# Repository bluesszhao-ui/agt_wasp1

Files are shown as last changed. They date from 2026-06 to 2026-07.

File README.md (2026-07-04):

# wasp1

wasp1 is a minimal single-core RV32I + Zicsr SoC project.

The hardware is implemented in synthesizable SystemVerilog and follows
Rocket Chip-like high-level module boundaries while using AHB-Lite as the SoC
interconnect.

## Baseline

```text
ISA: RV32I + Zicsr
Privilege: Machine mode only
MMU/TLB/PTW: none
RTL: SystemVerilog, .sv suffix
SoC bus: AHB-Lite
Core/cache internal interface: lightweight valid/ready request-response
Core plan: simple 3-stage pipeline
I-cache: direct-mapped, 16-byte line
D-cache: direct-mapped, 16-byte line, write-through
Debug target: RISC-V External Debug Spec 0.13.x / OpenOCD / GDB
Final debug probe: FT2232H-based external hardware debugger
Program storage: executable OTP
Compiler work: LLVM-based bare-metal wasp1 toolchain and BSP
```

## Top-Level Modules

```text
common
wasp1
tile
core
frontend
icache
dcache
bus
otp
sram
dma
debug
timer
intc
wdg
uart
i2c
gpio
llvm_s1
ftdi_debugger
```

Each hardware module owns its own `rtl/`, `tb/`, `filelists/`, `docs/`,
`build/`, `logs/`, `wave/`, and `Makefile` directories.
`ftdi_debugger` is not chip RTL; it owns the external FTDI debugger hardware,
OpenOCD, and board bring-up collateral.

## Current Status

Implemented and verified:

```text
common
bus
sram
otp
timer
gpio
uart
dma
intc
core
frontend
icache
dcache
tile
debug leaf blocks
wdg
i2c
wasp1 top integration smoke
```

Current residual scope:

```text
debug integration:
  true DPC/DCSR capture, single-step, breakpoints, abstract memory access

external debugger:
  FT2232H hardware debugger schematic/PCB, OpenOCD config, FPGA/board bring-up

software/toolchain:
  llvm_s1 BSP, linker script, startup code, runtime, examples, tests

full-system validation:
  interrupt-driven firmware, longer generated-image boot/DMA/programming
  regressions
```

See [ROADMAP.md](ROADMAP.md) for the live progress list and next steps.

## Quick Commands

Run all currently wired lint targets:

```sh
make lint
```

Run all currently wired module simulations:

```sh
make sim
```

Run common lint only:

```sh
make -C common lint
```

Generated build, log, and waveform outputs are ignored by git.

## Documentation

Start here:

```text
docs/index.md
```

Important project documents:

```text
ROADMAP.md
docs/wasp1_architecture.md
docs/wasp1_module_hierarchy.md
docs/wasp1_memory_map.md
docs/wasp1_design_plan.md
docs/wasp1_verification_plan.md
docs/wasp1_debug_strategy.md
docs/wasp1_otp_boot_strategy.md
docs/wasp1_llvm_s1_plan.md
docs/wasp1_implementation_targets.md
docs/wasp1_documentation_policy.md
docs/wasp1_omnigraffle_diagram_policy.md
```

## Contributor and Agent Rules

Human contributor guidance:

```text
CONTRIBUTING.md
```

Agent workflow rules:

```text
AGENTS.md
```

## License

wasp1 is licensed under the Apache License, Version 2.0. See [LICENSE](LICENSE).

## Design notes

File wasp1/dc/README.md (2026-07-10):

# wasp1 Synthesis Collateral

## 1. Scope

This directory contains first-pass synthesis collateral for the integrated
`wasp1` top.

It is deliberately split by implementation target:

| Target | Script | Constraint file | Memory treatment |
| --- | --- | --- | --- |
| ASIC / IC | `wasp1_ic_dc.tcl` | `wasp1_ic_constraints.sdc` | SRAM/OTP blackbox stubs |
| Xilinx Virtex-7 | `wasp1_v7_vivado.tcl` | `wasp1_v7_constraints.xdc` | Behavioral macro wrappers infer FPGA RAM |

## 2. ASIC Flow

The ASIC flow reads:

```text
wasp1/filelists/wasp1_synth_ic.f
```

That filelist replaces:

```text
sram/rtl/wasp1_sram_macro.sv -> sram/dc/wasp1_sram_macro_blackbox.sv
otp/rtl/wasp1_otp_macro.sv   -> otp/dc/wasp1_otp_macro_blackbox.sv
```

Required environment before running Design Compiler:

```sh
export WASP1_TARGET_LIBRARY="/path/to/stdcell_tt.db"
export WASP1_LINK_LIBRARY="/path/to/macro_timing.db"
dc_shell -f wasp1/dc/wasp1_ic_dc.tcl
```

The first ASIC output reports are written under:

```text
wasp1/logs/dc_ic/
```

Mapped netlist/checkpoints are written under:

```text
wasp1/build/dc_ic/
```

## 3. Virtex-7 Flow

The FPGA flow reads the normal SoC filelist:

```text
wasp1/filelists/wasp1.f
```

The default part is:

```text
xc7vx485tffg1761-2
```

Override it when a concrete board is selected:

```sh
export WASP1_VIVADO_PART=xc7vx690tffg1761-2
vivado -mode batch -source wasp1/dc/wasp1_v7_vivado.tcl
```

The XDC intentionally has no pin locations yet. Add board-specific PACKAGE_PIN
and IOSTANDARD constraints before implementation/bitstream work.

## 4. Static Check

Run:

```sh
make -C wasp1 synth-collateral-check
```

This check verifies the target split, memory macro blackbox usage, and clock
constraint presence without requiring commercial EDA tools.

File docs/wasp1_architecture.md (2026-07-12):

# wasp1 Architecture

## 1. Project Goal

wasp1 is a minimal single-core RV32I SoC inspired by the Rocket Chip module
partitioning style, implemented in synthesizable SystemVerilog.

The design keeps Rocket Chip-like high-level boundaries such as tile, core,
frontend, cache, bus, debug, interrupt, and periphery, while replacing the
Rocket Chip TileLink fabric with an AHB-Lite based SoC interconnect.

## 2. Confirmed Baseline

| Item | Decision |
| --- | --- |
| ISA | RV32I + Zicsr |
| Privilege mode | Machine mode only |
| MMU/TLB/PTW | Not implemented |
| RTL language | SystemVerilog |
| RTL suffix | `.sv` |
| SoC bus | AHB-Lite |
| Internal core/cache interface | Lightweight valid/ready request-response |
| Core microarchitecture | Simple 3-stage pipeline |
| I-cache | Direct-mapped, 16-byte line |
| D-cache | Direct-mapped, 16-byte line, write-through |
| DMA coherence | No hardware cache coherence |
| Debug | RISC-V External Debug Spec 0.13.x compatible target |
| Program storage | Executable OTP |
| OTP programming | CPU-controlled through OTP registers |
| UART programming | Software protocol through boot/program code |
| OTP programming safety | OTP programming routines execute from I-SRAM |
| Implementation targets | IC and Xilinx Virtex-7 FPGA |

## 3. Top-Level Structure

```text
                         +----------------+
                         |     debug      |
                         | JTAG/DTM/DM    |
                         +--------+-------+
                                  |
                                  v
+----------------------------------------------------------------+
|                            wasp1                               |
|                                                                |
|  +--------------------+                                        |
|  |        tile        |                                        |
|  |                    |                                        |
|  | frontend -> icache |----+                                   |
|  | core LSU -> dcache |----+--> core AHB master                |
|  +--------------------+                                        |
|                                                                |
|  +--------------------+                                        |
|  |        dma         |--------> dma AHB master                |
|  +--------------------+                                        |
|                                                                |
|       core master  dma master                                  |
|            |          |                                        |
|            v          v                                        |
|       +----------------------+                                 |
|       |   bus / AHB fabric   |                                 |
|       +----------+-----------+                                 |
|                  |                                             |
|  +---------------+------------------------------------------+  |
|  | OTP I-SRAM D-SRAM DMA WDG timer intc UART I2C GPIO       |  |
|  +----------------------------------------------------------+  |
+----------------------------------------------------------------+
```

## 4. Reset and Execution Model

After reset, the core starts at `OTP_BASE`. OTP is the primary non-volatile
program storage and is executable.

The default software layout is:

| Section | Load location | Run location |
| --- | --- | --- |
| `.text` | OTP | OTP |
| `.rodata` | OTP | OTP |
| `.fasttext` | OTP | I-SRAM |
| `.data` | OTP | D-SRAM |
| `.bss` | None | D-SRAM |
| heap | None | D-SRAM |
| stack | None | D-SRAM |

Startup code may copy `.fasttext` into I-SRAM and `.data` into D-SRAM before
calling `main`.

OTP programming code must run from I-SRAM to avoid modifying the same OTP array
that is currently feeding instruction fetch.

## 5. Cache and DMA Policy

wasp1 does not implement hardware cache coherence.

The first D-cache implementation is write-through. DMA buffers should be placed
in an uncached region or explicitly managed by software. OTP and peripheral
regions are always uncached.

## 6. Debug Model

wasp1 targets OpenOCD/GDB compatibility through a RISC-V External Debug
Spec 0.13.x style debug subsystem.

The debug implementation is staged:

| Stage | Scope |
| --- | --- |
| 1 | JTAG DTM, DMI, dmcontrol, dmstatus, halt/resume, basic GPR access |
| 2 | abstract command, DPC readback, DCSR.step single-step |
| 3 | halted-core Access Memory, native GDB `stepi`, two execute-address hardware breakpoints, and load/store watchpoints |
| 4 | four-word Program Buffer, Access Register `postexec`, and halted-core instruction execution |
| 5 | FT2232H external debugger collateral and later FPGA/board bring-up; optional System Bus Access |

## 7. Design Flow

The project starts with architecture and module documentation. RTL is added
module by module only after the module list and design order are confirmed.

Recommended first implementation target:

```text
common + bus
```

The AHB-Lite fabric is a foundation for all memory-mapped blocks.

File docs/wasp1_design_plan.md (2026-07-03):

# wasp1 Design Plan

## 1. Design Method

Design proceeds one module at a time. Each module receives:

1. Design spec
2. Interface definition
3. RTL implementation
4. Testbench
5. Filelist
6. Makefile target
7. Verification case table
8. Simulation logs and waveform output

No top-level SoC RTL is created until the lower-level modules needed for
integration are implemented and verified.

## 2. Recommended Order

| Step | Module | Reason |
| ---: | --- | --- |
| 1 | common | Shared packages, interfaces, synchronizers, FIFOs |
| 2 | bus | Foundation for all memory-mapped blocks |
| 3 | sram | Provides real AHB read/write targets |
| 4 | otp | Defines reset/program storage model |
| 5 | timer | Simple register block and interrupt source |
| 6 | gpio | Simple peripheral with input/output/interrupt |
| 7 | uart | Required for software-visible bring-up and OTP programming flow |
| 8 | dma | Adds the second AHB master and arbitration pressure |
| 9 | intc | Aggregates external interrupts |
| 10 | core | Minimal RV32I + Zicsr execution path |
| 11 | frontend | PC and fetch control |
| 12 | icache | Instruction cache and refill path |
| 13 | dcache | Data cache and write-through path |
| 14 | tile | Core/frontend/cache integration |
| 15 | debug | RISC-V debug flow for OpenOCD/GDB |
| 16 | wasp1 | Full SoC integration |
| 17 | llvm_s1 | BSP, linker, startup, boot/program software |
| 18 | ftdi_debugger | External FT2232H hardware debugger for OpenOCD/GDB |
| 19 | full system | End-to-end SoC simulation and board-level bring-up |

## 3. First RTL Milestone

The first RTL milestone is:

```text
common + bus
```

This includes AHB-Lite interfaces, address decode, 2-master arbitration, slave
muxing, and default error response.

## 4. Documentation Rule

Each module gets a design spec under `module/docs/`. Block diagrams must not use
Mermaid. Preferred diagram formats are:

```text
ASCII block diagram
editable OmniGraffle .graffle source for detailed engineering figures
optional PNG/PDF preview export for Markdown viewing
```

New or substantially reworked OmniGraffle diagrams must follow
`docs/wasp1_omnigraffle_diagram_policy.md`.

Each verification plan must include a time-sequenced case table describing the
actions and expected results during each test interval.

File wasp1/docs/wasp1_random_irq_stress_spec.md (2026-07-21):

# wasp1 Deterministic-Random IRQ Stress Specification

## 1. Purpose

This regression stresses interrupt entry/return and concurrent SoC activity
with a repeatable pseudo-random schedule. It complements the directed timer,
DMA, GPIO, UART, and mixed-interrupt firmware tests; it does not replace them.

## 2. Stimulus Contract

The testbench shall hold a nonzero 32-bit seed on GPIO while reset is active.
The OTP firmware shall sample the synchronized GPIO value, publish a seed
capture mailbox, start xorshift32 with that value, and execute 12 rounds. GPIO
shall not be repurposed as interrupt stimulus until seed capture is observed.
The low two bits of each updated state select one operation:

| Selector | Operation | Expected interrupt events |
| ---: | --- | ---: |
| 0 | Arm the machine timer | 1 timer interrupt |
| 1 | Copy four D-SRAM words with DMA IRQ enabled | 1 DMA external interrupt |
| 2 | Request a testbench-driven GPIO[0] level-high pulse | 1 GPIO external interrupt |
| 3 | Arm timer and DMA together | 1 timer plus 1 DMA interrupt, in either order |

Each round shall complete before the next PRNG update. UART shall accept one
progress byte per round plus an initial marker so the run also exercises
uncached MMIO while interrupt traffic is active.

## 3. Firmware Result Contract

Firmware shall publish a D-SRAM mailbox at offset `0x3b00` containing:

```text
completion magic and done word
captured input seed
final PRNG state and packed selector trace
completed round and interrupt-event counts
timer, DMA, and GPIO interrupt counts
order-independent event checksum
DMA destination-data checksum
GPIO request and acknowledgement epochs
last mcause and last external claim ID
failure code and UART progress-byte count
```

The firmware shall stop with a nonzero failure code when an interrupt times
out, an unexpected trap/claim occurs, DMA reports an error, or copied data does
not match.

## 4. Independent Testbench Checks

The top-level testbench shall first verify the captured seed, then independently
run the same xorshift32 recurrence
to derive the final state, selector trace, source counts, total event count,
event checksum, DMA checksum, and expected number of GPIO handshakes. It shall
drive GPIO[0] high only while the request epoch exceeds the acknowledgement
epoch and shall return the pin low after acknowledgement.

The case passes only when all mailbox values match, every final interrupt line
is deasserted, DMA done/error state is clear, timer IRQ is low, GPIO pending is
clear, and the observed UART FIFO pushes cover all 13 progress bytes.

## 5. Timing and Reproducibility

The verification clock is 100 MHz with `1ns/1ps` simulation resolution. The
baseline seed is `0x1a2b3c4d`. The multi-seed campaign runs the same OTP image
with seeds `0x1a2b3c4d`, `0x12345678`, `0xdeadbeef`, and `0x0f1e2d3c`, for 48
total rounds. Seed zero is rejected because it is the xorshift32 lock state.

The nightly campaign shall derive 32 simulation seeds from generator root
`0xc001d00d`. Consecutive simulation seeds shall be separated by 13 xorshift32
states so their 12 firmware-round windows do not overlap. The campaign shall
therefore cover 384 distinct scheduled PRNG states across 32 independent SoC
reset/boot runs. It passes only when every per-seed scoreboard passes and each
of selectors 0, 1, 2, and 3 appears at least once in the aggregate schedule.
The runner shall emit deterministic JSON and Markdown summaries plus one raw
simulation log per seed.

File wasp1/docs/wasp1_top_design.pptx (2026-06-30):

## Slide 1

wasp1 / RV32I+Zicsr / AHB-Lite 2M x 10S

wasp1 SoC
Top Design PPT

单核 SoC 集成顶层：tile、cache、core AHB bridge、2-master fabric、OTP/SRAM/peripherals、IRQ pack、debug boundary 和 smoke verification。

SEQ
tile
RV32I+Zicsr
I/D cache

SEQ
AHB fabric
core + DMA masters

IF
UART/I2C/GPIO
debug/trap/reset pins

SEQ
OTP/SRAM/peripherals
10 slave windows

editable native PowerPoint shapes

1

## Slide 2

wasp1 / SoC Integration Top

顶层设计目标与边界

顶层负责结构集成和边界暴露，不重新实现子模块内部功能

- boot_pc 固定为 OTP_BASE，使 OTP 成为 reset 后可执行程序存储
- 把 tile I-cache/D-cache downstream 合并为 core-side AHB master
- 集成 DMA 第二 master 和 10 个 decoded external slave windows
- 打包 WDG/UART/I2C/GPIO/DMA 到 INTC，timer 直连 MTIP
- 临时暴露 core debug discrete ports；完整 JTAG DTM/DM 是后续集成项

SEQ
tile owns CPU/cache state

COMB
top owns wiring
IRQ pack
bridge select

SEQ
bridge owns
transaction state

IF
external pins
IO/debug/observe

2

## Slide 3

wasp1 / SoC Integration Top

2M x 10S AHB-Lite 拓扑

M0 来自 core-side bridge，M1 来自 DMA；fabric 负责仲裁、decode、mux 和 default response

IF
M0 core bridge
I/D cache traffic

SEQ
10 slave windows
OTP ISRAM DSRAM DMA
WDG TIMER INTC
UART I2C GPIO

SEQ
ahb_fabric_2m
arbiter + default
registered response

grant observation: bus_grant_idx_o

COMB
decoder/mux
slave select
response mux

SEQ
M1 DMA master
copy engine traffic

3

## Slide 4

wasp1 / SoC Integration Top

外部 slave windows

wasp1 顶层使用 common package 的 base address 和 slave index，保持全 SoC 一致

Group

Windows

Role

SEQ
boot path
boot_pc=OTP_BASE
tile fetch -> bridge
-> fabric -> OTP

Program/storage

OTP, I-SRAM, D-SRAM

boot code and scratch memories

DMA

DMA control window

software controls second AHB master

System

WDG, TIMER, INTC

reset request, MTIP, MEIP aggregation

COMB
data path
loads/stores/DMA
decode to SRAM or peripherals

Serial/IO

UART, I2C, GPIO

external communication and pins

4

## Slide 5

wasp1 / SoC Integration Top

Core I/D to AHB bridge

bridge 把 tile 的 imem_if/dmem_if 合并为一个 core-side AHB master，D-cache idle 仲裁优先

- BR_IDLE 中 dmem valid 优先于 imem valid
- BR_ADDR 驱动 AHB address phase，等待 hready
- BR_RESP 采样 hrdata/hresp，进入 response hold
- BR_RSP_HOLD 保持 cache response 直到 selected port ready
- 当前设计只允许 one outstanding single-beat transfer

BR_IDLE

BR_ADDR

BR_RSP_HOLD

BR_RESP

D-cache wins when both request

5

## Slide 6

wasp1 / SoC Integration Top

Reset 与 boot fetch flow

reset 后 tile boot PC 指向 OTP_BASE；第一条取指路径验证 SoC memory path 是否贯通

IF
hclk_i/hresetn_i
SoC reset domain

SEQ
tile/frontend
boot_pc=OTP_BASE

SEQ
core AHB bridge
imem request

SEQ
AHB fabric
M0 grant/decode

SEQ
executable OTP
AHB_SLAVE_OTP

当前顶层 smoke test 观察 core-side bridge/fabric path 是否出现 valid transfer；完整软件 boot、OTP 编程和 LLVM 输出执行仍是后续系统验证。

6

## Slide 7

wasp1 / SoC Integration Top

Interrupt integration

timer 直接作为 MTIP；外设 IRQ 通过 INTC 聚合为 MEIP，source 0 保留

INTC source

Signal

Origin

COMB
irq_src pack
{dma,gpio,i2c,uart,wdg,0}

SEQ
ahb_intc
mask/pending/claim
meip_o

1

wdg_irq

Watchdog timeout

2

uart_irq

UART RX/TX/events

3

i2c_irq

I2C transaction done

4

gpio_irq

GPIO edge/level

SEQ
timer_irq
direct MTIP

SEQ
tile/core CSR
external_irq_i
timer_irq_i

5

dma_irq

DMA done/error

7

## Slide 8

wasp1 / SoC Integration Top

IO 与 debug boundary

顶层暴露真实 IO pins，同时保留临时 discrete core debug channel 便于后续 DM/JTAG 接入

- UART RX/TX、I2C open-drain SCL/SDA value/OE、GPIO in/out/OE
- wdg_reset_req_o 暴露给后续 SoC reset tree
- trap_valid/cause 和 bus_grant_idx 用于 bring-up observation
- 内部实例化 debug_if，映射到 discrete top ports
- 完整 DMI/DTM/OpenOCD/GDB 兼容路径仍是 debug/wasp1 后续集成项

IF
external pins
UART/I2C/GPIO
WDG reset/trap/bus

IF
temporary debug ports
halt/resume/step
GPR req/rsp

SEQ
core_debug interface
inside tile/core

8

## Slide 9

wasp1 / SoC Integration Top

Target support 与模块责任边界

顶层不引入 target-specific 行为；target 宏由 child memory/wrapper/attribute 层消化

- WASP1_TARGET_SIM_GENERIC：通用仿真路径
- WASP1_TARGET_IC：IC synthesis macro path
- WASP1_TARGET_FPGA_XILINX_VIRTEX7：Xilinx Virtex-7 macro path
- 顶层保持 programmer-visible behavior、AHB、IRQ、debug boundary 一致
- memory wrappers 和目标属性由子模块负责

SIM_GENERIC lint PASS

IC lint PASS

Virtex-7 lint PASS

COMB
same software-visible
SoC contract

9

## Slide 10

wasp1 / SoC Integration Top

顶层验证方法：为什么这样测

顶层 smoke test 不重复 leaf coverage，而是证明集成 elaboration、reset 和第一条 fetch path

风险

验证方法

根本逻辑

IF
tb_wasp1
reset/observe
no firmware yet

full hierarchy integration

generic/IC/Virtex-7 lint

证明 54 integrated modules 可展开且 target 宏一致

reset IO safety

4 cycles reset + output checks

顶层 IO 不能在 reset 后产生危险驱动

first fetch path

wait core AHB valid transfer

OTP boot path 必须穿过 tile/bridge/fabric

debug status wiring

wait running or halted

debug_if discrete ports 已被驱动而非悬空

COMB
integration smoke
pass counter
status snapshot

idle peripheral stability

extra cycles check WDG/I2C benign

未编程外设不能产生 reset 或 open-drain drive

10

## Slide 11

wasp1 / SoC Integration Top

验证结果快照

当前报告是 integration smoke test；完整系统软件验证仍在后续

Check

Result

Evidence

trap_valid=0

Generic lint

PASS

make -C wasp1 lint

trap_cause=0x02

IC-target lint

PASS

make -C wasp1 lint-ic

Virtex-7 lint

PASS

make -C wasp1 lint-fpga-v7

bus_grant_idx=0

tb_wasp1 simulation

PASS

pass_count=5

WDG/I2C idle benign

Observed debug

driven

dbg_running=1 dbg_halted=0

Simulation window: reset to 276ns. The test confirms benign reset defaults, first core-side AHB activity, and driven debug status; it does not claim full boot/software coverage.

11

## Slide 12

wasp1 / SoC Integration Top

后续集成关注点

顶层结构已经可 elaboration/smoke，但完整 wasp1 产品化还需要系统软件和 debug/JTAG 闭环

SEQ
current top
structural SoC
OTP fetch smoke
IO/debug boundary

COMB
integration work
Debug Module/JTAG
OTP programming flow
DMA real memory copy

IF
system validation
OpenOCD/GDB
firmware boot
interrupt-driven tests

- 把 debug leaf/DM/JTAG DTM 接入 wasp1 顶层，实现 OpenOCD/GDB end-to-end
- 建立 OTP 用户程序装载、LLVM/BSP 输出、真实 boot regression
- 补 DMA through-memory copy、interrupt-driven firmware、timer/INTC 外设联动
- 后续增加结构 coverage、长时间 SoC random/soak 和 FPGA bring-up checklist

12

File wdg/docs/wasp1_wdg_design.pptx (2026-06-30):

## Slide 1

wasp1 / peripheral leaf / safety timer

Watchdog
Design PPT

AHB-Lite watchdog timer：timeout counter、kick key、clear priority、IRQ/reset request 输出，以及自检查验证。

IF
AHB-Lite slave
register access

SEQ
control/status
timeout/count

COMB
count+1 compare
timeout hit

IF
IRQ/reset request
SoC integration

editable native PowerPoint shapes

1

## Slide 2

wasp1 / AHB-Lite Watchdog Timer

设计目标与行为边界

软件定期写 KICK key；超时后 sticky status 驱动 IRQ 和 reset request

- AHB-Lite always-ready word register slave
- TIMEOUT=N 表示清零后 N 个 enabled ticks 到期
- TIMEOUT=0 作为 immediate expiry
- 正确 KICK 清 count/expired/reset_req；错误 key 只置 keyerr
- 模块自身不决定 SoC reset tree，只输出 wdg_reset_req_o

SEQ
CTRL regs
enable irq_en reset_en

SEQ
COUNT/TIMEOUT
up counter

SEQ
sticky status
expired reset_req keyerr

IF
wdg_irq_o
wdg_reset_req_o

2

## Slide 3

wasp1 / AHB-Lite Watchdog Timer

模块总体结构

AHB 请求锁存、寄存器状态、timeout compare 和输出 decode 明确分层

IF
AHB bus
hsel/haddr/htrans
hwrite/hsize/hwdata

COMB
address decode
range/alignment
word size

SEQ
request regs
clk=hclk_i
rst=hresetn_i

SEQ
control/status regs
timeout/count
expired/keyerr

COMB
read/status/output
HRDATA/HRESP
IRQ/reset_req

COMB
count_plus_one
timeout_hit
TIMEOUT=0

3

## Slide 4

wasp1 / AHB-Lite Watchdog Timer

软件寄存器模型

5 个 word registers 覆盖 enable、状态、timeout、count 和 feed 动作

Offset

Name

Access

Meaning

0x00

CTRL

RW

enable, irq_en, reset_en, clear

IF
software flow
program TIMEOUT
set CTRL enable
periodic KICK
poll STATUS

0x04

STATUS

RO

expired, reset_req, keyerr, running

0x08

TIMEOUT

RW

32-bit terminal count

0x0C

COUNT

RO

current watchdog count

COMB
KICK policy
correct key feeds
bad key latches keyerr

0x10

KICK

WO

write WDG_KICK_VALUE to feed

4

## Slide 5

wasp1 / AHB-Lite Watchdog Timer

更新优先级

clear/kick 必须能压过同周期 tick 或 expiry，这是 watchdog 语义最关键的地方

- reset 初始化全部寄存器和 AHB response
- 默认 watchdog tick 先计算 count_plus_one / timeout_hit
- 软件 CTRL.clear 或 valid KICK 在同一 always_ff 后部覆盖 tick
- bad KICK 不 feed，只 latch keyerr
- 未知寄存器和非法地址通过 HRESP ERROR 暴露

SEQ
reset
state init

COMB
tick/compare
count+1>=timeout

SEQ
software write
clear/kick/control

SEQ
final state
count/status/output

5

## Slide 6

wasp1 / AHB-Lite Watchdog Timer

Timeout / Kick 工作原理

count_plus_one 与 timeout_q 比较，避免 TIMEOUT=N 的 off-by-one 歧义

RUNNING
count<N

TIMEOUT_HIT

EXPIRED
sticky

KICK/CLEAR
count=0

TIMEOUT=0 直接命中；TIMEOUT=N 时从 count=0 开始，第 N 个 enabled tick 进入 expired。expired 后计数停止，直到 clear 或正确 KICK。

6

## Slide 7

wasp1 / AHB-Lite Watchdog Timer

STATUS、IRQ 与 reset request

expired 是 sticky completion；reset_req 只在 reset_en 到期时 sticky latch

Signal/bit

Definition

Why

STATUS.running

enable && !expired

软件可快速判断 watchdog 是否仍在计数

COMB
output decode
status image
IRQ/reset request

STATUS.expired

timeout hit latched

polling 和 IRQ 共享同一 completion source

STATUS.reset_req

reset_en sampled at expiry

reset 请求保持到 kick/clear

wdg_irq_o

expired && irq_en

IRQ mask 不改变 expired 状态

IF
SoC integration
interrupt input
reset controller

wdg_reset_req_o

reset_req_q

交给 SoC reset tree 处理

7

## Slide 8

wasp1 / AHB-Lite Watchdog Timer

AHB 响应与错误处理

always-ready 简化外设接入；非法访问仍在一拍后返回 HRESP ERROR

- hready_o 固定 1，不产生 wait state
- addr phase 捕获 req_valid/write/err/offset
- 只支持 aligned word access
- misaligned、non-word、out-of-range 返回 ERROR
- unknown register offset 在 data phase 返回 ERROR

IF
address phase
current bus

COMB
decode errors
range align size

SEQ
request regs
one-cycle delay

COMB
read/response
HRDATA/HRESP

8

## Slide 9

wasp1 / AHB-Lite Watchdog Timer

验证方法：为什么这样测

watchdog 的核心风险是计数边界、feed 优先级、sticky 输出和 AHB 错误契约

风险

验证方法

根本逻辑

IF
self-checking TB
AHB driver

reset/register contract

reset reads + register readback

软件只通过寄存器面配置和诊断

timeout boundary

timeout=4, reset-only, random timeout

证明 TIMEOUT=N 和 TIMEOUT=0 语义

feed priority

correct KICK before expiry

防止同周期 tick 错误抢先到期

bad key handling

wrong KICK value then STATUS read

错误 feed 不应隐藏软件 bug

COMB
scoreboard
register/status
cycle timing

AHB error path

misaligned/halfword/unknown/range

非法访问必须是总线错误而不是静默忽略

9

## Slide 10

wasp1 / AHB-Lite Watchdog Timer

验证结果快照

当前报告是 functional self-check coverage；generic/IC/Virtex-7 lint 与仿真均通过

Metric

Value

Meaning

Generic lint PASS

pass_count

50

self-check milestones

reg_count

35

register access checks

IC lint PASS

timeout_count

2

directed timeout classes

Virtex-7 lint PASS

kick_count

2

valid kick and pre-expiry feed

tb_ahb_wdg PASS

error_count

random_count

5

4

AHB / register error paths

deterministic random timeouts

Timebase: 1ns/1ps, 10ns verification clock. Cases cover reset, timeout IRQ/reset, valid/bad kick, clear behavior, IRQ masking, AHB error paths, and random timeout values.

10

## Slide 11

wasp1 / AHB-Lite Watchdog Timer

后续集成关注点

模块级 watchdog 已验证；reset request 如何进入 SoC reset tree 是顶层验证项

SEQ
current module
verified register file
timeout/kick logic
IRQ/reset outputs

COMB
integration work
reset tree policy
interrupt wiring
firmware driver

IF
system validation
end-to-end timeout
recovery behavior
boot interaction

- SoC 顶层要决定 wdg_reset_req_o 是局部复位还是全芯片复位
- 需要 firmware-driven kick/timeout 回归验证 reset/boot 交互
- 后续可补结构覆盖和长时间 soak/random timeout tests

11

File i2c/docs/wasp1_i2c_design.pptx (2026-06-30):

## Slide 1

wasp1 / peripheral leaf / AHB-Lite slave

I2C Master
Design PPT

最小 single-master I2C 控制器：AHB 寄存器、byte FSM、prescale divider、open-drain SCL/SDA drive enables，以及自检查验证。

IF
AHB-Lite slave
register access

SEQ
software regs
DATA/STATUS/CTRL

SEQ
I2C byte FSM
START/BIT/ACK/STOP

COMB
open-drain decode
SCL/SDA OE only

editable native PowerPoint shapes

1

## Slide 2

wasp1 / AHB-Lite I2C Master

设计目标与非目标

把 I2C 做成可验证、可综合、对软件清晰的最小主控外设

- single-master，一次 CMD 写启动一个 8-bit byte transaction
- AHB-Lite always-ready slave，地址相位后一拍返回 data/response
- 软件配置 START/READ/STOP/ACK_VALUE，DATA 承载 TX/RX byte
- SCL/SDA 只提供低电平 drive enable，高电平由外部 pull-up
- 不实现 multi-master arbitration、clock stretching 和 pad 签核

IF
software-visible
AHB registers

SEQ
byte FSM
one byte per CMD

COMB
open-drain policy
OE means drive low

IF
external pull-ups
board/pad domain

2

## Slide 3

wasp1 / AHB-Lite I2C Master

模块总体结构

AHB 寄存器面和 I2C bit/ACK/STOP 时序面分离，组合 open-drain decode 输出到 pad

software register plane

SEQ
software regs
enable irq prescale
tx/rx/status/cmd

IF
AHB bus
hsel/haddr/htrans
hwrite/hsize/hwdata

COMB
address decode
range/alignment
known offset

SEQ
request phase regs
clk=hclk_i
rst=hresetn_i

COMB
read/status/output
HRDATA/HRESP
IRQ
SCL/SDA OE

SEQ
I2C byte FSM
START BIT ACK STOP
divider tick

serial timing plane

3

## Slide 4

wasp1 / AHB-Lite I2C Master

软件寄存器与命令模型

寄存器面足够小：DATA/STATUS/CTRL/PRESCALE/CMD 覆盖一个 byte transaction

Offset

Name

Access

Meaning

COMB
CMD bits
START bit0
READ bit1
STOP bit2
ACK_VALUE bit3

0x00

DATA

RW/RO

write TX byte; read last RX byte

0x04

STATUS

RO

busy, done, ackerr, rx_valid, irq

0x08

CTRL

RW

enable, irq_en, write-one clear

0x0C

PRESCALE

RW

16-bit phase divider reload

IF
software flow
program DATA/PRESCALE
write CTRL enable
write CMD
poll STATUS/read DATA

0x10

CMD

WO

START, READ, STOP, ACK_VALUE

4

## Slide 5

wasp1 / AHB-Lite I2C Master

AHB-Lite 响应原理

always-ready 简化互连；地址相位 metadata 锁存到下一拍 response/data phase

- hready_o 固定为 1，模块不向 AHB 插入等待周期
- addr phase 检查 hsel、htrans[1]、range、alignment、word size
- req_valid_q/req_write_q/req_err_q/req_offset_q 保存一拍
- read_data_next 由已锁存 offset 和当前寄存器状态组合产生
- 未知 offset、非法 size、busy/disabled CMD 返回 HRESP ERROR

IF
AHB address phase
current bus pins

COMB
decode
range/align/size

SEQ
request regs
one-cycle delay

COMB
response mux
HRDATA/HRESP

5

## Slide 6

wasp1 / AHB-Lite I2C Master

I2C byte FSM

一个 CMD 只执行一个 byte；START/STOP 是否出现由 CMD 位控制

IDLE

START_A

BIT_LOW

ACK_LOW

STOP_LOW

START_B

BIT_HIGH

ACK_HIGH

STOP_HIGH

DONE

BIT_LOW/BIT_HIGH 循环 8 次，由 bit_idx_q 从 7 数到 0。TX 在 ACK_HIGH 采样 slave ACK；RX 在 BIT_HIGH 采样数据，并在 ACK_HIGH commit RX byte。

6

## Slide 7

wasp1 / AHB-Lite I2C Master

PRESCALE divider 与 tick

I2C 时序推进由 phase tick 驱动；PRESCALE=0 合法，便于快速仿真

- prescale_q 是 16-bit reload value
- FSM active 时 div_q 递减；div_q==0 产生 tick
- tick 后 div_q 重新装载 prescale_q
- FSM idle 时 div_q 跟随 prescale_q
- PRESCALE=0 表示每个 hclk_i cycle 推进一个 FSM phase

SEQ
prescale_q
software reload

SEQ
div_q counter
clk=hclk_i

COMB
tick = div_q==0
phase enable

SEQ
byte FSM
advance on tick

7

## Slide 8

wasp1 / AHB-Lite I2C Master

Open-drain SCL/SDA 策略

模块永远不驱动逻辑 1；输出值固定为 0，OE 决定是否把线拉低

- i2c_scl_o = 0，i2c_sda_o = 0
- *_oe_o = 1 表示 drive low；*_oe_o = 0 表示 release
- TX bit 为 0 时 SDA OE=1；TX bit 为 1 时 release
- RX data phase 释放 SDA，由外部 slave 驱动
- RX ACK: ACK_VALUE=0 拉低 ACK，ACK_VALUE=1 释放为 NACK

SEQ
FSM state
cmd direction
bit_idx/tx bit

COMB
line decode
SCL_OE/SDA_OE

drive low only

IF
external line
pull-up + pad
SCL/SDA observed

8

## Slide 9

wasp1 / AHB-Lite I2C Master

状态、IRQ 与错误处理

错误响应保护软件模型；done/ackerr/rx_valid 构成一次 transaction 的 completion contract

Item

Set condition

Clear condition

COMB
error detect
misaligned
non-word
unknown offset
CMD disabled/busy

done

FSM reaches DONE

CTRL.clear or new CMD

ackerr

TX ACK_HIGH samples SDA high

CTRL.clear or new CMD

rx_valid

RX ACK_HIGH commits byte

CTRL.clear or new CMD

irq

done && irq_en

done cleared or irq_en=0

IF
AHB response
HRESP ERROR
no restart/corrupt

9

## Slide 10

wasp1 / AHB-Lite I2C Master

验证方法：为什么这样测

I2C 外设的风险集中在寄存器契约、串行线行为、busy 保护和错误响应

风险

验证方法

根本逻辑

IF
self-checking TB
AHB driver
I2C slave model

register contract

reset + legal read/write sweep

软件只能通过寄存器面观察和控制 byte engine

AHB error response

misaligned/byte/unknown/out-of-range

总线错误必须在一拍响应中准确暴露

TX bit drive

0xA5, 0x3C, random TX + line checks

最终 done 不足以证明 open-drain bit-level 正确

RX sampling/ACK

feed 0x5A/0xC3; ACK and NACK cases

读方向同时验证 sample timing 和 master ACK policy

COMB
scoreboard
register image
line-level checks

busy protection

issue CMD while FSM active

第二条命令不能重启或破坏当前 transaction

10

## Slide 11

wasp1 / AHB-Lite I2C Master

验证结果快照

当前报告是 functional self-check coverage；目标宏 lint 和仿真均通过

Metric

Value

Meaning

Generic lint PASS

pass_count

reg_count

110

36

self-check milestones

register access checks

IC lint PASS

write_tx_count

6

TX byte transactions

read_rx_count

2

RX byte transactions

Virtex-7 lint PASS

error_count

5

AHB / command error cases

tb_ahb_i2c PASS

random_count

4

deterministic random TX bytes

line_check_count

Timebase: 1ns/1ps, 10ns verification clock. Directed cases cover reset, legal/illegal AHB access, TX ACK/NACK, RX ACK/NACK, busy reject, and four deterministic-random TX bytes.

50

open-drain bit-level checks

11

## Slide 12

wasp1 / AHB-Lite I2C Master

后续集成关注点

当前模块满足 wasp1 最小 I2C master contract，系统级仍要验证 pad 与外部设备时序

SEQ
current module
verified AHB slave
byte FSM
open-drain OE

COMB
integration work
pad wrapper
pull-up choice
board timing

IF
system validation
real I2C target
firmware driver
IRQ path

- multi-master arbitration 和 clock stretching 仍是明确非目标
- FPGA/IC pad open-drain 实现需要在顶层 wrapper 中确认
- 系统集成后增加 firmware-driven I2C peripheral 回归
- 后续可补结构覆盖和外设 timing margin signoff

12

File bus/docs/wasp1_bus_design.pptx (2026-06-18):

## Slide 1

wasp1 bus

模块讲解 PPT

2-master AHB-Lite fabric 与地址解码/返回 mux

core master
IF

dma master
IF

ahb_arbiter_2m
SEQ grant

ahb_decoder
COMB decode

slave ports
IF 0..N

ahb_default_slave
SEQ error

bus 把 core/dma 两个 master 接入统一的 AHB-Lite slave 空间，并提供默认错误响应。

两主：core 与 dma

地址解码覆盖 OTP/SRAM/外设/default

downstream HREADY low 时保持 grant

未映射地址进入 default error slave

ahb_slave_mux
COMB rsp mux

wasp1 / bus design explanation

01

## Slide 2

GOALS AND SCOPE

设计目标与边界：先把职责收紧，再谈扩展

SEQ clk/rst

COMB

IF

模块定位

bus 把 core/dma 两个 master 接入统一的 AHB-Lite slave 空间，并提供默认错误响应。

两主：core 与 dma

地址解码覆盖 OTP/SRAM/外设/default

downstream HREADY low 时保持 grant

外部可见契约

实现侧选择

明确 SEQ/COMB/IF 边界

接口、寄存器语义、错误响应、中断/握手行为必须稳定。
实现可替换，但软件和总线观察到的行为不应改变。

状态归属到叶子或寄存器

IC 与 Virtex-7 FPGA 行为一致

验证覆盖正常/边界/错误/停顿

wasp1 / bus design explanation

02

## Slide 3

EXTERNAL CONTRACT

接口契约：软件/总线/相邻模块能观察到什么

C1

两主：core 与 dma

C2

地址解码覆盖 OTP/SRAM/外设/default

C3

downstream HREADY low 时保持 grant

未映射地址进入 default error slave

C4

C5

master 请求进入 arbiter

C6

grant 后地址控制进入 decoder

契约优先级
spec > design spec > RTL

wasp1 / bus design explanation

03

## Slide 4

ARCHITECTURE MAP

总体架构图：SEQ、COMB、IF 明确分开

SEQ clk/rst

COMB

IF

core master
IF

dma master
IF

ahb_arbiter_2m
SEQ grant

图示原则

绿色：时序状态或寄存器/存储

橙色：组合判断、mux、编码

蓝色：模块边界或外部接口

每个 SEQ 块在设计文档中必须标明 clock/reset

ahb_decoder
COMB decode

slave ports
IF 0..N

ahb_default_slave
SEQ error

ahb_slave_mux
COMB rsp mux

wasp1 / bus design explanation

04

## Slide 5

FUNCTIONAL FLOW

功能原理：从输入事件到可观察结果

master 请求进入 arbiter

grant 后地址控制进入 decoder

slave response 通过 mux 返回获授权 master

非授权 master 根据状态返回 ready/hold

根本逻辑

master 请求进入 arbiter

grant 后地址控制进入 decoder

slave response 通过 mux 返回获授权 master

非授权 master 根据状态返回 ready/hold

wasp1 / bus design explanation

05

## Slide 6

STATE AND TIMING

状态/时序图：所有状态都必须可定位、可验证

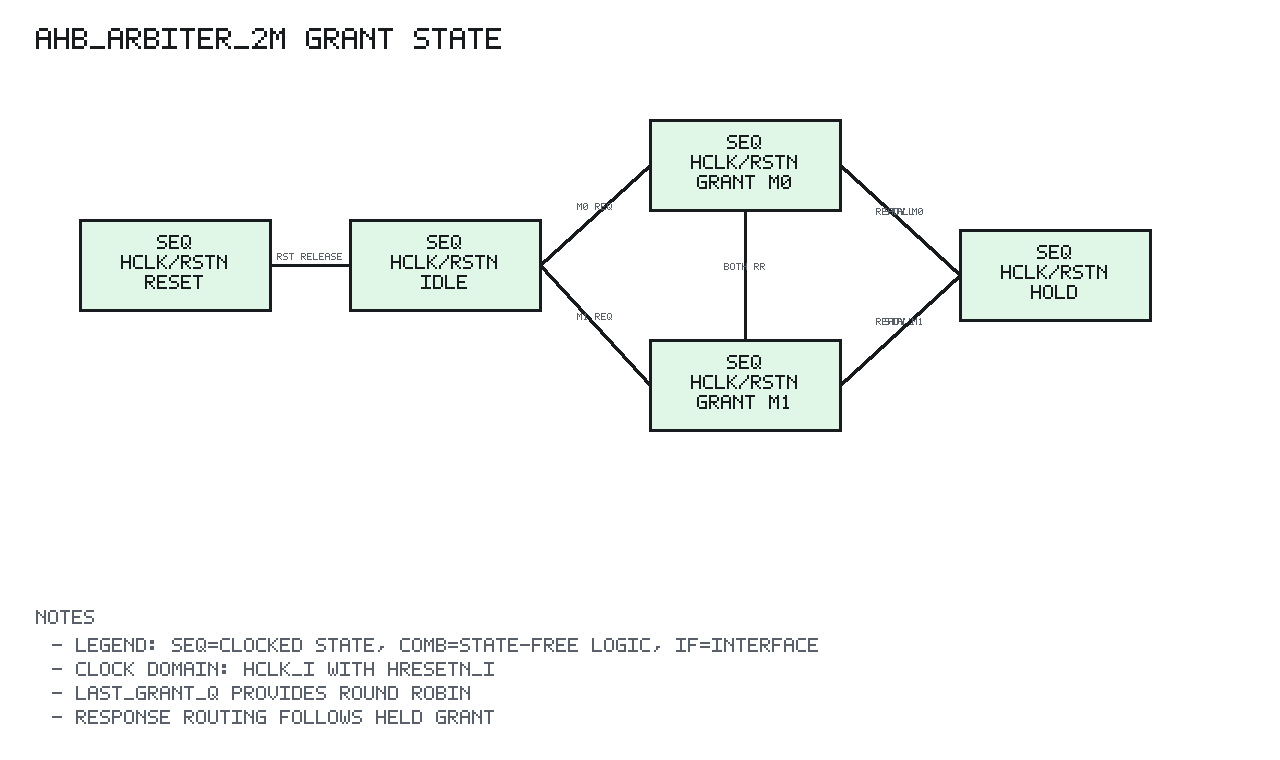
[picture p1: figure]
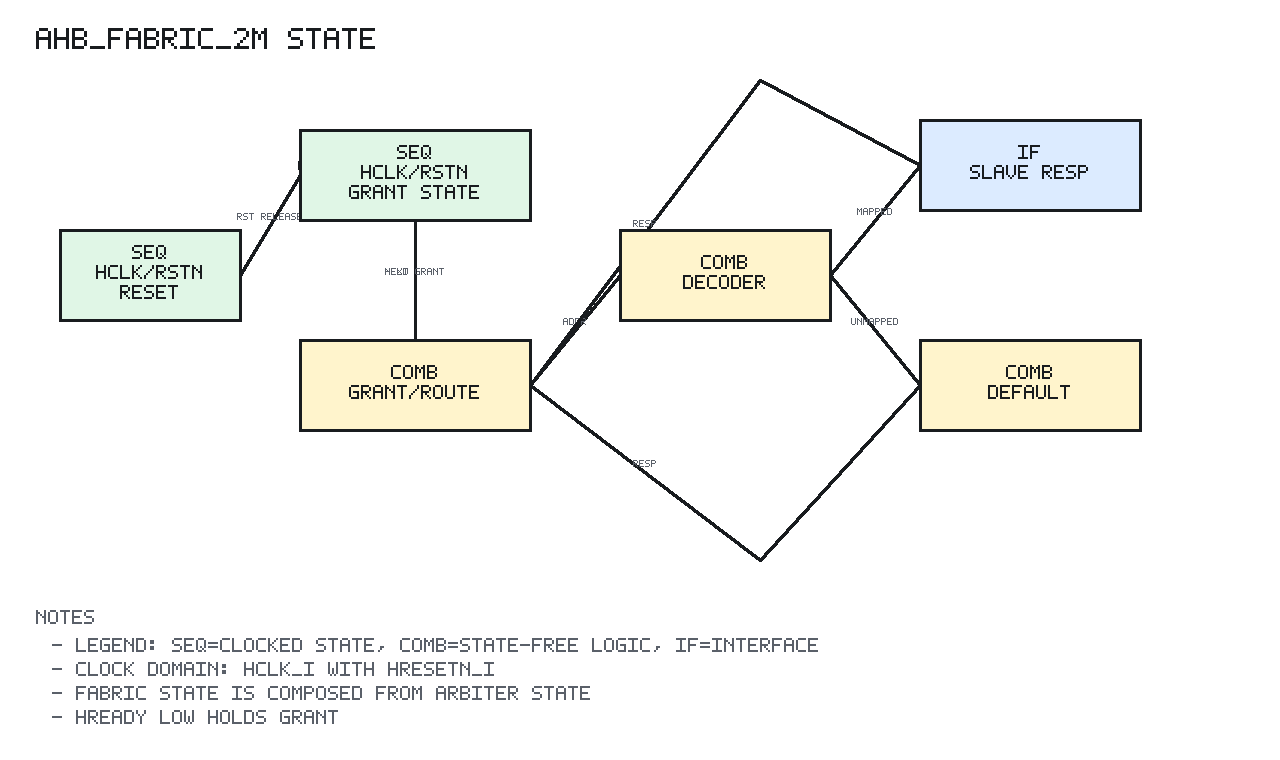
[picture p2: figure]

状态图来自模块 docs/images，并与 design spec 中状态描述对应。

复杂控制器默认按 L3：条件、动作、错误路径、优先级都要明确。

无显式 FSM 的模块用寄存器/计数器/流水线状态图表达。

wasp1 / bus design explanation

06

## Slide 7

VERIFICATION METHOD

验证方法：不是冒烟测试，而是证明交互正确

normal path

单 master 直通

boundary

双 master 同时请求轮转

error path

slave wait-state 保持

stall/idle

未映射地址 ERROR

self-checking TB + scoreboard/reference model + coverage summary

wasp1 / bus design explanation

07

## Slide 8

CASE TIMELINE

验证 case 时间表：动作、期望、观测结果必须逐段列出

时间段

0ns-20ns

动作

Apply reset

期望

Arbiter grant and decoder state reset

结果

报告未记录/待补

20ns-60ns

Decode OTP/I-SRAM/D-SRAM base/mid/end addresses

Matching memory select asserted

PASS for `ahb_decoder`

60ns-100ns

Decode peripheral base/mid/end addresses

Matching peripheral select asserted

PASS for `ahb_decoder`

100ns-140ns

DMA reads D-SRAM address

DMA receives grant and slave response

报告未记录/待补

140ns-200ns

Core and DMA request simultaneously

Round-robin alternates accepted grants

报告未记录/待补

说明：此页抽取/概括自现有 verification report。后续若 testbench 扩展，应同步更新报告和 PPT。

wasp1 / bus design explanation

08

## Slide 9

COVERAGE AND RISKS

覆盖与风险：覆盖面决定这个模块能不能被信任

单 master 直通

92%

已覆盖维度

单 master 直通

双 master 同时请求轮转

slave wait-state 保持

未映射地址 ERROR

双 master 同时请求轮转

88%

slave wait-state 保持

未映射地址 ERROR

86%

84%

两主

90%

地址解码覆盖 OTP/SRAM/外设/default

82%

风险原则：新增 RTL 行为必须先补 spec 和验证，再进集成。

wasp1 / bus design explanation

09

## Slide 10

CLOSE

结论：这个模块已经形成可讲解、可追踪、可继续扩展的设计资产

设计结论

两主：core 与 dma

地址解码覆盖 OTP/SRAM/外设/default

downstream HREADY low 时保持 grant

未映射地址进入 default error slave

验证结论

单 master 直通

双 master 同时请求轮转

slave wait-state 保持

未映射地址 ERROR

后续关注

与上层集成后的端到端 case

目标宏/FPGA 综合路径

新增功能保持 contract 稳定

文档、RTL、TB 同步更新

交付物：bus/docs/wasp1_bus_design.pptx

wasp1 / bus design explanation

10

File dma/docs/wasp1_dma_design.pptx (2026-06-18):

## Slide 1

wasp1 dma

模块讲解 PPT

AHB DMA register block 与 memory copy initiator

AHB slave regs
SEQ config

descriptor regs
SEQ state

DMA FSM
SEQ read/write

AHB master port
IF initiator

done/error irq
SEQ status

dma 通过寄存器配置源/目的/长度，作为第二 AHB master 执行搬运事务。

软件通过寄存器启动搬运

busy 时保护关键配置

读源地址再写目的地址

完成/错误状态可查询并中断

wasp1 / dma design explanation

01

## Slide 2

GOALS AND SCOPE

设计目标与边界：先把职责收紧，再谈扩展

SEQ clk/rst

COMB

IF

模块定位

dma 通过寄存器配置源/目的/长度，作为第二 AHB master 执行搬运事务。

软件通过寄存器启动搬运

busy 时保护关键配置

读源地址再写目的地址

外部可见契约

实现侧选择

明确 SEQ/COMB/IF 边界

接口、寄存器语义、错误响应、中断/握手行为必须稳定。
实现可替换，但软件和总线观察到的行为不应改变。

状态归属到叶子或寄存器

IC 与 Virtex-7 FPGA 行为一致

验证覆盖正常/边界/错误/停顿

wasp1 / dma design explanation

02

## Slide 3

EXTERNAL CONTRACT

接口契约：软件/总线/相邻模块能观察到什么

C1

软件通过寄存器启动搬运

C2

busy 时保护关键配置

C3

读源地址再写目的地址

完成/错误状态可查询并中断

C4

C5

program src/dst/len

C6

start 进入 read phase

契约优先级
spec > design spec > RTL

wasp1 / dma design explanation

03

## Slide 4

ARCHITECTURE MAP

总体架构图：SEQ、COMB、IF 明确分开

SEQ clk/rst

COMB

IF

AHB slave regs
SEQ config

AHB master port
IF initiator

descriptor regs
SEQ state

done/error irq
SEQ status

DMA FSM
SEQ read/write

图示原则

绿色：时序状态或寄存器/存储

橙色：组合判断、mux、编码

蓝色：模块边界或外部接口

每个 SEQ 块在设计文档中必须标明 clock/reset

wasp1 / dma design explanation

04

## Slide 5

FUNCTIONAL FLOW

功能原理：从输入事件到可观察结果

program src/dst/len

start 进入 read phase

读数据暂存后进入 write phase

长度耗尽进入 done 或 error

根本逻辑

program src/dst/len

start 进入 read phase

读数据暂存后进入 write phase

长度耗尽进入 done 或 error

wasp1 / dma design explanation

05

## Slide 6

STATE AND TIMING

状态/时序图：所有状态都必须可定位、可验证

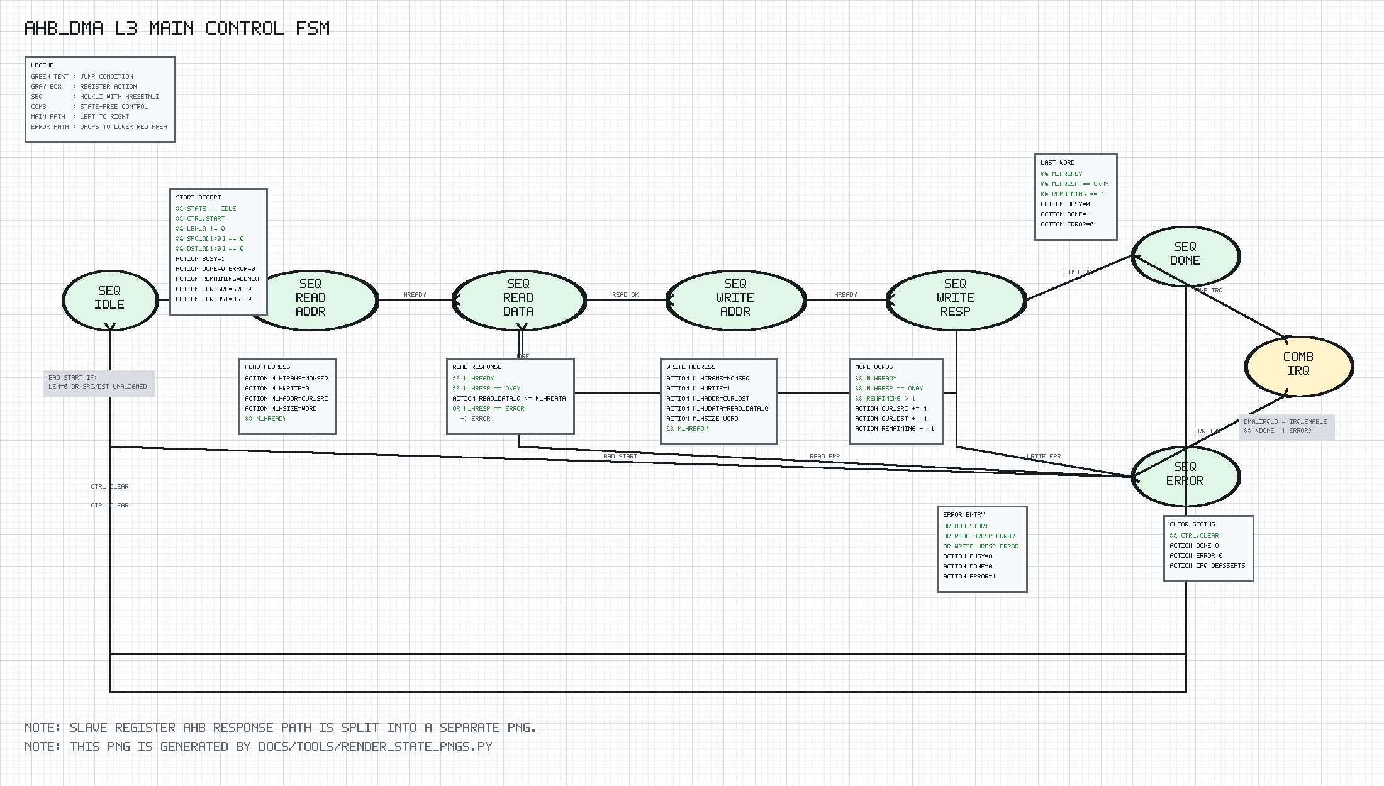
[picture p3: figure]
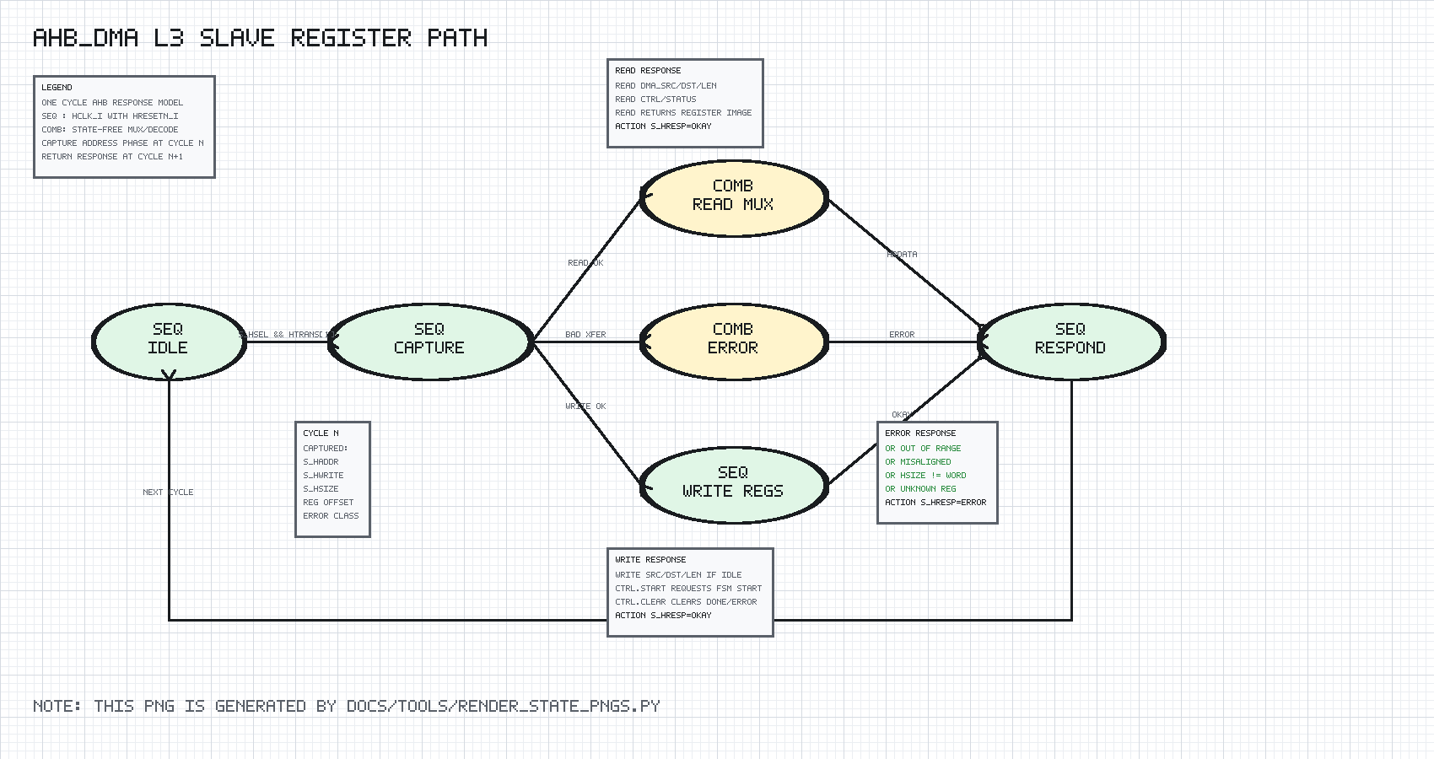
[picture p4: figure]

状态图来自模块 docs/images，并与 design spec 中状态描述对应。

复杂控制器默认按 L3：条件、动作、错误路径、优先级都要明确。

无显式 FSM 的模块用寄存器/计数器/流水线状态图表达。

wasp1 / dma design explanation

06

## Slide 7

VERIFICATION METHOD

验证方法：不是冒烟测试，而是证明交互正确

normal path

寄存器配置

boundary

单字/多字搬运

error path

wait-state backpressure

stall/idle

错误响应与 busy 保护

self-checking TB + scoreboard/reference model + coverage summary

wasp1 / dma design explanation

07

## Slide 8

CASE TIMELINE

验证 case 时间表：动作、期望、观测结果必须逐段列出

时间段

0ns-40ns

动作

reset/init

期望

所有寄存器进入默认状态

结果

PASS

40ns-120ns

normal access

基本请求响应符合 spec

PASS

120ns-220ns

boundary/error

边界和错误路径被检查

PASS

220ns-320ns

stall/backpressure

ready/valid 或 wait-state 行为稳定

PASS

说明：此页抽取/概括自现有 verification report。后续若 testbench 扩展，应同步更新报告和 PPT。

wasp1 / dma design explanation

08

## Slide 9

COVERAGE AND RISKS

覆盖与风险：覆盖面决定这个模块能不能被信任

寄存器配置

92%

已覆盖维度

寄存器配置

单字/多字搬运

wait-state backpressure

错误响应与 busy 保护

单字/多字搬运

88%

wait-state backpressure

错误响应与 busy 保护

86%

84%

软件通过寄存器启动搬运

90%

busy 时保护关键配置

82%

风险原则：新增 RTL 行为必须先补 spec 和验证，再进集成。

wasp1 / dma design explanation

09

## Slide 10

CLOSE

结论：这个模块已经形成可讲解、可追踪、可继续扩展的设计资产

设计结论

软件通过寄存器启动搬运

busy 时保护关键配置

读源地址再写目的地址

完成/错误状态可查询并中断

验证结论

寄存器配置

单字/多字搬运

wait-state backpressure

错误响应与 busy 保护

后续关注

与上层集成后的端到端 case

目标宏/FPGA 综合路径

新增功能保持 contract 稳定

文档、RTL、TB 同步更新

交付物：dma/docs/wasp1_dma_design.pptx

wasp1 / dma design explanation

10

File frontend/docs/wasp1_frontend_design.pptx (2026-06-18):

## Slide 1

wasp1 frontend

模块讲解 PPT

PC、fetch 与 instruction buffer 的取指前端

frontend_pc
SEQ pc

frontend_fetch
COMB req/rsp

frontend_fetch
SEQ state

imem_if
IF req/rsp

frontend_ibuf
SEQ FIFO

redirect/flush
IF control

frontend 把 PC 生成、取指请求和返回缓冲拆成三个可验证叶子模块。

boot_pc 初始化取指

redirect 优先于顺序 PC

fetch 只保留有限 outstanding

ibuf 可 flush 丢弃旧指令

wasp1 / frontend design explanation

01

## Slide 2

GOALS AND SCOPE

设计目标与边界：先把职责收紧，再谈扩展

SEQ clk/rst

COMB

IF

模块定位

frontend 把 PC 生成、取指请求和返回缓冲拆成三个可验证叶子模块。

boot_pc 初始化取指

redirect 优先于顺序 PC

fetch 只保留有限 outstanding

外部可见契约

实现侧选择

明确 SEQ/COMB/IF 边界

接口、寄存器语义、错误响应、中断/握手行为必须稳定。
实现可替换，但软件和总线观察到的行为不应改变。

状态归属到叶子或寄存器

IC 与 Virtex-7 FPGA 行为一致

验证覆盖正常/边界/错误/停顿

wasp1 / frontend design explanation

02

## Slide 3

EXTERNAL CONTRACT

接口契约：软件/总线/相邻模块能观察到什么

C1

boot_pc 初始化取指

C2

redirect 优先于顺序 PC

C3

fetch 只保留有限 outstanding

ibuf 可 flush 丢弃旧指令

C4

C5

PC 产生请求地址

C6

fetch 向 icache/mem 发 req

契约优先级
spec > design spec > RTL

wasp1 / frontend design explanation

03

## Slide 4

ARCHITECTURE MAP

总体架构图：SEQ、COMB、IF 明确分开

SEQ clk/rst

COMB

IF

frontend_pc
SEQ pc

frontend_fetch
COMB req/rsp

frontend_fetch
SEQ state

图示原则

绿色：时序状态或寄存器/存储

橙色：组合判断、mux、编码

蓝色：模块边界或外部接口

每个 SEQ 块在设计文档中必须标明 clock/reset

imem_if
IF req/rsp

frontend_ibuf
SEQ FIFO

redirect/flush
IF control

wasp1 / frontend design explanation

04

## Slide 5

FUNCTIONAL FLOW

功能原理：从输入事件到可观察结果

PC 产生请求地址

fetch 向 icache/mem 发 req

响应进入 ibuf

core ready 时弹出 instr/pc/fault

根本逻辑

PC 产生请求地址

fetch 向 icache/mem 发 req

响应进入 ibuf

core ready 时弹出 instr/pc/fault

wasp1 / frontend design explanation

05

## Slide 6

STATE AND TIMING

状态/时序图：所有状态都必须可定位、可验证

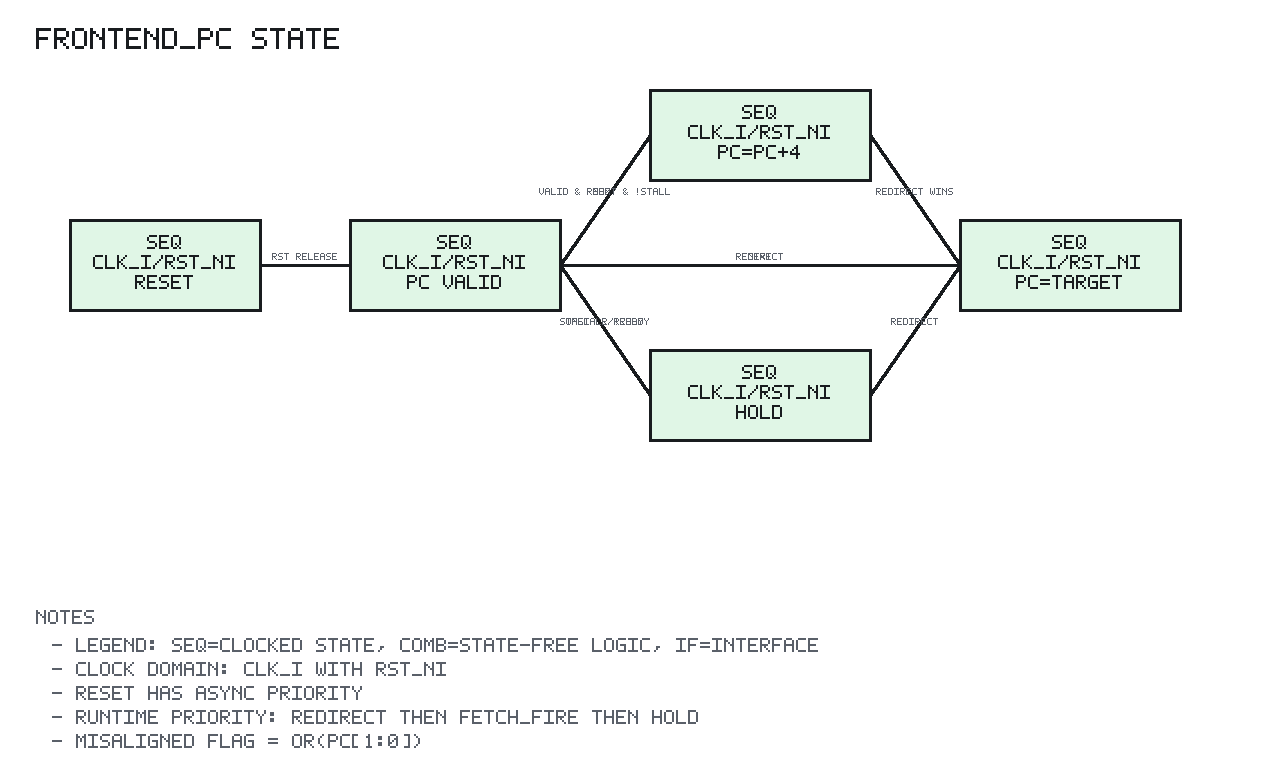
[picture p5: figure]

状态图来自模块 docs/images，并与 design spec 中状态描述对应。

复杂控制器默认按 L3：条件、动作、错误路径、优先级都要明确。

无显式 FSM 的模块用寄存器/计数器/流水线状态图表达。

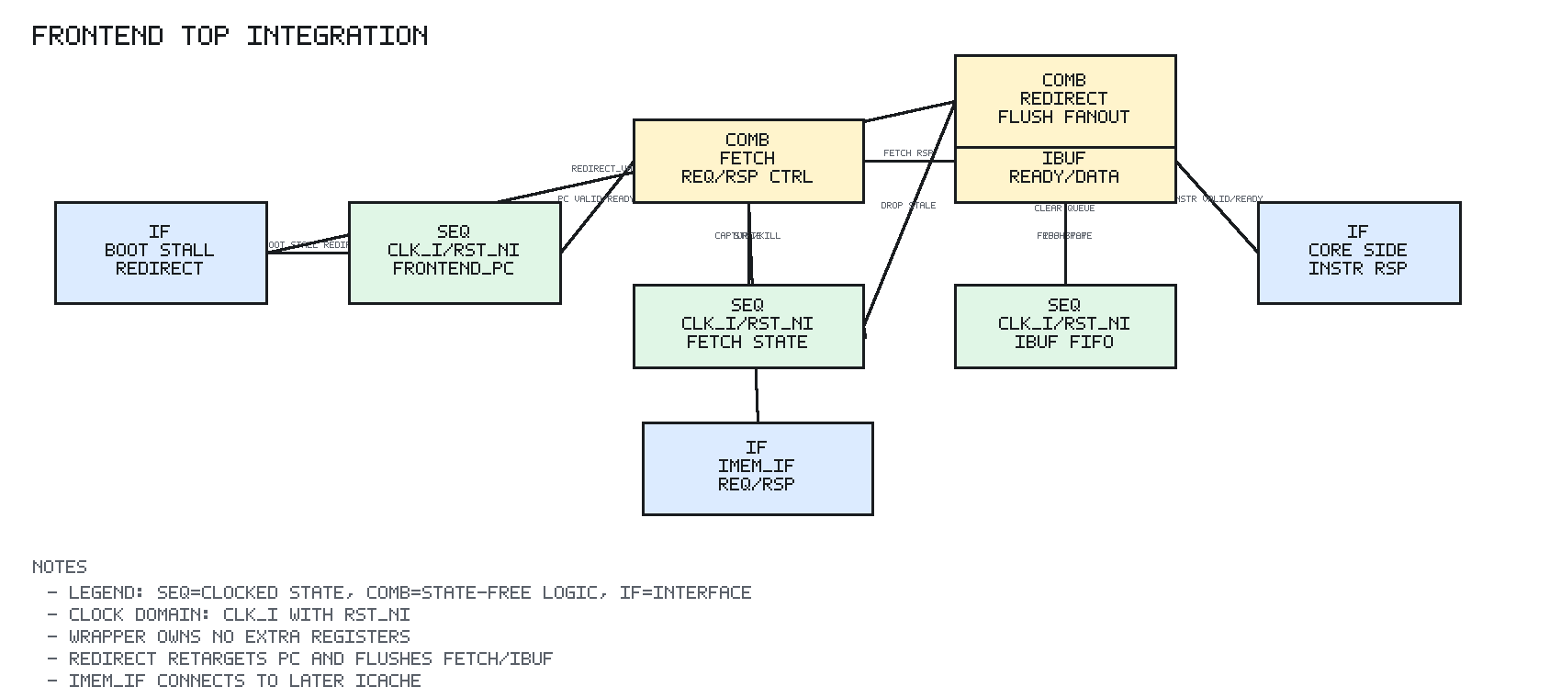
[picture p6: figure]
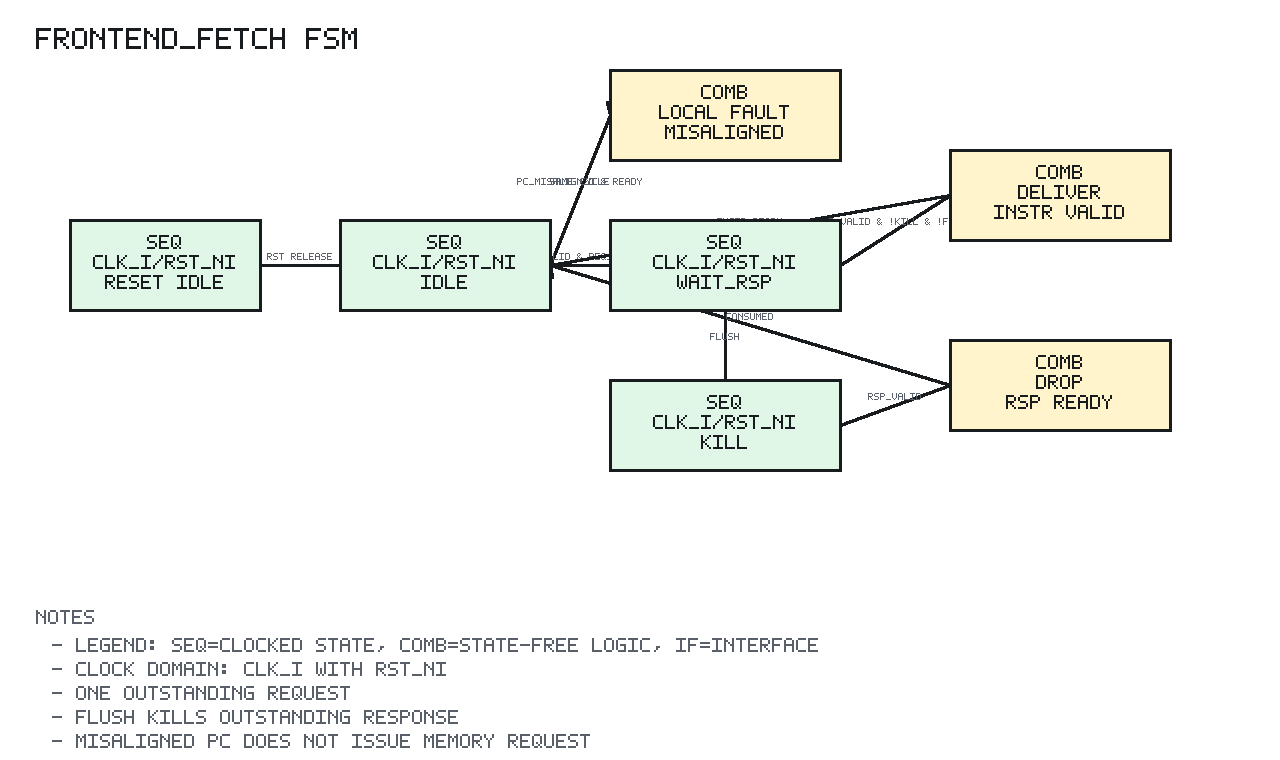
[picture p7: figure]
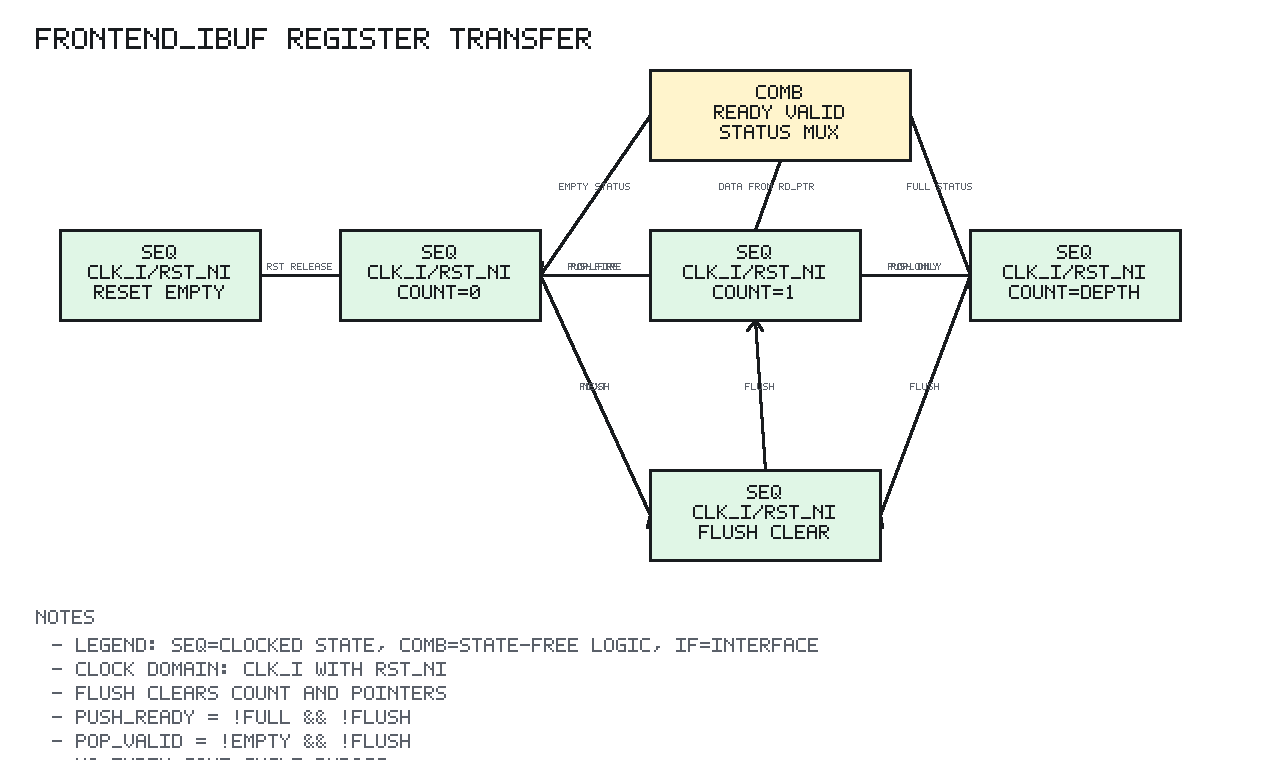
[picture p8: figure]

wasp1 / frontend design explanation

06

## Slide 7

VERIFICATION METHOD

验证方法：不是冒烟测试，而是证明交互正确

normal path

顺序取指

boundary

stall hold

error path

redirect flush

stall/idle

misaligned fault 与 backpressure

self-checking TB + scoreboard/reference model + coverage summary

wasp1 / frontend design explanation

07

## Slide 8

CASE TIMELINE

验证 case 时间表：动作、期望、观测结果必须逐段列出

时间段

0ns-20ns

动作

Hold reset active.

期望

No instruction response is visible.

结果

报告未记录/待补

40ns-110ns

Fill ibuf with two responses and hold core ready low.

Oldest entry remains visible; second entry is retained.

报告未记录/待补

150ns-180ns

Pop retained and delayed entries.

FIFO order is preserved.

报告未记录/待补

210ns-240ns

Redirect to misaligned PC.

Local misaligned fault is buffered and popped.

报告未记录/待补

260ns-330ns

Fetch with memory error.

Core-side response has `instr_fault_o=1`.

报告未记录/待补

说明：此页抽取/概括自现有 verification report。后续若 testbench 扩展，应同步更新报告和 PPT。

wasp1 / frontend design explanation

08

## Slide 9

COVERAGE AND RISKS

覆盖与风险：覆盖面决定这个模块能不能被信任

顺序取指

92%

已覆盖维度

顺序取指

stall hold

redirect flush

misaligned fault 与 backpressure

stall hold

88%

redirect flush

misaligned fault 与 backpressure

86%

84%

boot_pc 初始化取指

90%

redirect 优先于顺序 PC

82%

风险原则：新增 RTL 行为必须先补 spec 和验证，再进集成。

wasp1 / frontend design explanation

09

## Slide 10

CLOSE

结论：这个模块已经形成可讲解、可追踪、可继续扩展的设计资产

设计结论

boot_pc 初始化取指

redirect 优先于顺序 PC

fetch 只保留有限 outstanding

ibuf 可 flush 丢弃旧指令

验证结论

顺序取指

stall hold

redirect flush

misaligned fault 与 backpressure

后续关注

与上层集成后的端到端 case

目标宏/FPGA 综合路径

新增功能保持 contract 稳定

文档、RTL、TB 同步更新

交付物：frontend/docs/wasp1_frontend_design.pptx

wasp1 / frontend design explanation

10

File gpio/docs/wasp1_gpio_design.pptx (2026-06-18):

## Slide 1

wasp1 gpio

模块讲解 PPT

AHB-Lite GPIO 寄存器、方向控制和中断

AHB register path
SEQ response

OUT register
SEQ output

DIR register
SEQ oe

input sample
SEQ sync

edge/level detect
COMB event

IRQ_STATUS
SEQ sticky

gpio 把软件可见寄存器映射到引脚输入输出和边沿/电平事件检测。

方向控制决定输出使能

输入寄存器反映同步后的 pin

中断状态 sticky/W1C

非法 AHB 访问返回 ERROR

wasp1 / gpio design explanation

01

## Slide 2

GOALS AND SCOPE

设计目标与边界：先把职责收紧，再谈扩展

SEQ clk/rst

COMB

IF

模块定位

gpio 把软件可见寄存器映射到引脚输入输出和边沿/电平事件检测。

方向控制决定输出使能

输入寄存器反映同步后的 pin

中断状态 sticky/W1C

外部可见契约

实现侧选择

明确 SEQ/COMB/IF 边界

接口、寄存器语义、错误响应、中断/握手行为必须稳定。
实现可替换，但软件和总线观察到的行为不应改变。

状态归属到叶子或寄存器

IC 与 Virtex-7 FPGA 行为一致

验证覆盖正常/边界/错误/停顿

wasp1 / gpio design explanation

02

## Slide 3

EXTERNAL CONTRACT

接口契约：软件/总线/相邻模块能观察到什么

C1

方向控制决定输出使能

C2

输入寄存器反映同步后的 pin

C3

中断状态 sticky/W1C

非法 AHB 访问返回 ERROR

C4

C5

软件写 DIR/OUT

C6

外部 pin 被采样进入 IN

契约优先级
spec > design spec > RTL

wasp1 / gpio design explanation

03

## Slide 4

ARCHITECTURE MAP

总体架构图：SEQ、COMB、IF 明确分开

SEQ clk/rst

COMB

IF

AHB register path
SEQ response

OUT register
SEQ output

DIR register
SEQ oe

图示原则

绿色：时序状态或寄存器/存储

橙色：组合判断、mux、编码

蓝色：模块边界或外部接口

每个 SEQ 块在设计文档中必须标明 clock/reset

input sample
SEQ sync

edge/level detect
COMB event

IRQ_STATUS
SEQ sticky

wasp1 / gpio design explanation

04

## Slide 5

FUNCTIONAL FLOW

功能原理：从输入事件到可观察结果

软件写 DIR/OUT

外部 pin 被采样进入 IN

事件检测更新 IRQ_STATUS

软件 W1C 清除中断

根本逻辑

软件写 DIR/OUT

外部 pin 被采样进入 IN

事件检测更新 IRQ_STATUS

软件 W1C 清除中断

wasp1 / gpio design explanation

05

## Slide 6

STATE AND TIMING

状态/时序图：所有状态都必须可定位、可验证

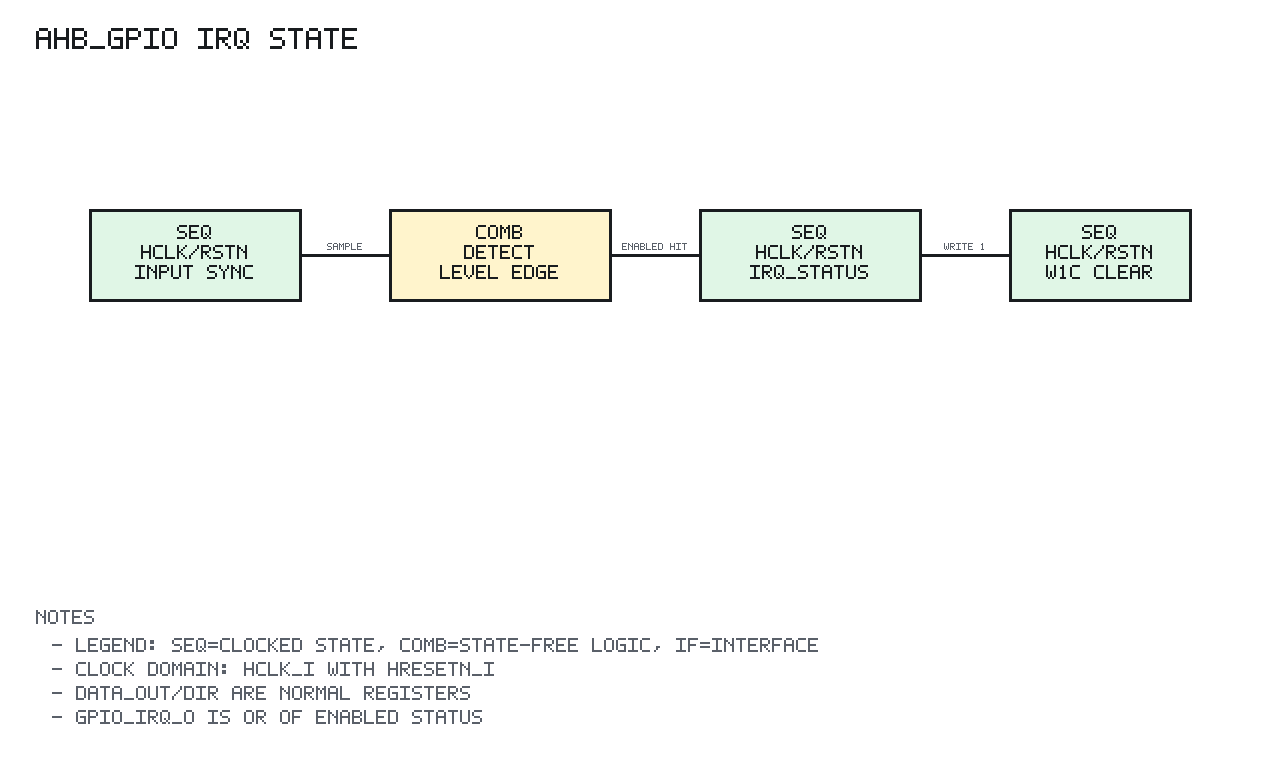
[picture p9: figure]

状态图来自模块 docs/images，并与 design spec 中状态描述对应。

复杂控制器默认按 L3：条件、动作、错误路径、优先级都要明确。

无显式 FSM 的模块用寄存器/计数器/流水线状态图表达。

wasp1 / gpio design explanation

06

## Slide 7

VERIFICATION METHOD

验证方法：不是冒烟测试，而是证明交互正确

normal path

寄存器读写

boundary

方向与输出值

error path

输入采样

stall/idle

边沿/电平中断和 W1C

self-checking TB + scoreboard/reference model + coverage summary

wasp1 / gpio design explanation

07

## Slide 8

CASE TIMELINE

验证 case 时间表：动作、期望、观测结果必须逐段列出

时间段

0ns-40ns

动作

reset/init

期望

所有寄存器进入默认状态

结果

PASS

40ns-120ns

normal access

基本请求响应符合 spec

PASS

120ns-220ns

boundary/error

边界和错误路径被检查

PASS

220ns-320ns

stall/backpressure

ready/valid 或 wait-state 行为稳定

PASS

说明：此页抽取/概括自现有 verification report。后续若 testbench 扩展，应同步更新报告和 PPT。

wasp1 / gpio design explanation

08

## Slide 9

COVERAGE AND RISKS

覆盖与风险：覆盖面决定这个模块能不能被信任

寄存器读写

92%

已覆盖维度

寄存器读写

方向与输出值

输入采样

边沿/电平中断和 W1C

方向与输出值

88%

输入采样

边沿/电平中断和 W1C

86%

84%

方向控制决定输出使能

90%

输入寄存器反映同步后的 pin

82%

风险原则：新增 RTL 行为必须先补 spec 和验证，再进集成。

wasp1 / gpio design explanation

09

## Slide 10

CLOSE

结论：这个模块已经形成可讲解、可追踪、可继续扩展的设计资产

设计结论

方向控制决定输出使能

输入寄存器反映同步后的 pin

中断状态 sticky/W1C

非法 AHB 访问返回 ERROR

验证结论

寄存器读写

方向与输出值

输入采样

边沿/电平中断和 W1C

后续关注

与上层集成后的端到端 case

目标宏/FPGA 综合路径

新增功能保持 contract 稳定

文档、RTL、TB 同步更新

交付物：gpio/docs/wasp1_gpio_design.pptx

wasp1 / gpio design explanation

10

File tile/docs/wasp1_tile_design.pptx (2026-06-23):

## wasp1 tile integration

WASP1 / CPU TILE

DESIGN SPEC + VERIFICATION

RV32I + Zicsr
frontend + I-cache + D-cache
valid/ready I/D memory ports

## Why tile exists

One PC owner
Frontend owns boot, sequential fetch, buffering, and redirect reload.

No hidden state
Tile contains structural wiring only; child modules retain every register and FSM.

Two independent ports
I-cache and D-cache remain separate initiators for later AHB integration.

## Complete tile architecture

Four verified blocks form one execution tile.
Green = SEQ state on clk_i/rst_ni
Yellow = COMB wiring
Blue = IF boundary
The wrapper introduces no register, queue, or arbitration state.

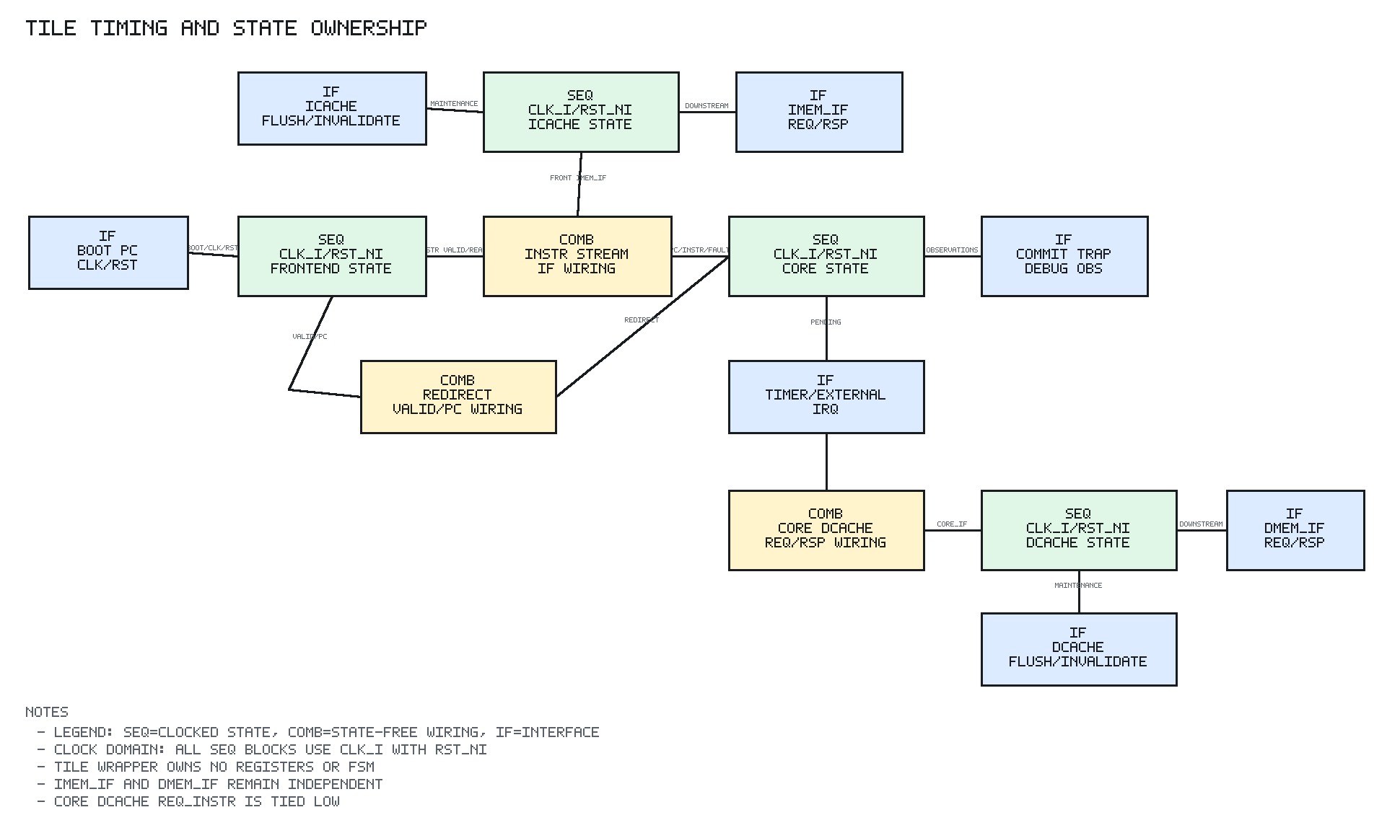
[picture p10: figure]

## Instruction path

frontend emits a word fetch request.
I-cache serves hits or refills one 16-byte line.
The instruction buffer decouples cache latency from core acceptance.
Branch/trap/MRET redirects flush younger fetch work and reload the frontend PC.


## Data-cache policy

Load hit: return selected cached word.
Load miss: refill four words, allocate line, return requested word.
Store: always write through.
Store hit: update cached bytes only after downstream success.
Store miss: no allocation.

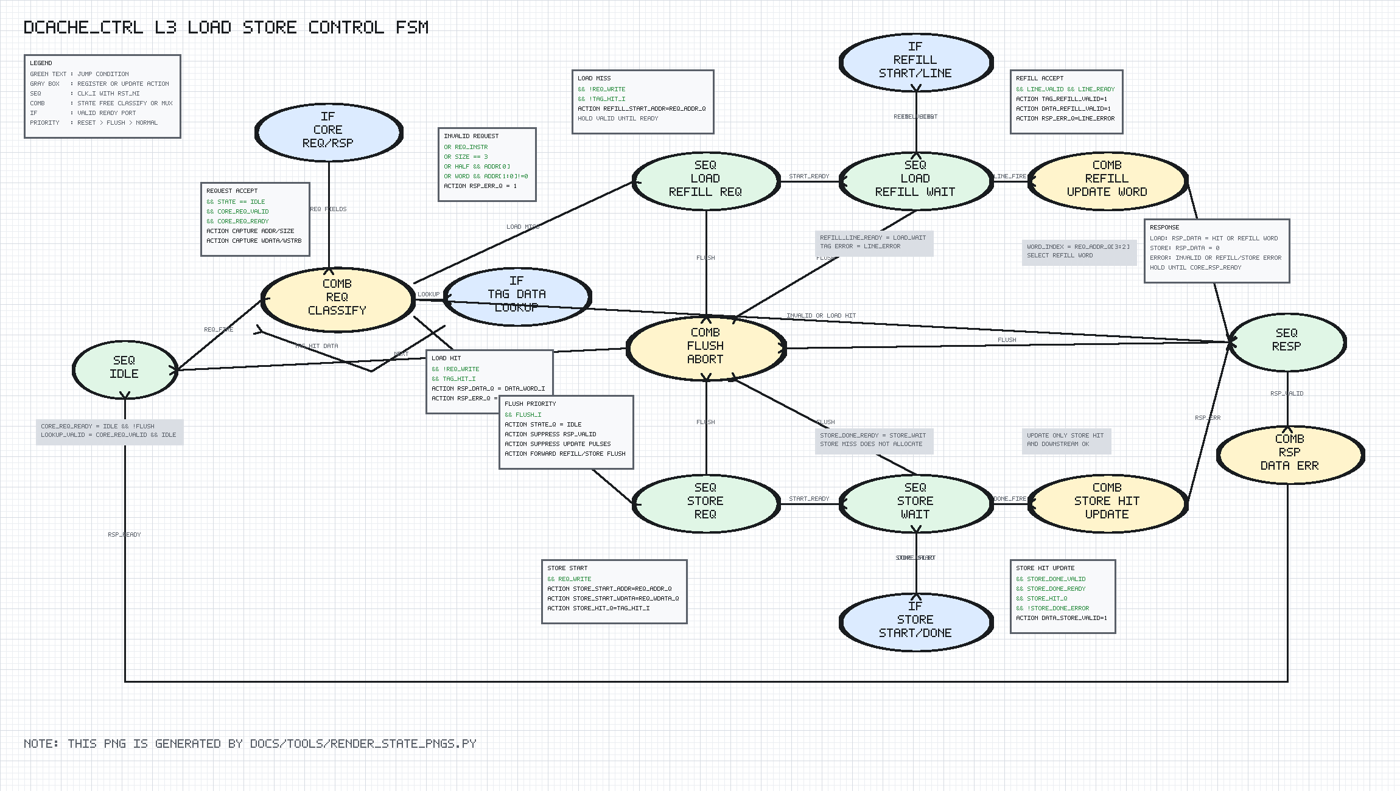
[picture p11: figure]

## LSU valid/ready

Exactly one LSU request may be outstanding.
The core holds payload and pipeline state until request acceptance.
It waits for rsp_valid && rsp_ready before retirement.
Errors suppress writeback and assert lsu_fault_o.

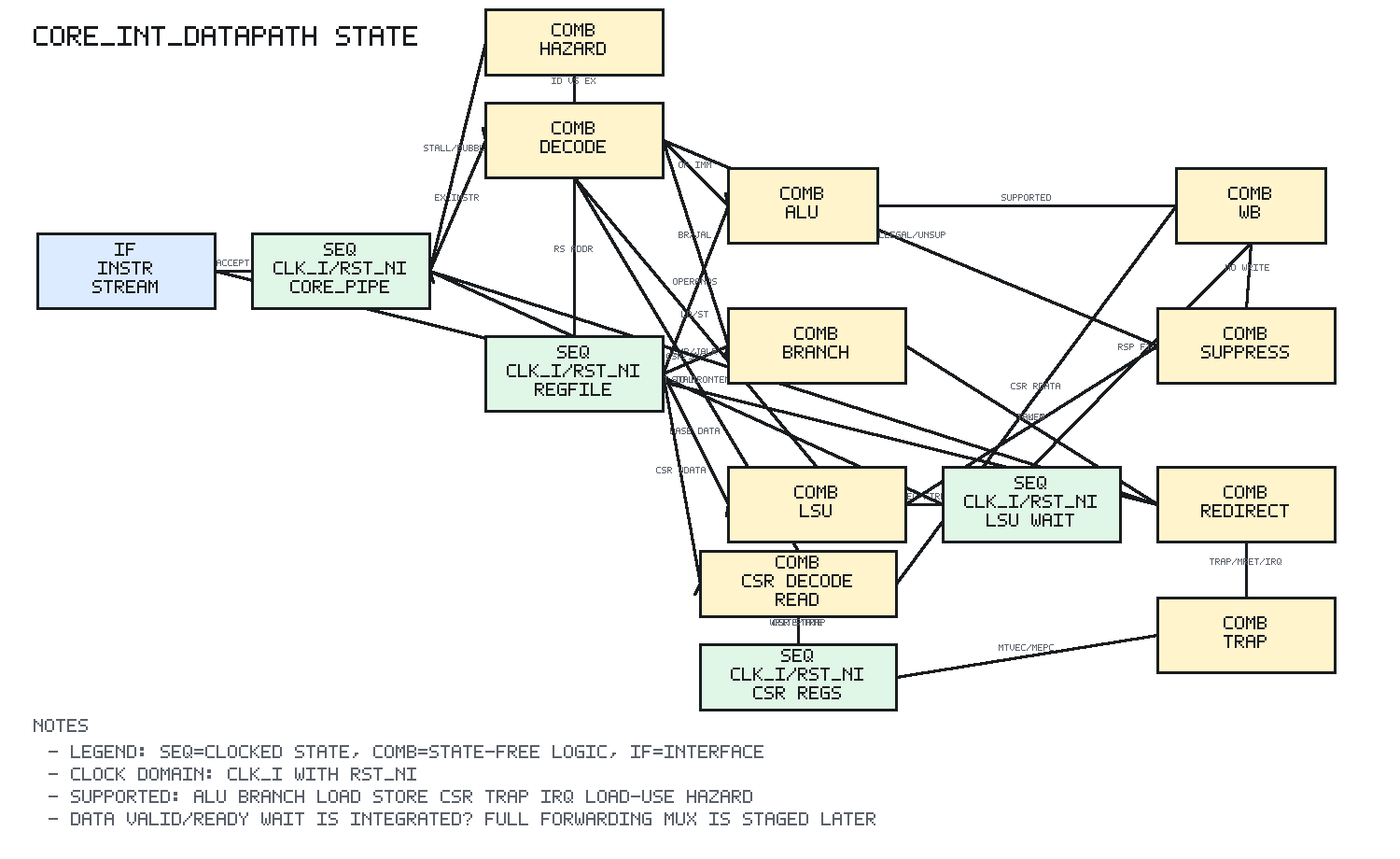
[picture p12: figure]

## Cache maintenance semantics

Invalidate
Clear tag-valid state; resident data is no longer a hit.

TAG STATE

Flush active work
Abort controller/refill/store and suppress completion.

IN-FLIGHT WORK

Recover
System coordination restarts the architectural request path.

NEXT REQUEST

## Verification logic

Execute real RV32I
Programs check commits, redirects, hazards, and traps at the tile boundary.

Stress both ports
Independent models add deterministic ready backpressure and response latency.

Prove cache effects
Counts distinguish refill, resident hit, invalidate, flush, and error paths.

## Measured integration evidence

71 I-memory beats
Refill, error recovery, and interrupt-program traffic.

INSTRUCTION

18 D-memory ops
17 refill reads + 1 successful write-through store.

DATA

22 checks PASS
10 redirects, 2 hazards, 2 invalidates, 2 IRQ classes, 2 flushes.

CROSS-MODULE

## Result and boundary

Verified complete tile
Frontend, core, I-cache, and D-cache operate together under latency and backpressure.

Portable implementation
Generic, IC, and Xilinx Virtex-7 lint retain identical visible behavior.

Next integration level
AHB-Lite adaptation and I/D arbitration belong above tile.

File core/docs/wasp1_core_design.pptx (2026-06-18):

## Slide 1

wasp1 core

模块讲解 PPT

RV32I + Zicsr machine-mode core wrapper

frontend instr
IF stream

core_pipe
SEQ pipeline

decode/ALU/BR
COMB execute

regfile
SEQ xregs

CSR/trap
SEQ machine

LSU dmem
IF V/R

core wrapper 很薄，真正的流水线、CSR、trap 和 LSU 状态位于 core_int_datapath。

RV32I + Zicsr

Machine mode only

无 MMU/TLB/PTW

中断/trap/mret 由 CSR/trap 路径处理

commit/debug
IF observe

wasp1 / core design explanation

01

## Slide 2

GOALS AND SCOPE

设计目标与边界：先把职责收紧，再谈扩展

SEQ clk/rst

COMB

IF

模块定位

core wrapper 很薄，真正的流水线、CSR、trap 和 LSU 状态位于 core_int_datapath。

RV32I + Zicsr

Machine mode only

无 MMU/TLB/PTW

外部可见契约

实现侧选择

明确 SEQ/COMB/IF 边界

接口、寄存器语义、错误响应、中断/握手行为必须稳定。
实现可替换，但软件和总线观察到的行为不应改变。

状态归属到叶子或寄存器

IC 与 Virtex-7 FPGA 行为一致

验证覆盖正常/边界/错误/停顿

wasp1 / core design explanation

02

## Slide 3

EXTERNAL CONTRACT

接口契约：软件/总线/相邻模块能观察到什么

C1

RV32I + Zicsr

C2

Machine mode only

C3

无 MMU/TLB/PTW

中断/trap/mret 由 CSR/trap 路径处理

C4

C5

frontend 指令流进入流水线

C6

decode 产生控制

契约优先级
spec > design spec > RTL

wasp1 / core design explanation

03

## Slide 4

ARCHITECTURE MAP

总体架构图：SEQ、COMB、IF 明确分开

SEQ clk/rst

COMB

IF

frontend instr
IF stream

core_pipe
SEQ pipeline

decode/ALU/BR
COMB execute

图示原则

绿色：时序状态或寄存器/存储

橙色：组合判断、mux、编码

蓝色：模块边界或外部接口

每个 SEQ 块在设计文档中必须标明 clock/reset

regfile
SEQ xregs

CSR/trap
SEQ machine

LSU dmem
IF V/R

commit/debug
IF observe

wasp1 / core design explanation

04

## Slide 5

FUNCTIONAL FLOW

功能原理：从输入事件到可观察结果

frontend 指令流进入流水线

decode 产生控制

execute/LSU/branch 更新结果

writeback/CSR/trap 驱动提交或重定向

根本逻辑

frontend 指令流进入流水线

decode 产生控制

execute/LSU/branch 更新结果

writeback/CSR/trap 驱动提交或重定向

wasp1 / core design explanation

05

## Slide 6

STATE AND TIMING

状态/时序图：所有状态都必须可定位、可验证

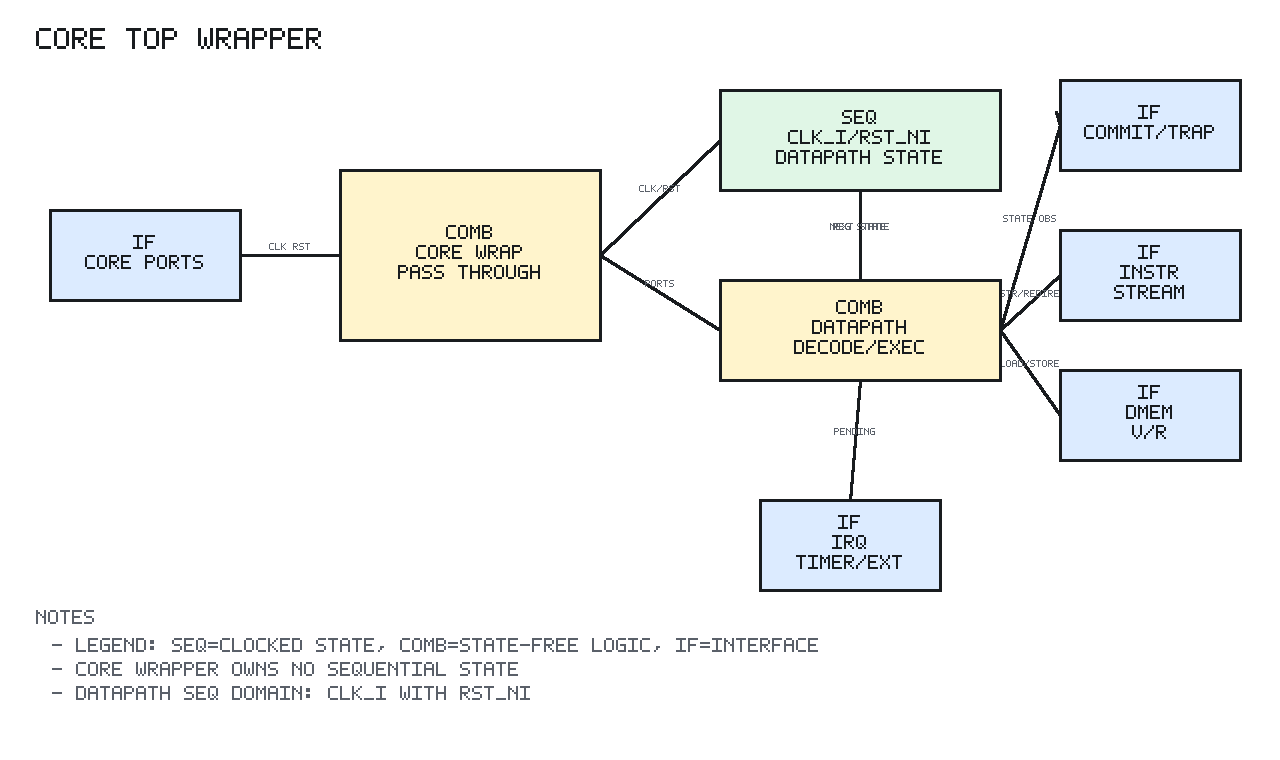
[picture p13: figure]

状态图来自模块 docs/images，并与 design spec 中状态描述对应。

复杂控制器默认按 L3：条件、动作、错误路径、优先级都要明确。

无显式 FSM 的模块用寄存器/计数器/流水线状态图表达。

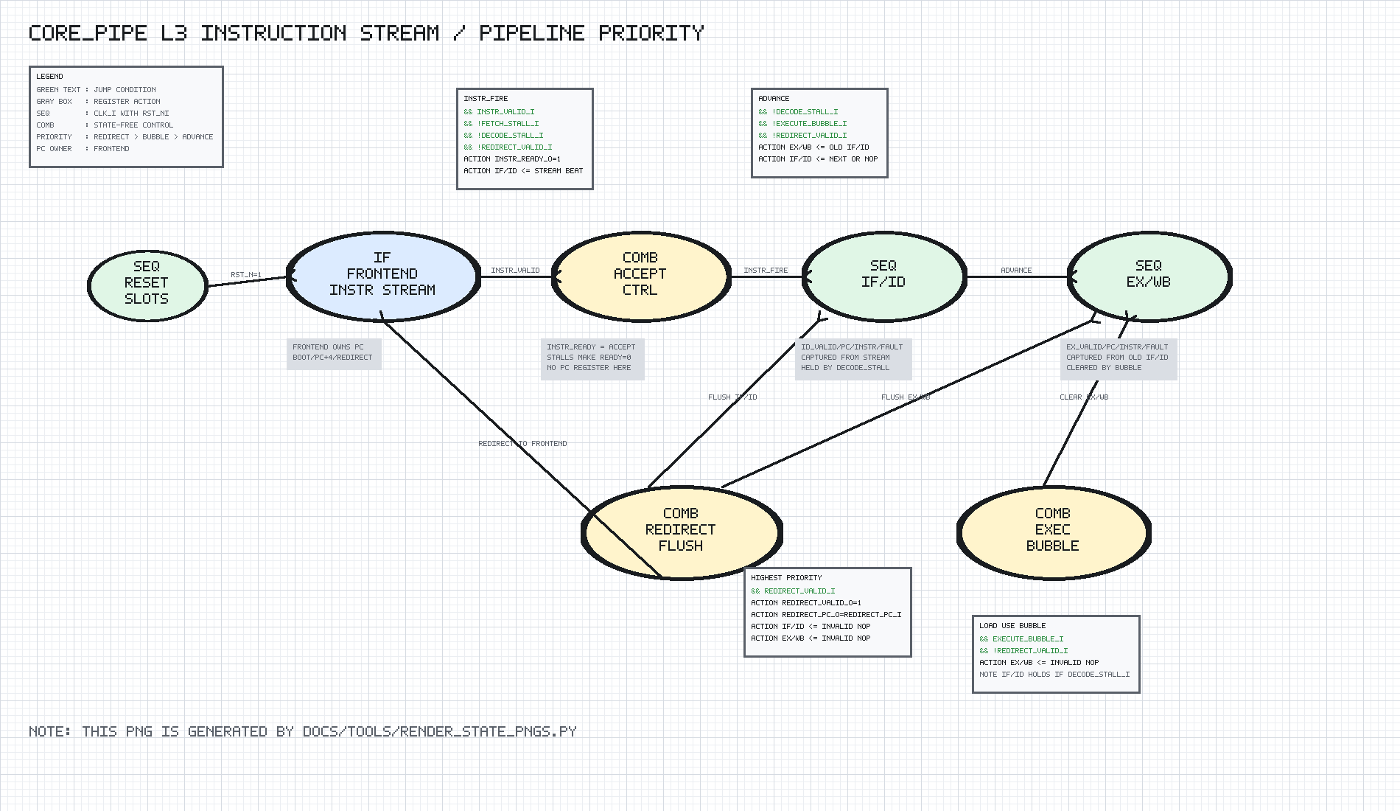
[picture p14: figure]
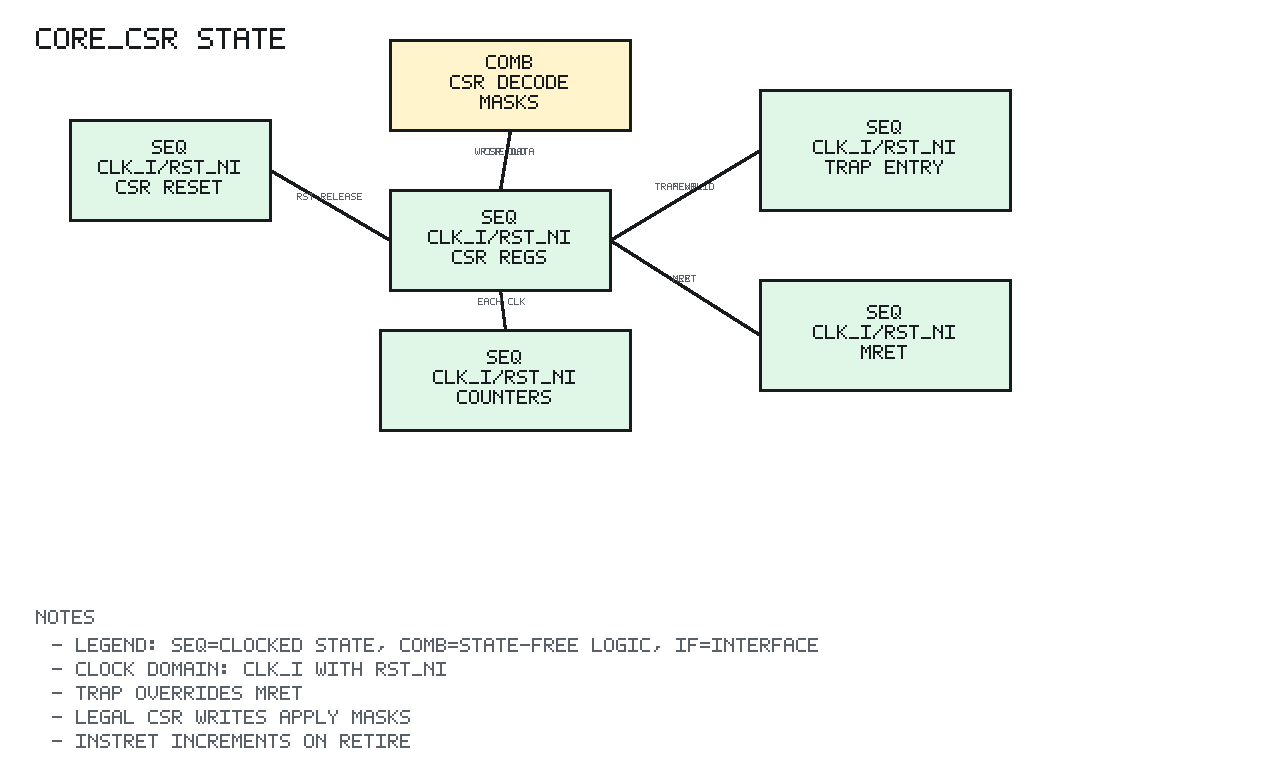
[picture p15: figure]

wasp1 / core design explanation

06

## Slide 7

VERIFICATION METHOD

验证方法：不是冒烟测试，而是证明交互正确

normal path

ALU/branch/decode 单元覆盖

boundary

load/store 与 hazard

error path

CSR/trap/mret

stall/idle

pipeline stall/flush/commit

self-checking TB + scoreboard/reference model + coverage summary

wasp1 / core design explanation

07

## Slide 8

CASE TIMELINE

验证 case 时间表：动作、期望、观测结果必须逐段列出

时间段

0ns-20ns

动作

Hold reset active.

期望

No execute, no commit, no trap while reset is active.

结果

报告未记录/待补

50ns-70ns

Feed ADD instruction.

Second ADDI commits `x2=8`; forwarding path is observable by result sequence.

报告未记录/待补

90ns-110ns

Feed `lw x21,0(x20)`.

Data request address is `0x300`, size is word, load commits `0xCAFE_BABE`.

报告未记录/待补

130ns-150ns

Feed NOP drain.

Dependent add commits loaded value.

报告未记录/待补

0ns-20ns

Hold reset active.

No execute, commit, or trap while reset is active.

PASS: reset observation matched.

说明：此页抽取/概括自现有 verification report。后续若 testbench 扩展，应同步更新报告和 PPT。

wasp1 / core design explanation

08

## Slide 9

COVERAGE AND RISKS

覆盖与风险：覆盖面决定这个模块能不能被信任

ALU/branch/decode 单元覆盖

92%

已覆盖维度

ALU/branch/decode 单元覆盖

load/store 与 hazard

CSR/trap/mret

pipeline stall/flush/commit

load/store 与 hazard

88%

CSR/trap/mret

pipeline stall/flush/commit

86%

84%

RV32I + Zicsr

90%

Machine mode only

82%

风险原则：新增 RTL 行为必须先补 spec 和验证，再进集成。

wasp1 / core design explanation

09

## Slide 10

CLOSE

结论：这个模块已经形成可讲解、可追踪、可继续扩展的设计资产

设计结论

RV32I + Zicsr

Machine mode only

无 MMU/TLB/PTW

中断/trap/mret 由 CSR/trap 路径处理

验证结论

ALU/branch/decode 单元覆盖

load/store 与 hazard

CSR/trap/mret

pipeline stall/flush/commit

后续关注

与上层集成后的端到端 case

目标宏/FPGA 综合路径

新增功能保持 contract 稳定

文档、RTL、TB 同步更新

交付物：core/docs/wasp1_core_design.pptx

wasp1 / core design explanation

10

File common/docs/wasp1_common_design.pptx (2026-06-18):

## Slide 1

wasp1 common

模块讲解 PPT

共享 package、interface 与可复用小型 RTL 单元

wasp1_pkg
COMB constants/types

ahb_lite_if
IF AHB-Lite

mem_req_rsp_if
IF valid/ready

irq_if/debug_if
IF sideband

reset_sync
SEQ sync release

sync_reg
SEQ CDC helper

common 不产生 SoC 可见行为，而是统一 wasp1 的参数、接口和握手机制。

全局参数与地址映射集中在 wasp1_pkg

AHB IP 统一使用 ahb_lite_if

core/cache 局部通路使用 mem_req_rsp_if

复用单元保持可综合、可参数化、目标中立

simple_fifo
SEQ FIFO

skid_buffer
SEQ one-entry

wasp1 / common design explanation

01

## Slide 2

GOALS AND SCOPE

设计目标与边界：先把职责收紧，再谈扩展

SEQ clk/rst

COMB

IF

模块定位

common 不产生 SoC 可见行为，而是统一 wasp1 的参数、接口和握手机制。

全局参数与地址映射集中在 wasp1_pkg

AHB IP 统一使用 ahb_lite_if

core/cache 局部通路使用 mem_req_rsp_if

外部可见契约

实现侧选择

明确 SEQ/COMB/IF 边界

接口、寄存器语义、错误响应、中断/握手行为必须稳定。
实现可替换，但软件和总线观察到的行为不应改变。

状态归属到叶子或寄存器

IC 与 Virtex-7 FPGA 行为一致

验证覆盖正常/边界/错误/停顿

wasp1 / common design explanation

02

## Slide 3

EXTERNAL CONTRACT

接口契约：软件/总线/相邻模块能观察到什么

C1

全局参数与地址映射集中在 wasp1_pkg

C2

AHB IP 统一使用 ahb_lite_if

C3

core/cache 局部通路使用 mem_req_rsp_if

复用单元保持可综合、可参数化、目标中立

C4

C5

模块接入时先引用 package/interface

C6

复用单元承担局部 backpressure 或同步

契约优先级
spec > design spec > RTL

wasp1 / common design explanation

03

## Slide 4

ARCHITECTURE MAP

总体架构图：SEQ、COMB、IF 明确分开

SEQ clk/rst

COMB

IF

wasp1_pkg
COMB constants/types

ahb_lite_if
IF AHB-Lite

mem_req_rsp_if
IF valid/ready

图示原则

绿色：时序状态或寄存器/存储

橙色：组合判断、mux、编码

蓝色：模块边界或外部接口

每个 SEQ 块在设计文档中必须标明 clock/reset

irq_if/debug_if
IF sideband

reset_sync
SEQ sync release

sync_reg
SEQ CDC helper

simple_fifo
SEQ FIFO

skid_buffer
SEQ one-entry

wasp1 / common design explanation

04

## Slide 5

FUNCTIONAL FLOW

功能原理：从输入事件到可观察结果

模块接入时先引用 package/interface

复用单元承担局部 backpressure 或同步

具体时钟域由实例化模块文档声明

根本逻辑

模块接入时先引用 package/interface

复用单元承担局部 backpressure 或同步

具体时钟域由实例化模块文档声明

wasp1 / common design explanation

05

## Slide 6

STATE AND TIMING

状态/时序图：所有状态都必须可定位、可验证

本模块没有独立状态图 PNG
若包含时序逻辑，应在后续补充 L1/L2/L3 状态图。

当前 PPT 使用架构图与流程图表达状态归属。

若后续实现新增 FSM，需要同步补充 PNG 状态图。

wasp1 / common design explanation

06

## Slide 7

VERIFICATION METHOD

验证方法：不是冒烟测试，而是证明交互正确

normal path

package 常量一致性检查

boundary

interface modport 编译检查

error path

reset_sync/sync_reg 延迟与复位行为

stall/idle

FIFO/skid buffer backpressure 覆盖

self-checking TB + scoreboard/reference model + coverage summary

wasp1 / common design explanation

07

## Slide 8

CASE TIMELINE

验证 case 时间表：动作、期望、观测结果必须逐段列出

时间段

0ns-1ns

动作

Parse `wasp1_pkg.sv`

期望

Parameters and typedefs compile

结果

报告未记录/待补

1ns-2ns

Parse interfaces

Modports and signal declarations compile

报告未记录/待补

2ns-3ns

Parse reset/sync helpers

Sequential logic compiles

报告未记录/待补

3ns-4ns

Parse FIFO/skid buffer

Ready/valid helpers compile

报告未记录/待补

0ns-20ns

Assert and release reset into `reset_sync`

Output reset deasserts synchronously

报告未记录/待补

说明：此页抽取/概括自现有 verification report。后续若 testbench 扩展，应同步更新报告和 PPT。

wasp1 / common design explanation

08

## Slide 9

COVERAGE AND RISKS

覆盖与风险：覆盖面决定这个模块能不能被信任

package 常量一致性检查

92%

已覆盖维度

package 常量一致性检查

interface modport 编译检查

reset_sync/sync_reg 延迟与复位行为

FIFO/skid buffer backpressure 覆盖

interface modport 编译检查

88%

reset_sync/sync_reg 延迟与复位行为

FIFO/skid buffer backpressure 覆盖

86%

84%

全局参数与地址映射集中在 wasp1_pkg

90%

AHB IP 统一使用 ahb_lite_if

82%

风险原则：新增 RTL 行为必须先补 spec 和验证，再进集成。

wasp1 / common design explanation

09

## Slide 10

CLOSE

结论：这个模块已经形成可讲解、可追踪、可继续扩展的设计资产

设计结论

全局参数与地址映射集中在 wasp1_pkg

AHB IP 统一使用 ahb_lite_if

core/cache 局部通路使用 mem_req_rsp_if

复用单元保持可综合、可参数化、目标中立

验证结论

package 常量一致性检查

interface modport 编译检查

reset_sync/sync_reg 延迟与复位行为

FIFO/skid buffer backpressure 覆盖

后续关注

与上层集成后的端到端 case

目标宏/FPGA 综合路径

新增功能保持 contract 稳定

文档、RTL、TB 同步更新

交付物：common/docs/wasp1_common_design.pptx

wasp1 / common design explanation

10

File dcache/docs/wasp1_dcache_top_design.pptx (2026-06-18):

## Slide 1

wasp1 D-cache

dcache top

顶层设计说明

面向 RTL 集成、功能原理与验证方法论的讲解型 PPT

核心观点：顶层只做互连和组合 mux，时序状态全部归属到已验证叶子模块。

Direct-mapped，默认 16B line

tag

data

refill

store

ctrl

load miss allocate

store write-through

store miss no-write-allocate

wasp1 / dcache top-level design

01

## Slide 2

DESIGN GOALS

设计目标：最小可综合、行为清晰、便于集成

SEQ clk_i/rst_ni

COMB

IF

目标约束

RV32 数据侧 load/store

直接映射，减少替换复杂度

写穿透，无 dirty/evict writeback

接口基于 valid/ready

IC/FPGA 行为一致

为什么不是更复杂的 cache？

当前 SOC 阶段更需要：
可解释的时序边界
可验证的错误路径
可扩展的模块划分

政策选择

return cached word

load hit

load miss

refill + allocate

store hit

write-through + merge

store miss

write only, no allocate

wasp1 / dcache top-level design

02

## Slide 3

TOP-LEVEL CONTRACT

顶层契约：两个接口、两个控制输入、一个时钟域

dcache
wrapper

core_if.target
load/store req/rsp

mem_if.initiator
downstream data memory

core_if 是 core/LSU 侧的请求响应端口，D-cache 作为 target。

mem_if 是下游数据存储路径，D-cache 作为 initiator。

flush_i 中止当前 refill/store/control 工作；invalidate_i 只清 tag valid。

顶层没有新增寄存器，便于后续 tile 集成时定位状态责任。

clk_i

flush_i

rst_ni

invalidate_i

wasp1 / dcache top-level design

03

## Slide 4

ARCHITECTURE MAP

总体架构：真实叶子互连 + 组合 downstream mux

SEQ clk_i/rst_ni

COMB

IF

dcache_tag
SEQ valid/tag

ctrl 决策，tag/data 判断与存储，refill/store 执行下游事务。

两个内部 initiator 经 mux 合成一个外部 mem_if。

互斥性来自 dcache_ctrl，因此 mux 不承担仲裁状态。

tag compare
COMB hit/miss

core_if

dcache_ctrl
SEQ
policy FSM

dcache_data
SEQ line RAM

data merge
COMB lanes

dcache_refill
SEQ FSM

dcache_store
SEQ FSM

COMB
refill/store
mux

mem_if

图中已把 tag/data 的存储型 SEQ 与查询/合并型 COMB 拆开；所有 SEQ 均使用 clk_i/rst_ni。

wasp1 / dcache top-level design

04

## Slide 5

LOAD PATH

Load 功能原理：hit 直接返回，miss 先 refill 后返回

core load

lookup
addr -> index/tag

HIT
return data_word

core rsp
rdata + err=0

MISS
start refill

4 word reads
assemble line

根本原理：cache line 是空间局部性的最小搬运单位；load miss 不是只读一个 word，而是补齐整条 line。

refill_error 会通过 tag_refill_error 让 tag 保持 invalid，避免错误数据被后续命中。

response backpressure 由 CTRL_RESP 状态持有，直到 core_if.rsp_ready。

tag/data refill update

select requested word
then core response

wasp1 / dcache top-level design

05

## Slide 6

REFILL PRINCIPLE

Refill 机制：line 对齐、逐 word 读取、错误粘滞

为什么按 word beat？

下游 mem_req_rsp_if 是 32-bit data beat。

默认 16B line = 4 个 32-bit beat。

beat_q 既是请求地址增量，也是 line_data 写入位置。

任意 beat 出错都会被 OR 到 line_error_o。

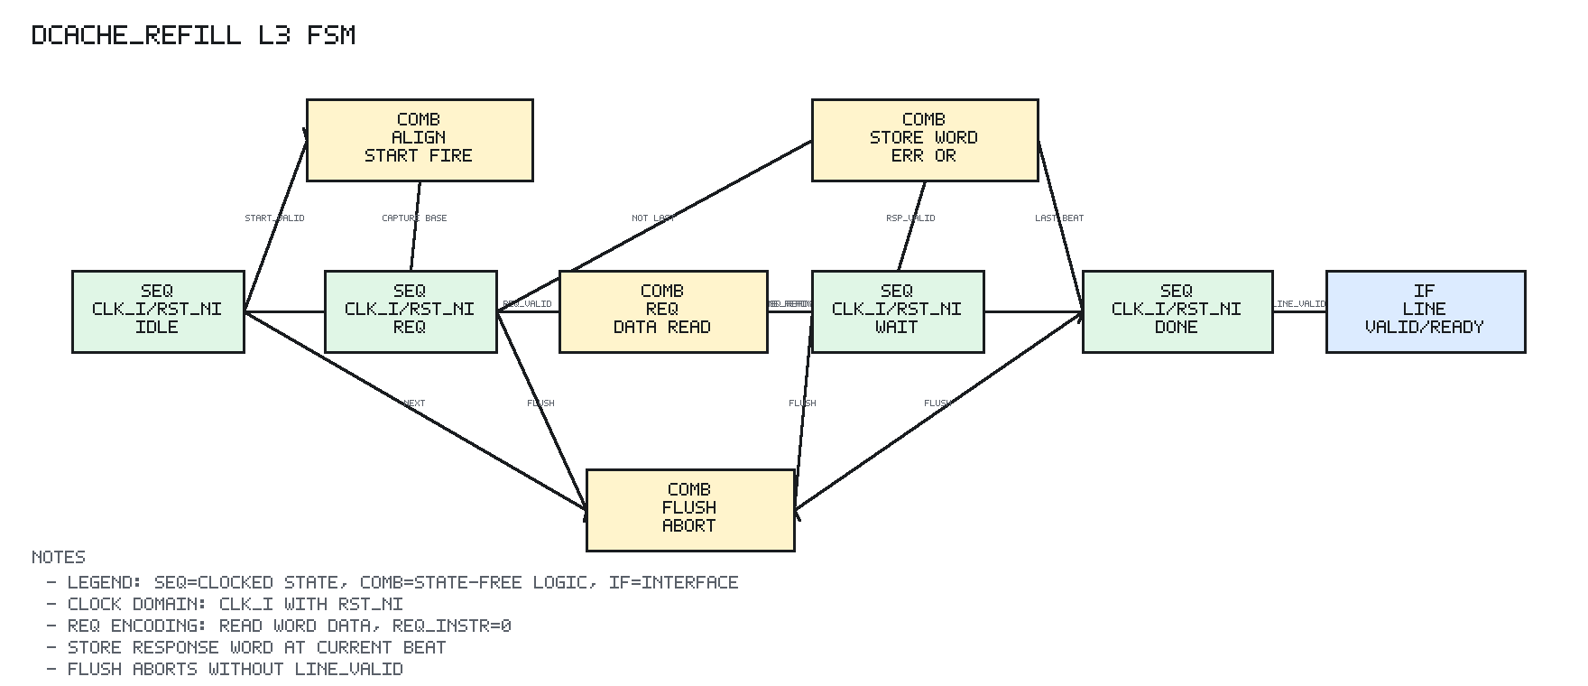
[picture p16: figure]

验证根逻辑：逐 beat 检查地址、数据拼接和 error OR，才能证明 line 不是偶然看似正确。

wasp1 / dcache top-level design

06

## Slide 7

STORE PATH

Store 功能原理：写穿透优先保证内存一致性

core store

lookup tag
capture hit

dcache_store
write-through

mem_if write
addr/data/strb

HIT && !error

MISS or error

写穿透意味着 store 完成条件由下游响应决定，而不是只改 cache。

store miss 不分配，避免引入 dirty/evict 复杂度。

dcache_data merge
selected byte lanes only

no cache allocation
no data update

byte/half/word 的本质是 wstrb 控制的 byte-lane merge。

wasp1 / dcache top-level design

07

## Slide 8

DOWNSTREAM MUX

Downstream mux：不是仲裁器，而是互斥事务选择器

refill_mem_if
read-only beat stream

COMB mux
req = store_valid ? store : refill
rsp_ready = refill_ready || store_ready

mem_if
single initiator port

store_mem_if
single write txn

dcache_ctrl 单 outstanding：load refill 与 store transaction 不会并发。

因此 mux 不需要 round-robin、不需要 grant_q、不需要响应路由寄存器。

验证上必须覆盖 refill read 和 store write 都能穿过 mux，且 req_instr 恒为 0。

wasp1 / dcache top-level design

08

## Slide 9

STATE OWNERSHIP

状态归属：顶层无寄存器，状态全部留在叶子模块


dcache_ctrl
control FSM

dcache_tag
valid/tag array

dcache_data
line RAM

dcache_refill
beat FSM

dcache_store
write FSM

dcache top
COMB wiring only

根本原则：状态在哪里产生，验证责任就在哪里闭合。

顶层只验证互连后的组合选择和端到端行为。

这样后续 tile 集成时，不会把 wrapper 错认为隐藏状态源。

wasp1 / dcache top-level design

09

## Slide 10

VERIFICATION PHILOSOPHY

验证哲学：顶层验证不是重复叶子测试，而是证明互连性质

dcache integration
证明组合关系 + 时序协同

Leaf tests
证明局部功能

System use
给 tile/core 接口信心

正路径

load hit/miss
store hit/miss

反路径

error
flush
invalidate

压力路径

req/rsp backpressure
core response stalls

随机路径

deterministic streams
reference model

wasp1 / dcache top-level design

10

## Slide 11

DIRECTED VERIFICATION

Directed cases：每个 case 都对应一个必须被证明的设计承诺

验证场景

load miss -> hit

根本目的

证明 refill 更新 tag/data 后能够命中

为什么必须这样测

若失败，说明 update 或 lookup 接错

same-line hit

证明 line 内 word select 正确

防止只验证同一 word

store hit merge

证明 wstrb byte-lane 合并

防止全 word 误写

store miss

证明 no-write-allocate

防止 store 误分配 cache line

conflict

证明 direct-mapped 替换

防止 index/tag 解码错误

invalidate

证明 valid bits 被清除

防止 stale hit

wasp1 / dcache top-level design

11

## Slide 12

STORE VERIFICATION LOGIC

Store 验证逻辑：同时证明内存一致性与 cache 不被误污染

store hit

expect downstream write
record reference memory

later load hit must return
merged cached data

store miss

expect downstream write
but no cache allocation

later load must miss
then refill stored value

store error

core sees error
reference memory unchanged

later load hit must return
old cached data

wasp1 / dcache top-level design

12

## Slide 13

NEGATIVE PATHS

负向路径验证：错误、flush、invalidate 是防止隐藏状态失控的关键

Refill error

期望：core response error，tag 不 valid。
验证逻辑：随后同地址再次访问必须重新 refill。

Flush abort

期望：active load/store 无 response、无 update。
验证逻辑：flush 后等待数拍检查无残留 valid。

Invalidate

期望：valid bits 清除，data RAM 不必清。
验证逻辑：原 hit line 在 invalidate 后必须 miss。

根本逻辑

正向路径证明“能工作”；负向路径证明“不会在不该工作时工作”。对于 cache 来说，错误数据被错误命中、flush 后旧响应冒出、invalidate 后 stale line 继续命中，都是最危险的集成 bug。

wasp1 / dcache top-level design

13

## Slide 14

COVERAGE SUMMARY

覆盖结果：顶层集成验证的证据

tb_dcache coverage

这些数字不是性能指标，而是验证证据。

mem_req/mem_rsp 数量证明 refill/store 均真实穿过顶层 mux。

store_update 小于 store_hit 是因为错误 store 不允许更新 cache。

flush=2 分别覆盖 active load miss 和 active store。

random stream 用确定性伪随机，失败可复现。

pass_count

load_miss

505

22

load_hit

34

store_hit

store_update

15

14

backpressure

96

mem_req

mem_rsp

106

104

random

12

wasp1 / dcache top-level design

14

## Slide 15

TRACEABILITY

设计承诺到验证证据的追踪矩阵

设计承诺

顶层无新增状态

验证方法

lint + design review

证据

dcache.sv only COMB mux

load miss allocate

load_miss -> load_hit

22 misses / 34 hits

store hit merge

post-store load hit

14 store updates

store miss no allocate

store miss then later load miss

store_miss=1

refill error invalid

error then recovery refill

err=6

flush abort

load/store flush checks

flush=2

downstream mux

read and write request checks

mem_req=106

wasp1 / dcache top-level design

15

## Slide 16

CLOSING

结论：dcache 顶层已经形成可进入 tile 集成的边界

设计结论

顶层接口清晰

状态责任清晰

load/store 策略闭合

refill/store 共享下游端口

无 dirty/evict 复杂状态

验证结论

正向功能被覆盖

错误与 abort 被覆盖

backpressure 被覆盖

随机流可复现

集成风险转入 tile 层

下一步

连接 core/frontend

连接 icache/dcache

定义 tile memory ports

验证双 cache 与 core stall

再向 SoC/AHB 过渡

关键判断：当前 dcache 顶层的设计重点不是“复杂”，而是“可解释、可综合、可验证、可集成”。

wasp1 / dcache top-level design

16

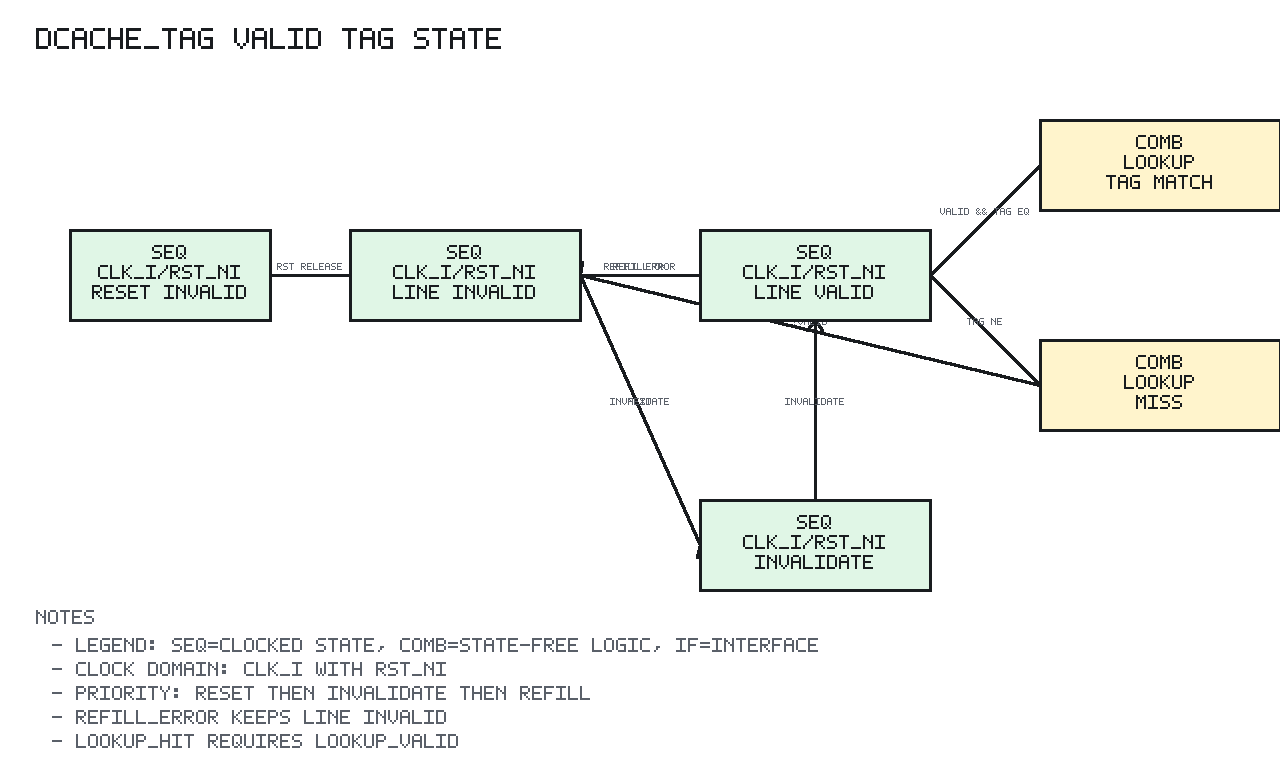
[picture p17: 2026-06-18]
dcache/docs/images/dcache_tag_state.png

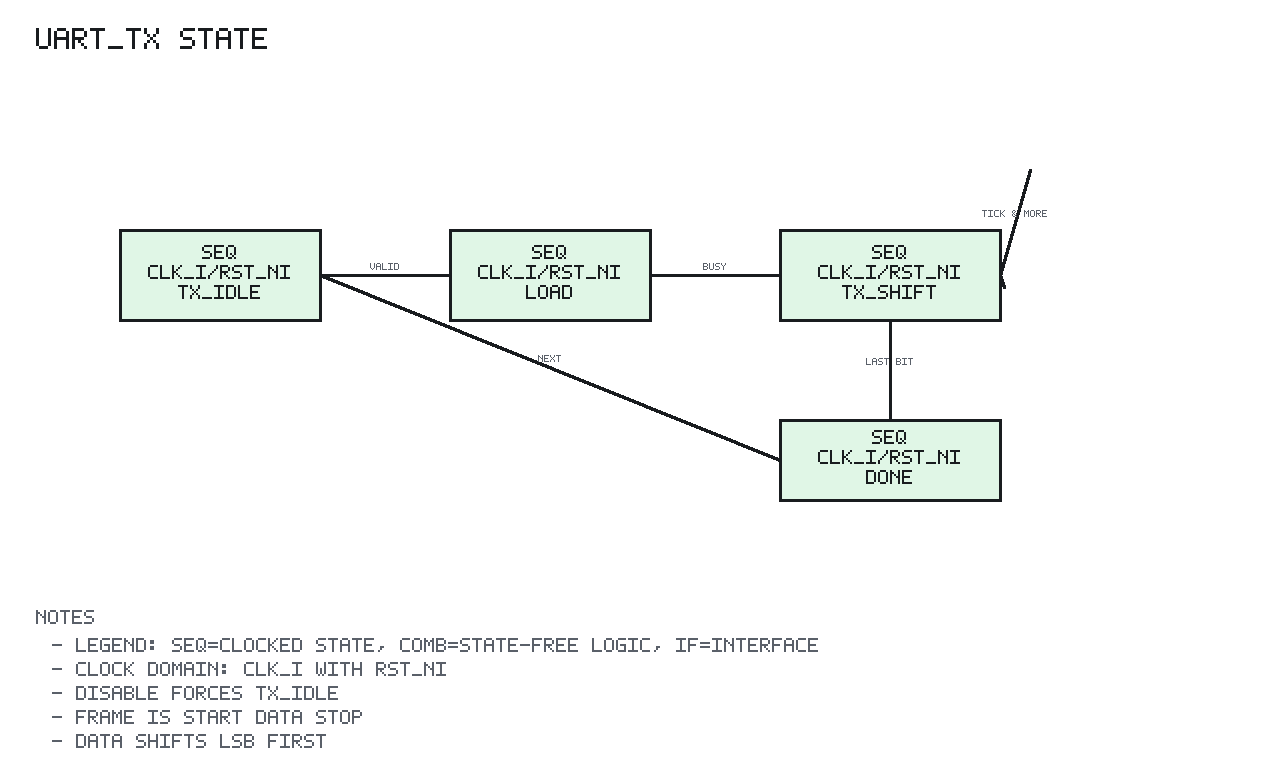
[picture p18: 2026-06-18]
uart/docs/images/uart_tx_state.png

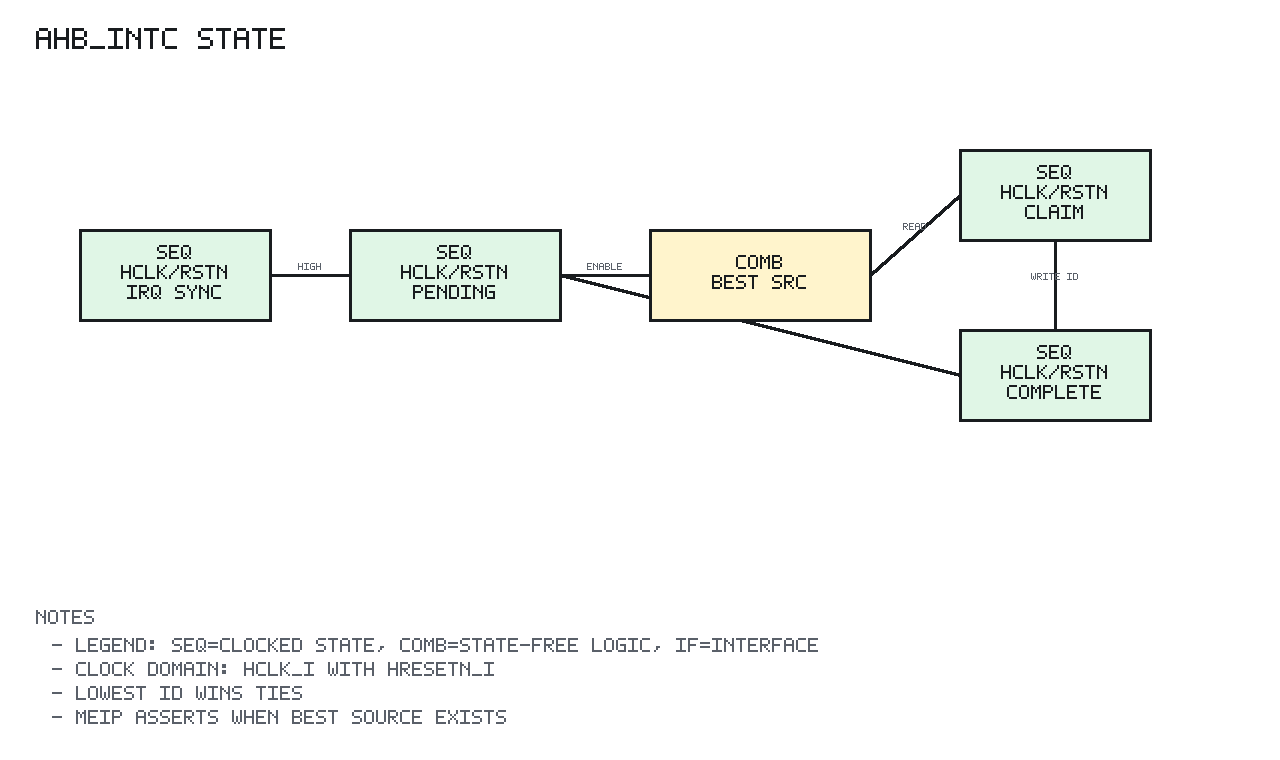
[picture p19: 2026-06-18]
intc/docs/images/ahb_intc_state.png

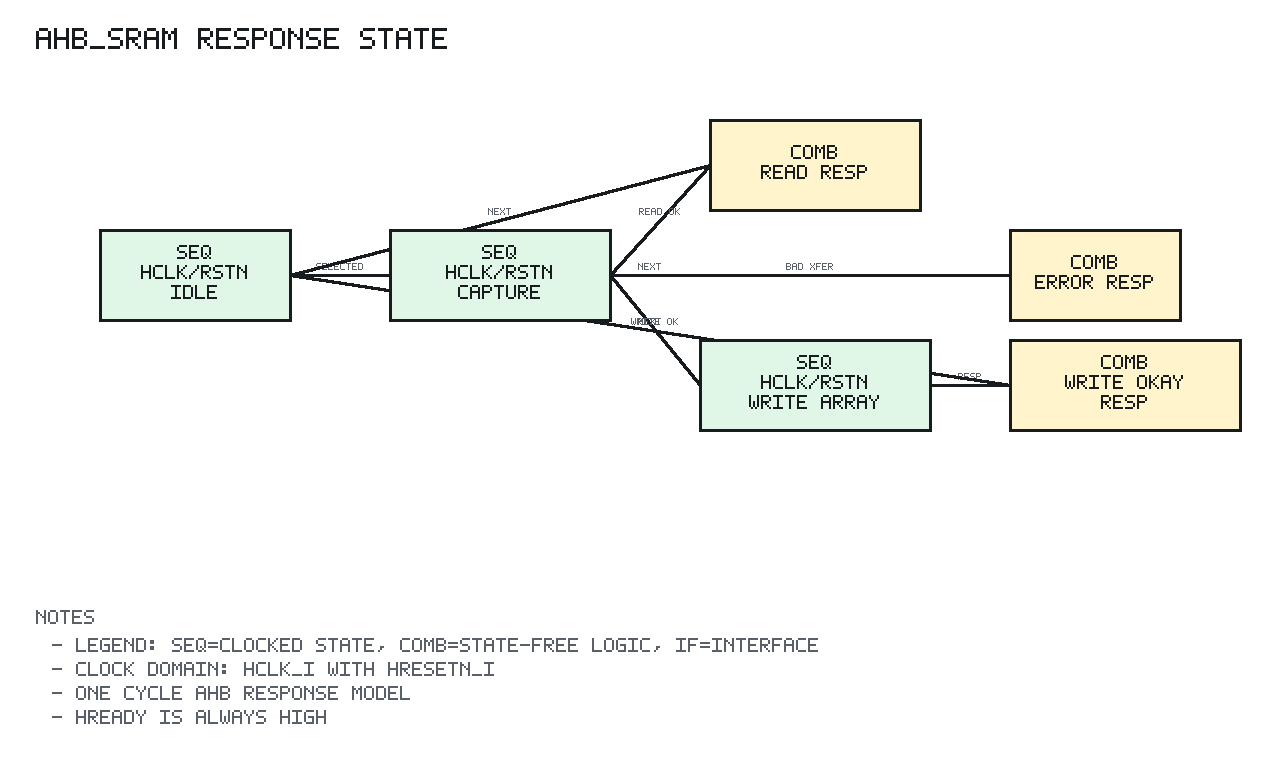
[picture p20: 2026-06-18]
sram/docs/images/ahb_sram_state.png

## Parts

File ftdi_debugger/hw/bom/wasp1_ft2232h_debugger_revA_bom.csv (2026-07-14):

refdes | quantity | population | function | manufacturer | manufacturer_part_number | approved_alternate | footprint | lifecycle_status | lifecycle_checked | source_url | notes
J1 | 1 | POP | USB 2.0 Type-C receptacle | GCT | USB4105-GF-A-120 | NONE | USB_C_Receptacle_GCT_USB4105-xx-A_16P_TopMnt_Horizontal | Active | 2026-07-14 | https://gct.co/connector/usb4105 | Top-mount 16-contact receptacle with 1.20 mm shell stakes; independently verify ordered suffix against drawing
F1 | 1 | POP | USB VBUS resettable fuse | Bourns | MF-MSMF050-2 | NONE | Fuse_1812_4532Metric | Selected - procurement recheck | 2026-07-14 | https://www.bourns.com/docs/product-datasheets/mf-msmf.pdf | 500 mA hold current
ESD1 | 1 | POP | USB D+/D- low-capacitance ESD array | STMicroelectronics | USBLC6-2SC6 | NONE | SOT-23-6 | Active volume production | 2026-07-14 | https://www.st.com/en/protections-and-emi-filters/usblc6-2.html | Place connector side toward J1
ESD2 | 1 | POP | JTAG reset and UART ESD array | Texas Instruments | TPD8E003DQDR | NONE | WSON-8-1EP_2x2mm_P0.5mm_EP0.9x1.6mm | Active | 2026-07-14 | https://www.ti.com/product/TPD8E003/part-details/TPD8E003DQDR | Eight protected target channels
U1 | 1 | POP | dual-channel USB bridge | FTDI | FT2232HL-REEL | FT2232HL-TRAY | LQFP-64_10x10mm_P0.5mm | Active | 2026-07-14 | https://ftdichip.com/products/ft2232hl/ | Channel A MPSSE JTAG and channel B UART
Y1 | 1 | POP | 12 MHz reference oscillator | ECS Inc. | ECS-3225MVQ-120-CN-TR | NONE | Oscillator_SMD_EuroQuartz_XO32-4Pin_3.2x2.5mm | Current product page | 2026-07-14 | https://ecsxtal.com/products/oscillators/surface-mount-oscillators/ecs-3225mvq-120-cn-tr/ | 3.3 V HCMOS plus or minus 25 ppm
U2 | 1 | DNP | optional FTDI configuration EEPROM | Microchip Technology | 93LC56BT-I/SN | NONE | SOIC-8_3.9x4.9mm_P1.27mm | In production | 2026-07-14 | https://www.microchip.com/en-us/product/93LC56B | Populate only for custom descriptors or serial-number policy
U3 | 1 | POP | VREF-valid open-drain comparator | Texas Instruments | TLV7041DBVR | NONE | SOT-23-5 | Active production | 2026-07-14 | https://www.ti.com/product/TLV7041/part-details/TLV7041DBVR | Nominal 1.57 V valid threshold
U4 | 1 | POP | debugger-to-target level translator | Texas Instruments | SN74AXC8T245PWR | NONE | TSSOP-24_4.4x7.8mm_P0.65mm | Active production | 2026-07-14 | https://www.ti.com/product/SN74AXC8T245 | OE gated by SHIFT_OE_N
U5 | 1 | POP | target-to-debugger level translator | Texas Instruments | SN74AXC2T245RSWR | NONE | Texas_RSW0010A_UQFN-10_1.4x1.8mm_P0.4mm | Active production | 2026-07-14 | https://www.ti.com/product/SN74AXC2T245/part-details/SN74AXC2T245RSWR | OE gated by SHIFT_OE_N
U6 | 1 | POP | USB-to-3.3 V regulator | Diodes Incorporated | AP2112K-3.3TRG1 | NONE | SOT-23-5 | Current product | 2026-07-14 | https://www.diodes.com/part/view/AP2112 | 600 mA SOT-25 LDO
U7 | 1 | POP | fail-safe enable NAND gate | Texas Instruments | SN74LVC1G00DBVR | NONE | SOT-23-5 | Active production | 2026-07-14 | https://www.ti.com/product/SN74LVC1G00/part-details/SN74LVC1G00DBVR | Generates SHIFT_OE_N from VREF_VALID and FT_TARGET_EN
J2 | 1 | POP | keyed 2x7 target IDC header | Samtec | TST-107-01-L-D | TST-107-01-G-D | IDC-Header_2x07_P2.54mm_Vertical | Active - primary had zero distributor stock at check | 2026-07-14 | https://www.samtec.com/products/tst-107-01-l-d | 2.54 mm vertical through-hole polarized header; alternate plating requires procurement approval
D1 | 1 | POP | USB power indicator green LED | Wurth Elektronik | 150060VS75000 | NONE | LED_0603_1608Metric | Active production | 2026-07-14 | https://www.we-online.com/en/components/products/WL-SMCW | 0603 bright green
D2 | 1 | POP | VREF-valid indicator amber LED | Wurth Elektronik | 150060AS75000 | NONE | LED_0603_1608Metric | Active production | 2026-07-14 | https://www.we-online.com/en/components/products/WL-SMCW | 0603 amber
Q1 | 1 | POP | VREF LED isolation NMOS | Diodes Incorporated | 2N7002-7-F | NONE | SOT-23 | Current product | 2026-07-14 | https://www.diodes.com/_files/datasheets/2N7002.pdf | Prevents LED loading of VREF_VALID
RLED1/RLED2 | 2 | POP | LED current limiting | Yageo | RC0402FR-072K2L | NONE | R_0402_1005Metric | Selected - procurement recheck | 2026-07-14 | https://www.yageo.com/en/ProductSearch/PartNumberSearch | 2.2 kOhm 1 percent 0402
RCC1/RCC2 | 2 | POP | USB-C device-role pulldown | Yageo | RC0402FR-075K1L | NONE | R_0402_1005Metric | Selected - procurement recheck | 2026-07-14 | https://www.yageo.com/en/ProductSearch/PartNumberSearch | 5.1 kOhm 1 percent 0402
RTCK/RTMS/RTDI/RTRST/RSRST/RURX | 6 | POP | target-output series damping | Yageo | RC0402FR-0733RL | NONE | R_0402_1005Metric | Selected - procurement recheck | 2026-07-14 | https://www.yageo.com/en/ProductSearch/PartNumberSearch | 33 Ohm 1 percent 0402
RTARGET_EN/ROE/RREF_BOT | 3 | POP | fail-safe bias and VREF divider | Yageo | RC0402FR-07100KL | NONE | R_0402_1005Metric | Selected - procurement recheck | 2026-07-14 | https://www.yageo.com/en/ProductSearch/PartNumberSearch | 100 kOhm 1 percent 0402
RREF_TOP | 1 | POP | VREF threshold divider high side | Yageo | RC0402FR-07110KL | NONE | R_0402_1005Metric | Selected - procurement recheck | 2026-07-14 | https://www.yageo.com/en/ProductSearch/PartNumberSearch | 110 kOhm 1 percent 0402
RVALID/RRESET/REECS/RU4_A7/RU4_A8 | 5 | POP | pullups and unused-input bias | Yageo | RC0402FR-0710KL | NONE | R_0402_1005Metric | Selected - procurement recheck | 2026-07-14 | https://www.yageo.com/en/ProductSearch/PartNumberSearch | 10 kOhm 1 percent 0402
RREF | 1 | POP | FTDI reference resistor | Yageo | RC0402FR-0712KL | NONE | R_0402_1005Metric | Selected - procurement recheck | 2026-07-14 | https://www.yageo.com/en/ProductSearch/PartNumberSearch | 12 kOhm 1 percent 0402
CCORE | 1 | POP | VCORE regulator filter | Murata | GRM188R61A335KE15D | NONE | C_0603_1608Metric | Current series - procurement recheck | 2026-07-14 | https://www.murata.com/en-us/products/productdetail?partno=GRM188R61A335KE15%23 | 3.3 uF 10 V X5R 0603; meets FTDI minimum filter capacitance
CDEC1-CDEC10 | 10 | POP | local rail decoupling | Murata | GRM155R71C104KA88D | NONE | C_0402_1005Metric | Current series - procurement recheck | 2026-07-14 | https://www.murata.com/en-global/api/pdfdownloadapi?cate=luCeramicCapacitorsSMD&partno=GRM155R71C104KA88%23 | 100 nF 16 V X7R 0402
CBULK1/CBULK2 | 2 | POP | USB and 3.3 V bulk decoupling | TDK | C2012X7R1A475K125AC | NONE | C_0805_2012Metric | Production | 2026-07-14 | https://product.tdk.com/en/search/capacitor/ceramic/mlcc/info?part_no=C2012X7R1A475K125AC | 4.7 uF 10 V X7R 0805
TP1-TP8 | 8 | PCB_ONLY | exposed copper test pads | PCB fabrication | N/A | N/A | TestPoint_Pad_D1.0mm | PCB_ONLY | 2026-07-14 | N/A | No physical component; excluded from procurement BOM and position output

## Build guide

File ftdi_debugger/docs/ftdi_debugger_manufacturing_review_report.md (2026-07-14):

# FT2232H Debugger Rev A Manufacturing Review Report

## Result

The Rev A engineering manufacturing package passes local automated and visual
review. Fabrication release remains **HOLD - DO NOT ORDER** pending fabricator
impedance sign-off, independent human CAM review, and procurement availability
confirmation.

This distinction matters: DRC proves consistency with the present design
rules, but it cannot choose a board shop's dielectric materials, inspect a CAM
view with independent human judgment, or guarantee current component stock.

## Review Sequence

| Sequence | Action | Expected | Observed |
| --- | --- | --- | --- |
| 1 | Run final KiCad DRC and schematic parity | No routing, clearance, or parity failures | PASS: 0 errors, 0 unconnected pads, 0 parity errors; 2 reviewed local-footprint warnings |
| 2 | Read the committed PCB with KiCad `pcbnew` | Frozen outline, stack, J1/J2 geometry, test-pad attributes, and USB routing | PASS: 110 mm x 65 mm, 1.6 mm, J1/J2 exact geometry, TP1-TP8 PCB-only |
| 3 | Parse Gerber X2 independently of the board source | Nine correctly identified layers in one coordinate system | PASS: expected functions/polarities and all coordinates within the profile |
| 4 | Reconstruct the Edge.Cuts graph | One closed manufacturable outline | PASS: four vertices, four edges, 350 mm perimeter |
| 5 | Parse Excellon tools, hits, and routed slots | Drill inventory agrees with board statistics and connector geometry | PASS: 86 round PTH, 4 plated slots, 2 NPTH |
| 6 | Audit pick-and-place records | Only physical fitted parts are emitted | PASS: corrected from 56 to 48 rows by excluding PCB-only TP1-TP8 |
| 7 | Cross-check production BOM against all board footprints | Exact MPN, package, population, source, and lifecycle-review date per reference | PASS: 48 POP, 1 DNP, 8 PCB_ONLY |
| 8 | Rasterize top and bottom assembly PDFs | No clipping, overlap, or unintended bottom-side population | PASS |

## Findings Resolved

### PCB-only test pads in placement output

TP1-TP8 use `TestPoint_Pad_D1.0mm`, which is an exposed copper pad rather than
a purchased component. The board generator had overridden the footprint
library's BOM/position exclusions, causing eight false placement rows. The
override was removed, the committed PCB and schematic were corrected, and the
manufacturing audit now requires exactly 48 fitted rows.

### Board-thickness reporting

The source-board finished thickness and copper-plus-dielectric stack both equal
1.6 mm. KiCad statistics report 1.6200 mm because the modeled 0.01 mm solder
mask on each side is included. Fabrication notes now state the distinction so
1.62 mm is not ordered as the substrate thickness.

### VCORE capacitor specification

The earlier descriptive BOM called CCORE 3.3 uF X7R in 0603. The production
selection is now Murata `GRM188R61A335KE15D`, 3.3 uF, 10 V, X5R, 0603. This
matches the board footprint and FTDI's minimum 3.3 uF VCORE filter requirement.

### Connector order codes

J1 is fixed to GCT `USB4105-GF-A-120`. J2 is fixed to Samtec
`TST-107-01-L-D`, with `TST-107-01-G-D` listed only as a procurement-controlled
candidate. Automated geometry checks freeze J1's USB pad order, shell slots,
and locating holes and J2's 2.54 mm pin grid and drill size.

## Remaining Holds

1. The board shop must calculate and sign the 90 ohm USB differential geometry
   for its actual four-layer materials and copper process.
2. A second person must inspect the Gerber/drill package in a CAM viewer.
3. Procurement must recheck exact suffixes, MOQ, stock, lifecycle, and approved
   alternates immediately before order placement.
4. First-article assembly and physical OpenOCD/GDB/UART bring-up remain
   hardware-only evidence.

The controlled gate and signature table are in
`hw/fabrication/wasp1_ft2232h_debugger_revA_release_checklist.md`.

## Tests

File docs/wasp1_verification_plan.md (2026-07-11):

# wasp1 Verification Plan

## 1. Verification Goals

Verification is module-first and integration-second. Each first-level module is
verified in isolation before it is integrated into the SoC.

The goal is high functional coverage through directed tests, protocol checks,
randomized stimulus where useful, and end-to-end software tests.

## 2. Per-Module Deliverables

Each hardware module should provide:

| Deliverable | Location |
| --- | --- |
| Design spec | `module/docs/` |
| Verification plan | `module/docs/` |
| Testbench | `module/tb/` |
| Verification helpers | `module/dv/` |
| Source filelist | `module/filelists/` |
| Build output | `module/build/` |
| Logs | `module/logs/` |
| Waveforms | `module/wave/` |

## 3. Required Verification Case Table Format

Each verification document must include a table like this:

| Time | Action | Expected result | Observed result |
| --- | --- | --- | --- |
| 0ns-20ns | Apply reset | All state reaches reset value | TBD |
| 20ns-60ns | Drive first transaction | DUT accepts request | TBD |
| 60ns-100ns | Check response | Response matches expected value | TBD |

Default simulation timebase:

```text
`timescale 1ns/1ps
clock period = 10ns
clock frequency = 100MHz
```

Pure combinational modules may be checked without a DUT clock, but the
verification document should state that explicitly. When practical, combinational
testbenches should still group checks into 10ns verification steps so reports
remain consistent with clocked modules.

## 4. Protocol Checks

AHB-Lite modules require checks for:

```text
valid address phase behavior
stable control while stalled
correct HREADY handling
correct HRESP generation
aligned transfer behavior
byte lane write behavior
default slave error behavior
```

Internal request-response interfaces require checks for:

```text
valid/ready stability
no response without request
no dropped request under backpressure
correct response ordering
```

## 5. System Tests

Full SoC simulations should include:

```text
reset from OTP
UART hello program
timer interrupt
GPIO interrupt
DMA memory copy
OTP programming routine running from I-SRAM
I-cache refill from OTP
D-cache load/store to D-SRAM
OpenOCD/GDB debug attach, breakpoint, and load/store watchpoint tests
```

## 6. Coverage Intent

Initial coverage is functional coverage documented in the verification plan.
When the simulator supports it, SystemVerilog covergroups and assertions should
be added for protocol and state machine coverage.

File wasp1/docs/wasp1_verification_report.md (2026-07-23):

# wasp1 Verification Report

## 1. Commands

```text
make -C wasp1 lint
make -C wasp1 lint-ic
make -C wasp1 lint-fpga-v7
make -C wasp1 sim
make -C wasp1 sim-sw
make -C wasp1 sim-long-boot
make -C wasp1 sim-mixed-irq-dma
make -C wasp1 sim-system-stress
make -C wasp1 sim-random-irq-stress
make -C wasp1 sim-random-irq-multiseed
make -C wasp1 random-irq-runner-test
make -C wasp1 sim-random-irq-nightly
make -C wasp1 sim-otp-program
make -C wasp1 sim-dma-copy
make -C wasp1 sim-uart-irq
make -C wasp1 sim-uart-rx-irq
make -C wasp1 sim-dma-irq
make -C wasp1 sim-gpio-irq
make -C wasp1 sim-timer-irq
make -C wasp1 sim-rbb-smoke
make -C wasp1 sim-openocd-gdb-smoke
make -C wasp1 sim-openocd-gdb-stress
make -C wasp1 sim-openocd-gdb-long-stress
make -C wasp1 sim-openocd-gdb-watchpoint
make -C wasp1 sim-cache-metrics
```

## 2. Results

| Check | Result |
| --- | --- |
| Generic lint | PASS |
| IC-target lint | PASS |
| Virtex-7-target lint | PASS |
| `tb_wasp1` simulation | PASS |
| `tb_wasp1` OTP firmware simulation | PASS |
| `tb_wasp1` long boot firmware simulation | PASS |
| `tb_wasp1` mixed IRQ/DMA firmware simulation | PASS |
| `tb_wasp1` system stress firmware simulation | PASS |
| `tb_wasp1` deterministic-random IRQ stress | PASS |
| Four-seed randomized IRQ campaign | PASS |
| Random IRQ campaign runner unit tests | PASS (5/5) |
| 32-seed nightly randomized IRQ campaign | PASS |
| Hosted GitHub Actions nightly campaign | PASS (run 4, 1m 10s) |
| `tb_wasp1` OTP programming firmware simulation | PASS |
| `tb_wasp1` DMA copy firmware simulation | PASS |
| `tb_wasp1` UART IRQ firmware simulation | PASS |
| `tb_wasp1` UART RX IRQ firmware simulation | PASS |
| `tb_wasp1` DMA IRQ firmware simulation | PASS |
| `tb_wasp1` GPIO IRQ firmware simulation | PASS |
| `tb_wasp1` timer IRQ firmware simulation | PASS |
| Remote-bitbang socket smoke | PASS |
| Automated OpenOCD/GDB process smoke | PASS |
| Automated OpenOCD/GDB stress | PASS |
| Automated OpenOCD/GDB long stress | PASS |
| Automated OpenOCD/GDB load/store watchpoints | PASS |
| Cache/runtime metrics sweep | PASS |

Simulation output:

```text
tb_wasp1 PASS pass_count=9 trap_valid=1 trap_cause=0x02 bus_grant_idx=0 dbg_running=1 dbg_halted=0 dbg_dmactive=1
tb_wasp1 loaded OTP image: ../llvm_s1/build/smoke/hello_uart_otp.hex
tb_wasp1 PASS pass_count=10 trap_valid=0 trap_cause=0x02 bus_grant_idx=0 dbg_running=1 dbg_halted=0 dbg_dmactive=1
tb_wasp1 loaded OTP image: ../llvm_s1/build/smoke/long_boot_otp.hex
tb_wasp1 PASS pass_count=10 trap_valid=0 trap_cause=0x02 bus_grant_idx=0 dbg_running=1 dbg_halted=0 dbg_dmactive=1
tb_wasp1 loaded OTP image: ../llvm_s1/build/smoke/mixed_irq_dma_otp.hex
tb_wasp1 PASS pass_count=10 trap_valid=0 trap_cause=0x02 bus_grant_idx=0 dbg_running=1 dbg_halted=0 dbg_dmactive=1
tb_wasp1 loaded OTP image: ../llvm_s1/build/smoke/system_stress_otp.hex
tb_wasp1 PASS pass_count=10 trap_valid=0 trap_cause=0x02 bus_grant_idx=0 dbg_running=1 dbg_halted=0 dbg_dmactive=1
tb_wasp1 loaded OTP image: ../llvm_s1/build/smoke/random_irq_stress_otp.hex
Random IRQ stress: seed=0x1a2b3c4d state=0xdc745d7e trace=0x00871448 events=13 timer=6 dma=5 gpio=2 event_sum=0x0000184a data_sum=0xa87c2adf PASS
tb_wasp1 PASS pass_count=10 trap_valid=0 trap_cause=0x02 bus_grant_idx=0 dbg_running=1 dbg_halted=0 dbg_dmactive=1
WASP1_RANDOM_IRQ_SEED seed=0x1a2b3c4d state=0xdc745d7e trace=0x00871448 events=13 timer=6 dma=5 gpio=2 PASS
WASP1_RANDOM_IRQ_SEED seed=0x12345678 state=0x4e0f25f8 trace=0x0007540d events=14 timer=7 dma=7 gpio=0 PASS
WASP1_RANDOM_IRQ_SEED seed=0xdeadbeef state=0xf9327ce4 trace=0x0026cccb events=16 timer=8 dma=5 gpio=3 PASS
WASP1_RANDOM_IRQ_SEED seed=0x0f1e2d3c state=0x037695f6 trace=0x00af40a8 events=14 timer=6 dma=3 gpio=5 PASS
WASP1_RANDOM_IRQ_CAMPAIGN seeds=4 rounds=48 events=57 timer=27 dma=20 gpio=10 selectors=18/11/10/9 PASS
WASP1_RANDOM_IRQ_MULTI_SEED seeds=4 PASS
WASP1_RANDOM_IRQ_CAMPAIGN seeds=32 rounds=384 events=478 timer=183 dma=197 gpio=98 selectors=89/103/98/94 PASS
WASP1_RANDOM_IRQ_MULTI_SEED seeds=32 PASS
GITHUB_ACTIONS_RUN 29994889463 result=PASS artifact_sha256=725f891a02566a05c3d0c5bd4a81761942c46bc4082fd368297b1127fb4e923f
tb_wasp1 loaded OTP image: ../llvm_s1/build/smoke/otp_program_otp.hex
tb_wasp1 PASS pass_count=10 trap_valid=0 trap_cause=0x02 bus_grant_idx=0 dbg_running=1 dbg_halted=0 dbg_dmactive=1
tb_wasp1 loaded OTP image: ../llvm_s1/build/smoke/dma_copy_otp.hex
tb_wasp1 PASS pass_count=10 trap_valid=0 trap_cause=0x02 bus_grant_idx=0 dbg_running=1 dbg_halted=0 dbg_dmactive=1
tb_wasp1 loaded OTP image: ../llvm_s1/build/smoke/uart_irq_otp.hex
tb_wasp1 PASS pass_count=10 trap_valid=0 trap_cause=0x02 bus_grant_idx=0 dbg_running=1 dbg_halted=0 dbg_dmactive=1
tb_wasp1 loaded OTP image: ../llvm_s1/build/smoke/uart_rx_irq_otp.hex
tb_wasp1 PASS pass_count=10 trap_valid=0 trap_cause=0x02 bus_grant_idx=0 dbg_running=1 dbg_halted=0 dbg_dmactive=1
tb_wasp1 loaded OTP image: ../llvm_s1/build/smoke/dma_irq_otp.hex
tb_wasp1 PASS pass_count=10 trap_valid=0 trap_cause=0x02 bus_grant_idx=0 dbg_running=1 dbg_halted=0 dbg_dmactive=1
tb_wasp1 loaded OTP image: ../llvm_s1/build/smoke/gpio_irq_otp.hex
tb_wasp1 PASS pass_count=10 trap_valid=0 trap_cause=0x02 bus_grant_idx=0 dbg_running=1 dbg_halted=0 dbg_dmactive=1
tb_wasp1 loaded OTP image: ../llvm_s1/build/smoke/timer_irq_otp.hex
tb_wasp1 PASS pass_count=10 trap_valid=0 trap_cause=0x02 bus_grant_idx=0 dbg_running=1 dbg_halted=0 dbg_dmactive=1
wasp1_rbb_smoke PASS
OpenOCD: hart 0: XLEN=32, misa=0x40000100
OpenOCD: datacount=2 progbufsize=4
OpenOCD: [wasp1.cpu] Found 2 triggers
GDB: registers read, PC visible, stepi PASS, hbreak PASS, detach PASS
wasp1_openocd_gdb_smoke PASS
GDB stress: register write/read PASS, stepi PASS, hbreak 0x0 PASS, hbreak 0x4 PASS
wasp1_openocd_gdb_stress PASS
GDB long stress: multi-register PASS, stepi PASS, dual-resident hbreak PASS, post-reset GPR PASS
wasp1_openocd_gdb_long_stress PASS
GDB watchpoints: rwatch observed memory=0, watch observed old=0/new=0x55, detach PASS
wasp1_openocd_gdb_watchpoint PASS
WASP1_CACHE_METRICS_ROW label=system_stress cycles=73727 retired=9027 ipc=0.122 cpi=8.167 ic_hit_pct=87.2 dc_hit_pct=92.7
WASP1_CACHE_METRICS_ROW label=random_irq_stress cycles=111920 retired=9999 ipc=0.089 cpi=11.193 ic_hit_pct=77.9 dc_hit_pct=91.4
```

## 3. Time-Sequenced Case Table

| Time | Action | Expected result | Observed result |
| --- | --- | --- | --- |
| 0ns-40ns | Hold reset active for four 10ns cycles | Integrated state resets; IO defaults are benign | PASS |
| 41ns | Check reset outputs | UART TX idle high, I2C drive enables low, GPIO output/enables zero, WDG reset low | PASS |
| 45ns-55ns | Release reset and allow one clock | SoC exits reset without unknown top-level control behavior | PASS |
| 55ns-95ns | Wait for core AHB master transfer | Core-side bridge/fabric path observes valid transfer | PASS |
| 95ns-105ns | Wait for debug status | Core debug status reports running or halted | PASS |
| 105ns-3us | Bit-bang JTAG IDCODE, DTMCS, `dmcontrol.dmactive`, and `dmstatus` | JTAG pins reach integrated Debug Module; `dbg_dmactive_o=1` | PASS |
| Remote-bitbang run | Launch `Vwasp1` socket harness and connect Python remote-bitbang client | TCP JTAG path returns IDCODE/DTMCS and DMI `dmstatus` success | PASS |
| OpenOCD/GDB process run | Launch `Vwasp1 +rbb-keepalive +WASP1_OTP_HEX`, start OpenOCD remote_bitbang, and run `riscv64-elf-gdb` script | TAP IDCODE, DTM, hart XLEN/misa discovery, `datacount=2`, `progbufsize=4`, two triggers discovered, GDB reset-halt, register reads, PC read, native `stepi`, hardware breakpoint at `0x4`, and detach all complete without OpenOCD/GDB errors | PASS |
| OpenOCD/GDB stress run | Reuse the remote-bitbang process harness with `wasp1_debug_stress.gdb` | GDB writes/reads `t0=0x12345678`, single-steps from `0x4` to `0x0`, deletes/reinstalls breakpoints, and hits hardware breakpoints at `0x0` and `0x4` | PASS |
| OpenOCD/GDB long-stress run | Reuse the remote-bitbang process harness with `wasp1_debug_long_stress.gdb` | GDB writes/reads `t0/t1/t2`, single-steps from `0x4` to `0x0`, installs breakpoints at `0x0` and `0x4` simultaneously, continues through six alternating hits, reset-halts, writes/reads `s0`, and detaches | PASS |
| OpenOCD/GDB watchpoint phase 1 | Load the register-gated watchpoint OTP image, halt at PC `0x0`, clear D-SRAM base through Access Memory, write `t0=0x20000000`, install `rwatch`, and continue | GDB reports the read watchpoint while the target word is still zero; raw trigger or GDB step-normalized DCSR cause is accepted | PASS |
| OpenOCD/GDB watchpoint phase 2 | Remove `rwatch`, reach the store, install `watch`, and continue | GDB reports `Old value=0`, `New value=85`; D-SRAM reads back `0x00000055`, the watchpoint is deleted, and GDB detaches cleanly | PASS |
| Cache metrics sweep | Build `tb_wasp1` once and run each generated C OTP image with `+WASP1_METRICS` | `logs/cache_metrics.csv` and `logs/cache_metrics.md` contain one metrics row per firmware image with cycles, retired count, IPC/CPI, and I/D cache hit rates | PASS |
| 3us-3.2us | Continue idle peripheral window | WDG reset remains low; I2C drive enables remain low | PASS |
| 105ns-16.705us | Software-loaded run waits for UART TX FIFO push | OTP firmware fetches from OTP, initializes UART, and writes first byte while JTAG smoke is also checked | PASS |
| 16.705us-17us | Software smoke completion window | UART activity observed and no top-level fatal trap is reported | PASS |
| 105ns-260us | Long boot firmware run | CPU executes one generated OTP image that performs UART output, GPIO output/toggle, D-SRAM pattern stores/reads, polled DMA copy of eight words, polled timer compare, and executable OTP readback; testbench checks completion mailboxes and hardware side effects | PASS |
| 105ns-166us | Mixed IRQ/DMA firmware run | CPU enables DMA IRQ ID 5 and GPIO IRQ ID 4 together, starts DMA, testbench drives GPIO[0] high after firmware ready, INTC claims DMA before GPIO by priority, handler clears both sources, and testbench checks copied D-SRAM data plus final IRQ deassertion | PASS |
| 105ns-737us | System stress firmware run | CPU runs six polling rounds of D-SRAM seed/readback, DMA copy of eight words, timer compare polling, GPIO writes/toggles, UART TX pushes, and executable OTP readback; testbench checks checksum, final DMA buffers, GPIO value, status accumulators, and final deasserted IRQ state | PASS |
| 105ns-1ms | Deterministic-random IRQ stress | Fixed seed `0x1a2b3c4d` selects 12 timer, DMA, GPIO, or concurrent timer+DMA rounds; testbench performs two GPIO request/ack handshakes and independently checks selector trace `0x00871448`, 13 events (timer 6, DMA 5, GPIO 2), event checksum `0x0000184a`, DMA checksum `0xa87c2adf`, UART progress, and final IRQ deassertion | PASS |
| Four independent runs, about 0-1.2ms each | Multi-seed randomized IRQ campaign | Testbench holds each nonzero seed on GPIO through reset, waits for firmware seed capture, then runs four independent 12-round scoreboards; combined coverage is 48 rounds and 57 interrupt events, including a zero-GPIO schedule and timer+DMA concurrent rounds for every seed | PASS |
| 32 independent runs, about 0-1.2ms each | Nightly randomized IRQ campaign | Runner derives non-overlapping 12-round windows from root `0xc001d00d`; each run cold-boots the same OTP image, captures its GPIO seed, and executes the full independent scoreboard. Aggregate result is 384 distinct rounds, 478 events (timer 183, DMA 197, GPIO 98), and selector counts 89/103/98/94 | PASS |
| 105ns-33us | OTP programming firmware run | Startup copies `.fasttext` to I-SRAM; CPU executes the programming routine from I-SRAM and programs OTP word `0x00003fa0` to `0x13572468` with `done=1` and `error=0` | PASS |
| 105ns-21us | DMA copy firmware run | CPU seeds D-SRAM source words at `0x20003000`, starts DMA to copy four words to `0x20003040`, and the testbench observes matching destination words with `done=1`, `error=0`, and `irq=1` | PASS |
| 105ns-75us | UART IRQ firmware run | CPU enables UART TX-empty IRQ ID 2 in INTC, services one machine external interrupt, claims/completes IRQ 2, clears UART sticky TX-empty status, disables UART TX IRQ enable, and returns to idle | PASS |
| 105ns-148us | UART RX IRQ firmware run | CPU arms UART RX-available IRQ ID 2, testbench drives one external UART RX byte, C trap handler reads UART DATA and clears RX-available; firmware then arms overrun-only IRQ, testbench drives multiple serial frames, and handler clears sticky RX-overrun with UART/INTC IRQs deasserted | PASS |
| 105ns-83us | DMA IRQ firmware run | CPU enables DMA IRQ ID 5 in INTC, starts DMA, services one machine external interrupt, claims/completes IRQ 5, clears the DMA IRQ source, and returns to idle with copied D-SRAM destination words | PASS |
| 105ns-87us | GPIO IRQ firmware run | CPU configures GPIO bit 0 as level-high source, enables GPIO IRQ ID 4 in INTC, testbench drives `gpio_in[0]` high, C trap handler claims/completes IRQ 4, clears GPIO sticky status, and returns to idle | PASS |
| 105ns-50us | Timer IRQ firmware run | CPU programs `mtime/mtimecmp`, enables MTIE/MIE, services one machine timer interrupt, writes trap mailbox values in D-SRAM, disables timer IRQ, and returns to idle | PASS |

## 4. Residual Risk

This is an integration smoke test, not a full system software test. The
OpenOCD/GDB process path is now automated and verified for connect, halt,
register read, PC read, PC disassembly through Access Memory, native GDB
`stepi` with PC-change assertion, an execute-address hardware breakpoint
through `hbreak`, and detach over remote-bitbang JTAG. GDB stress targets now
also cover GPR write/read, hardware breakpoint delete/reinstall, two hardware
breakpoint hits at separate OTP addresses, simultaneous two-breakpoint
residency, repeated alternating hits, and post-reset GPR access.
The dedicated watchpoint regression now covers OpenOCD/GDB `rwatch` and
`watch` commands against D-SRAM, including a clean pre-access gate, load/store
trigger installation, read-before-write ordering, and the observed zero-to-85
memory transition. GDB may hide the raw timing-before stop by single-stepping;
the core datapath report separately proves that the raw matched access issues
no request or architectural side effect before Debug Mode entry.
The CPU-controlled OTP programming
register flow is now covered by a directed firmware smoke test. End-to-end DMA
memory-copy through real D-SRAM contents is also covered by generated firmware.
The long boot firmware image now combines UART, GPIO, D-SRAM, DMA, timer, and
OTP readback activity in one generated-image run.
The system stress firmware image repeats D-SRAM, DMA, timer, GPIO, UART, and
OTP-read activity over six polling rounds and checks accumulated status and
checksum mailboxes at the top level.
The deterministic-random IRQ image now captures a GPIO seed and covers 12
timer, DMA, GPIO, and concurrent timer+DMA choices per run. Its independent
testbench scoreboard checks the complete PRNG trace, per-source counts,
order-independent event and DMA-data checksums, GPIO request/ack handshakes,
and final IRQ state. The standard four-seed campaign reuses one OTP image for
48 rounds and 57 interrupt events while retaining one failure log per seed.
The scheduled 32-seed campaign spaces seed starts so all 384 firmware-round
PRNG states are distinct. Its first recorded run completed 478 interrupt events
with every operation selector covered, and emitted deterministic JSON,
Markdown, and per-seed logs for CI review.
The cache metrics sweep now records current I-cache/D-cache hit rates and
cycles/retired/IPC/CPI for all generated C firmware images.
The mixed IRQ/DMA firmware image now combines DMA master activity with two INTC
external sources and verifies DMA-before-GPIO priority order in software.
The UART TX-empty, UART RX-available/RX-overrun, DMA, and GPIO external
interrupt paths are covered through INTC claim/complete and MEIP. Program
Buffer postexec is covered from DMI storage and abstract-command dispatch
through real halted-core instruction execution, including backpressure and
executor error mapping. The machine
timer interrupt path is covered by a generated firmware image that returns
through the C trap handler. Remaining top-level work includes optional SBA
flows, still-longer multi-hour soak campaigns, and physical FPGA/FTDI testing.

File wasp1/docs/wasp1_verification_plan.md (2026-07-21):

# wasp1 Verification Plan

## 1. Scope

The top-level verification target is `wasp1`. Module-level functional coverage
remains owned by each lower-level module; this plan focuses on integration
elaboration, reset connectivity, and first fetch-path activity.

## 2. Test Items

| Item | Goal | Method |
| --- | --- | --- |
| Generic lint | Check full SoC elaboration | Run Verilator lint on 63 integrated modules. |
| IC target lint | Check IC macro path | Run lint with `WASP1_TARGET_IC`. |
| Virtex-7 lint | Check FPGA macro path | Run lint with `WASP1_TARGET_FPGA_XILINX_VIRTEX7`. |
| Reset defaults | Check benign IO after reset | Hold reset for four 10ns cycles and inspect UART/I2C/GPIO/WDG outputs. |
| Fetch-path activity | Check tile -> bridge -> fabric path | Wait for the core AHB master to issue a valid transfer after reset. |
| OTP firmware smoke | Check generated `llvm_s1` image can execute from OTP | Load `hello_uart_otp.hex`, wait for firmware to push the first UART TX byte. |
| Long boot firmware smoke | Check longer generated-image mixed peripheral path | Load `long_boot_otp.hex`, run UART output, GPIO writes/toggle, D-SRAM stores/loads, polled DMA copy, polled timer compare, and OTP readback, then check D-SRAM mailboxes and hardware side effects. |
| Mixed IRQ/DMA firmware smoke | Check multi-source INTC handling with DMA active | Load `mixed_irq_dma_otp.hex`, start a DMA copy with IRQ enabled while GPIO level IRQ is armed, drive `gpio_in[0]`, require DMA priority/claim before GPIO, and check copied D-SRAM data plus final IRQ deassertion. |
| System stress firmware smoke | Check repeated software-driven peripheral and memory activity | Load `system_stress_otp.hex`, run six polling rounds of D-SRAM seed/readback, DMA copy, timer compare, GPIO output updates, UART TX pushes, and OTP readback, then check D-SRAM mailboxes and final hardware state. |
| Deterministic-random IRQ stress | Check repeatable interrupt-heavy event interleaving | Load `random_irq_stress_otp.hex`, capture a nonzero GPIO seed, use xorshift32 to select 12 timer, DMA, GPIO, or concurrent timer+DMA rounds, respond to firmware GPIO epochs from the testbench, and independently check event counts, checksums, DMA data, selector trace, and final IRQ deassertion. |
| Multi-seed IRQ campaign | Broaden randomized schedule coverage without rebuilding firmware | Drive four nonzero seeds through GPIO during reset, require the seed-capture mailbox before GPIO IRQ stimulus, run 48 total rounds from one OTP image, preserve one log per seed, and require every independent scoreboard to pass. |
| Nightly random IRQ campaign | Exercise longer interrupt schedules with reproducible non-overlapping windows | Derive 32 seeds from root `0xc001d00d`, separate seed starts by 13 xorshift32 states, run 384 distinct rounds across independent cold boots, require all four selectors in aggregate, and archive JSON, Markdown, and per-seed logs in CI. |
| OTP programming firmware smoke | Check CPU-controlled OTP programming flow | Load `otp_program_otp.hex`, copy `.fasttext` to I-SRAM, execute the OTP programming routine from I-SRAM, and check the programmed OTP word plus status bits. |
| DMA copy firmware smoke | Check DMA moves real D-SRAM contents | Load `dma_copy_otp.hex`, let CPU seed D-SRAM source/destination windows, start DMA, and check the destination words plus DMA done/error/IRQ status. |
| UART IRQ firmware smoke | Check UART external interrupt through INTC | Load `uart_irq_otp.hex`, enable UART TX-empty IRQ ID 2 in INTC, claim/complete MEIP in the C trap handler, clear the sticky UART IRQ source, and check D-SRAM mailboxes plus IRQ deassertion. |
| UART RX IRQ firmware smoke | Check UART RX-available and RX-overrun through INTC | Load `uart_rx_irq_otp.hex`, wait for firmware ready mailboxes, drive external UART RX frames from the testbench, handle RX-available and RX-overrun IRQ ID 2 in the C trap handler, and check mailboxes plus IRQ deassertion. |
| DMA IRQ firmware smoke | Check INTC machine external interrupt path | Load `dma_irq_otp.hex`, enable DMA IRQ ID 5 in INTC, start DMA, claim/complete MEIP in the C trap handler, and check D-SRAM mailboxes plus IRQ deassertion. |
| GPIO IRQ firmware smoke | Check external GPIO interrupt through INTC | Load `gpio_irq_otp.hex`, arm GPIO bit 0 as a level-high interrupt, drive `gpio_in[0]`, claim/complete GPIO IRQ ID 4 in the C trap handler, and check D-SRAM mailboxes plus IRQ deassertion. |
| Timer IRQ firmware smoke | Check machine timer interrupt entry/return | Load `timer_irq_otp.hex`, program `mtime/mtimecmp`, enable MTIE/MIE, wait for D-SRAM trap mailboxes, and check timer IRQ deassertion. |
| Debug status | Check core debug status is driven | Wait for either running or halted status to become asserted. |
| JTAG debug smoke | Check SoC-level Debug Module access | Bit-bang JTAG to read IDCODE/DTMCS, write `dmcontrol.dmactive`, and read `dmstatus`. |
| Remote-bitbang smoke | Check OpenOCD-facing socket bridge | Build `Vwasp1` remote-bitbang harness and use a Python client to exercise IDCODE/DTMCS/DMI over TCP. |
| OpenOCD smoke | Check external debugger server compatibility | Run OpenOCD remote_bitbang against `Vwasp1` and require TAP, DTM, hart, XLEN, and `misa` discovery. |
| GDB smoke | Check external GDB debug access | Connect `riscv64-elf-gdb` through OpenOCD, reset-halt, read GPRs/PC, execute native `stepi`, hit an execute-address hardware breakpoint, detach, and exit. |
| GDB stress | Check repeated external debugger operations | Reuse the OpenOCD/GDB harness to write/read a GPR, single-step the OTP loop, delete/reinstall hardware triggers, and hit two hardware breakpoints at `0x0` and `0x4`. |
| GDB long stress | Check longer debugger stability with both triggers resident | Reuse the OpenOCD/GDB harness to write/read multiple GPRs, single-step the OTP loop, keep two hardware breakpoints installed simultaneously, continue through six breakpoint hits, reset-halt, and recheck GPR access. |
| GDB data watchpoints | Check external load/store trigger workflows | Run a register-gated OTP load/store loop, arm GDB `rwatch` and `watch` at D-SRAM base, require both stops, verify read-watchpoint memory remains zero before the store, and verify the write changes the word from zero to `0x55`. |
| Cache/runtime metrics | Measure cache hit rate and execution efficiency | Run all generated OTP C firmware images with `+WASP1_METRICS` and summarize cycles, retired instructions, IPC/CPI, and I/D cache hit rates. |
| Idle peripheral stability | Check inactive peripherals stay benign | Run additional cycles and ensure WDG reset and I2C OE remain deasserted. |

## 3. Coverage Intent

The smoke test intentionally does not duplicate module-level register and data
coverage. It verifies that the full SoC hierarchy elaborates, that reset-time
CPU traffic can traverse the integrated memory path, and that a generated
stage-1 OTP image reaches the UART MMIO path, that a CPU-controlled OTP
programming routine can run from I-SRAM and update the OTP model through its
register interface, that a longer generated OTP image can combine UART, GPIO,
D-SRAM, DMA, timer, and OTP reads in one boot, that a generated system stress
image can repeat D-SRAM, DMA, timer, GPIO, UART, and OTP-read activity for
multiple rounds, that a mixed generated OTP image can handle DMA and GPIO
external interrupt sources in one run while preserving priority order, that a
seeded randomized image can repeatedly interleave machine-timer and INTC
DMA/GPIO interrupts, including concurrent timer+DMA rounds, while the
testbench independently reconstructs the complete event schedule, that the
same OTP image can repeat this check across four captured GPIO seeds, that a
scheduled nightly run can extend this to 32 independent boots and 384 distinct
PRNG schedule states with aggregate selector/source coverage, that a
DMA firmware image can move real D-SRAM contents through the second AHB master
path, that DMA completion can reach the core as a
machine external interrupt through INTC, that a UART TX-empty source can reach
the same machine external interrupt path through INTC, that external UART RX
serial input can trigger RX-available and RX-overrun interrupt handling through
INTC, that GPIO input level interrupts can reach the same path through INTC,
that a timer interrupt firmware image can enter and return from the C trap
handler, that the
SoC JTAG pins reach the integrated Debug Module, and that an automated external
OpenOCD/GDB process can complete the debug smoke, including halt, register
read, PC memory disassembly through Access Memory, native GDB `stepi`, and an
execute-address hardware breakpoint. It also verifies GDB stress paths with GPR
write/read, trigger delete/reinstall, two hardware breakpoints at separate OTP
addresses, simultaneous two-trigger residency, repeated breakpoint hits, and
post-reset GPR access.
The data-watchpoint run additionally proves OpenOCD/GDB can configure and hit
load-only and store-only trigger modes against a deterministic D-SRAM address.
It checks the user-visible GDB stop semantics and memory transition; the raw
pre-request halt/DPC/cause contract remains directly checked by the core
datapath testbench because GDB may internally step over timing-before triggers.
The metrics run records cache hit rates and runtime efficiency for each current
generated C firmware image so regressions can be compared against a stable
baseline.

## 4. Pass Criteria

All lint targets plus `tb_wasp1` bare/software-loaded simulations, the OTP
programming firmware simulation, the long boot firmware simulation,
the mixed IRQ/DMA firmware simulation, the system stress firmware simulation,
the deterministic-random IRQ stress firmware simulation,
the four-seed IRQ campaign,
the 32-seed nightly IRQ campaign and its campaign-runner unit tests,
the DMA copy firmware simulation,
the UART IRQ firmware simulation, the UART RX IRQ firmware simulation,
the DMA IRQ firmware simulation,
the GPIO IRQ firmware simulation, the timer IRQ firmware simulation,
remote-bitbang smoke, OpenOCD smoke, GDB smoke, GDB stress, GDB long stress,
and GDB data-watchpoint regression must pass
without `$error`, `$fatal`, or debugger command failure. The cache/runtime
metrics target must complete every selected firmware image and emit one metrics
row per image.
The verification report must record the observed time-sequenced test actions
and pass counter.

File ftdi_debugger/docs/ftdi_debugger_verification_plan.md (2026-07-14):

# ftdi_debugger Verification Plan

## 1. Goals

Verify that the FTDI debugger can replace the remote-bitbang simulation adapter
for real FPGA/board-level debug while preserving the same OpenOCD/GDB target
behavior.

## 2. Bring-Up Checks

| Check | Method | Pass Criteria |
| --- | --- | --- |
| USB enumeration | Connect to host and inspect FTDI device | FT2232H appears with expected VID/PID and serial |
| Channel mode | Run OpenOCD ftdi driver | Channel A enters MPSSE/JTAG without errors |
| VREF and ownership gating | Sweep VREF and toggle OpenOCD TARGET_EN | Level shifters enable only when VREF is valid and TARGET_EN is high |
| JTAG idle levels | Scope TCK/TMS/TDI/TDO/TRST/SRST | Idle levels match schematic and OpenOCD reset config |
| TAP scan | Run OpenOCD target probe | IDCODE `0x100001cf` is detected |
| DTM/DM discovery | Run OpenOCD RISC-V examine | hart 0, XLEN=32, and `misa=0x40000100` are detected |
| GDB attach | Run wasp1 GDB smoke/stress | GDB reads GPRs/PC, executes `stepi`, hits `hbreak *0x4`, and the stress flow hits simultaneous `hbreak *0x0` / `hbreak *0x4`, then detaches |
| UART channel | Open host serial port | wasp1 UART TX/RX path works for console/OTP tooling |
| Host OTP protocol | Run `make -C ftdi_debugger host-test` | Framing, CRC, chunking, range/alignment, irreversible-bit, verify, lock, and sequence checks pass |
| Hardware package check | Run `make -C ftdi_debugger lint` | Pinout, OpenOCD config, Rev A design spec, schematic input, netlist, BOM, and docs remain mutually consistent |
| PCB placement DRC | Run `make -C ftdi_debugger kicad-pcb-placement-drc` | No electrical/geometry/silk/parity category remains; unconnected items are explicit until routing |
| Final PCB DRC | Run `make -C ftdi_debugger kicad-pcb-final-drc` | Zero unconnected items, shorts, clearance errors, silk violations, parity errors, and unreviewed warnings |
| Routed-board audit | Read the committed PCB through KiCad `pcbnew` | Four copper layers, 1.6 mm board, closed outline, filled In1.Cu GND plane, reviewed J1/J2 geometry, PCB-only test-pad attributes, and both USB pair skews at most 0.50 mm |
| Production BOM | Run `make -C ftdi_debugger production-bom-check` | Every board reference has exact population and footprint coverage; critical MPNs, source URLs, and lifecycle-review dates are present |
| Manufacturing output | Run `make -C ftdi_debugger kicad-pcb-manufacturing` | Final DRC passes first; nine Gerbers, common coordinate system, closed profile, separate PTH/NPTH drills, 48 fitted positions, IPC-D-356, statistics, and assembly PDFs pass audit |
| Release archive | Run `make -C ftdi_debugger kicad-manufacturing-release` | Deterministic ZIP contains CAM data, BOM, notes, checklist, reports, schematic, and internal/external SHA-256 manifests |
| Assembly drawing QA | Render both generated PDFs to images | Board geometry is unclipped, footprint properties do not obscure the drawing, U2 is marked DNP, and the empty bottom assembly state is explicit |

## 3. Time-Sequenced Case Table Template

| Time | Action | Expected result | Observed result |
| --- | --- | --- | --- |
| 0s-5s | Plug debugger into host with target disconnected | USB enumerates; TARGET_EN pulldown and absent VREF keep target drivers high-Z | TBD |
| 5s-15s | Power target, connect VREF, then start OpenOCD | VREF alone leaves drivers disabled; TARGET_EN then enables them and reset pins idle high | TBD |
| 15s-30s | Start OpenOCD | TAP/DTM/hart detected | TBD |
| 30s-60s | Run GDB smoke/stress | register packet, PC read, `stepi`, one `hbreak`, and dual-resident `hbreak` stress pass | TBD |
| 60s-90s | Open UART channel | console or OTP programming transaction passes | TBD |
| offline | Run collateral checker | config, documentation, Rev A netlist, and BOM checks pass | PASS before hardware |
| offline | Run placement-stage PCB DRC and 3D preview | functional placement is electrically consistent and visually reviewable; unrouted nets remain explicit | PASS before routing |
| offline | Run final DRC and routed-board audit | no DRC error, unconnected pad, or parity error; both USB skew checks pass | PASS: 2 reviewed footprint warnings only |
| offline | Generate and visually review manufacturing outputs | Gerber/drill geometry and 48 fitted positions pass; top/bottom assembly plots are legible | PASS locally; external release gates remain HOLD |
| offline | Run host protocol unit tests against OTP model | all destructive-operation safeguards and protocol invariants pass | PASS before target loader |

## 4. Required Evidence

The final hardware milestone should archive:

```text
schematic PDF
PCB layout/gerbers
placement and final-routing DRC reports
BOM
Rev A schematic-input lint log
OpenOCD log
GDB smoke log
UART smoke log
scope captures for JTAG reset/shift timing
collateral checker log
```

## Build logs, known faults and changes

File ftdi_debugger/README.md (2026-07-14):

# wasp1 FTDI Debugger

This directory tracks the external FTDI-based hardware debugger planned for
the final wasp1 bring-up flow.

The debugger is outside the wasp1 SoC RTL. It is a board-level tool that
connects a host PC running OpenOCD/GDB to the wasp1 JTAG pins.

```text
GDB -> OpenOCD -> FTDI debugger -> wasp1 JTAG pins -> debug_jtag -> debug -> core
```

Planned baseline:

```text
USB bridge: FT2232H
Channel A: MPSSE JTAG
Channel B: UART for console / OTP programming flow
Target interface: VREF-sensed level-shifted JTAG, optional SRST/TRST
Primary software: OpenOCD ftdi driver plus wasp1 target config
```

Current status: the requirements, pinout, OpenOCD config, Rev A BOM/netlist,
editable block diagram, native four-sheet KiCad schematic, routed four-layer
PCB, Windows/Linux host setup, tested UART OTP client, and a simulated RV32I
I-SRAM target loader are present. ERC has
zero violations; final PCB DRC has zero errors, zero unconnected pads, and zero
schematic parity errors. The ADBUS6 `FT_TARGET_EN` gate keeps the target
isolated until OpenOCD explicitly enables it after MPSSE setup. Independent
local manufacturing review now passes, including Gerber/drill geometry, 48
fitted placement rows, and full production-BOM coverage. Fabrication is still
HOLD pending board-shop USB impedance sign-off, second-person CAM review,
procurement confirmation, and physical board bring-up.

Run the documentation/config consistency check with:

```text
make -C ftdi_debugger lint
make -C ftdi_debugger host-test
make -C ftdi_debugger kicad-pcb-placement-drc
make -C ftdi_debugger kicad-pcb-final-drc
make -C ftdi_debugger kicad-pcb-manufacturing
make -C ftdi_debugger kicad-manufacturing-release
```

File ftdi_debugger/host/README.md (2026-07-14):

# wasp1 Host Tools

This directory contains user-space host support for the FT2232H debugger. It
does not contain a custom USB kernel driver.

```text
Channel A: OpenOCD ftdi adapter -> libusb -> FT2232H MPSSE JTAG
Channel B: wasp1-otp -> operating-system serial API -> FTDI VCP UART
```

## OTP Tool

Install the optional serial dependency:

```text
python3 -m pip install -r ftdi_debugger/host/requirements.txt
```

Probe a loader, inspect status, and read bytes:

```text
python3 ftdi_debugger/host/wasp1_otp_tool.py --port /dev/ttyUSB1 probe
python3 ftdi_debugger/host/wasp1_otp_tool.py --port /dev/ttyUSB1 status
python3 ftdi_debugger/host/wasp1_otp_tool.py --port /dev/ttyUSB1 read \
  --offset 0x0 --length 256 --output otp.bin
```

Programming and permanent locking require explicit confirmation flags:

```text
python3 ftdi_debugger/host/wasp1_otp_tool.py --port /dev/ttyUSB1 program \
  firmware.bin --offset 0x0 --yes-program
python3 ftdi_debugger/host/wasp1_otp_tool.py --port /dev/ttyUSB1 lock \
  --yes-lock
```

Programming performs a complete pre-read, rejects every attempted `0 -> 1`
transition locally, programs in bounded chunks, and verifies by default.

The target must already be running a loader that implements the protocol in
`../docs/ftdi_debugger_host_software_spec.md`. A blank device can reach this
state by loading the target-side programmer into I-SRAM through JTAG; a later
production image may contain a protected resident loader.

## Verification

```text
make -C ftdi_debugger host-test
make -C ftdi_debugger host-lint
```

Platform setup is documented under `linux/` and `windows/`.

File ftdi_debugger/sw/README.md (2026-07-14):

# ftdi_debugger Software

This directory contains EDA generation and consistency-checking scripts. The
end-user OpenOCD/UART software package is under `../host/`.

The primary OpenOCD configuration lives in:

```text
ftdi_debugger/openocd/wasp1_ft2232h_reference.cfg
```

The baseline plan does not require custom USB firmware.

Stage-1 software expectations:

```text
OpenOCD uses channel A through the standard ftdi adapter driver.
Host serial tooling uses channel B as a standard FTDI UART.
EEPROM programming is optional and limited to product strings, serial numbers,
  and stable channel descriptors.
No private USB protocol is required for debug attach, GDB stepi, hbreak, UART,
  or OTP programming flows.
```

The local consistency checker is:

```text
python3 check_ftdi_debugger_collateral.py
```

The deterministic PCB generator consumes a KiCad XML netlist and system
footprints. `make -C ftdi_debugger kicad-pcb-generate` recreates the four-layer
Rev A placement under `build/` without overwriting the formal routed board.
`kicad-pcb-placement-drc` checks its unrouted-stage DRC contract,
`kicad-pcb-final-drc` checks the committed routed board plus USB length
matching, `kicad-pcb-manufacturing` generates and audits the fabrication and
assembly package, and `kicad-pcb-render` creates a local 3D review image.

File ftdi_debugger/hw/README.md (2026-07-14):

# ftdi_debugger Hardware

This directory holds the FTDI debugger hardware collateral:

```text
schematic source
schematic PDF
PCB layout
gerbers
BOM
assembly notes
bring-up notes
```

The checked-in Rev A source package is:

```text
kicad/wasp1_ft2232h_debugger_revA/wasp1_ft2232h_debugger_revA.kicad_sch
schematic/wasp1_ft2232h_debugger_revA_schematic.md
schematic/wasp1_ft2232h_debugger_revA.pdf
schematic/svg/
netlist/wasp1_ft2232h_debugger_revA_nets.csv
bom/wasp1_ft2232h_debugger_revA_bom.csv
```

Its detailed electrical design and editable architecture diagram are:

```text
../docs/ftdi_debugger_revA_design_spec.md
../docs/diagrams/ftdi_debugger_revA_block.graffle
```

The native four-sheet KiCad hierarchy passes KiCad 10 ERC with zero errors and
zero warnings. The four-layer board is fully routed and its final DRC has zero
errors, zero unconnected pads, and zero schematic parity errors. Generated
manufacturing data remains under `build/manufacturing/`; fabrication and
assembly requirements are tracked in `fabrication/` and `assembly/`.

The PDF is a stable five-page A3 review preview assembled from individually
rendered sheets. The native KiCad hierarchy remains the electrical source of
truth; SVG exports provide vector page review.

The first schematic revision must follow:

```text
../docs/ftdi_debugger_pinout.md
../openocd/wasp1_ft2232h_reference.cfg
```

Before PCB work, keep the schematic pin mapping, target connector silk, and
OpenOCD layout masks synchronized. The repository-level static check is:

```text
make -C ftdi_debugger lint
```

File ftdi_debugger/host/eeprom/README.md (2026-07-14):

# FT2232H EEPROM Provisioning

Rev A can fit the optional 93LC56B EEPROM. Initial unpopulated-board bring-up
uses the FT2232H defaults. Production provisioning should define and archive:

```text
assigned VID/PID
manufacturer and product strings
unique per-board serial number
Channel A direct/libusb-oriented mode for OpenOCD
Channel B VCP mode for UART
maximum USB current matching the final board declaration
```

Use FT_PROG or an audited equivalent to read, program, and read back the EEPROM.
Never clone one serial number across manufactured boards. The exported FT_PROG
template and its checksum belong here after the project USB identity and final
power declaration are frozen.

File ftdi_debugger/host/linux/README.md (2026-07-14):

# Linux Host Setup

Linux uses standard components only:

```text
Channel A: OpenOCD ftdi driver through libusb-1.0
Channel B: kernel ftdi_sio VCP driver and /dev/ttyUSBx
```

Install OpenOCD, libusb, Python, and pyserial using the distribution package
manager. Install `99-wasp1-ftdi.rules` into `/etc/udev/rules.d/`, then reload
udev rules or reconnect the debugger. The rule uses `TAG+="uaccess"`; no global
world-writable device permission is granted.

Verify enumeration before connecting a target:

```text
lsusb -d 0403:6010
python3 ../wasp1_otp_tool.py probe
openocd -f ../../openocd/wasp1_ft2232h_reference.cfg
```

If both FT2232H interfaces bind to `ftdi_sio`, OpenOCD normally detaches only
the selected Channel A interface through libusb. A production EEPROM profile
may instead mark Channel A for the direct interface and retain VCP on Channel
B, reducing interface-selection ambiguity.

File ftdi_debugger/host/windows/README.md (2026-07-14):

# Windows Host Setup

The reference Windows arrangement uses two standard per-interface drivers:

```text
FT2232H Interface A: WinUSB for OpenOCD/libusb MPSSE JTAG
FT2232H Interface B: FTDI VCP for the COM-port UART
```

1. Install a current OpenOCD build and the official FTDI VCP package.
2. In Device Manager, confirm that Channel B appears as a COM port.
3. Bind only FT2232H Interface A to WinUSB. Zadig is suitable for development.
4. Do not replace the driver for the whole composite device or Interface B.
5. Run OpenOCD with `ftdi_debugger/openocd/wasp1_ft2232h_reference.cfg`.
6. Run `wasp1_otp_tool.py --port COM<number> probe` against Channel B.

For distribution, replace the manual Interface A binding with a signed INF
package that selects WinUSB for the project VID/PID and interface number. Such
an INF is installation metadata for the standard WinUSB driver, not a custom
wasp1 kernel driver.

The default FTDI `0403:6010` identity is acceptable for internal bring-up. A
released product must use a properly assigned/licensed USB identity and update
the OpenOCD config, udev rule, INF package, and EEPROM profile together.

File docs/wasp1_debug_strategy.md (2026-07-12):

# wasp1 Debug Strategy

## 1. Goal

wasp1 debug targets compatibility with OpenOCD and GDB through a RISC-V External
Debug Spec 0.13.x style implementation.

The final project scope also includes an FTDI-based external hardware debugger
so the same OpenOCD/GDB flow can be used on FPGA boards and final hardware.

## 2. Debug Subsystem

```text
debug
  jtag_tap
  riscv_dtm
  riscv_dm
  debug_halt_ctrl
  debug_reg_access
  debug_mem_access
  debug_abstract_cmd
  debug_trigger
  debug_progbuf
  debug_progbuf_exec
```

## 3. Implementation Stages

| Stage | Scope |
| ---: | --- |
| 1 | JTAG DTM, DMI, dmcontrol, dmstatus, halt/resume, basic GPR access |
| 2 | abstract command, DPC readback, DCSR.step single-step |
| 3 | physical Access Memory through halted core and native GDB `stepi` smoke |
| 4 | two execute-address hardware breakpoints through Debug Spec trigger CSRs |
| 5 | longer debugger stress with simultaneous two-trigger residency |
| 6 | FT2232H external debugger pinout/OpenOCD config, schematic/PCB, FPGA/board bring-up |
| 7 | load/store trigger configuration, precise core LSU action, end-to-end OpenOCD/GDB watchpoints, and Program Buffer postexec |
| 8 | optional System Bus Access plus FT2232H/FPGA hardware validation |

## 4. Core Interaction

The core must support:

```text
halt request
resume request
halted status
register access path
memory access path
precise execute/load/store trigger entry paths
debug exception or debug entry behavior
```

## 5. OpenOCD Bring-Up Target

The first debug bring-up target is for OpenOCD to:

```text
scan JTAG chain
identify DTM
read dmstatus
halt the hart
read and write GPRs
resume the hart
single-step one instruction through DCSR.step
read memory through halted-core Access Memory
hit two hardware breakpoints through hbreak
hit load/store watchpoints through rwatch/watch
```

Physical Access Memory, native `stepi`, and two execute-address hardware
breakpoints are now part of the automated remote-bitbang OpenOCD/GDB smoke and
stress flow. The stress target also covers GPR write/read and breakpoint
delete/reinstall at two OTP addresses. Load/store trigger CSR configuration,
filtered debug-to-core outputs, precise core-side LSU match/halt behavior, and
end-to-end OpenOCD/GDB `rwatch`/`watch` regression are implemented. Program
Buffer postexec is also integrated through the real halted-core instruction
channel. System Bus Access remains an optional later-stage target.

The four-word `debug_progbuf` storage leaf is DMI-routable through
`debug_dmi_regs`, including busy protection and dmactive clear. The
one-instruction-outstanding `debug_progbuf_exec` sequencing leaf is integrated
with Access Register `postexec` and the halted-core execution channel.
`abstractcs.progbufsize=4`; `abstractauto` is implemented as WARL zero.

## 6. External FTDI Debugger

The final hardware debugger is a companion board, not part of the wasp1 chip
RTL. The planned baseline is:

```text
FT2232H channel A -> MPSSE JTAG -> wasp1 JTAG pins
FT2232H channel B -> UART -> wasp1 UART / OTP programming flow
```

The chip-side debug contract must remain independent of whether OpenOCD reaches
wasp1 through:

```text
remote_bitbang Verilator simulation
FT2232H hardware debugger
other OpenOCD-compatible JTAG adapters
```

The FTDI-specific collateral is tracked under `ftdi_debugger/`.

The current FTDI collateral includes the stage-1 FT2232H pinout, a reference
OpenOCD FTDI configuration, and a static checker:

```text
make -C ftdi_debugger lint
```

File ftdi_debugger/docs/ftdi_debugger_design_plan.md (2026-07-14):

# ftdi_debugger Design Plan

## 1. Partition

```text
USB-C / USB-B connector
  -> ESD and power protection
  -> FT2232H
     -> Channel A MPSSE JTAG
     -> Channel B UART
  -> target-voltage sensing and level shifters
  -> wasp1 target connector
```

## 2. Design Steps

| Step | Work Item | Output |
| ---: | --- | --- |
| 1 | Freeze connector pinout and voltage range | pinout table and schematic constraints |
| 2 | Choose FT2232H power/clock/EEPROM circuit | schematic page |
| 3 | Define JTAG/UART level shifting | schematic page and timing/voltage notes |
| 4 | Write OpenOCD FTDI config for the final pin mapping | checked-in `.cfg` |
| 5 | Build PCB | schematic, layout, BOM, assembly notes |
| 6 | Electrical bring-up | USB enumeration and voltage checks |
| 7 | JTAG bring-up | OpenOCD IDCODE/DTM/hart detection on FPGA |
| 8 | GDB bring-up | register read, halt/resume, step/breakpoint milestones |
| 9 | Host package | Windows/Linux setup, udev policy, EEPROM plan, and UART OTP client |
| 10 | OTP transport bring-up | Target I-SRAM loader, protocol simulation, and Channel B hardware smoke |

Step 1 has a stage-1 reference output:

```text
ftdi_debugger/docs/ftdi_debugger_pinout.md
```

Steps 2 and 3 now have a native Rev A KiCad schematic and its review package:

```text
ftdi_debugger/hw/kicad/wasp1_ft2232h_debugger_revA/
ftdi_debugger/hw/schematic/wasp1_ft2232h_debugger_revA_schematic.md
ftdi_debugger/hw/netlist/wasp1_ft2232h_debugger_revA_nets.csv
ftdi_debugger/hw/bom/wasp1_ft2232h_debugger_revA_bom.csv
```

Step 5 has reached the verified routed-PCB milestone:

```text
native four-layer .kicad_pcb with 57 footprints and 49 real nets
110 mm x 65 mm board outline and 1.6 mm ENIG stackup
Default, USB_DIFF, POWER, VBUS, and JTAG net classes
695 routed segments, 72 vias, and a continuous filled In1.Cu GND plane
final DRC with zero errors, zero unconnected pads, and zero parity errors
USB pair skew below 0.50 mm on both sides of ESD1
```

The step-5 manufacturing target now reproducibly generates and audits Gerbers,
drill files, pick-and-place data, IPC-D-356, board statistics, and assembly
drawings. These outputs still require an independent manufacturing review and
fabricator-specific impedance confirmation before electrical bring-up begins.

The reference OpenOCD output for step 4 is:

```text
ftdi_debugger/openocd/wasp1_ft2232h_reference.cfg
```

Step 9 now has a tested host-side baseline:

```text
ftdi_debugger/host/wasp1_otp_tool.py
ftdi_debugger/docs/ftdi_debugger_host_software_spec.md
ftdi_debugger/host/linux/99-wasp1-ftdi.rules
ftdi_debugger/host/windows/README.md
```

It deliberately uses standard WinUSB/libusb/VCP facilities and does not add a
wasp1 kernel driver. Step 10 now has a freestanding RV32I I-SRAM loader and a
complete-SoC bit-serial UART/OTP regression. Physical FT2232H Channel B
operation remains open.

## 3. Design Notes

Use FT2232H rather than FT232H as the default because the second channel can be
used as a UART. That keeps the final wasp1 development setup simple:

```text
one USB cable -> JTAG debug + UART console / OTP programming
```

Target VREF must define the IO level seen by the target. The debugger must not
drive JTAG or UART pins when VREF is absent or before OpenOCD asserts the
ADBUS6 TARGET_EN safety gate.

The first schematic implements target-facing high-Z behavior by NAND-gating
the active-low level-shifter output enables with `VREF_VALID` and TARGET_EN.
JTAG reset signals are active-low and idle high through both OpenOCD layout
data and target-side pull-ups.

## 4. Relationship To Current Simulation

The current Verilator remote-bitbang flow proves the chip-side JTAG/DTM/DM
contract before hardware exists:

```text
current: OpenOCD -> remote_bitbang TCP -> Vwasp1 JTAG pins
final:   OpenOCD -> FT2232H MPSSE -> real wasp1 JTAG pins
```

The OpenOCD target section should remain shared between both flows where
practical.

The current chip-side smoke now includes:

```text
register read
native GDB stepi
one OpenOCD/GDB hardware breakpoint at 0x4
```

The FTDI debugger bring-up should reuse that exact GDB script before adding
board-specific stress tests.

## 5. Current Hardware Package Status

The Rev A hardware package freezes the FT2232H channel split, target header,
VREF-valid level-shifter enable policy, BOM classes, and signal ownership. The
native four-sheet KiCad schematic passes ERC with zero errors and zero warnings.
The four-layer PCB is fully routed and passes final DRC with no errors,
unconnected pads, or schematic parity errors. The two remaining warnings are
reviewed board-local footprint overrides for J1 and J2. Manufacturing outputs
are reproducibly generated and pass structural audit. Independent Gerber,
stackup, BOM, and assembly review plus physical bring-up remain later steps.

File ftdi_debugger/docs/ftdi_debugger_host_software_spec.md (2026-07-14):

# ftdi_debugger Host Software Spec

## 1. Purpose

The host package makes the Rev A FT2232H debugger usable on Windows and Linux
without a wasp1-specific kernel driver. Channel A remains a standard OpenOCD
FTDI/libusb path. Channel B remains an FTDI virtual serial port and carries a
versioned wasp1 OTP protocol.

```text
GDB -> OpenOCD -> libusb -> FT2232H Channel A -> JTAG
wasp1-otp -> serial/VCP -> FT2232H Channel B -> wasp1 UART loader
```

## 2. Driver Contract

| Host | Channel A | Channel B | wasp1 kernel driver |
| --- | --- | --- | --- |
| Windows | WinUSB on Interface A for OpenOCD/libusb | official FTDI VCP on Interface B | not required |
| Linux | libusb-1.0 plus udev access | kernel `ftdi_sio` VCP | not required |

Windows installation must bind WinUSB to Interface A only. Replacing the whole
composite device or Interface B would remove the UART COM port. Linux access
must use `TAG+="uaccess"` rather than a world-writable USB or tty node.

## 3. Loader Entry Modes

The UART protocol assumes that compatible target code is already executing
from I-SRAM. Two entry modes are permitted:

| Mode | Use | Loader entry |
| --- | --- | --- |
| Manufacturing/bootstrap | Blank or fully erasable development device | OpenOCD loads the programmer into I-SRAM and starts it through RISC-V debug |
| Resident service | Field-programmable device with a protected OTP prefix | Reset code copies its programmer routine to I-SRAM and enters it under an explicit boot strap/policy |

The manufacturing/bootstrap target loader is implemented under
`llvm_s1/bsp/bootloader/` and links completely into I-SRAM. The project does not
silently reserve an OTP resident-loader partition. That partition, entry strap,
and recovery/security policy must be frozen before a production image uses the
resident-service mode.

## 4. UART Link

```text
baud: 115200 by default
format: 8 data bits, no parity, 1 stop bit
flow control: none
request concurrency: one outstanding frame
integer encoding: little-endian
maximum payload: 256 bytes
```

## 5. Frame Format

CRC32 is the IEEE/zlib CRC over the complete header and payload. The CRC field
itself is excluded.

| Offset | Size | Field | Meaning |
| ---: | ---: | --- | --- |
| 0 | 2 | magic | ASCII `W1`, bytes `0x57 0x31` |
| 2 | 1 | version | protocol version, currently 1 |
| 3 | 1 | kind | 0 request, 1 response |
| 4 | 2 | sequence | wraps modulo 65536; response echoes request |
| 6 | 1 | command | command identifier |
| 7 | 1 | status | zero in requests; response result |
| 8 | 4 | address | byte offset in `OTP_DATA_SIZE` |
| 12 | 2 | payload length | 0 through 256 |
| 14 | 2 | flags | zero until assigned by a later protocol version |
| 16 | N | payload | command-specific data |
| 16+N | 4 | CRC32 | little-endian frame checksum |

The loader must discard bytes until magic is found, reject an unsupported
version or oversized frame, validate CRC before dispatch, and never start an
OTP program pulse for an invalid frame.

Target READ and PROGRAM precheck must use the uncached `OTP_ADDR/OTP_RDATA`
register path. A direct OTP data-window load can leave stale pre-program data in
D-cache and is not valid for post-program verification.

## 6. Commands

| Value | Command | Request | Successful response |
| ---: | --- | --- | --- |
| `0x01` | HELLO | empty | `<otp_data_size:u32, capabilities:u32, max_payload:u16, loader_version:u16>` |
| `0x10` | READ | address plus requested length `u16` | requested OTP bytes |
| `0x11` | PROGRAM | aligned address plus word-aligned bytes | empty after all words complete |
| `0x20` | STATUS | empty | raw OTP STATUS register `u32` |
| `0x21` | LOCK | empty | empty after permanent lock is observed |

Capability bits are READ bit 0, PROGRAM bit 1, and LOCK bit 2. PROGRAM accepts
only a 4-byte-aligned offset and payload length. The loader must validate the
entire request range and all `0 -> 1` violations before issuing the first word
program operation in that frame.

## 7. Status Codes

| Value | Name | Meaning |
| ---: | --- | --- |
| `0x00` | OK | command completed |
| `0x01` | BAD_COMMAND | command is not implemented |
| `0x02` | BAD_VERSION | frame version is unsupported |
| `0x03` | BAD_LENGTH | payload or requested length is invalid |
| `0x04` | BAD_ADDRESS | range exceeds OTP data window |
| `0x05` | BAD_ALIGNMENT | PROGRAM address or length is not word aligned |
| `0x06` | CRC_ERROR | received CRC did not match |
| `0x07` | LOCKED | OTP programming is permanently locked |
| `0x08` | ILLEGAL_TRANSITION | operation attempted a `0 -> 1` transition |
| `0x09` | PROGRAM_ERROR | hardware STATUS reported a program error |
| `0x0a` | BUSY | an operation is already active |
| `0x0b` | INTERNAL_ERROR | loader invariant or unexpected hardware result failed |

## 8. Programming Safety

The host tool must:

```text
require --yes-program before PROGRAM
require --yes-lock before LOCK
probe and enforce OTP_DATA_SIZE
require word alignment for PROGRAM
read the destination before programming
reject every requested 0 -> 1 transition before sending PROGRAM
verify the complete image unless --no-verify is explicitly used
report the first byte offset and values on precheck or verify failure
```

Retries repeat exactly the same sequence and data. Reprogramming a successfully
written word with identical data is idempotent under the OTP AND rule. A target
loader may cache the latest sequence/response to avoid repeating hardware work.

## 9. EEPROM And USB Identity

Default FTDI VID/PID `0403:6010` is an internal bring-up identity. Before
external distribution, the project must obtain a permitted USB identity and
update these as one controlled release:

```text
FT2232H EEPROM image
OpenOCD configuration
Linux udev rule
Windows signed INF package
host auto-detection tests and documentation
```

Every production debugger must have a unique serial number.

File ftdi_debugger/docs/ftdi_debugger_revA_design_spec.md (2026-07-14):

# FT2232H Debugger Rev A Design Spec

## 1. Design Objective

Rev A is a USB-powered companion debugger for wasp1. FT2232H Channel A carries
OpenOCD-compatible MPSSE JTAG, while Channel B remains a standard UART for the
console and OTP programming transport. Target-facing IO supports 1.8 V through
3.3 V without back-powering an unpowered target.

The authoritative formal EDA source belongs under:

```text
ftdi_debugger/hw/kicad/wasp1_ft2232h_debugger_revA/
```

Editable board block diagram:

```text
ftdi_debugger/docs/diagrams/ftdi_debugger_revA_block.graffle
```

The diagram uses native explicit line segments, V-shaped arrowheads, a visible
5 pt grid, and separate POWER, CLOCK, IF, and COMB blocks. No block combines
sequential and combinational timing labels.

## 2. Circuit Partition

```text
USB-C J1
  -> USBLC6-2SC6 ESD1 -> FT2232HL U1 USB PHY
  -> MF-MSMF050 F1 -> AP2112K-3.3 U6 -> VCC_3V3

FT2232HL U1
  -> Channel A ADBUS0..5 -> SN74AXC8T245 U4 -> JTAG/reset outputs
  -> Channel A ADBUS2 <- SN74AXC2T245 U5 <- target TDO
  -> Channel A ADBUS6 -> TARGET_EN safety gate
  -> Channel B BDBUS0 -> U4 -> target UART_RXD
  -> Channel B BDBUS1 <- U5 <- target UART_TXD

Target VREF
  -> TLV7041 U3 -> VREF_VALID
VREF_VALID + TARGET_EN
  -> SN74LVC1G00 U7 -> SHIFT_OE_N -> U4/U5
VREF_VALID -> 2N7002 Q1 -> isolated amber status LED D2
```

## 3. Frozen Major Components

| Refdes | Selected part | Reason |
| --- | --- | --- |
| U1 | FT2232HL, LQFP-64 | Dual channel, Channel A MPSSE plus Channel B UART; hand-assembly-friendly package |
| U2 | 93LC56BT-I/SN | Production Microwire EEPROM; optional/DNI when default FTDI descriptors are sufficient |
| U3 | TLV7041DBVR | Open-drain, rail-to-rail-input comparator powered from 3.3 V |
| U4 | SN74AXC8T245PWR | Six same-direction target outputs, 0.65 V to 3.6 V rails, Ioff and VCC isolation |
| U5 | SN74AXC2T245RSWR | Two target inputs, independent direction pins, Ioff and VCC isolation |
| U6 | AP2112K-3.3TRG1 | 600 mA USB-to-3.3 V LDO in SOT-25 |
| U7 | SN74LVC1G00DBVR | Fail-safe active-low OE generation from two active-high qualifiers |
| Q1 | 2N7002, SOT-23 | Isolates the VREF-valid logic net from D2 indicator current |
| Y1 | ECS-3225MVQ-120-CN-TR | 12 MHz, 3.3 V, +/-25 ppm oscillator meeting the FTDI OSCI tolerance |
| ESD1 | USBLC6-2SC6 | Low-capacitance USB2 D+/D- protection |
| ESD2 | TPD8E003DQDR | Eight target-header GPIO/JTAG/UART ESD channels |
| J1 | GCT USB4105-GF-A family | USB2-only Type-C receptacle with independent CC1/CC2 pins |
| J2 | Keyed 2x7, 2.54 mm IDC header | Fixed wasp1 target pinout and cable keying |

## 4. USB And Power

J1 is a USB device receptacle. CC1 and CC2 each use an independent 5.1 kOhm
1% pulldown. VBUS passes through a 500 mA hold resettable fuse before U6.
USB D+ and D- pass through ESD1 and are routed as a 90 Ohm differential pair
without stubs. U6 supplies VCC_3V3 to FT2232H VCCIO/VPHY/VPLL/VREGIN and the
local side of both translators.

FT2232H VREGOUT supplies VCORE and receives the datasheet-required minimum
3.3 uF local capacitor. Every VCCIO/VPHY/VPLL/VREGIN pin receives a 100 nF
local capacitor, with 4.7 uF bulk capacitance on VCC_3V3. REF uses 12 kOhm 1%
to ground. TEST is grounded. RESET_N is pulled high with 10 kOhm.

Y1 drives OSCI at 12 MHz; OSCO is left unconnected. U2 connects EECS and
EECLK directly and ties its DI/DO data pins to the bidirectional EEDATA net.

## 5. Target Isolation

U3 compares VREF against a nominal 1.57 V divider reference. Its open-drain
output is pulled up to VCC_3V3 and is high only for a valid target rail. The
threshold leaves margin below the minimum supported 1.8 V VREF.

FT_TARGET_EN is ADBUS6 with a 100 kOhm pulldown. At FT2232H power-up Channel A
is not yet MPSSE, so the pulldown keeps the target isolated. OpenOCD drives
ADBUS6 high only after applying:

```text
ftdi layout_init 0x0078 0x007b
```

U7 implements:

```text
SHIFT_OE_N = !(VREF_VALID && FT_TARGET_EN)
```

U4 and U5 are therefore disabled unless both the target voltage and host-side
JTAG ownership are valid. Their VCC isolation and Ioff behavior provide a
second barrier when VREF is absent.

Q1 uses `VREF_VALID` only as a MOSFET gate input. D2 current flows from
`VCC_3V3` through RLED2 and D2 into Q1, so the indicator cannot pull down the
U7 input. A 10 kOhm RVALID pullup defines the comparator logic-high level.

## 6. Signal Direction

U4 VCCA is VCC_3V3 and VCCB is VREF. Both direction banks are fixed A-to-B.
Its active channels are TCK, TDI, TMS, nTRST, nSRST, and UART_RXD. U5 uses the
same rails with each direction fixed B-to-A for TDO and UART_TXD. All U4 target
outputs include 33 Ohm series-damping footprints near U4.

Unused U4 A7 and A8 are separately biased low through 10 kOhm RU4_A7 and
RU4_A8. This avoids floating CMOS inputs while preserving the bidirectional
translator pins as ordinary protected inputs rather than hard ground shorts.

ESD2 protects the eight J2 signal pins. It is placed at J2, ahead of long board
routes. VREF is sense-only and is never connected to VCC_3V3.

## 7. PCB Constraints

```text
board: four layers preferred (signal / ground / power / signal)
USB D+/D-: 90 Ohm differential, matched within 0.5 mm, continuous ground plane
TCK: shortest target path, 33 Ohm source resistor, no stubs
ESD1/ESD2: connector-side placement before protected circuitry
U1 decoupling: each capacitor within 3 mm of its supply pin
VREF: no copper-plane use beyond U3/U4/U5 and local decoupling
target signals: keep at least 0.25 mm from USB pair
test points: VCC_3V3, VCORE, VREF, VREF_VALID, TARGET_EN, SHIFT_OE_N, TCK, TDO
```

The native Rev A implementation uses a 110 mm x 65 mm, 1.6 mm four-layer board:

```text
F.Cu: component-side signal and local power routing
In1.Cu: continuous filled GND reference plane
In2.Cu: reviewed power trunks, including the protected USB VBUS tree
B.Cu: secondary signal routing
finish: ENIG
```

J1 is on the left edge, J2 is on the right edge, and functional placement runs
from USB/power through U1, VREF/level shifting, ESD2, and the target connector.
The placement generator preserves the schematic's 57 footprints and 49 real
nets; synthetic no-connect nets remain netless. It writes a placement artifact
under `build/` and cannot overwrite the formal routed PCB. U2 retains its
schematic DNP status.

The routed board contains 695 trace segments and 72 through vias. Signal routes
use 0.20 mm copper, local low-voltage power and JTAG routes use 0.25 mm, and USB
VBUS uses 0.50 mm copper with 0.80/0.40 mm power vias. The connector-to-ESD USB
pair measures 7.762475 mm for D+ and 7.299259 mm for D-, giving 0.463216 mm
skew. The ESD-to-U1 pair measures 18.270343 mm for D+ and 18.684556 mm for D-,
giving 0.414214 mm skew. Both satisfy the 0.50 mm matching requirement.

Final DRC reports zero errors, zero unconnected pads, and zero schematic parity
errors. The only warnings are local-library mismatch notices for J1 and J2,
whose repeated pad numbers and J1 rotation require native board-local pad
metadata. They are reviewed and tracked rather than globally excluded.

## 8. Source References

```text
FTDI DS_FT2232H Version 2.9
TI SN74AXC8T245 datasheet SCES875C
TI SN74AXC2T245 datasheet SCES879A
TI TLV703x/TLV704x datasheet
TI TPD8E003 datasheet SLLSE38B
ST USBLC6-2SC6 datasheet
Microchip 93LC56B product data
GCT USB4105 product specification
```

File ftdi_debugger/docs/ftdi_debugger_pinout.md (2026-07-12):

# ftdi_debugger Pinout and Schematic Constraints

## 1. Purpose

This document freezes the stage-1 FT2232H debugger pin mapping used by the
checked-in OpenOCD configuration. It is the schematic-input contract for the
first hardware revision.

The debugger is outside the wasp1 chip RTL. It connects a host USB port to the
wasp1 JTAG pins and reserves a second FTDI channel for UART console or OTP
programming.

## 2. FT2232H Channel Assignment

| FT2232H channel | Mode | Function |
| --- | --- | --- |
| Channel A | MPSSE | JTAG to wasp1 Debug Module |
| Channel B | UART | wasp1 UART console / OTP programming transport |

Channel A is selected in OpenOCD with:

```text
ftdi channel 0
```

## 3. Channel A JTAG Mapping

| FT2232H signal | OpenOCD bit | Direction from debugger | wasp1 target signal | Reset/idle intent |
| --- | ---: | --- | --- | --- |
| ADBUS0 | `0x0001` | Output | `jtag_tck_i` | Low when idle |
| ADBUS1 | `0x0002` | Output | `jtag_tdi_i` | Low when idle |
| ADBUS2 | `0x0004` | Input | `jtag_tdo_o` | Input, no drive |
| ADBUS3 | `0x0008` | Output | `jtag_tms_i` | High when idle |
| ADBUS4 | `0x0010` | Output | `jtag_trst_ni` | High inactive |
| ADBUS5 | `0x0020` | Output | target `srst_ni` if present | High inactive |
| ADBUS6 | `0x0040` | Output | board `TARGET_EN` | High only after OpenOCD configures Channel A |

The matching OpenOCD low-byte configuration is:

```text
ftdi layout_init 0x0078 0x007b
ftdi layout_signal nTRST -data 0x0010 -oe 0x0010
ftdi layout_signal nSRST -data 0x0020 -oe 0x0020
```

`0x0078` drives TMS, nTRST, nSRST, and TARGET_EN high at initialization.
`0x007b` makes TCK, TDI, TMS, nTRST, nSRST, and TARGET_EN outputs while
leaving TDO as an input. A 100 kOhm board pulldown holds TARGET_EN low before
OpenOCD takes ownership.

## 4. Channel B UART Mapping

| FT2232H signal | Direction from debugger | wasp1 target signal | Requirement |
| --- | --- | --- | --- |
| BDBUS0 | Output | `uart_rx_i` | Host TX drives target RX through level shifting |
| BDBUS1 | Input | `uart_tx_o` | Target TX drives host RX through level shifting |
| BDBUS2..BDBUS7 | Unused in stage 1 | NC/test pads optional | Do not drive target pins without a documented use |

The UART channel should enumerate as a standard FTDI serial port. No custom USB
firmware is required.

## 5. Target Header

The first hardware revision should expose one keyed target header:

| Pin | Signal | Direction | Requirement |
| ---: | --- | --- | --- |
| 1 | `VREF` | Target to debugger | Target IO reference voltage sense |
| 2 | `GND` | Ground | Adjacent ground for signal return |
| 3 | `TCK` | Debugger to target | JTAG clock |
| 4 | `GND` | Ground | Adjacent ground for signal return |
| 5 | `TMS` | Debugger to target | JTAG mode select |
| 6 | `GND` | Ground | Adjacent ground for signal return |
| 7 | `TDI` | Debugger to target | JTAG data into target |
| 8 | `TDO` | Target to debugger | JTAG data out of target |
| 9 | `nTRST` | Debugger to target | Optional TAP reset, pull up on target side |
| 10 | `nSRST` | Debugger to target | Optional system reset, pull up on target side |
| 11 | `UART_TXD` | Target to debugger | Target UART TX |
| 12 | `UART_RXD` | Debugger to target | Target UART RX |
| 13 | `GND` | Ground | Cable return |
| 14 | `NC/KEY` | No connect | Key or reserved pin |

Schematic work may change the mechanical connector, but any changed pinout must
update this document, the PCB silk, and `openocd/wasp1_ft2232h_reference.cfg`
in the same commit.

## 6. Electrical Constraints

The debugger must not drive target-facing JTAG, reset, or UART outputs unless a
valid `VREF` is present and OpenOCD has asserted `TARGET_EN`.

Target-facing IO must be level shifted to `VREF`. The stage-1 allowed target
range is:

```text
1.8 V <= VREF <= 3.3 V
```

Recommended schematic constraints:

```text
USB connector: ESD protection and controlled shield/ground strategy
FT2232H: 12 MHz reference crystal or oscillator per datasheet circuit
EEPROM: optional but footprint recommended for product string/serial config
VREF sense: comparator plus TARGET_EN safety gating
JTAG/UART level shifters: high-Z target side when VREF invalid or TARGET_EN low
TCK/TMS/TDI/nTRST/nSRST: series damping footprints near driver
TDO/UART_TXD: no debugger-side pull that fights target output
Reset pins: target-side pull-ups define inactive high
Indicators: USB power and VREF-present LEDs
```

## 7. Bring-Up Expectations

The first board must pass the same chip-side debug flow as remote-bitbang:

```text
OpenOCD TAP IDCODE 0x100001cf
hart 0 XLEN=32
misa=0x40000100
two triggers discovered
GDB register read
GDB native stepi
GDB hbreak at 0x4
UART loopback or target-console smoke
```

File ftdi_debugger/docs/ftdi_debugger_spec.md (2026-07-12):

# ftdi_debugger Spec

## 1. Purpose

`ftdi_debugger` is the final external hardware debugger for wasp1. It converts
host USB traffic into standard JTAG signals for the wasp1 RISC-V Debug Module
and optionally exposes a UART channel for console and OTP programming flows.

This block is not part of the wasp1 chip RTL. It is a companion hardware tool.

## 2. Required Host Flow

```text
GDB
  -> OpenOCD ftdi adapter driver
  -> FTDI USB device
  -> wasp1 JTAG header or FPGA pins
  -> debug_jtag_dtm
  -> debug
  -> core debug interface
```

The debugger must support the existing OpenOCD/GDB smoke flow already verified
with the Verilator remote-bitbang harness, including register reads, native
`stepi`, and two execute-address hardware breakpoints through `hbreak`.

## 3. Hardware Baseline

| Item | Requirement |
| --- | --- |
| USB bridge | FT2232H preferred |
| JTAG channel | FT2232H Channel A in MPSSE mode |
| UART channel | FT2232H Channel B reserved for UART console / OTP programming |
| JTAG pins | TCK, TMS, TDI, TDO |
| Reset pins | Optional nTRST and nSRST routed as controllable GPIO |
| Target voltage | Sense target VREF and level-shift JTAG/UART accordingly |
| Protection | ESD protection on external connector pins |
| Connector | One wasp1 target header carrying JTAG, reset, UART, VREF, and GND |
| Indicators | USB power, target VREF present, optional JTAG activity |

The stage-1 pinout and schematic-input constraints are frozen in:

```text
ftdi_debugger/docs/ftdi_debugger_pinout.md
```

## 4. FT2232H Reference Pin Use

The initial reference mapping is:

| FT2232H signal | Function |
| --- | --- |
| ADBUS0 | TCK |
| ADBUS1 | TDI |
| ADBUS2 | TDO |
| ADBUS3 | TMS |
| ADBUS4 | nTRST |
| ADBUS5 | nSRST |
| ADBUS6 | TARGET_EN safety gate |
| BDBUS0 | UART TX to target RX |
| BDBUS1 | UART RX from target TX |

This mapping may change during schematic work, but the final OpenOCD config and
PCB silk must match the chosen mapping exactly.

## 5. Software Contract

The debugger must be usable from OpenOCD without custom host software:

```text
adapter driver ftdi
transport select jtag
jtag newtap wasp1 cpu -irlen 5 -expected-id 0x100001cf
target create wasp1.cpu riscv -chain-position wasp1.cpu
```

FTDI EEPROM programming may set product strings and serial numbers, but the
debug flow must not require a private protocol.

The checked-in reference config is:

```text
ftdi_debugger/openocd/wasp1_ft2232h_reference.cfg
```

It uses FT2232H VID/PID `0x0403:0x6010`, Channel A, `layout_init 0x0078
0x007b`, nTRST bit `0x0010`, nSRST bit `0x0020`, and TARGET_EN bit
`0x0040`.

## 6. Non-Goals

The stage-1 debugger does not need:

```text
USB firmware development
SWD support
trace capture
high-speed streaming trace
boundary scan tooling beyond the wasp1 JTAG chain
custom OpenOCD target driver
```

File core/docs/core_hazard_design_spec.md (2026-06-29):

# core_hazard Design Spec

## 1. Scope

`core_hazard` is a combinational helper for the planned simple in-order core
pipeline.

## 2. Editable Block Diagram

```text
editable source: core/docs/diagrams/core_hazard_block.graffle
preview export:  none
detail level:    L1
clock domains:   none; pure combinational logic
```

The diagram separates decode source inputs, execute/writeback destination
inputs, register-match comparison, forwarding selection, load-use stall
generation, and hazard-control outputs. No pipeline state is stored in this
module.

## 3. Design

The module computes nonzero register matches between decode sources and
execute/writeback destinations.

EX forwarding is selected when:

```text
decode source matches execute rd
execute writes rd
execute is not a load
```

WB forwarding is selected when:

```text
decode source matches writeback rd
writeback writes rd
EX forwarding for that source is not selected
```

Load-use stall is selected when decode uses a source register that matches an
execute-stage load destination. The stall is exposed as fetch/decode hold plus
execute bubble controls.

## 4. Target Support

The module is target-neutral combinational logic. No IC or FPGA-specific
primitive is required.

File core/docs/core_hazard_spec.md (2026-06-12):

# core_hazard Spec

## 1. Purpose

`core_hazard` detects simple in-order pipeline data hazards and selects
operand forwarding for the wasp1 core.

## 2. Functional Requirements

The module must detect dependencies from the decode-stage source registers to
the execute-stage and writeback-stage destination registers.

`x0` must never be treated as a true dependency.

Execute-stage forwarding must be selected for ALU-like results that are
available before writeback.

Writeback-stage forwarding must be selected when no execute-stage forwarding
for the same source is selected.

## 3. Load-Use Requirements

If the execute-stage instruction is a load and the decode-stage instruction
uses the same nonzero destination register, the module must assert:

```text
load_use_stall_o
fetch_stall_o
decode_stall_o
execute_bubble_o
```

Loads must not forward from execute.

## 4. Interface Requirements

Inputs describe decode, execute, and writeback pipeline slots:

```text
id_*: decode source register use
ex_*: execute destination and load status
wb_*: writeback destination
```

Outputs describe source forwarding and stall/bubble controls.

## 5. Verification Requirements

Verification must cover EX forwarding, WB forwarding, EX-over-WB priority,
load-use stalls on rs1 and rs2, x0 suppression, invalid slot gating, and
deterministic random dependency checks.

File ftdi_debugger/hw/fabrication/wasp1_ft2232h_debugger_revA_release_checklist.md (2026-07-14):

# FT2232H Debugger Rev A Manufacturing Release Checklist

## Release Disposition

```text
engineering package: PASS
fabrication release: HOLD - DO NOT ORDER
review date: 2026-07-14
```

The engineering outputs are internally consistent and reproducible.  The HOLD
is intentional: three external confirmations cannot be replaced by local DRC
or scripts.

## Automated And Local Review

| Gate | Status | Evidence |
| --- | --- | --- |
| Schematic parity | PASS | Final PCB DRC reports zero parity issues |
| PCB connectivity | PASS | Zero unconnected pads; 695 routed segments and 72 vias |
| PCB geometry | PASS | Closed 110 mm x 65 mm outline; 1.6 mm source-board thickness |
| USB routing | PASS | Pre-ESD skew 0.463216 mm; post-ESD skew 0.414214 mm; both <= 0.50 mm |
| J1 geometry | PASS | 16 signal pads, 4 plated shell slots, 2 NPTH pegs, reviewed D+/D- pad order |
| J2 geometry | PASS | 14 pins on a 2.54 mm grid with 1.0 mm drills and keyed vertical footprint |
| Gerber set | PASS | Nine X2 layers, common absolute 4.6 metric coordinates, expected polarity |
| Board profile | PASS | Four-edge closed profile, 350 mm perimeter, no output coordinates outside it |
| Drill set | PASS | 65 x 0.30 mm vias, 7 x 0.40 mm vias, 14 x 1.00 mm PTH, 4 plated slots, 2 x 0.65 mm NPTH |
| Placement output | PASS | 48 unique top-side fitted references; U2 and TP1-TP8 excluded |
| Production BOM | PASS | All 57 board references covered: 48 POP, 1 DNP, 8 PCB_ONLY |
| Assembly drawing render | PASS | Top drawing legible and unclipped; sparse mirrored bottom drawing is intentional |
| Electrical-test data | PASS | IPC-D-356 identification and USB_VBUS net records present |

## External Release Gates

| Gate | Status | Required sign-off |
| --- | --- | --- |
| Fabricator impedance review | HOLD | Fabricator stackup calculation confirms 90 ohm nominal USB D+/D- and accepted width/gap |
| Independent visual CAM review | HOLD | Second person opens Gerbers and drills in a CAM viewer and signs layer order, polarity, slots, outline, and drill alignment |
| Procurement review | HOLD | Buyer rechecks stock, lifecycle, MOQ, lead time, and exact suffixes; J2 primary had zero distributor stock at the 2026-07-14 check |
| First-article assembly | HOLD | Polarity, pin 1, connector keying, solder joints, and pre-power resistance checks signed |
| Physical bring-up | HOLD | USB enumeration, rails, VREF isolation, OpenOCD/GDB JTAG, and UART OTP smoke pass on hardware |

## Ordered-Part Controls

```text
J1: GCT USB4105-GF-A-120
J2 primary: Samtec TST-107-01-L-D
J2 approved mechanical/plating candidate: TST-107-01-G-D
U1: FTDI FT2232HL-REEL
CCORE: Murata GRM188R61A335KE15D
```

The J2 alternate is not an automatic AVL substitution. Procurement must
confirm plating and mating-cable requirements before use. Every change to J1,
J2, U4, U5, U1, CCORE, the stackup, or USB geometry requires an engineering
change review and regeneration of all manufacturing outputs.

## Sign-Off

| Role | Name | Date | Result / notes |
| --- | --- | --- | --- |
| PCB design owner |  |  |  |
| Independent CAM reviewer |  |  |  |
| Fabricator CAM engineer |  |  |  |
| Procurement |  |  |  |
| Assembly first-article reviewer |  |  |  |
| Bring-up owner |  |  |  |

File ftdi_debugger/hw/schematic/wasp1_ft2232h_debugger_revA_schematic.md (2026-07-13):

# wasp1 FT2232H Debugger Rev A Schematic Input

## 1. Purpose

This document records the Rev A schematic contract for the external wasp1 FTDI
debugger. The corresponding native KiCad 10 hierarchy is implemented under
`hw/kicad/wasp1_ft2232h_debugger_revA/`. It is not yet a PCB release.

The design goal is:

```text
one USB cable -> FT2232H Channel A JTAG + FT2232H Channel B UART
```

Channel A must work with OpenOCD's standard `ftdi` adapter driver. Channel B is
reserved for the UART console and OTP programming flow.

## 2. Schematic Page Plan

| Page | Title | Main content |
| ---: | --- | --- |
| 1 | wasp1 FT2232H Debugger Rev A | Root hierarchy and four electrical child sheets |
| 2 | USB and local power | USB-C USB2 connector, ESD, CC resistors, polyfuse, 3.3 V rail |
| 3 | FT2232H core clock and EEPROM | FT2232H, 12 MHz clock, optional EEPROM, USB D+/D-, local decoupling |
| 4 | VREF detection and level shifting | Target VREF sense, fail-safe enable gate, translators, isolated VREF LED |
| 5 | Target connector ESD and test access | Keyed target header, damping, ESD, and eight test points |

## 3. Core Parts

| Refdes | Function | Preferred part class | Design note |
| --- | --- | --- | --- |
| J1 | Host USB connector | USB-C receptacle, USB2-only | Add 5.1 kOhm pulldowns on CC1/CC2 |
| U1 | USB/JTAG/UART bridge | FT2232HL, LQFP-64 | Channel A is MPSSE JTAG; Channel B is UART |
| Y1 | FTDI reference clock | ECS-3225MVQ-120-CN-TR, 12 MHz oscillator | 3.3 V, +/-25 ppm HCMOS drives OSCI; OSCO is no-connect |
| U2 | FTDI EEPROM | 93LC56BT-I/SN, SOIC-8, optional footprint | Allows product string and serial programming |
| U3 | VREF-valid detector | TLV7041DBVR open-drain comparator | Releases VREF_VALID high above the 1.57 V nominal threshold |
| U4 | Debugger-to-target level shifter | SN74AXC8T245PWR | Drives TCK/TMS/TDI/nTRST/nSRST/UART_RXD toward target |
| U5 | Target-to-debugger level shifter | SN74AXC2T245RSWR | Receives TDO/UART_TXD from target |
| U6 | Local 3.3 V regulator | AP2112K-3.3TRG1, SOT-25 | Generates VCC_3V3 from protected USB VBUS |
| U7 | Fail-safe enable gate | SN74LVC1G00DBVR NAND | SHIFT_OE_N is low only when VREF_VALID and TARGET_EN are high |
| Q1 | VREF LED isolation | 2N7002, SOT-23 | Drives D2 without loading the comparator output |
| J2 | Target connector | Keyed 2x7 header | Pinout follows `docs/ftdi_debugger_pinout.md` |

## 4. Voltage And Enable Policy

The debugger has two IO domains:

| Domain | Nominal rail | Owner | Notes |
| --- | --- | --- | --- |
| `VCC_3V3` | 3.3 V | debugger board | FT2232H local IO side and LEDs |
| `VREF` | 1.8 V to 3.3 V | target board | target-facing level-shifter side |

Target-facing outputs must be high-Z when `VREF_VALID=0` or `TARGET_EN=0`.
ADBUS6 is pulled down so the board remains isolated while FT2232H is in its
power-up UART mode. OpenOCD changes ADBUS6 to a high output through
`layout_init 0x0078 0x007b`. U7 generates active-low `SHIFT_OE_N`; a pull-up
keeps both translator OEs disabled if U7 is unpowered.

The debugger must not back-power the target through JTAG, reset, UART, ESD
parts, pull-ups, or indicator circuits.

The VREF-valid LED is not connected directly across `VREF_VALID`. Q1 senses the
comparator output at its gate and sinks D2 current from `VCC_3V3`, preserving
the logic-high margin at U7. Unused U4 A7/A8 inputs each have a 10 kOhm
pulldown; their bidirectional pins are not hard-shorted to ground.

## 5. FT2232H Channel A Mapping

| FT2232H signal | OpenOCD bit | Board net | Target signal | Direction |
| --- | ---: | --- | --- | --- |
| ADBUS0 | `0x0001` | `FT_A_TCK` | `TCK` | debugger to target |
| ADBUS1 | `0x0002` | `FT_A_TDI` | `TDI` | debugger to target |
| ADBUS2 | `0x0004` | `FT_A_TDO` | `TDO` | target to debugger |
| ADBUS3 | `0x0008` | `FT_A_TMS` | `TMS` | debugger to target |
| ADBUS4 | `0x0010` | `FT_A_NTRST` | `nTRST` | debugger to target |
| ADBUS5 | `0x0020` | `FT_A_NSRST` | `nSRST` | debugger to target |
| ADBUS6 | `0x0040` | `FT_TARGET_EN` | board enable gate | local safety control |

OpenOCD must continue to use:

```text
ftdi layout_init 0x0078 0x007b
ftdi layout_signal nTRST -data 0x0010 -oe 0x0010
ftdi layout_signal nSRST -data 0x0020 -oe 0x0020
```

## 6. FT2232H Channel B Mapping

| FT2232H signal | Board net | Target signal | Direction |
| --- | --- | --- | --- |
| BDBUS0 | `FT_B_TXD` | `UART_RXD` | debugger to target |
| BDBUS1 | `FT_B_RXD` | `UART_TXD` | target to debugger |

Channel B must enumerate as a standard FTDI serial port. No custom USB firmware
is allowed for Rev A.

## 7. Target Connector Pinout

| J2 pin | Net | Requirement |
| ---: | --- | --- |
| 1 | `VREF` | Target IO reference input |
| 2 | `GND` | Return |
| 3 | `TCK` | Series damping footprint near driver |
| 4 | `GND` | Return |
| 5 | `TMS` | Series damping footprint near driver |
| 6 | `GND` | Return |
| 7 | `TDI` | Series damping footprint near driver |
| 8 | `TDO` | No debugger-side pull that fights target output |
| 9 | `nTRST` | Active-low, target-side pull-up recommended |
| 10 | `nSRST` | Active-low, target-side pull-up recommended |
| 11 | `UART_TXD` | Target TX into debugger |
| 12 | `UART_RXD` | Debugger TX into target |
| 13 | `GND` | Return |
| 14 | `NC_KEY` | Key or no-connect |

## 8. PCB Constraints For The Later Layout Step

```text
USB D+/D-: route as controlled differential pair according to board stackup
TCK/TMS/TDI/nTRST/nSRST/UART_RXD: place series resistors near U4 outputs
TDO/UART_TXD: avoid pull devices that load target outputs
VREF: keep as sense/level-shifter rail, not a board power source
TARGET_EN: 100 kOhm pulldown at U1/enable-gate input
SHIFT_OE_N: 100 kOhm pullup to VCC_3V3; route to U4/U5 active-low OE pins
ESD: place close to USB and target connector entry points
Test points: expose VCC_3V3, VCORE, VREF, VREF_VALID, TARGET_EN,
SHIFT_OE_N, TCK, TDO, GND
```

## 9. Release Gate

The native schematic must pass KiCad ERC with no errors or warnings before a
PCB is routed, and it must be checked against:

```text
docs/ftdi_debugger_pinout.md
openocd/wasp1_ft2232h_reference.cfg
hw/netlist/wasp1_ft2232h_debugger_revA_nets.csv
hw/bom/wasp1_ft2232h_debugger_revA_bom.csv
```

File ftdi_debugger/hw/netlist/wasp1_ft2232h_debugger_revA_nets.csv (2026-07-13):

page | net | source | destination | requirement
USB | VCC_USB | J1 VBUS | F1 input | USB bus power enters through resettable protection
USB | USB_DP | J1 D+ | ESD1 and U1 USBDP | USB D+ protected before FT2232H
USB | USB_DM | J1 D- | ESD1 and U1 USBDM | USB D- protected before FT2232H
USB | CC1 | J1 CC1 | RCC1 to GND | USB-C device pulldown
USB | CC2 | J1 CC2 | RCC2 to GND | USB-C device pulldown
POWER | VCC_3V3 | U6 output | U1 VCCIOA/VCCIOB/VPHY/VPLL/VREGIN; U3/U4/U5/U7/Y1 | local debugger logic IO analog and clock rail
POWER | VCORE | U1 VREGOUT | U1 VCORE pins and CCORE | internal 1.8 V core rail with at least 3.3 uF local capacitance
POWER | GND | board ground | J1/J2/U1/U4/U5 common reference | common return
CLOCK | FT_CLK12 | Y1 output | U1 OSCI | 12 MHz 3.3 V oscillator within plus or minus 30 ppm
EEPROM | EECS | U1 EECS | U2 CS | optional FTDI EEPROM chip select
EEPROM | EESK | U1 EESK | U2 SK | optional FTDI EEPROM clock
EEPROM | EEDATA | U1 EEDATA | U2 DI/DO | optional FTDI EEPROM data
VREF | VREF | J2 pin 1 | U3 input/U4 B-side/U5 B-side | target IO reference only
VREF | VREF_VALID | U3 output | U7 input A and Q1 gate | 10 kOhm pullup; high only above the nominal 1.57 V threshold
CONTROL | FT_TARGET_EN | U1 ADBUS6 | U7 input B | OpenOCD bit 0x0040 with 100 kOhm pulldown
CONTROL | SHIFT_OE_N | U7 output | U4 OE_N/U5 OE_N | low only when VREF_VALID and FT_TARGET_EN are both high
JTAG | FT_A_TCK | U1 ADBUS0 | U4 A1 | OpenOCD bit 0x0001 TCK source
JTAG | TCK | U4 B1 | J2 pin 3 | target TCK with series damping footprint
JTAG | FT_A_TDI | U1 ADBUS1 | U4 A2 | OpenOCD bit 0x0002 TDI source
JTAG | TDI | U4 B2 | J2 pin 7 | target TDI with series damping footprint
JTAG | TDO | J2 pin 8 | U5 B1 | target TDO input path
JTAG | FT_A_TDO | U5 A1 | U1 ADBUS2 | OpenOCD bit 0x0004 TDO input
JTAG | FT_A_TMS | U1 ADBUS3 | U4 A3 | OpenOCD bit 0x0008 TMS source
JTAG | TMS | U4 B3 | J2 pin 5 | target TMS with series damping footprint
JTAG | FT_A_NTRST | U1 ADBUS4 | U4 A4 | OpenOCD bit 0x0010 nTRST source
JTAG | nTRST | U4 B4 | J2 pin 9 | target TAP reset active low
JTAG | FT_A_NSRST | U1 ADBUS5 | U4 A5 | OpenOCD bit 0x0020 nSRST source
JTAG | nSRST | U4 B5 | J2 pin 10 | target system reset active low
UART | FT_B_TXD | U1 BDBUS0 | U4 A6 | FT2232H Channel B UART TX
UART | UART_RXD | U4 B6 | J2 pin 12 | target UART RXD
UART | UART_TXD | J2 pin 11 | U5 B2 | target UART TXD
UART | FT_B_RXD | U5 A2 | U1 BDBUS1 | FT2232H Channel B UART RX
INDICATOR | LED_USB | VCC_3V3 | D1/RLED1 | USB/local power indicator
INDICATOR | LED_VREF | VCC_3V3 | RLED2/D2/Q1 to GND | Q1 gate senses VREF_VALID without loading the comparator output
UNUSED | U4_A7_UNUSED | U4 A7 | RU4_A7 to GND | defined low input on unused translator channel seven
UNUSED | U4_A8_UNUSED | U4 A8 | RU4_A8 to GND | defined low input on unused translator channel eight
TEST | TP_VCC_3V3 | VCC_3V3 | TP1 | local debugger rail measurement point
TEST | TP_VCORE | VCORE | TP2 | FT2232H core rail measurement point
TEST | TP_VREF | VREF | TP3 | target reference rail measurement point
TEST | TP_VREF_VALID | VREF_VALID | TP4 | comparator output measurement point
TEST | TP_TARGET_EN | FT_TARGET_EN | TP5 | host ownership gate measurement point
TEST | TP_SHIFT_OE_N | SHIFT_OE_N | TP6 | active-low translator enable measurement point
TEST | TP_TCK | TCK | TP7 | JTAG clock measurement point
TEST | TP_TDO | TDO | TP8 | JTAG data-out measurement point

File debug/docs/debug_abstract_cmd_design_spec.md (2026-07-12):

# debug_abstract_cmd Design Spec

## 1. Scope

The block decodes and executes the RV32 GPR subset of Access Register commands,
physical Access Memory commands, local CSR reads for debugger discovery, the
minimal `dcsr.step` write used for single-step, and two RV32 `mcontrol`
exact-address trigger configuration slots. Each slot exports independent
execute, load, and store qualifiers. It now sequences Access Register
`postexec` through `debug_progbuf_exec`. FPR access, virtual memory access, and
System Bus Access remain explicitly unsupported at this boundary.

## 2. Editable FSM/Block Diagram

editable source: `debug/docs/diagrams/debug_abstract_cmd_fsm.graffle`
preview export: none
detail level: L3
clock domains: `clk_i/rst_ni` for every `SEQ` block

The editable OmniGraffle diagram separates the command/data interface, decode
policy, FSM state, request registers, completion registers, Access Memory
request registers, trigger CSR registers, register/memory interfaces, and
DMI-register completion pulses into explicit `IF`, `COMB`, and `SEQ`
timing-class blocks. The historical PNG
`debug/docs/images/debug_abstract_cmd_fsm.png` remains as a reference export.

## 3. FSM

| State | Function |
| --- | --- |
| `IDLE` | Decode a one-cycle command pulse |
| `ISSUE` | Hold decoded GPR or memory request until accepted |
| `WAIT` | Wait for `debug_reg_access` or halted-memory response |
| `POSTEXEC_START` | Pulse the Program Buffer executor start input |
| `POSTEXEC_WAIT` | Hold abstract busy until executor completion |
| `COMPLETE` | Pulse cmderr, successful read data0 update, or postincrement data1 update |

```text
IDLE -> ISSUE:
  command_valid && dmactive && encoding_supported && hart_halted &&
  transfer && downstream_GPR_or_memory_transfer

IDLE -> COMPLETE:
  command_valid && dmactive &&
  (unsupported || !hart_halted || !transfer || supported_local_CSR_access)

ISSUE -> WAIT:
  (reg_cmd_valid && reg_cmd_ready) || (mem_cmd_valid && mem_cmd_ready)

WAIT -> POSTEXEC_START:
  reg_rsp_fire && !reg_rsp_error && captured_postexec

IDLE -> POSTEXEC_START:
  supported halted Access Register command with postexec and
  (transfer=0 || local CSR transfer)

POSTEXEC_START -> POSTEXEC_WAIT:
  unconditional one-cycle start pulse

POSTEXEC_WAIT -> COMPLETE:
  progbuf_done, capturing progbuf_error

WAIT -> COMPLETE:
  memory response, register error, or register success without postexec

ISSUE/WAIT/POSTEXEC_START/POSTEXEC_WAIT -> COMPLETE:
  !hart_halted, with CMDERR_HALT_RESUME and reg_flush/mem_flush

ISSUE/WAIT -> IDLE:
  !dmactive, with silent abort and reg_flush

COMPLETE -> IDLE:
  unconditional after one reporting cycle
```

## 4. Decoder

The raw `command_i` field extraction and support predicate are combinational.
Only an Access Register transfer command requires `aarsize=2` and either a GPR
register range, one of the supported local CSR reads, the supported `dcsr.step`
write, or a supported trigger CSR access. Access Memory commands use the
Debug Spec `cmdtype=2` encoding, physical addressing, byte/half/word sizes, and
optional postincrement. Hart halted policy is checked separately and therefore
still applies to transfer-disabled no-op commands.

`postexec_q` captures the Access Register postexec bit. Access Memory does not
use this path. The state machine never starts Program Buffer execution after a
failed GPR transfer.

## 5. Request Registers

On a command pulse, the block captures:

```text
reg_write_q = command.write
reg_addr_q  = command.regno[4:0]
reg_wdata_q = data0_i
mem_write_q = command.write
mem_addr_q  = data1_i
mem_size_q  = decoded byte/half/word size
mem_wdata_q/mem_wstrb_q = lane-aligned data0_i
```

These registers drive the entire downstream request and therefore hold stable
under request backpressure. Access Memory postincrement state is captured in
the same command-accept cycle and reported through `data1_we_o` only on a
successful completion.

## 6. Completion Registers

`completion_error_q` stores the mapped `cmderr`. A successful GPR read captures
`read_result_q` from `debug_reg_access` and sets `read_result_valid_q`. A
successful supported CSR read sets the same completion registers locally during
command capture. The `COMPLETE` state converts these registers into one-cycle
pulses for `debug_dmi_regs`.

Read results remain registered across `POSTEXEC_START/WAIT`. They are emitted
only when executor completion has `CMDERR_NONE`; otherwise `completion_error_q`
suppresses data0 and reports the Program Buffer failure.

Successful GPR writes, supported `dcsr.step` writes, trigger CSR writes,
transfer-disabled commands, and unsupported CSR writes report no data0 pulse
because no read value is produced. For the supported CSR probe set, `misa` is
fixed, `dcsr` combines the fixed RV32/M-mode discovery value with
`hart_dcsr_cause_i` and the latched step bit, and `dpc` is forwarded from
`hart_dpc_i`, which is driven by the core-side Debug PC capture logic.

`dcsr_step_q` is local sequential state. It resets to zero and clears when
`dmactive_i` is deasserted. A supported Access Register write to `dcsr` updates
only this bit from `data0_i[2]`; other DCSR fields remain fixed readback
metadata in this stage.

`trigger_select_q`, `trigger_tdata1_q[2]`, and `trigger_tdata2_q[2]` are local
sequential state. Reset and DM deactivation select trigger 0, return every
`tdata1` slot to a disabled RV32 `mcontrol` image, and clear every `tdata2`
slot. `tselect` writes select slot 0 or 1, while out-of-range writes clamp to
the last legal slot. The combinational WARL filter accepts only `type=2`,
equality match, M-mode execute/load/store qualifiers, and `action=debug mode`.
A shared per-slot common-enable term checks type, action, equality match, and
M-mode. Execute, load, and store outputs then AND that term with their
respective `tdata1` access bit. The compare addresses are the selected slots'
registered `tdata2` values; load and store share one data-address output.

## 7. Target Behavior

The block is target-neutral synthesizable logic and includes
`wasp1_target_defs.svh`. Target macros do not change command semantics.

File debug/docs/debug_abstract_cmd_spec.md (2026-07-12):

# debug_abstract_cmd Spec

## 1. Purpose

`debug_abstract_cmd` decodes RISC-V Debug Spec 0.13.x abstract commands,
controls the verified `debug_reg_access` transport, drives halted-core memory
accesses, and provides the CSR probes needed by OpenOCD/GDB. The implementation
supports RV32 integer GPR Access Register commands, physical Access Memory
byte/half/word transfers through the halted core, local reads of `misa`,
`mstatus`, `dcsr`, and the core-captured `dpc`, plus writes to the `dcsr.step`
bit used for single-step. It also implements two RV32 `mcontrol` exact-address
trigger slots with independently selectable execute, load, and store modes.

## 2. Supported Access Register Command

| Field | Requirement |
| --- | --- |
| `cmdtype[31:24]` | `0`: Access Register |
| reserved bit 23 | zero |
| `aarsize[22:20]` | `2`: 32-bit, when transfer is set |
| `aarpostincrement[19]` | zero |
| `postexec[18]` | optional Program Buffer execution after a successful/local transfer |
| `transfer[17]` | zero for no-op or one for GPR/CSR transfer |
| `write[16]` | zero reads; one writes GPR, `dcsr.step`, or supported trigger CSRs |
| `regno[15:0]` | `0x1000..0x101F` for x0-x31, read-only `0x0301` `misa`, read-only `0x0300` `mstatus`, read/write-step `0x07B0` `dcsr`, read-only `0x07B1` `dpc`, trigger CSRs `0x07A0..0x07A5`, or OpenOCD probe CSRs |

A command with `transfer=0`, supported command type, and no unsupported option
is a successful no-op when `postexec=0`; with `postexec=1` it starts Program
Buffer execution directly. Size, register number, and write direction are ignored.
The selected hart must still be halted for every accepted Access Register
command, including this transfer-disabled no-op.

CSR reads complete locally for the supported probe set. Unimplemented CSR
probes complete as zero so OpenOCD does not disable abstract CSR access after
probing optional status CSRs. CSR writes complete as no-ops except for
`dcsr.step`, `tselect`, `tdata1`, and `tdata2`.

```text
misa      -> 0x40000100, RV32 + I extension
mstatus   -> 0x00000000, machine mode baseline with no writable status bits yet
dcsr read -> 0x40000003 | hart_dcsr_cause_i<<6, with bit 2 reflecting step
dcsr write-> updates only bit 2, DCSR.step; other written bits are ignored
dpc       -> hart_dpc_i, the core-captured Debug PC/resume PC
```

The trigger CSR behavior is intentionally minimal and WARL-filtered:

```text
tselect  -> selects trigger slot 0 or 1; out-of-range writes clamp to slot 1
tinfo    -> 0x00000004, advertising RV32 mcontrol support
tdata1   -> selected slot's RV32 mcontrol type=2 image; legal fields are dmode, action, match, m, execute, load, store
tdata2   -> selected slot's exact-address compare value
tdata3   -> zero
tcontrol -> zero
```

The enabled trigger modes are `mcontrol` execute, load, and store address
equality in M-mode with `action=1` (enter Debug Mode). A slot may enable any
combination of those three access classes against its single `tdata2` address.
Unsupported `type` writes return a disabled `mcontrol` image for the selected
slot, and unsupported actions are cleared so no comparator output is enabled.

This module provides filtered per-slot execute/load/store enables and compare
addresses. The integrated core LSU consumes those outputs for precise trigger
action, but that downstream behavior remains outside this module-level
contract and is covered by the core datapath verification report.

## 3. Supported Access Memory Command

| Field | Requirement |
| --- | --- |
| `cmdtype[31:24]` | `2`: Access Memory |
| `aamvirtual[23]` | zero; physical memory only |
| `aamsize[22:20]` | `0`, `1`, or `2`: byte, halfword, or word |
| `aampostincrement[19]` | optional address increment after success |
| `write[16]` | zero reads into data0; one writes data0 to memory |
| `target-specific[15:14]` | ignored by this stage and expected zero from OpenOCD |

`data1` supplies the byte address. Byte and halfword writes lane-align `data0`
and generate byte strobes. Byte and halfword reads extract the selected lane
from the 32-bit halted-core response and zero-extend into `data0`.

## 4. Error Mapping

```text
unsupported command type/field/register/size -> CMDERR_NOTSUP
hart not halted before or during transfer    -> CMDERR_HALT_RESUME
downstream register-access error             -> CMDERR_EXCEPTION
downstream memory-access error               -> CMDERR_BUS
Program Buffer/core execution error           -> executor-supplied cmderr
```

DM deactivation aborts silently because `debug_dmi_regs` resets abstract state
when `dmactive` clears.

## 5. Data Register Behavior

For writes, `data0_i` is captured with the command and forwarded as GPR write
data. Successful writes do not change data0.

For GPR reads, successful downstream data generates one `data0_we_o` pulse.
For local CSR reads, the controller generates the same data0 write pulse
without issuing a downstream register command. A supported `dcsr.step` write
updates the local step bit and does not update data0. Failed, unsupported,
aborted, GPR write, and no-op commands must not update data0.

For Access Register `postexec=1`, a GPR transfer must complete successfully
before Program Buffer start. Local CSR transfer results are captured before
start. Any transfer error suppresses Program Buffer execution. Successful read
data is reported only after Program Buffer success; an executor error
suppresses the data0 update and becomes the command cmderr.

For Access Memory reads, successful memory data generates one `data0_we_o`
pulse with lane-extracted data. For Access Memory writes, `data0_i` is captured
with the command and forwarded to memory. When postincrement is set, a
successful memory command generates one `data1_we_o` pulse with the address
advanced by the access size.

## 6. Busy and Handshake Requirements

`busy_o` asserts from command capture through a one-cycle completion state.
Decoded register and memory commands use ready/valid request and response
channels. Request fields and completion data must remain registered and stable.

`command_valid_i` is accepted only in IDLE. A defensive pulse while busy is
ignored; normal integration prevents it because `debug_dmi_regs` rejects a
command write while `abstractcs.busy` is set.

`reg_flush_o` and `mem_flush_o` assert on DM deactivation or loss of halted
state while a downstream transaction is active.

`progbuf_start_o` pulses for one registered state. `busy_o` remains asserted
through `progbuf_done_i` and the final completion cycle. Loss of halted state
during postexec maps to `CMDERR_HALT_RESUME`; DM deactivation aborts silently.

## 7. Reset and Targets

All state uses `clk_i` with asynchronous active-low `rst_ni`. Behavior must be
identical for generic simulation, IC, and Xilinx Virtex-7 FPGA targets.

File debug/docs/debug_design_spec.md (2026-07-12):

# debug Design Spec

## 1. Scope

`debug` structurally integrates the verified stage-1 Debug Module leaves:

```text
debug_dmi_regs
debug_halt_ctrl
debug_abstract_cmd
debug_reg_access
debug_progbuf_exec
```

`debug_progbuf` storage is owned by `debug_dmi_regs`, which routes four DMI
words to `debug_progbuf_exec`. Access Register postexec keeps abstract busy,
sequences words to the core execution channel, consumes EBREAK locally, and
returns executor cmderr. The wrapper advertises `abstractcs.progbufsize=4`.

The wrapper adds no new architectural register state. Its local logic consists
of explicit channel wiring, top-level output assignment, and an internal
abstract-access `debug_if` instance used to satisfy leaf modport ownership.

Editable source: `debug/docs/diagrams/debug_block.graffle`
Generator: `debug/dv/generate_debug_block_diagram.py`
Detail level: L3; clock domain: `clk_i/rst_ni` on every SEQ block.

## 2. Block Diagram

```text
       IF DMI from JTAG DTM wrapper
              |
              v
   +------------------------+
   | SEQ clk_i rst_ni       |
   | debug_dmi_regs         |
   | DMI regs/response slot |
   +-----+-------------+----+
         | halt/resume    | command/data0/cmderr    | progbuf0..3
         v                v                         v
+----------------+  +-----------------------+  +-----------------------+
| SEQ clk_i      |  | SEQ clk_i rst_ni      |  | SEQ clk_i rst_ni     |
| debug_halt_ctrl|  | debug_abstract_cmd    |  | debug_progbuf_exec   |
| hart request   |  | transfer/postexec FSM |->| ordered instruction  |
| sticky status  |  +-----------+-----------+  | execution FSM        |
+-------+--------+              |              +-----------+-----------+
        |                       | decoded GPR              |
        v                       v                          v
 IF core_debug           +----------------------+   IF core_debug execute
 halt/resume/status      | SEQ clk_i rst_ni     |   request/response
                         | debug_reg_access     |
                         | GPR ready/valid FSM  |
                         +----------+-----------+
                                    |
                                    v
                            IF core_debug GPR
```

Timing-class labels:

```text
IF   external or structured interface connection
SEQ  sequential leaf or state, clk=clk_i, rst=rst_ni
```

## 3. Internal Connectivity

`debug_dmi_regs` owns the architectural DMI register contract. Its outputs
drive:

```text
dmactive/resumereq/haltreq/ackhavereset -> debug_halt_ctrl
command_valid/command/data0             -> debug_abstract_cmd
```

`debug_halt_ctrl` observes `core_debug.halted`, `core_debug.running`, and
`hart_reset_event_i`. It drives:

```text
core_debug.halt_req
core_debug.resume_req
hart_halted/hart_running/hart_resumeack/hart_havereset back to debug_dmi_regs
```

`debug_abstract_cmd` decodes the command register and drives one decoded GPR
transaction into `debug_reg_access`. It also consumes `core_debug.dpc` for
abstract CSR reads of `dpc`, consumes `core_debug.dcsr_cause` for `dcsr`
readback, owns the local `dcsr.step` bit and two trigger CSR images, and
returns successful read data or cmderr updates to `debug_dmi_regs`.

For Access Register `postexec`, `debug_abstract_cmd` pulses
`debug_progbuf_exec.start_i` only after any required transfer succeeds. The
executor reads the parallel Program Buffer image, issues one word at a time on
`core_debug.exec_req_*`, waits for `core_debug.exec_rsp_*`, and consumes an
explicit EBREAK locally. Completion error returns to the same abstract command
before `abstract_busy` clears.

Single-step is a small wrapper-level combinational path:

```text
core_debug.step_req = core_resume_req && dcsr_step
```

This means a normal resume request remains unchanged while `dcsr.step=0`.
When `dcsr.step=1`, the core-side `core_debug_ctrl` receives both resume and
step for one resume transaction and re-enters halted state after one
retirement.

The trigger output path is wrapper-level combinational after the trigger CSR
registers:

```text
core_debug.trigger_execute_valid[slot] = selected trigger slot enables legal mcontrol execute match
core_debug.trigger_execute_addr[slot]  = selected trigger slot tdata2 compare address
core_debug.trigger_load_valid[slot]    = selected trigger slot enables legal mcontrol load match
core_debug.trigger_store_valid[slot]   = selected trigger slot enables legal mcontrol store match
core_debug.trigger_data_addr[slot]     = selected trigger slot tdata2 compare address
```

The core performs ID-stage PC compares for execute triggers and EX-stage
effective-address compares for load/store triggers. A matched architectural
memory operation is blocked before request issue, retirement, alignment fault,
or response fault; the core enters Debug Mode with the matched PC in DPC and
reports the trigger DCSR cause through `core_debug.dcsr_cause`. The core
datapath verification report owns coverage of that downstream behavior.

`debug_reg_access` uses an internal `debug_if` instance with the `dm_gpr`
modport. The wrapper explicitly bridges only GPR request/response signals to
the full `core_debug` top port. This avoids giving the GPR sequencer ownership
of halt/resume/step controls.

## 4. Sequential State

The top wrapper has no named FSM. Sequential behavior is inherited from:

| Leaf | Sequential role |
| --- | --- |
| `debug_dmi_regs` | DMI response slot, dmcontrol, data0, command, cmderr |
| `debug_halt_ctrl` | Halt/resume transaction FSM, resumeack/havereset sticky bits |
| `debug_abstract_cmd` | Abstract command issue/wait/complete FSM |
| `debug_reg_access` | Core GPR request/wait/local-response/drop-response FSM |
| `debug_progbuf_exec` | Program Buffer check/issue/wait/complete FSM |

The wrapper-level state diagram is therefore the leaf FSM composition rather
than a new independent machine.

## 5. Reset and Priority

All instantiated leaves share `clk_i/rst_ni`. Asserting reset returns DMI
transport, hart control, abstract command, and GPR access state to each leaf's
documented reset value. `hart_reset_event_i` is synchronous and only affects the
halt-control sticky status and outstanding halt/resume transaction.

## 6. Target Behavior

Target macros are included through child RTL and do not alter the wrapper
connectivity or the DMI/core-debug behavioral contract.

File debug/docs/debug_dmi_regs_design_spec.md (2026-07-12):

# debug_dmi_regs Design Spec

## 1. Scope

`debug_dmi_regs` is the first independently verified Debug Module leaf. It does
not include the JTAG TAP, DTM scan registers, abstract command executor, or core
Debug Mode implementation.

## 2. Editable Register-Transfer Diagram

editable source: `debug/docs/diagrams/debug_dmi_regs_block.graffle`
Program Buffer extension generator: `debug/dv/generate_debug_dmi_regs_diagram.py`
preview export: none
detail level: L3
clock domains: `clk_i/rst_ni` for every `SEQ` block

The editable OmniGraffle diagram separates DTM request/response interfaces,
operation/address decode, the one-entry response slot, dmcontrol register bank,
abstract register bank, Program Buffer storage, hart request gating,
abstract-executor interface, and read-image mux into explicit `IF`, `COMB`, and
`SEQ` timing-class blocks. No block combines sequential and combinational logic.

The historical PNG `debug/docs/images/debug_dmi_regs_state.png` remains as a
reference export.

## 3. Response Slot

`rsp_valid_q`, `rsp_resp_q`, and `rsp_data_q` form a one-entry response buffer.

```text
req_ready = !rsp_valid_q || rsp_ready

Reset:
  rsp_valid_q = 0
  rsp_resp_q  = SUCCESS
  rsp_data_q  = 0

On request handshake:
  rsp_valid_q = 1
  rsp_resp_q  = SUCCESS or FAILED from current decode
  rsp_data_q  = read mux data for READ, otherwise zero

On response handshake without replacement request:
  rsp_valid_q = 0

While rsp_valid_q && !rsp_ready:
  response state holds and req_ready is zero
```

## 4. Control State

`dmactive_q`, `ndmreset_q`, `haltreq_q`, `resumereq_q`, and `hartsel_q` are
separate registers. Output gating is combinational:

```text
selected_hart_exists = (hartsel_q == 0)
haltreq_o   = dmactive_q && selected_hart_exists && haltreq_q
resumereq_o = dmactive_q && selected_hart_exists && resumereq_q
ndmreset_o  = dmactive_q && ndmreset_q
```

Runtime update priority is:

```text
1. asynchronous rst_ni clear
2. accepted dmcontrol write with dmactive=0 clears DM state
3. accepted active dmcontrol write updates level controls and hartsel
4. hart_resumeack_i clears resumereq when no same-edge write sets it
5. otherwise hold
```

Activation from inactive state changes only `dmactive_q`. This makes debugger
initialization deterministic. Within an active write, `haltreq=1` clears and
overrides `resumereq`; otherwise a written resume request is held until ack.

## 5. Abstract State

`command_q`, `data0_q`, `data1_q`, and `cmderr_q` implement the abstract
register state. `debug_progbuf` owns four additional 32-bit instruction words.
`abstract_busy_i` remains owned by the command executor.

```text
command write && !busy && dmactive:
  command_q       <- DMI write data
  command_valid_o <- 1 for one cycle

command write && busy:
  command ignored
  cmderr_q <- BUSY only when cmderr_q was NONE

data0/data1/progbuf read or write && busy:
  cmderr_q <- BUSY only when cmderr_q was NONE
  writes do not modify payload storage

progbuf write && !busy && dmactive:
  selected word <- DMI write data

reset or accepted dmactive clear:
  all progbuf words <- 0

executor completion:
  data0_we_i            -> data0_q <- data0_wdata_i
  command_error_valid_i -> set first nonzero cmderr

abstractcs write:
  cmderr_q <- cmderr_q & ~write_data[10:8]
```

## 6. Read Images

`dmcontrol`, `dmstatus`, and `abstractcs` are built in independent combinational
blocks. A final read mux selects one image from the current request address.
The DMI response slot samples that image on the request handshake edge.

The Program Buffer read index is `dmi.req_addr - DMI_ADDR_PROGBUF0`. The same
index drives the storage leaf read port and the accepted-write port. The full
parallel array is exported without another register stage.

`abstractcs.progbufsize` is the constant four and `datacount` is two.
`abstractauto` participates in known-address decode, reads as zero, and has no
write side effect; this is the explicit no-autoexec WARL implementation.

## 7. No Explicit FSM

There is no encoded FSM. The sequential behavior is represented by the
response-valid slot and independent control/abstract register banks. The L3
PNG therefore shows detailed register-transfer conditions, reset paths, output
gating, and update priority instead of inventing artificial states.

## 8. Target Selection

The module includes `wasp1_target_defs.svh` and uses target-neutral standard-cell
style logic. Target macros do not alter DMI addresses, register fields, status,
or handshake behavior.

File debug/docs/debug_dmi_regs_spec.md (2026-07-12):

# debug_dmi_regs Spec

## 1. Purpose

`debug_dmi_regs` implements the first-stage RISC-V Debug Module register set
required for hart discovery, halt/resume control, abstract GPR access, and
halted-core abstract memory access.
The target behavior is RISC-V External Debug Specification 0.13.x and eventual
OpenOCD/GDB interoperability.

## 2. Implemented DMI Registers

| Address | Register | Access | Required behavior |
| ---: | --- | --- | --- |
| `0x04` | `data0` | R/W | 32-bit abstract data register 0, used as transfer data |
| `0x05` | `data1` | R/W | 32-bit abstract data register 1, used as Access Memory address |
| `0x10` | `dmcontrol` | R/W | DM activation, hart select, halt/resume, reset control |
| `0x11` | `dmstatus` | R | Version/authentication and selected-hart state |
| `0x12` | `hartinfo` | R | Zero: no hart-local data window or scratch registers |
| `0x16` | `abstractcs` | R/W1C | Two data registers, executor busy, sticky `cmderr` |
| `0x17` | `command` | R/W | Accepted command value and one-cycle executor pulse |
| `0x18` | `abstractauto` | R/W WARL | Reads zero; writes succeed but autoexec remains disabled |
| `0x20` | `progbuf0` | R/W | Program Buffer instruction word 0 |
| `0x21` | `progbuf1` | R/W | Program Buffer instruction word 1 |
| `0x22` | `progbuf2` | R/W | Program Buffer instruction word 2 |
| `0x23` | `progbuf3` | R/W | Program Buffer instruction word 3 |

Writes to defined read-only registers must succeed without changing state.
Unsupported addresses and reserved DMI operations must return `FAILED`.

## 3. Single-Hart Contract

Hart 0 is the only implemented hart. `hartsel=0` selects it. Any nonzero
20-bit `hartsel` value reports `anynonexistent=allnonexistent=1` and suppresses
halt, resume, and reset-acknowledge outputs.

For hart 0, each `any*`/`all*` status pair has the same value. The hart supplies
`halted`, `running`, `resumeack`, and `havereset` status inputs.

## 4. Control Requirements

`dmactive` resets low. When inactive, a write that sets `dmactive` must ignore
all other fields in the same write. Clearing `dmactive` resets all Debug Module
control and abstract-command state, but the DMI transport remains responsive.

`haltreq` and `ndmreset` are level outputs. `resumereq` remains asserted until
the selected hart asserts `hart_resumeack_i`. `ackhavereset_o` is a one-cycle
pulse caused by a valid selected-hart acknowledge write. If halt and resume are
requested in the same write, halt takes priority and the resume request clears.

Unsupported `hartreset`, `hasel`, and reset-halt request controls read as zero
and have no side effect.

## 5. Abstract Command Requirements

`abstractcs.datacount` is 2 and `progbufsize` is 4. A command write while the
executor is idle records the command and pulses `command_valid_o` for one
cycle. A command write while busy is ignored and sets sticky `cmderr=BUSY` if
no earlier error exists. Any read or write access to `data0`, `data1`, or
`progbuf0..3` while busy also sets sticky `cmderr=BUSY`; writes are ignored.

Each accepted idle `progbuf0..3` write updates exactly one 32-bit word. Reads
return the selected current word. Reset and clearing `dmactive` clear all four
words. `progbuf_words_o` provides the full stable array to the integrated
Program Buffer executor.

`abstractauto` is implemented as a WARL-zero compatibility register. OpenOCD
may write zero after Program Buffer discovery; all reads return zero and no
data/progbuf autoexec trigger is implemented.

Executor errors set sticky `cmderr` only while it is zero. Software clears
selected `cmderr` bits by writing ones to `abstractcs.cmderr`. Executor result
writes update `data0` or `data1` independently of DMI response backpressure.

## 6. DMI Transport Requirements

The block supports one outstanding registered response. It must hold response
status and data stable under backpressure. A new request may be accepted in the
same cycle that the current response is consumed.

## 7. Reset and Implementation Targets

All state uses `clk_i` with asynchronous active-low `rst_ni`. The RTL must be
synthesizable and behaviorally identical for generic simulation, IC, and
Xilinx Virtex-7 FPGA target macros.

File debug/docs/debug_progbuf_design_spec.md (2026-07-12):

# debug_progbuf Design Spec

## 1. Scope

The block is a deliberately small four-word flop array. It separates reusable
Program Buffer storage from DMI routing, abstract-command sequencing, and core
instruction execution.

## 2. Editable Register-Transfer Diagram

editable source: `debug/docs/diagrams/debug_progbuf_block.graffle`
preview export: none
detail level: L1
clock domain: `clk_i/rst_ni`

The OmniGraffle diagram separates storage-control inputs, combinational index
selection, the sequential word array, and DMI/executor outputs into
distinct `IF`, `COMB`, and `SEQ` blocks. The visible 5 pt grid, native line
segments, V-shaped arrows, endpoint alignment, and element spacing pass the
repository coordinate/overlap audit.

## 3. Sequential Storage

```text
logic [3:0][31:0] words_q
```

The four words are implemented as ordinary flops because the storage is only
128 bits and requires whole-array clear plus a full parallel executor view.
Inferring a RAM would complicate those semantics without a useful area benefit.

The single `always_ff` block implements:

```text
if !rst_ni:          words_q <= 0
else if clear_i:     words_q <= 0
else if write_valid: words_q[write_index_i] <= write_data_i
else:                hold
```

No encoded FSM exists. The meaningful state is the four-word register array,
and the diagram therefore shows register-transfer priority instead of
inventing states.

## 4. Combinational Paths

`read_data_o` is a direct indexed read of `words_q`. `words_o` is a direct
parallel view. Neither path adds a handshake or registered latency; ownership
of DMI response timing and executor sequencing stays outside this leaf.

## 5. Integration Boundary

The storage leaf is instantiated in `debug_dmi_regs`, where DMI `progbuf0..3`
reads/writes, busy protection, `progbufsize=4`, and WARL-zero `abstractauto`
are verified. `debug_progbuf_exec`, Access Register postexec, and the
halted-core execution endpoint are integrated and covered by debug/wasp1 tests.

## 6. Target Behavior

No target macro changes the logic. The small flop array is suitable for ASIC
standard-cell synthesis and Virtex-7 register implementation.

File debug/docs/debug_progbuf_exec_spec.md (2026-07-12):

# debug_progbuf_exec Spec

## 1. Purpose

`debug_progbuf_exec` sequences the four stored Program Buffer words toward the
halted-core instruction execution port. It is a protocol controller;
the storage array, DMI register routing, and core datapath are separate blocks.

## 2. External Contract

| Interface | Required behavior |
| --- | --- |
| `start_i` | Starts at word zero only while `dmactive_i && hart_halted_i` |
| `words_i` | Four stable RV32 instruction words for the active operation |
| `instr_*` request | Holds instruction and index stable until `instr_ready_i` |
| `instr_rsp_*` | Accepts exactly one completion for each accepted instruction |
| `busy_o` | High from accepted start through the one-cycle completion state |
| `done_o/error_o` | One-cycle completion with an abstract-command error code |

## 3. Execution Requirements

Only one instruction may be outstanding. A non-EBREAK word is issued, then the
controller waits for its response before advancing. `32'h0010_0073` is an
explicit EBREAK terminator and completes successfully without entering the
ordinary core trap path.

Because `impebreak=0`, all successful sequences must contain an explicit EBREAK.
Reaching the end of word three after executing a non-EBREAK instruction returns
`CMDERR_EXCEPTION`.

## 4. Error And Abort Behavior

| Condition | Result |
| --- | --- |
| Start or continue while hart is not halted | Complete with `CMDERR_HALT_RESUME` |
| Core reports instruction error | Complete with `CMDERR_EXCEPTION` |
| No EBREAK in four words | Complete with `CMDERR_EXCEPTION` |
| `dmactive_i` clears | Silently abort to idle and scrub index/error state |
| Reset asserts | Asynchronously return to idle with no completion pulse |

## 5. Target Support

The controller is target-neutral synthesizable SystemVerilog. Generic, IC, and
Xilinx Virtex-7 builds must have identical protocol and error behavior.

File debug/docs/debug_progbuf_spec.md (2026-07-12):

# debug_progbuf Spec

## 1. Purpose

`debug_progbuf` stores four RV32 instruction words for the integrated RISC-V
Debug Module Program Buffer execution path. This leaf verifies storage only;
`debug_dmi_regs` owns DMI routing/capability and `debug_progbuf_exec` owns
sequencing toward the core.

## 2. External Contract

| Port | Direction | Required behavior |
| --- | --- | --- |
| `clk_i` | input | Clock for all Program Buffer words |
| `rst_ni` | input | Asynchronous active-low reset clearing every word |
| `clear_i` | input | Synchronous whole-buffer clear with priority over write |
| `write_valid_i` | input | Qualifies one word write on the next rising edge |
| `write_index_i` | input | Selects one of four stored words |
| `write_data_i` | input | 32-bit RV32 instruction payload |
| `read_index_i` | input | Selects the combinational DMI-side read word |
| `read_data_o` | output | Current selected word, without a registered response stage |
| `words_o` | output | Full four-word view for the integrated executor |

## 3. Functional Requirements

The default `WORD_COUNT` is four. Each word is 32 bits and all words reset to
zero. A valid write updates only the selected word. Non-selected words hold.

Update priority is:

```text
1. rst_ni=0 clears all words asynchronously
2. clear_i=1 clears all words on the rising edge
3. write_valid_i=1 updates words_q[write_index_i]
4. otherwise all words hold
```

`clear_i` and `write_valid_i` may be asserted together; clear must win.

## 4. External Integration Scope

```text
DMI address routing inside this leaf (provided by debug_dmi_regs integration)
abstractcs.progbufsize advertisement: debug_dmi_regs
Access Register postexec behavior: debug_abstract_cmd
explicit EBREAK termination: debug_progbuf_exec
core instruction injection and exception reporting: core_int_datapath
```

Those functions are verified at their owning module and the debug/wasp1
integration levels.

## 5. Target Support

The implementation is synthesizable target-neutral SystemVerilog. Generic
simulation, IC, and Xilinx Virtex-7 target macros must preserve identical
storage, reset, clear, and read behavior.

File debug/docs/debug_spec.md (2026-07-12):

# debug Spec

## 1. Purpose

`debug` is the stage-1 single-hart Debug Module integration boundary. It targets
RISC-V External Debug Specification 0.13.x behavior sufficient for hart
discovery, halt/resume control, and RV32 integer GPR abstract access.
It also exposes physical Access Memory through the halted core plus the
`misa`, `mstatus`, `dcsr`, and core-captured `dpc` abstract CSR probes required
for OpenOCD/GDB discovery, register-packet reads, memory disassembly around PC,
native `stepi` setup, two execute-address hardware breakpoint triggers, and
WARL-filtered load/store trigger configuration outputs consumed by the core's
precise LSU trigger path.

The JTAG TAP/DTM transport is integrated with this Debug Module by the
`debug_jtag` wrapper. This module intentionally remains the ready/valid DMI
Debug Module register/control boundary.

## 2. External Contract

| Interface or signal | Direction | Required behavior |
| --- | --- | --- |
| `clk_i`, `rst_ni` | input | Shared Debug Module clock and active-low reset |
| `debug_dmi_if.dm dmi` | target | DMI request/response register access channel |
| `debug_if.dm core_debug` | initiator/control | Core halt/resume plus halted-core GPR and memory access channel |
| `hart_reset_event_i` | input | One-cycle hart reset observation for sticky `dmstatus.havereset` |
| `dmactive_o` | output | Mirrors active Debug Module state |
| `ndmreset_o` | output | Non-debug reset request from `dmcontrol.ndmreset` |

`core_debug.step_req` asserts during a resume transaction when the latched
`dcsr.step` bit is set. `core_debug.trigger_execute_valid`,
`core_debug.trigger_load_valid`, `core_debug.trigger_store_valid`, and their
compare addresses reflect the supported `mcontrol` trigger slots programmed
through abstract trigger CSRs. The core compares those outputs against
architectural load/store addresses and performs the precise halt action; that
action is verified in the core datapath milestone rather than this module-level
testbench.

## 3. Implemented Functions

| Function | Requirement |
| --- | --- |
| DMI registers | Implement `data0`, `data1`, `dmcontrol`, `dmstatus`, `hartinfo`, `abstractcs`, `command`, `abstractauto`, and `progbuf0..3` |
| Hart control | Convert `haltreq/resumereq` register fields into core Debug Mode requests |
| Hart status | Report halted, running, resumeack, havereset, and nonexistent hart status |
| Abstract commands | Support RV32 integer Access Register commands for x0-x31, OpenOCD CSR probes, and physical Access Memory byte/half/word commands |
| GPR transport | Sequence one core GPR request and one response per abstract transfer |
| Memory transport | Sequence one halted-core memory request and one response per Access Memory command |
| Program Buffer | Advertise four words and execute Access Register postexec instructions through the halted core |
| Single-step | Convert `dcsr.step=1` plus `dmcontrol.resumereq` into `core_debug.step_req` |
| Hardware breakpoint | Provide two RV32 `mcontrol` execute-address trigger slots for OpenOCD/GDB `hbreak` |
| Data-trigger configuration | Accept and expose per-slot exact-address load/store `mcontrol` modes for precise core-side LSU halt action |
| Error reporting | Preserve leaf-module `cmderr` mapping and DMI `FAILED` response behavior |

## 4. Unsupported Stage-1 Scope

The following are intentionally outside this module:

```text
debug ROM
architectural CSR side effects beyond `dcsr.step`
multi-hart selection beyond architectural nonexistent-hart reporting
```

`debug_progbuf` storage and `debug_progbuf_exec` sequencing are integrated.
`abstractcs.progbufsize=4`; `abstractauto=0`, so automatic execution on
data/progbuf access remains unsupported.

## 5. Target Support

The module is synthesizable SystemVerilog and target-neutral. The target macros
`WASP1_TARGET_SIM_GENERIC`, `WASP1_TARGET_IC`, and
`WASP1_TARGET_FPGA_XILINX_VIRTEX7` must not change DMI-visible behavior.

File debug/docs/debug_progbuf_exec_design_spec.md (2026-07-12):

# debug_progbuf_exec Design Spec

## 1. Scope

`debug_progbuf_exec` owns sequencing and result policy for one Program Buffer
operation. It does not own storage, DMI decode, abstract-command dispatch, or
instruction execution inside the core.

## 2. Editable L3 Diagram

editable source: `debug/docs/diagrams/debug_progbuf_exec_fsm.graffle`
generator source: `debug/dv/generate_debug_progbuf_exec_diagram.py`
preview export: none
detail level: L3
clock domain: `clk_i/rst_ni`

The diagram uses separate IF, COMB, and SEQ blocks, then expands all five FSM
states. It shows the asynchronous reset path, normal request/response arcs,
local EBREAK termination, missing-EBREAK error, hart-loss result, DM abort, and
one-cycle completion behavior. Native line segments, V-shaped arrowheads,
visible 5pt grid, and shape/line clearance pass the repository audit.

## 3. State And Registers

| Register | Reset | Meaning |
| --- | --- | --- |
| `state_q` | `EXEC_IDLE` | Protocol ownership and output phase |
| `index_q` | zero | Current Program Buffer word |
| `completion_error_q` | `CMDERR_NONE` | Result held through COMPLETE |

No instruction payload register is needed. `instr_o` reads `words_i[index_q]`,
and integration must prevent Program Buffer writes while the abstract executor
is busy. ISSUE holds `index_q` stable under request backpressure; WAIT holds it
stable until the matching response.

## 4. Transition Table

| Current state | Condition, in priority order | Next state | Sequential side effect |
| --- | --- | --- | --- |
| IDLE | `start_i && dmactive_i && hart_halted_i` | CHECK | index=0, error=NONE |
| IDLE | `start_i && dmactive_i && !hart_halted_i` | COMPLETE | error=HALT_RESUME |
| CHECK | `!dmactive_i` | IDLE | scrub index/error |
| CHECK | `!hart_halted_i` | COMPLETE | error=HALT_RESUME |
| CHECK | current word is EBREAK | COMPLETE | retain error=NONE |
| CHECK | otherwise | ISSUE | none |
| ISSUE | `!dmactive_i` | IDLE | scrub index/error |
| ISSUE | `!hart_halted_i` | COMPLETE | error=HALT_RESUME |
| ISSUE | `instr_valid_o && instr_ready_i` | WAIT | instruction becomes outstanding |
| WAIT | `!dmactive_i` | IDLE | silently abort and scrub |
| WAIT | `!hart_halted_i` | COMPLETE | error=HALT_RESUME |
| WAIT | response with `instr_rsp_error_i` | COMPLETE | error=EXCEPTION |
| WAIT | successful response at final physical word | COMPLETE | error=EXCEPTION, no EBREAK |
| WAIT | other successful response | CHECK | index increments once |
| COMPLETE | unconditional | IDLE | no additional side effect |

Reset asynchronously selects IDLE and clears index/error before every runtime
condition. A busy `start_i` has no transition and cannot replace the operation.

## 5. Output Decode

`busy_o` is high in every state except IDLE. `done_o` is high only in COMPLETE.
The instruction request is valid only in ISSUE while DM and halted state remain
qualified. Response ready is similarly confined to WAIT. These gates stop new
handshakes immediately if integration removes execution permission.

## 6. EBREAK Policy

The controller consumes `PROGBUF_EBREAK_INSN` locally instead of sending it to
the ordinary core trap machinery. This prevents the debug terminator from
modifying machine trap CSRs. `impebreak` remains zero, so executing word three
without seeing EBREAK is an exception rather than implicit success.

## 7. Target Behavior

The FSM and register widths are target-neutral. Target macros do not alter
state encoding, handshake behavior, or abstract error mapping.

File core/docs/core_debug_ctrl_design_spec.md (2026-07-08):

# core_debug_ctrl Design Spec

## 1. Scope

`core_debug_ctrl` is a small sequential FSM that controls the core-side Debug
Mode hooks. It has no programmer-visible CSRs; it only coordinates pipeline
drain/freeze, decoded trigger entry requests, and Debug Module status.

## 2. Editable Diagram

```text
editable source: core/docs/diagrams/core_debug_ctrl_fsm.graffle
preview export:  none
detail level:    L3
clock domain:    SEQ clk=clk_i rst=rst_ni
```

The OmniGraffle source uses the project timing-class colors:

```text
SEQ  pale green
COMB pale amber/yellow
IF   pale blue
```

## 3. Block Diagram

```text
Legend: IF=interface, COMB=combinational logic, SEQ=clocked state

 IF debug request/status pins
 halt_req_i/trigger_req_i/resume_req_i/step_req_i
 pipe_idle_i/retire_valid_i/debug_busy_i
        |
        v
 +--------------------------------+
 | COMB next-state and priority   |
 | halt/trigger > resume/step     |
 | busy blocks resume/step        |
 +---------------+----------------+
                 |
                 v
 +--------------------------------+
 | SEQ clk=clk_i rst=rst_ni       |
 | state_q                        |
 | RUNNING/HALT_PENDING/HALTED/   |
 | STEP_RUNNING                   |
 +---------------+----------------+
                 |
                 v
 +--------------------------------+
 | COMB output decode             |
 | stop_fetch/freeze_pipe/status  |
 +---------------+----------------+
                 |
                 v
 IF core pipeline control and DM status
```

## 4. FSM States

| State | Meaning | Key outputs |
| --- | --- | --- |
| `DBG_RUNNING` | Normal execution. | `running_o=1`, `halted_o=0`, no freeze. |
| `DBG_HALT_PENDING` | Fetch stopped while existing work drains. | `stop_fetch_o=1`, neither running nor halted. |
| `DBG_HALTED` | Pipeline is empty and Debug Mode owns GPR access. | `halted_o=1`, `freeze_pipe_o=1`, `stop_fetch_o=1`. |
| `DBG_STEP_RUNNING` | One instruction is released from halted state. | `running_o=1` until one retirement then re-halt. |

## 5. Transition Priority

Reset:

```text
state_q <- DBG_RUNNING
```

Transitions:

```text
DBG_RUNNING:
  (halt_req_i || trigger_req_i) && pipe_idle_i && !debug_busy_i -> DBG_HALTED
  halt_req_i || trigger_req_i                                  -> DBG_HALT_PENDING

DBG_HALT_PENDING:
  !halt_req_i && resume_req_i               -> DBG_RUNNING
  pipe_idle_i && !debug_busy_i              -> DBG_HALTED

DBG_HALTED:
  halt_req_i                                -> DBG_HALTED
  !halt_req_i && step_req_i && !debug_busy_i -> DBG_STEP_RUNNING
  !halt_req_i && resume_req_i && !debug_busy_i -> DBG_RUNNING

DBG_STEP_RUNNING:
  halt_req_i || trigger_req_i || retire_valid_i:
    pipe_idle_i                             -> DBG_HALTED
    otherwise                               -> DBG_HALT_PENDING
```

## 6. Output Logic

`stop_fetch_o` is asserted combinationally when `halt_req_i` or `trigger_req_i`
is visible, even before the FSM samples the request. This prevents an extra
instruction from being accepted behind a debug halt or trigger entry request.

`freeze_pipe_o` is asserted only in `DBG_HALTED`. During `DBG_HALT_PENDING`,
fetch is stopped but decode/execute are allowed to drain normally.

`running_o` is asserted in `DBG_RUNNING` and `DBG_STEP_RUNNING`. During
`DBG_HALT_PENDING`, both `running_o` and `halted_o` are zero so the Debug Module
can distinguish "not yet halted" from "already halted".

## 7. Target Support

The FSM is target-neutral synthesizable logic. IC and Virtex-7 builds use the
same behavior.

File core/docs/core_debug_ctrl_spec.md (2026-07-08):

# core_debug_ctrl Spec

## 1. Purpose

`core_debug_ctrl` owns the minimal core-side Debug Mode state required by the
RISC-V external debug path. It converts Debug Module halt/resume/step requests
and core trigger requests into frontend stop/freeze controls and reports hart
`halted`/`running` status.

## 2. Required Behavior

The controller must:

```text
reset to normal running state
stop accepting new frontend instructions as soon as halt_req_i or trigger_req_i is visible
wait for pipe_idle_i before reporting halted_o
keep the drained pipeline frozen while halted
block resume and step while debug_busy_i is asserted
allow resume from halted state when halt_req_i is low
allow a one-instruction step from halted state when step_req_i is asserted
return to halt-pending after one retire_valid_i during step
give halt_req_i/trigger_req_i priority over resume_req_i and step_req_i
```

## 3. Interface Contract

| Signal | Direction | Meaning |
| --- | --- | --- |
| `clk_i`, `rst_ni` | input | Core/debug state clock and active-low reset. |
| `halt_req_i` | input | Request entry to Debug Mode. |
| `trigger_req_i` | input | Core trigger requests entry to Debug Mode. |
| `resume_req_i` | input | Request exit from Debug Mode. |
| `step_req_i` | input | Request one retired instruction before re-halt. |
| `pipe_idle_i` | input | Pipeline and LSU outstanding state are drained. |
| `retire_valid_i` | input | One instruction retires in step-running state. |
| `debug_busy_i` | input | A halted GPR response is pending or being accepted. |
| `stop_fetch_o` | output | Stop frontend instruction acceptance. |
| `freeze_pipe_o` | output | Hold the drained pipeline while halted. |
| `halted_o` | output | Hart is halted in Debug Mode. |
| `running_o` | output | Hart is in normal run or step-running state. |

## 4. Non-Goals

This controller does not implement DCSR/DPC, trigger CSR storage, trigger
address matching, JTAG DTM, or OpenOCD packet transport. It only arbitrates the
already-decoded trigger request as a Debug Mode entry cause.

## 5. Verification Requirements

Verification must cover reset/running, immediate halt, halt while draining,
trigger halt, halt-pending cancel, resume, debug-busy resume blocking,
single-step re-halt, and halt/trigger priority over simultaneous resume/step.

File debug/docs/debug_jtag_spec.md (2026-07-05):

# debug_jtag Spec

## 1. Scope

`debug_jtag` is the stage-1 JTAG-facing debug integration wrapper. It connects
the verified `debug_jtag_dtm` transport to the verified `debug` Debug Module.

The wrapper adds no new architectural registers. JTAG-visible transport state is
owned by `debug_jtag_dtm`; DMI-visible Debug Module state is owned by `debug`.

## 2. External Contract

| Interface or signal | Direction | Required behavior |
| --- | --- | --- |
| `clk_i`, `rst_ni` | input | Debug Module/system clock and active-low reset. |
| `tck_i`, `trst_ni` | input | JTAG TAP clock and active-low TAP reset. |
| `tms_i`, `tdi_i`, `tdo_o` | JTAG pins | Standard serial TAP controls/data. |
| `debug_if.dm core_debug` | initiator/control | Halt/resume/GPR debug channel to the single core. |
| `hart_reset_event_i` | input | One-cycle hart reset observation for sticky `dmstatus.havereset`. |
| `dmactive_o` | output | Debug Module active state from `dmcontrol.dmactive`. |
| `ndmreset_o` | output | Non-debug reset request from `dmcontrol.ndmreset`. |
| `dtm_hardreset_o` | output | One-`tck_i` pulse from `DTMCS.dmihardreset`. |

## 3. Required Behavior

JTAG DMI scans must reach the Debug Module register file through the internal
`debug_dmi_if` link. The integrated path must support:

```text
IDCODE and DTMCS scans
DMI read/write/NOP scans
Debug Module activation through dmcontrol.dmactive
haltreq and resumereq delivery to core_debug
dmstatus running/halted/resumeack/havereset reporting
RV32 GPR Access Register abstract commands
`dcsr.step` single-step setup and resume delivery
```

## 4. Unsupported Stage-1 Scope

The following remain outside this wrapper:

```text
program buffer
abstract memory access
debug ROM
```

SoC top-level JTAG pin exposure and OpenOCD/GDB external process smoke are
covered by the `wasp1` top-level integration.

## 5. Target Support

The wrapper is structural and target-neutral. Target macros must not change the
JTAG instruction behavior, DMI protocol behavior, Debug Module register map, or
core-debug side effects.

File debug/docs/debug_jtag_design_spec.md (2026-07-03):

# debug_jtag Design Spec

## 1. Scope

`debug_jtag` structurally composes:

```text
debug_jtag_dtm
debug
debug_dmi_if dmi_link
```

It is the first integrated JTAG-to-Debug-Module boundary and prepares the debug
subsystem for later SoC pin-level integration.

## 2. Block Diagram

Editable OmniGraffle source is planned under
`debug/docs/diagrams/debug_jtag_block.graffle`. Until that source is added, the
text diagram below is the diff-friendly engineering contract.

```text
 IF JTAG pins
 tck_i/trst_ni/tms_i/tdi_i/tdo_o
        |
        v
+----------------------------+
| SEQ clk=tck_i              |
| rst=trst_ni/rst_ni         |
| debug_jtag_dtm TAP/scan    |
+-------------+--------------+
              |
              | IF debug_dmi_if.dtm
              | clk=clk_i rst=rst_ni
              v
+----------------------------+
| IF dmi_link                |
| ready/valid DMI channel    |
+-------------+--------------+
              |
              | IF debug_dmi_if.dm
              v
+----------------------------+
| SEQ clk=clk_i rst=rst_ni   |
| debug Debug Module wrapper |
| regs/halt/abstract/GPR     |
+-------------+--------------+
              |
              v
 IF core_debug to single hart
```

Timing classes:

```text
IF   external or structured interface connection
SEQ  sequential child module or storage, with explicit clock/reset
```

`debug_jtag` itself contains no `always_ff` or `always_comb` blocks.

## 3. Internal Connectivity

`debug_jtag_dtm` drives the internal `dmi_link` with its `dtm` modport. `debug`
consumes the same interface through its `dm` modport. Both sides use `clk_i` and
`rst_ni` for the ready/valid DMI link.

The JTAG TAP and DMI scan registers remain in `debug_jtag_dtm`. The Debug Module
architectural registers and hart-control state remain in `debug`.

## 4. Reset Behavior

`rst_ni` resets both the DTM DMI sequencer and the Debug Module. `trst_ni`
resets the JTAG TAP and scan state. `debug_jtag` does not add reset sequencing
or reset filtering.

## 5. Sequential State

No wrapper-local sequential state exists. Sequential behavior is inherited from:

| Child | Clock/reset | State role |
| --- | --- | --- |
| `debug_jtag_dtm` | `tck_i/trst_ni/rst_ni` and `clk_i/rst_ni` | TAP FSM, IR/DR scan registers, DMI CDC sequencer |
| `debug` | `clk_i/rst_ni` | Debug Module registers, halt/resume FSM, abstract command and GPR access FSMs |

## 6. Integration Priority

There is no arbitration inside this wrapper. The only DMI master is
`debug_jtag_dtm`, and the only DMI target is `debug`.

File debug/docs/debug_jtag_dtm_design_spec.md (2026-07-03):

# debug_jtag_dtm Design Spec

## 1. Scope

`debug_jtag_dtm` implements a stage-1 RISC-V JTAG DTM around the existing
wasp1 `debug_dmi_if`. The implementation is split into a JTAG `tck_i` domain
and a system `clk_i` domain.

## 2. Block Diagram

Editable OmniGraffle source is planned for this figure under
`debug/docs/diagrams/debug_jtag_dtm_block.graffle`. Until that source is added,
the text diagram below is the diff-friendly engineering contract.

```text
 IF JTAG pins
 tck_i/trst_ni/tms_i/tdi_i/tdo_o
        |
        v
+-------------------------+       +-------------------------+
| SEQ clk=tck_i           |       | COMB                    |
| rst=trst_ni/rst_ni      |------>| TAP next-state decode   |
| TAP FSM state           |       | IR/DR decode mux        |
+-----------+-------------+       +------------+------------+
            |                                  |
            v                                  v
+-------------------------+       +-------------------------+
| SEQ clk=tck_i           |<----->| COMB                    |
| rst=trst_ni/rst_ni      |       | DTMCS/DMI capture data  |
| IR and DR shift regs    |       | DR width select         |
+-----------+-------------+       +------------+------------+
            |                                  |
            v                                  v
+-------------------------+       +-------------------------+
| SEQ clk=tck_i           |       | IF CDC request payload  |
| rst=trst_ni/rst_ni      |------>| req_toggle + stable bus |
| DMI request launch      |       +------------+------------+
| sticky dmistat          |                    |
+-----------+-------------+                    v
            ^                       +-------------------------+
            |                       | SEQ clk=clk_i rst=rst_ni|
            |                       | DMI req/rsp sequencer   |
            |                       +------------+------------+
            |                                    |
            |                                    v
            |                       IF debug_dmi_if.dtm
            |                                    |
            |                       +------------+------------+
            |                       | IF CDC response payload |
            +-----------------------| rsp_toggle + stable bus |
                                    +-------------------------+
```

Timing classes:

```text
IF   external pins, internal interface, or CDC payload boundary
SEQ  sequential state/storage with explicit clock/reset
COMB combinational decode, mux, or next-state logic
```

## 3. TAP FSM

The TAP controller implements all 16 IEEE 1149.1 states:

```text
TEST_LOGIC_RESET
RUN_TEST_IDLE
SELECT_DR_SCAN
CAPTURE_DR
SHIFT_DR
EXIT1_DR
PAUSE_DR
EXIT2_DR
UPDATE_DR
SELECT_IR_SCAN
CAPTURE_IR
SHIFT_IR
EXIT1_IR
PAUSE_IR
EXIT2_IR
UPDATE_IR
```

Transition conditions are the standard JTAG `tms_i` transitions. Reset through
`trst_ni` or `rst_ni` forces `TEST_LOGIC_RESET`; remaining in
`TEST_LOGIC_RESET` with `tms_i=1` also resets the active IR to `IDCODE` and
clears sticky DMI status.

## 4. IR and DR Implementation

`IR_WIDTH` defaults to five bits. `CAPTURE_IR` loads the required low-bit
pattern `2'b01`. `SHIFT_IR` shifts LSB-first and `UPDATE_IR` commits the active
instruction.

The DR shift register is physically sized to the largest supported scan chain,
but the insertion point changes by active instruction:

| Active IR | Shift width | TDI insertion bit |
| --- | ---: | ---: |
| `IDCODE` | 32 | 31 |
| `DTMCS` | 32 | 31 |
| `DMI` | `DMI_ADDR_WIDTH + 34` | 40 for the default 7-bit address width |
| `BYPASS`/unsupported | 1 | 0 |

This avoids corrupting shorter scan chains when the DMI chain is wider than
32 bits.

## 5. DMI CDC Sequencer

The CDC is a single-entry toggle handshake:

| Direction | Producer domain | Consumer domain | Stable payload |
| --- | --- | --- | --- |
| request | `tck_i` | `clk_i` | `req_op_tck_q`, `req_addr_tck_q`, `req_data_tck_q` |
| response | `clk_i` | `tck_i` | `rsp_addr_clk_q`, `rsp_data_clk_q`, `rsp_resp_clk_q` |

When a DMI scan updates with `READ` or `WRITE`, the TCK domain latches the
payload, toggles `req_toggle_tck_q`, and marks the request busy. The `clk_i`
domain synchronizes the toggle, captures the stable payload, asserts
`dmi.req_valid`, waits for `dmi.req_ready`, then waits for `dmi.rsp_valid`.
After capturing the response it toggles `rsp_toggle_clk_q`. The TCK domain
synchronizes that response toggle, clears busy, and makes the response visible
to the next DMI scan.

## 6. Priority and Side Effects

Priority in the TCK domain:

| Priority | Event | Side effect |
| ---: | --- | --- |
| 1 | `trst_ni=0` or `rst_ni=0` | Reset TAP, IR, sticky status, request launch state. |
| 2 | response toggle observed | Capture response, clear busy, set sticky failed if needed. |
| 3 | TAP reset state | Select `IDCODE`, clear sticky status. |
| 4 | `UPDATE_DR` with `DTMCS.dmireset`/`dmihardreset` | Clear sticky status; optionally pulse hard reset. |
| 5 | `UPDATE_DR` with non-NOP `DMI` | Launch request if idle; otherwise return/set busy. |

Priority in the `clk_i` domain:

| Priority | Event | Side effect |
| ---: | --- | --- |
| 1 | `rst_ni=0` | Clear request/response sequencer. |
| 2 | new request toggle while idle | Capture stable request payload and assert `dmi.req_valid`. |
| 3 | `dmi.req_valid && dmi.req_ready` | Drop request valid and wait for response. |
| 4 | `dmi_rsp_wait_q && dmi.rsp_valid` | Capture response and toggle completion. |

## 7. State Diagram Requirement

This module has a non-trivial protocol FSM and CDC sequence. The design-spec
figure should be maintained as an L3 editable OmniGraffle diagram with:

```text
TAP reset and all 16 TAP states
DMI request launch/busy/complete path
DTMCS sticky status clear path
clk_i-domain request/response sequencer
```

The Markdown state and priority tables above remain the reviewable textual
contract for transitions and side effects.

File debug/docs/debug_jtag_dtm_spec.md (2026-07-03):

# debug_jtag_dtm Spec

## 1. Scope

`debug_jtag_dtm` is the stage-1 JTAG Debug Transport Module for wasp1. It
provides the RISC-V Debug v0.13-style JTAG TAP entry point and converts JTAG
DMI scans into the internal `debug_dmi_if` ready/valid protocol.

The module is intended to be the OpenOCD/GDB-facing transport block once it is
connected to the verified `debug` Debug Module top.

## 2. External Interface

| Port | Direction | Description |
| --- | --- | --- |
| `clk_i` | input | System debug clock for the internal DMI ready/valid interface. |
| `rst_ni` | input | Active-low reset for the system debug clock domain and DTM state. |
| `tck_i` | input | JTAG test clock. TAP state and scan registers update in this domain. |
| `trst_ni` | input | Active-low asynchronous JTAG reset. |
| `tms_i` | input | JTAG test mode select, sampled on rising `tck_i`. |
| `tdi_i` | input | JTAG serial data input, sampled on rising `tck_i` in shift states. |
| `tdo_o` | output | JTAG serial data output, updated on falling `tck_i`. |
| `dmi` | `debug_dmi_if.dtm` | Internal ready/valid DMI master in the `clk_i` domain. |
| `dtm_hardreset_o` | output | One-`tck_i` pulse when `DTMCS.dmihardreset` is written as one. |

## 3. Supported JTAG Instructions

| IR | Name | DR width | Behavior |
| --- | --- | ---: | --- |
| `5'b00001` | `IDCODE` | 32 | Shifts `IDCODE_VALUE`. Reset instruction selects `IDCODE`. |
| `5'b10000` | `DTMCS` | 32 | Reports DTM version, DMI address width, idle recommendation, and sticky DMI status. |
| `5'b10001` | `DMI` | 41 | Shifts `{addr[6:0], data[31:0], op[1:0]}` with op/status bits first. |
| `5'b11111` | `BYPASS` | 1 | Single-bit bypass path. |
| other | unsupported | 1 | Safely treated as `BYPASS`. |

## 4. DTMCS Contract

| Field | Bits | Behavior |
| --- | ---: | --- |
| `version` | `[3:0]` | `1`, meaning RISC-V Debug v0.13 JTAG DTM. |
| `abits` | `[9:4]` | `7`, matching `debug_dmi_pkg::DMI_ADDR_WIDTH`. |
| `dmistat` | `[11:10]` | `0` clear, `2` sticky failed, `3` sticky busy. Busy has priority over failed. |
| `idle` | `[14:12]` | `1`, recommends at least one Run-Test/Idle TCK between operations. |
| `dmireset` | `[16]` | Write-one clears sticky DMI busy/error status. Reads as zero. |
| `dmihardreset` | `[17]` | Write-one clears sticky status and pulses `dtm_hardreset_o`. Reads as zero. |

## 5. DMI Transaction Contract

A non-NOP DMI scan launches one ready/valid request when no request is already
in flight. The response from a completed transaction is returned by a later DMI
scan. If software scans another non-NOP DMI request while the previous request
is still in flight, the DTM returns `DMI_RESP_BUSY` and sets sticky busy status.

NOP DMI scans do not launch a new request and are used to retrieve the previous
response.

## 6. Reset Behavior

`trst_ni` or `rst_ni` assertion returns the TAP to Test-Logic-Reset, selects
`IDCODE`, clears sticky DMI status, clears any in-flight request state, and
drives `tdo_o` low.

## 7. Target Behavior

The RTL is target-neutral. IC, Xilinx Virtex-7 FPGA, and simulation targets must
expose the same JTAG instruction behavior, DTMCS fields, DMI scan ordering, and
ready/valid contract.

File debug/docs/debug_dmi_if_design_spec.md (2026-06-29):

# debug_dmi_if Design Spec

## 1. Scope

`debug_dmi_if` contains signals and modports only. It contains no storage,
state machine, combinational logic, or clocked process.

## 2. Editable Connectivity Diagram

editable source: `debug/docs/diagrams/debug_dmi_if_connectivity.graffle`
preview export: none
detail level: L2
clock domains: none inside the interface declaration

The editable OmniGraffle diagram shows the `dtm`, `dm`, and `monitor` modports
as `IF` timing-class blocks because the interface declaration contains no
storage, state machine, combinational process, or clocked process. All
sequential buffering is implemented by the connected DTM or DM modules, not by
the interface declaration.

## 3. Modports

`dtm` assigns requester and response-consumer directions. `dm` assigns
request-consumer and response-producer directions. `monitor` is passive and is
intended for assertions, scoreboards, and waveform inspection.

## 4. Target Behavior

The interface is target-neutral and has identical behavior for IC, Xilinx
Virtex-7 FPGA, and generic simulation builds.

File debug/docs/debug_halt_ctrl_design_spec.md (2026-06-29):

# debug_halt_ctrl Design Spec

## 1. Scope

`debug_halt_ctrl` is a single-hart transaction controller. It does not modify
the core pipeline, register file, CSRs, or Debug Mode entry PC; those remain
core responsibilities for the later integration milestone.

## 2. Editable Control Diagram

editable source: `debug/docs/diagrams/debug_halt_ctrl_block.graffle`
preview export: none
detail level: L3
clock domains: `clk_i/rst_ni` for every `SEQ` block

The editable OmniGraffle diagram separates DM intent inputs, transition-priority
logic, the transaction FSM, request decode, core-control/status interfaces,
sticky status registers, and the DM status image into explicit `IF`, `COMB`,
and `SEQ` timing-class blocks. The transaction state, sticky acknowledgement
registers, transition logic, and request decode are not combined into a single
mixed-timing block.

The historical PNG `debug/docs/images/debug_halt_ctrl_fsm.png` remains as a
reference export.

## 3. Transaction FSM

| State | Meaning | Request output |
| --- | --- | --- |
| `IDLE` | No outstanding core control operation | none |
| `HALT_WAIT` | Waiting for `core_halted_i` | `core_halt_req_o=1` |
| `RESUME_WAIT` | Waiting for `core_running_i` | `core_resume_req_o=1` |

Transitions:

```text
IDLE -> HALT_WAIT:
  dmactive_i && haltreq_i && !core_halted_i

HALT_WAIT -> IDLE:
  !dmactive_i || !haltreq_i || core_halted_i || hart_reset_event_i

IDLE -> RESUME_WAIT:
  dmactive_i && !haltreq_i && resumereq_i && !core_running_i

RESUME_WAIT -> IDLE:
  !dmactive_i || (!haltreq_i && core_running_i) ||
  (haltreq_i && core_halted_i) || hart_reset_event_i

RESUME_WAIT -> HALT_WAIT:
  dmactive_i && haltreq_i && !core_halted_i
```

An already halted halt request and an already running resume request remain in
`IDLE`. The latter sets `resumeack_q` without issuing an unnecessary core pulse.

## 4. Sticky Status Registers

`resumeack_q` reset value is zero. A new resume transaction clears the previous
value. Resume completion sets it, and it then holds through ordinary idle
cycles so software polling can observe it.

`havereset_q` reset value is one. Runtime priority is:

```text
1. asynchronous rst_ni -> set
2. hart_reset_event_i  -> set and abort the transaction FSM
3. dmactive_i && ackhavereset_i -> clear
4. otherwise hold
```

## 5. Request Outputs

The request decode is combinational and separate from the state register:

```text
core_halt_req_o   = dmactive_i && state_q == HALT_WAIT
core_resume_req_o = dmactive_i && state_q == RESUME_WAIT
```

DM deactivation therefore suppresses requests without waiting for another state
transition. Hart status outputs are direct core-status mirrors.

## 6. Target Behavior

The implementation uses target-neutral synthesizable logic and includes
`wasp1_target_defs.svh`. Target selection does not change FSM or status behavior.

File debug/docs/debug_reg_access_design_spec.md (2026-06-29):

# debug_reg_access Design Spec

## 1. Scope

`debug_reg_access` is a low-level transport sequencer. `debug_abstract_cmd`
will later validate command type, register number, size, transfer, write, and
post-execution fields before issuing this module's compact command.

## 2. Editable FSM/Block Diagram

editable source: `debug/docs/diagrams/debug_reg_access_fsm.graffle`
preview export: none
detail level: L3
clock domains: `clk_i/rst_ni` for every `SEQ` block

The editable OmniGraffle diagram separates upstream command/response
interfaces, local handshake and flush logic, command registers, transport FSM,
core GPR interface, and response registers into explicit `IF`, `COMB`, and
`SEQ` timing-class blocks. The historical PNG
`debug/docs/images/debug_reg_access_fsm.png` remains as a reference export.
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

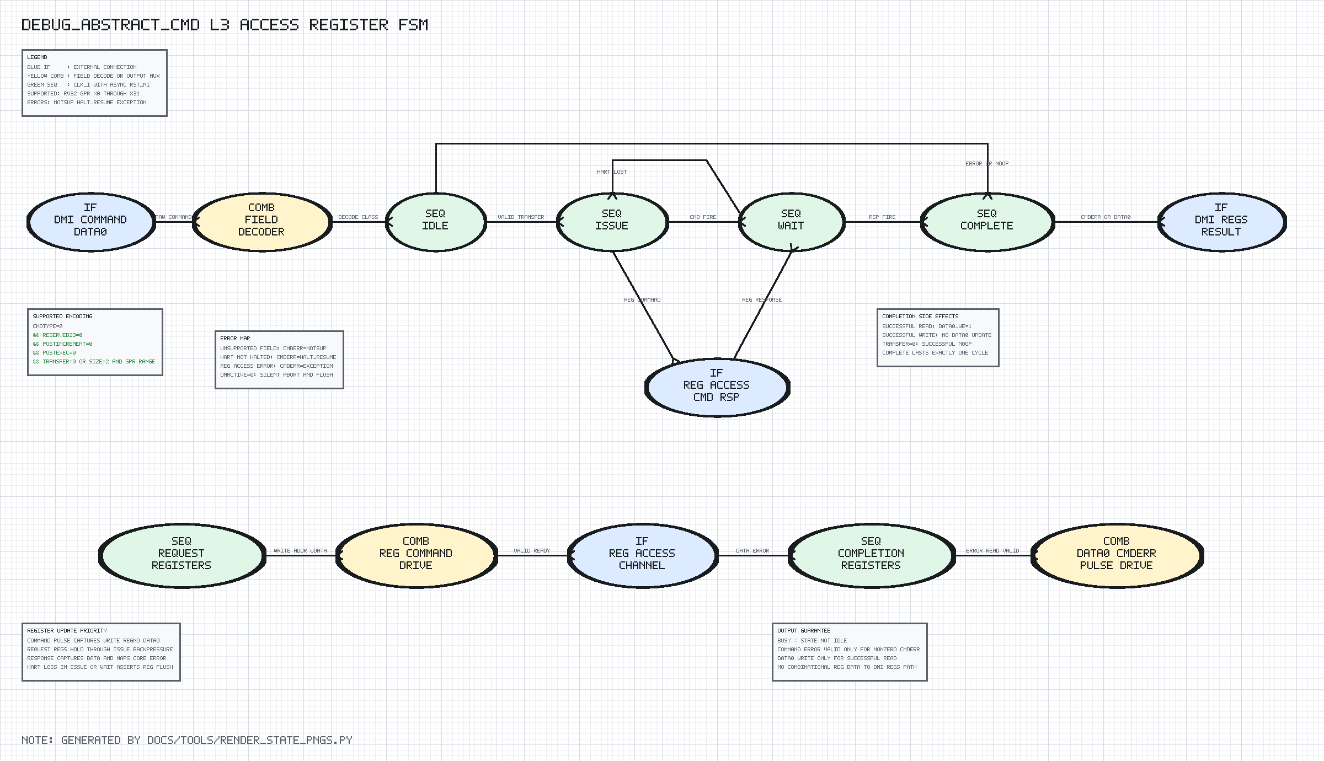
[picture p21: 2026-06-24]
debug/docs/images/debug_abstract_cmd_fsm.png

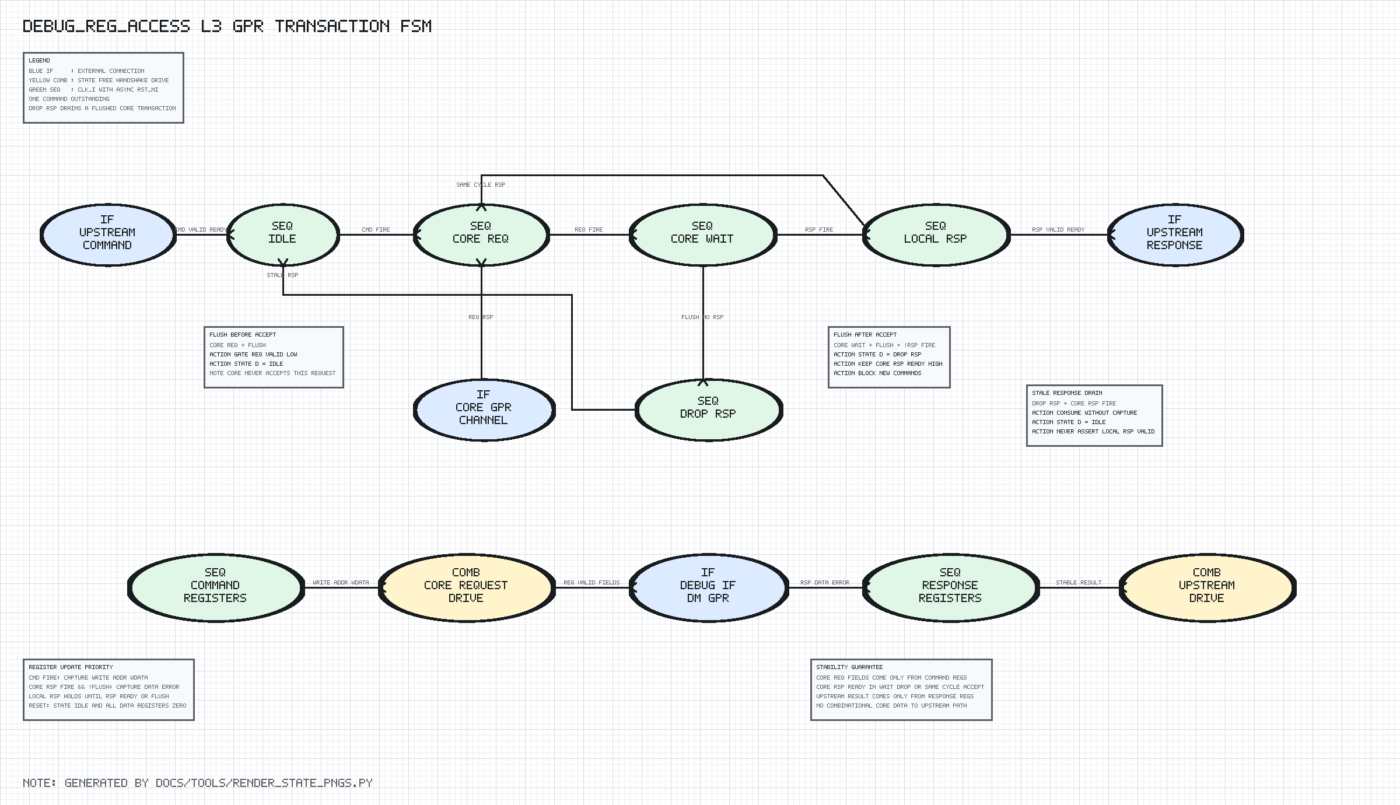
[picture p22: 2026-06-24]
debug/docs/images/debug_reg_access_fsm.png

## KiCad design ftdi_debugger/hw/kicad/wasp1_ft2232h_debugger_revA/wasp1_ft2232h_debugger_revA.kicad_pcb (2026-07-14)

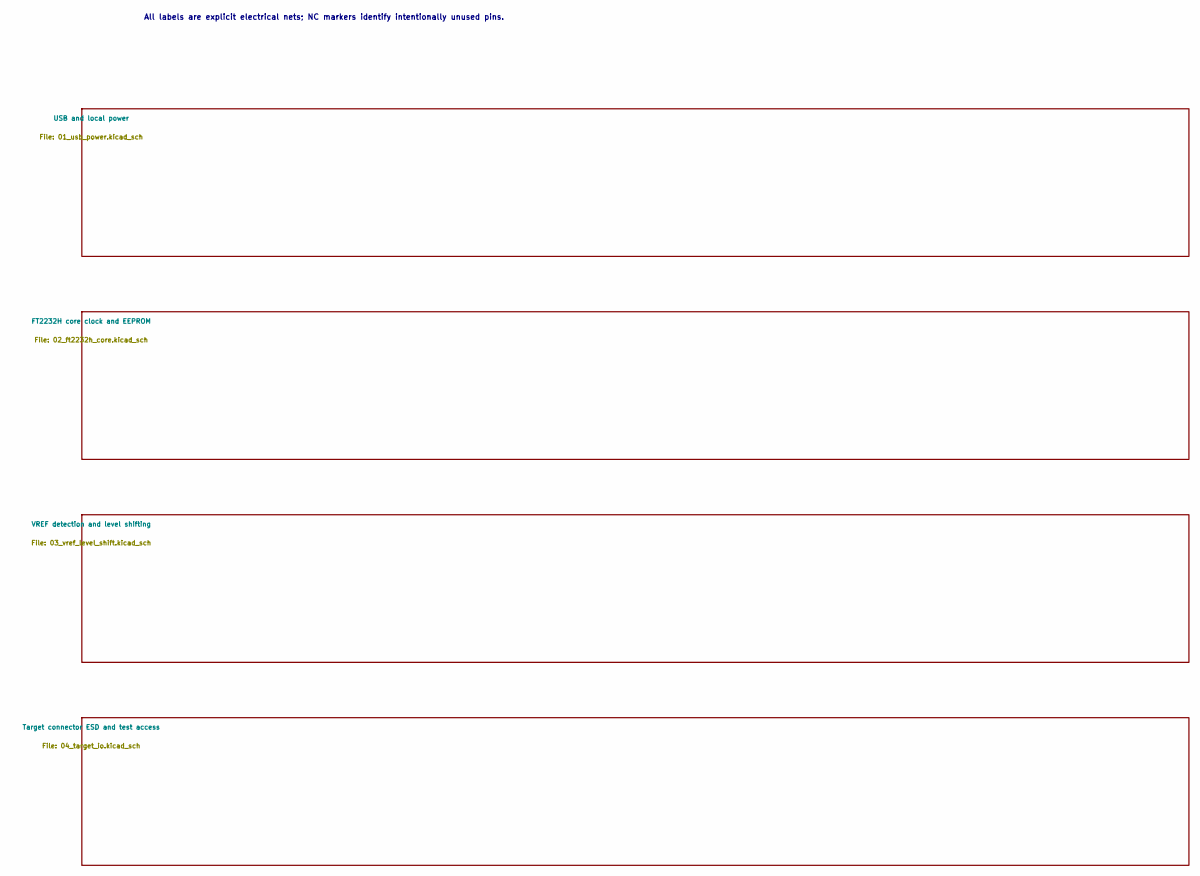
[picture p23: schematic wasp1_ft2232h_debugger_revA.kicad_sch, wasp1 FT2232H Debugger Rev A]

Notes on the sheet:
All labels are explicit electrical nets; NC markers identify intentionally unused pins.

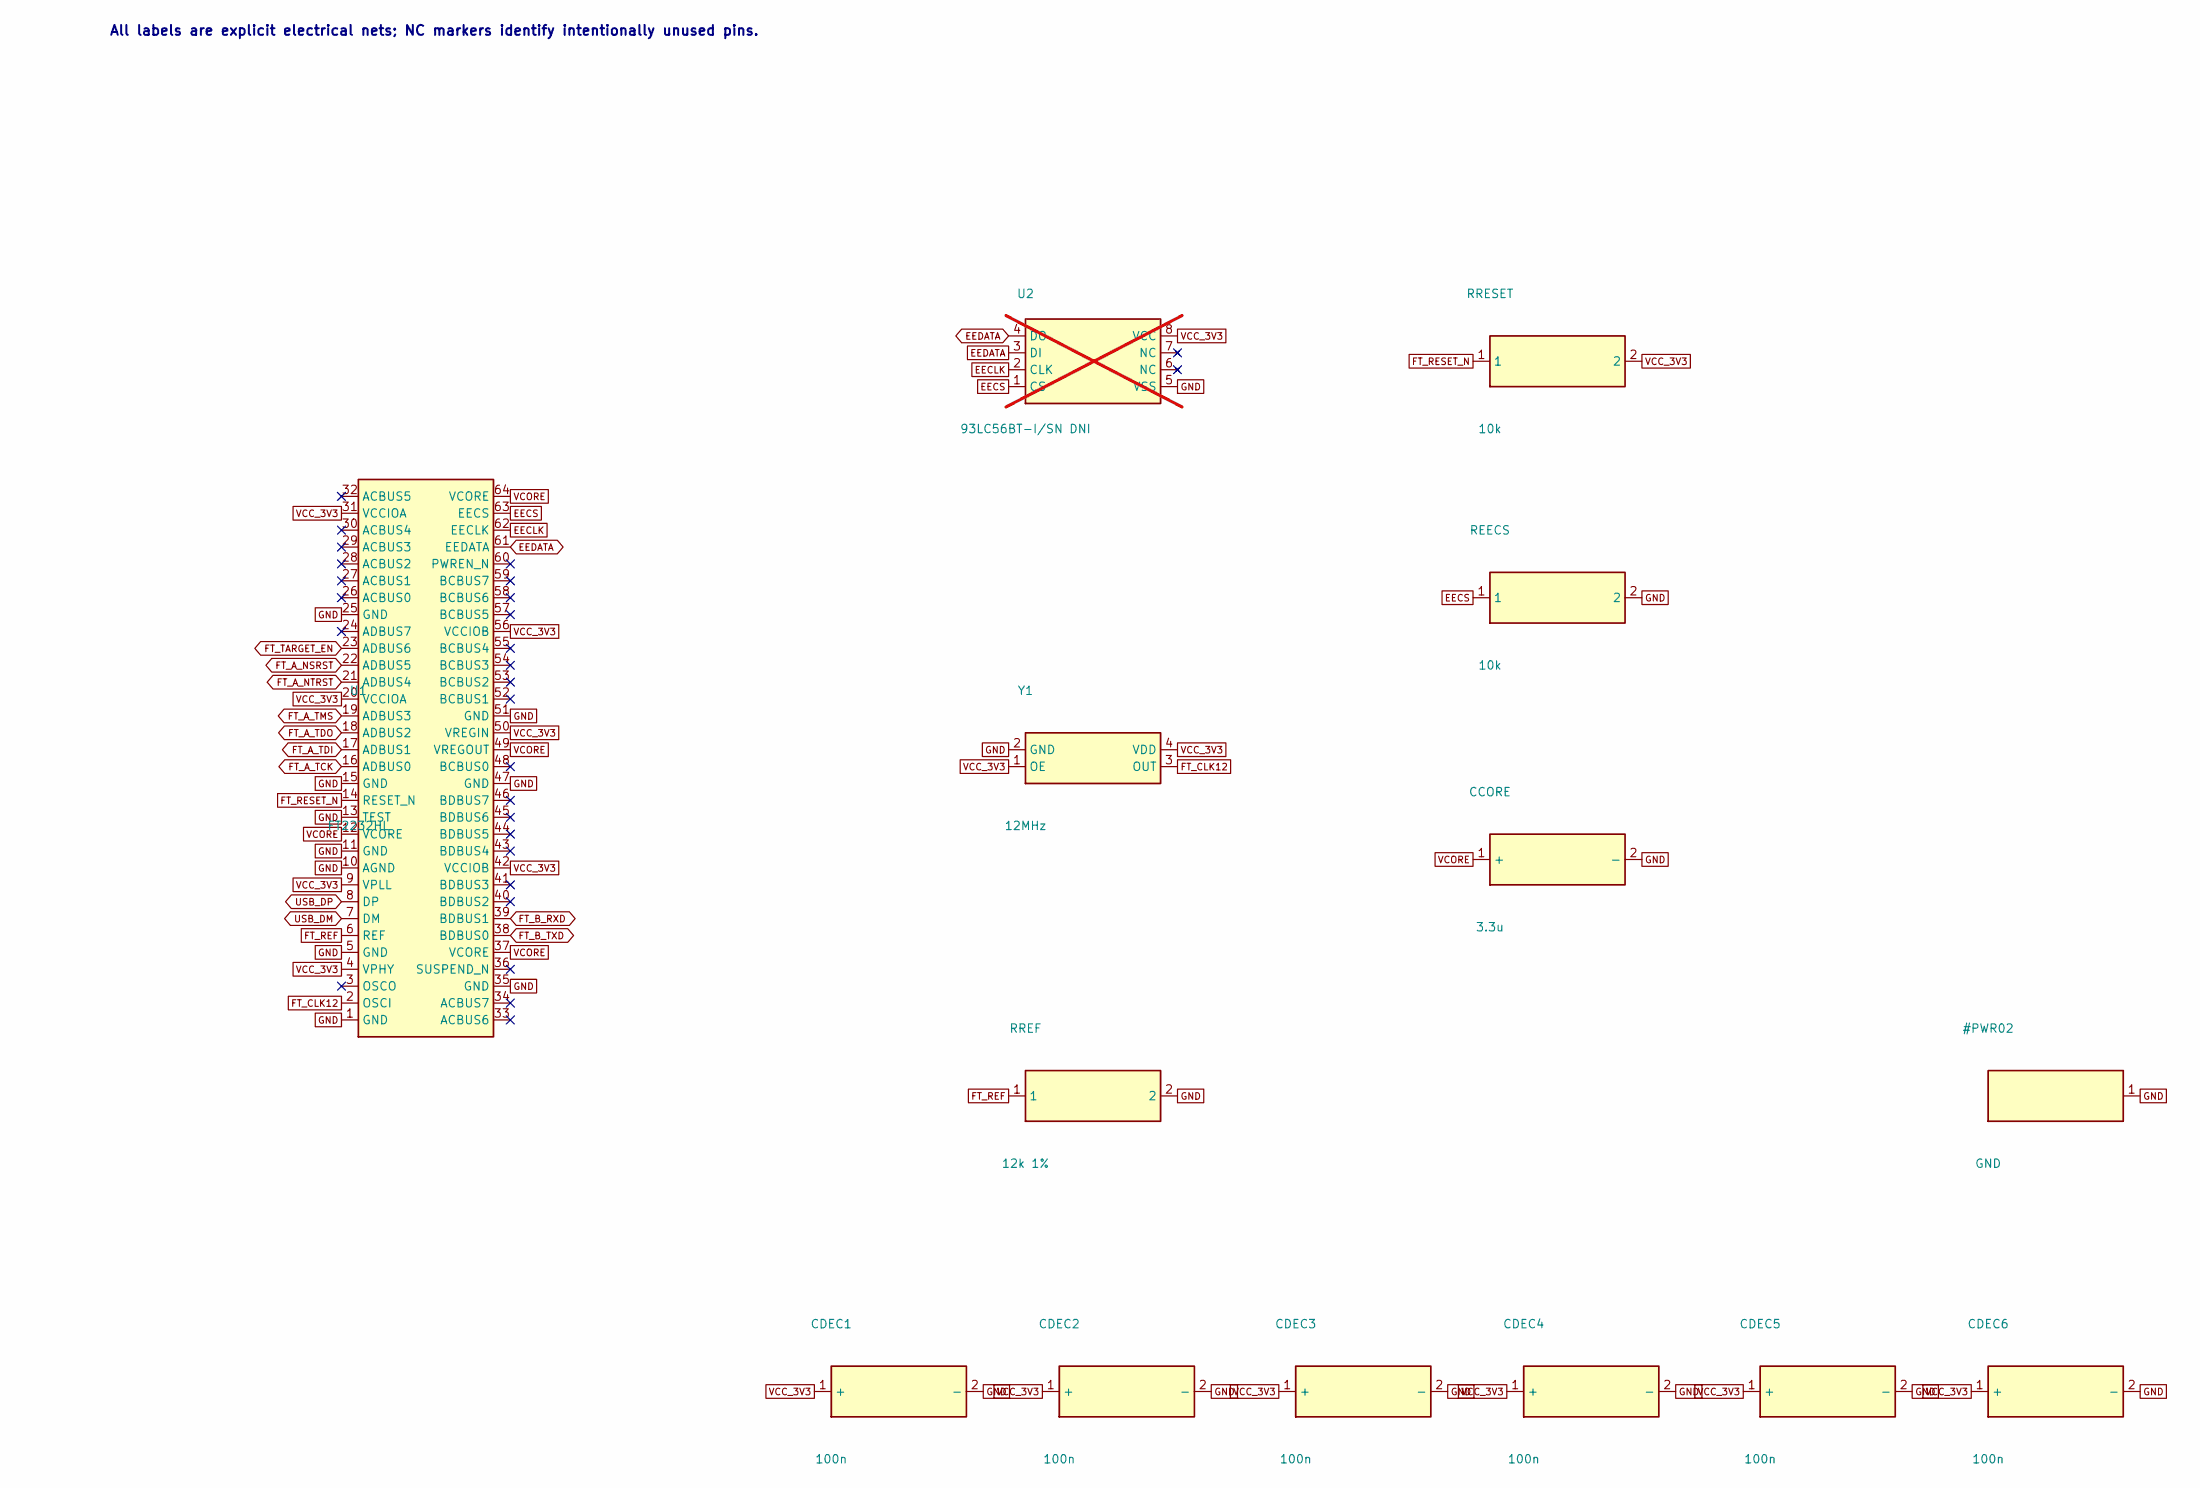
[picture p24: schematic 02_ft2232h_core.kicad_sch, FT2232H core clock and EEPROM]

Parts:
CCORE: 3.3u; C_0603_1608Metric
CDEC1, CDEC2, CDEC3, CDEC4, CDEC5, CDEC6: 100n; C_0402_1005Metric
REECS: 10k; R_0402_1005Metric
RREF: 12k 1%; R_0402_1005Metric
RRESET: 10k; R_0402_1005Metric
U1: FT2232HL; LQFP-64_10x10mm_P0.5mm
U2: 93LC56BT-I/SN DNI; SOIC-8_3.9x4.9mm_P1.27mm; not fitted
Y1: 12MHz; Oscillator_SMD_EuroQuartz_XO32-4Pin_3.2x2.5mm

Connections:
EECLK: U1.62 (EECLK), U2.2 (CLK)
EECS: REECS.1, U1.63 (EECS), U2.1 (CS)
EEDATA: U1.61 (EEDATA), U2.3 (DI), U2.4 (DO)
FT_A_NSRST: U1.22 (ADBUS5); also elsewhere on the board
FT_A_NTRST: U1.21 (ADBUS4); also elsewhere on the board
FT_A_TCK: U1.16 (ADBUS0); also elsewhere on the board
FT_A_TDI: U1.17 (ADBUS1); also elsewhere on the board
FT_A_TDO: U1.18 (ADBUS2); also elsewhere on the board
FT_A_TMS: U1.19 (ADBUS3); also elsewhere on the board
FT_B_RXD: U1.39 (BDBUS1); also elsewhere on the board
FT_B_TXD: U1.38 (BDBUS0); also elsewhere on the board
FT_CLK12: U1.2 (OSCI), Y1.3 (OUT)
FT_REF: RREF.1, U1.6 (REF)
FT_RESET_N: RRESET.1, U1.14 (RESET_N)
FT_TARGET_EN: U1.23 (ADBUS6); also elsewhere on the board
GND: CCORE.2 (-), CDEC1.2 (-), CDEC2.2 (-), CDEC3.2 (-), CDEC4.2 (-), CDEC5.2 (-), CDEC6.2 (-), REECS.2, RREF.2, U1.1 (GND), U1.5 (GND), U1.10 (AGND), U1.11 (GND), U1.13 (TEST), U1.15 (GND), U1.25 (GND), U1.35 (GND), U1.47 (GND), U1.51 (GND), U2.5 (VSS), Y1.2 (GND); also elsewhere on the board
USB_DM: U1.7 (DM); also elsewhere on the board
USB_DP: U1.8 (DP); also elsewhere on the board
VCC_3V3: CDEC1.1 (+), CDEC2.1 (+), CDEC3.1 (+), CDEC4.1 (+), CDEC5.1 (+), CDEC6.1 (+), RRESET.2, U1.4 (VPHY), U1.9 (VPLL), U1.20 (VCCIOA), U1.31 (VCCIOA), U1.42 (VCCIOB), U1.50 (VREGIN), U1.56 (VCCIOB), U2.8 (VCC), Y1.1 (OE), Y1.4 (VDD); also elsewhere on the board
VCORE: CCORE.1 (+), U1.12 (VCORE), U1.37 (VCORE), U1.49 (VREGOUT), U1.64 (VCORE); also elsewhere on the board

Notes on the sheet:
All labels are explicit electrical nets; NC markers identify intentionally unused pins.

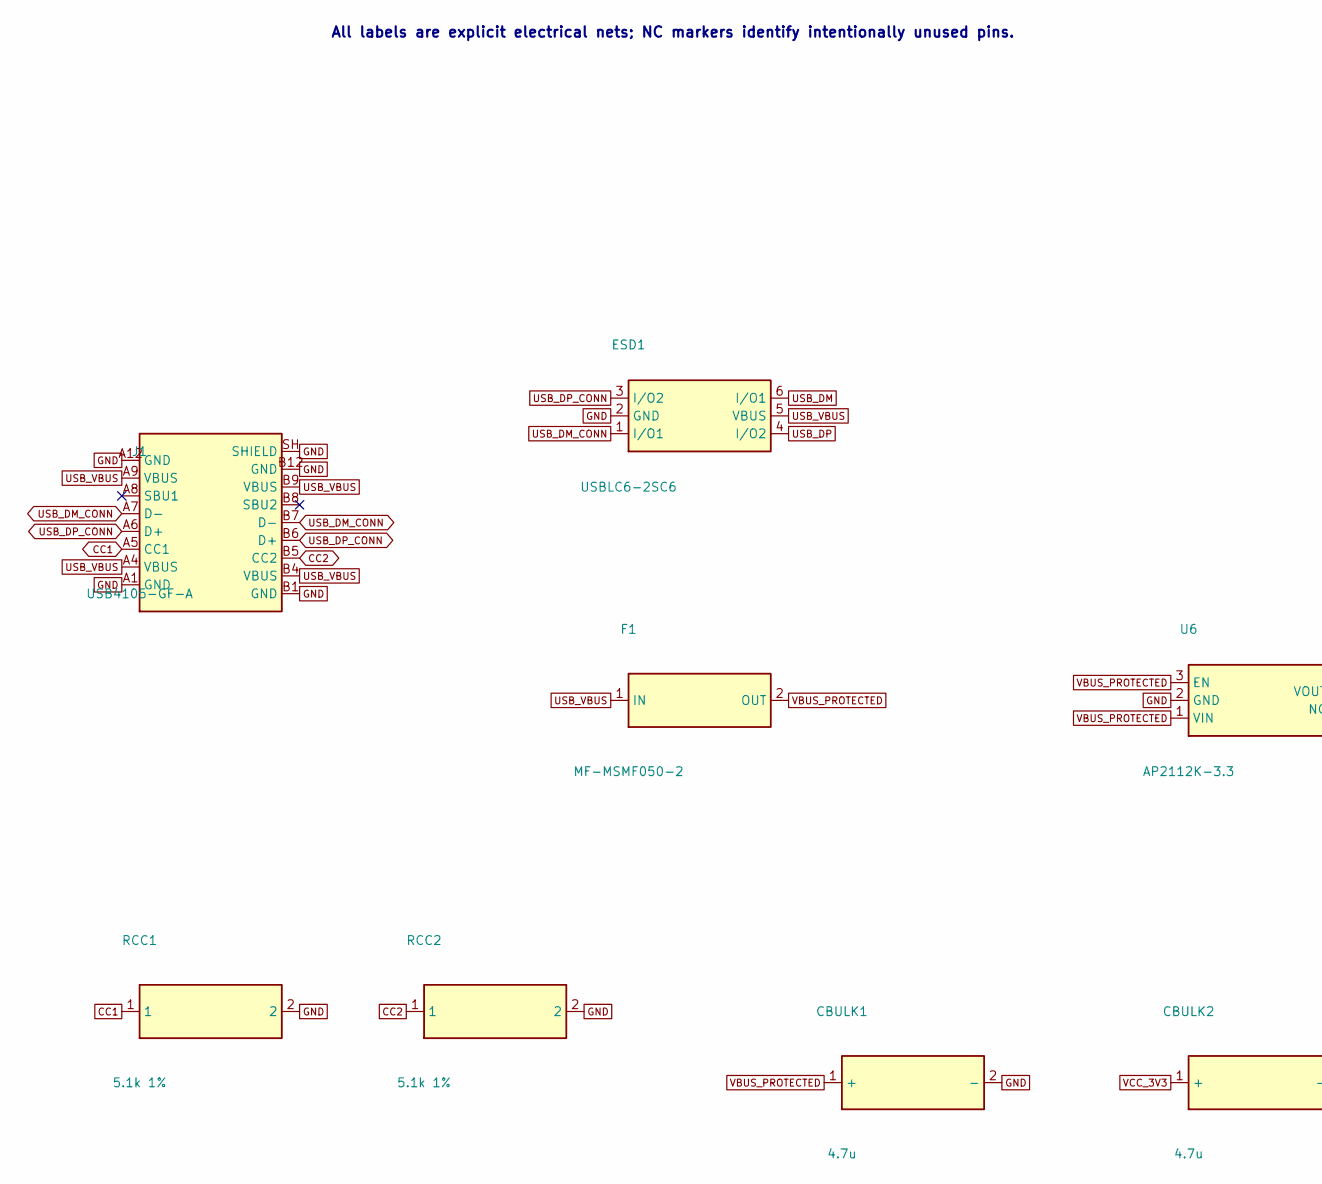
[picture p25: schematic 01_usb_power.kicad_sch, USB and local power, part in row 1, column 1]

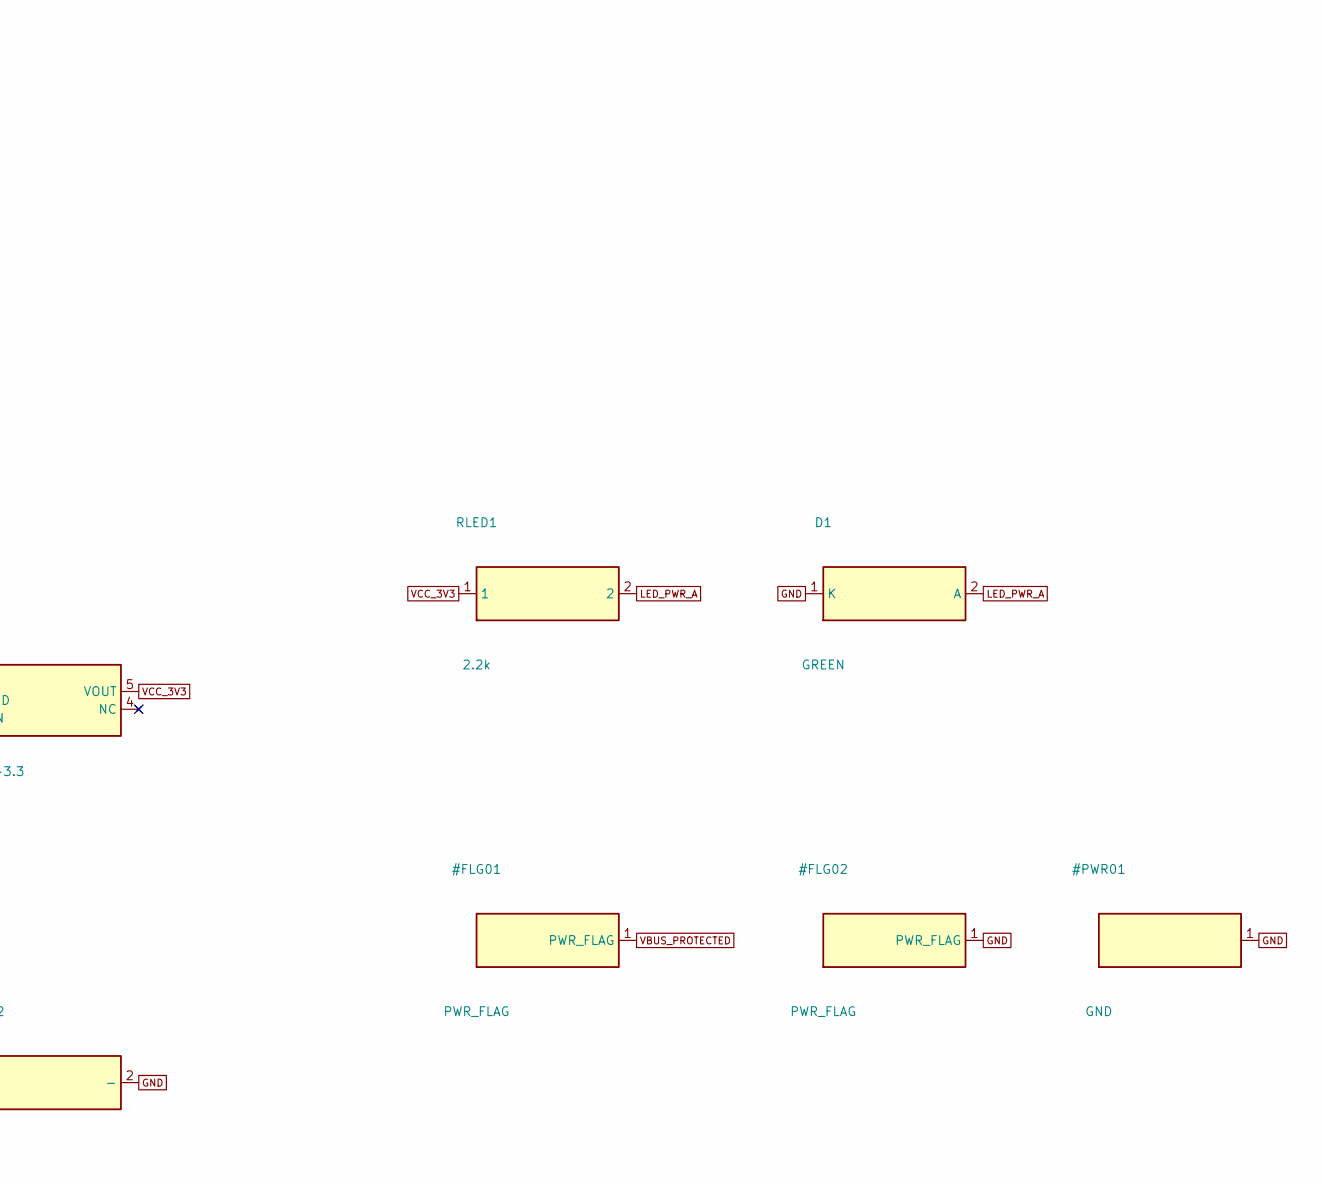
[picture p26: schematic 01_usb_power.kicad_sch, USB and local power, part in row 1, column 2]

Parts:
CBULK1, CBULK2: 4.7u; C_0805_2012Metric
D1: GREEN; LED_0603_1608Metric
ESD1: USBLC6-2SC6; SOT-23-6
F1: MF-MSMF050-2; Fuse_1812_4532Metric
J1: USB4105-GF-A; USB_C_Receptacle_GCT_USB4105-xx-A_16P_TopMnt_Horizontal
RCC1, RCC2: 5.1k 1%; R_0402_1005Metric
RLED1: 2.2k; R_0402_1005Metric
U6: AP2112K-3.3; SOT-23-5

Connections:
CC1: J1.A5 (CC1), RCC1.1
CC2: J1.B5 (CC2), RCC2.1
GND: CBULK1.2 (-), CBULK2.2 (-), D1.1 (K), ESD1.2 (GND), J1.A1 (GND), J1.A12 (GND), J1.B1 (GND), J1.B12 (GND), J1.SH (SHIELD), RCC1.2, RCC2.2, U6.2 (GND); also elsewhere on the board
LED_PWR_A: D1.2 (A), RLED1.2
USB_DM: ESD1.6 (I/O1); also elsewhere on the board
USB_DM_CONN: ESD1.1 (I/O1), J1.A7 (D-), J1.B7 (D-)
USB_DP: ESD1.4 (I/O2); also elsewhere on the board
USB_DP_CONN: ESD1.3 (I/O2), J1.A6 (D+), J1.B6 (D+)
USB_VBUS: ESD1.5 (VBUS), F1.1 (IN), J1.A4 (VBUS), J1.A9 (VBUS), J1.B4 (VBUS), J1.B9 (VBUS)
VBUS_PROTECTED: CBULK1.1 (+), F1.2 (OUT), U6.1 (VIN), U6.3 (EN)
VCC_3V3: CBULK2.1 (+), RLED1.1, U6.5 (VOUT); also elsewhere on the board

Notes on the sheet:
All labels are explicit electrical nets; NC markers identify intentionally unused pins.

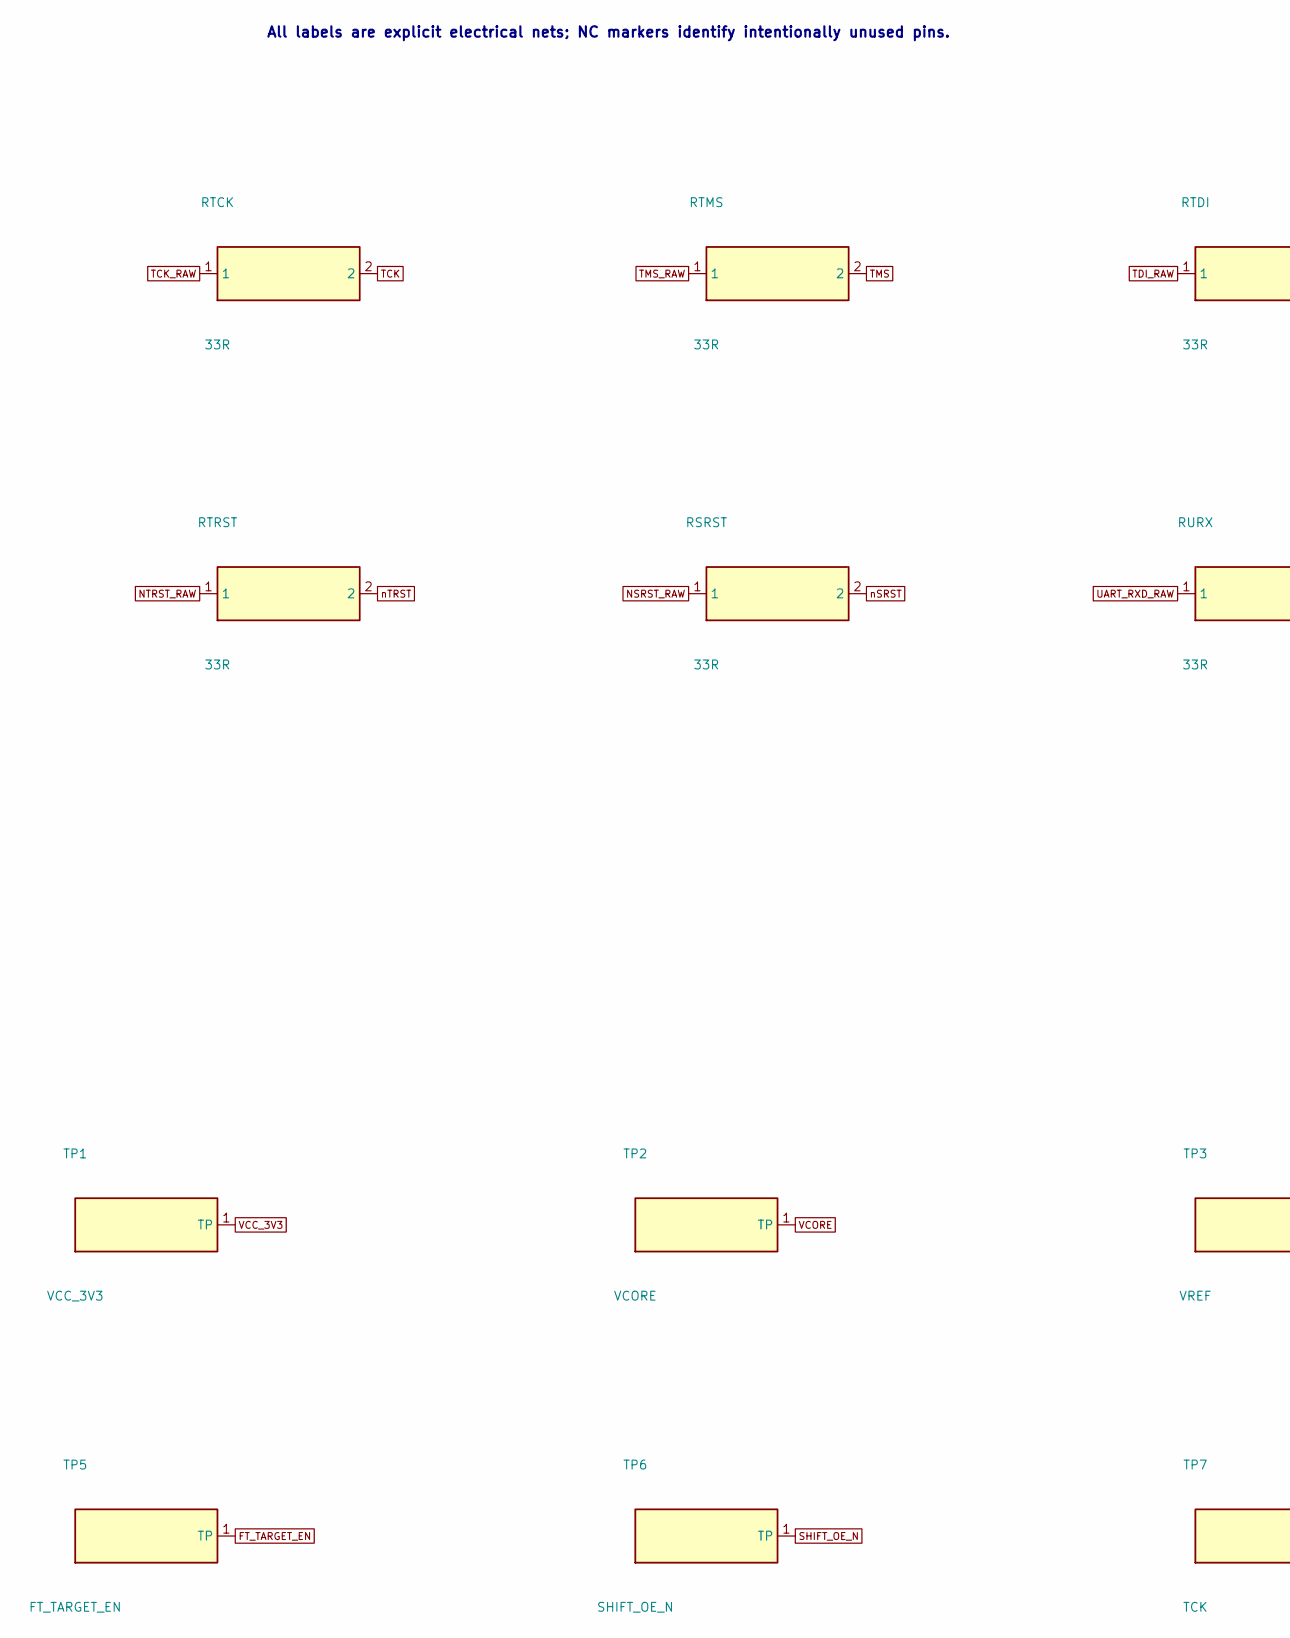
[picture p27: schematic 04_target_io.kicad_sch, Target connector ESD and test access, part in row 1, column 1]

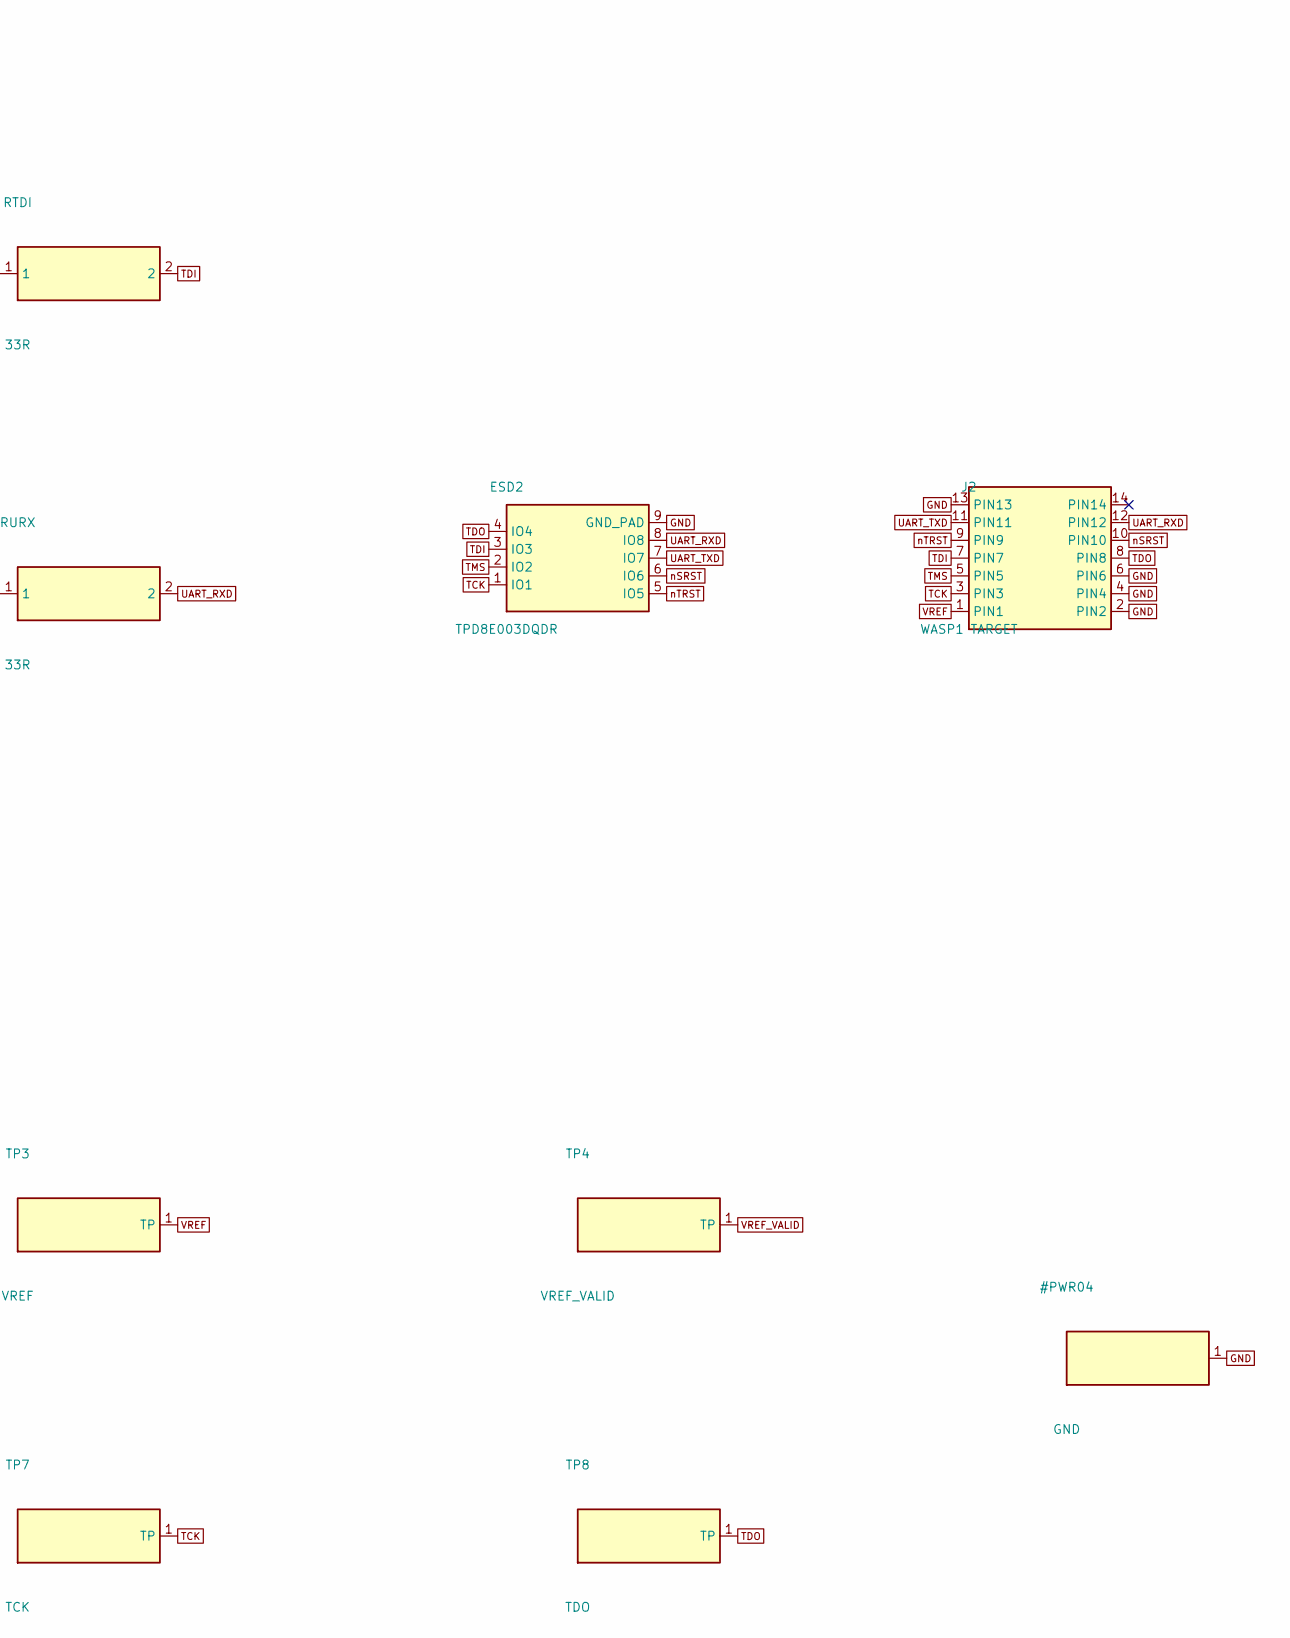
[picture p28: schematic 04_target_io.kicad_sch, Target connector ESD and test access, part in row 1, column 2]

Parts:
ESD2: TPD8E003DQDR; WSON-8-1EP_2x2mm_P0.5mm_EP0.9x1.6mm
J2: WASP1 TARGET; IDC-Header_2x07_P2.54mm_Vertical
RSRST: 33R; R_0402_1005Metric
RTCK: 33R; R_0402_1005Metric
RTDI: 33R; R_0402_1005Metric
RTMS: 33R; R_0402_1005Metric
RTRST: 33R; R_0402_1005Metric
RURX: 33R; R_0402_1005Metric
TP1: VCC_3V3; TestPoint_Pad_D1.0mm
TP2: VCORE; TestPoint_Pad_D1.0mm
TP3: VREF; TestPoint_Pad_D1.0mm
TP4: VREF_VALID; TestPoint_Pad_D1.0mm
TP5: FT_TARGET_EN; TestPoint_Pad_D1.0mm
TP6: SHIFT_OE_N; TestPoint_Pad_D1.0mm
TP7: TCK; TestPoint_Pad_D1.0mm
TP8: TDO; TestPoint_Pad_D1.0mm

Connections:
FT_TARGET_EN: TP5.1; also elsewhere on the board
GND: ESD2.9 (GND_PAD), J2.2 (PIN2), J2.4 (PIN4), J2.6 (PIN6), J2.13 (PIN13); also elsewhere on the board
NSRST_RAW: RSRST.1; also elsewhere on the board
NTRST_RAW: RTRST.1; also elsewhere on the board
SHIFT_OE_N: TP6.1; also elsewhere on the board
TCK: ESD2.1 (IO1), J2.3 (PIN3), RTCK.2, TP7.1
TCK_RAW: RTCK.1; also elsewhere on the board
TDI: ESD2.3 (IO3), J2.7 (PIN7), RTDI.2
TDI_RAW: RTDI.1; also elsewhere on the board
TDO: ESD2.4 (IO4), J2.8 (PIN8), TP8.1; also elsewhere on the board
TMS: ESD2.2 (IO2), J2.5 (PIN5), RTMS.2
TMS_RAW: RTMS.1; also elsewhere on the board
UART_RXD: ESD2.8 (IO8), J2.12 (PIN12), RURX.2
UART_RXD_RAW: RURX.1; also elsewhere on the board
UART_TXD: ESD2.7 (IO7), J2.11 (PIN11); also elsewhere on the board
VCC_3V3: TP1.1; also elsewhere on the board
VCORE: TP2.1; also elsewhere on the board
VREF: J2.1 (PIN1), TP3.1; also elsewhere on the board
VREF_VALID: TP4.1; also elsewhere on the board
nSRST: ESD2.6 (IO6), J2.10 (PIN10), RSRST.2
nTRST: ESD2.5 (IO5), J2.9 (PIN9), RTRST.2

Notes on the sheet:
All labels are explicit electrical nets; NC markers identify intentionally unused pins.

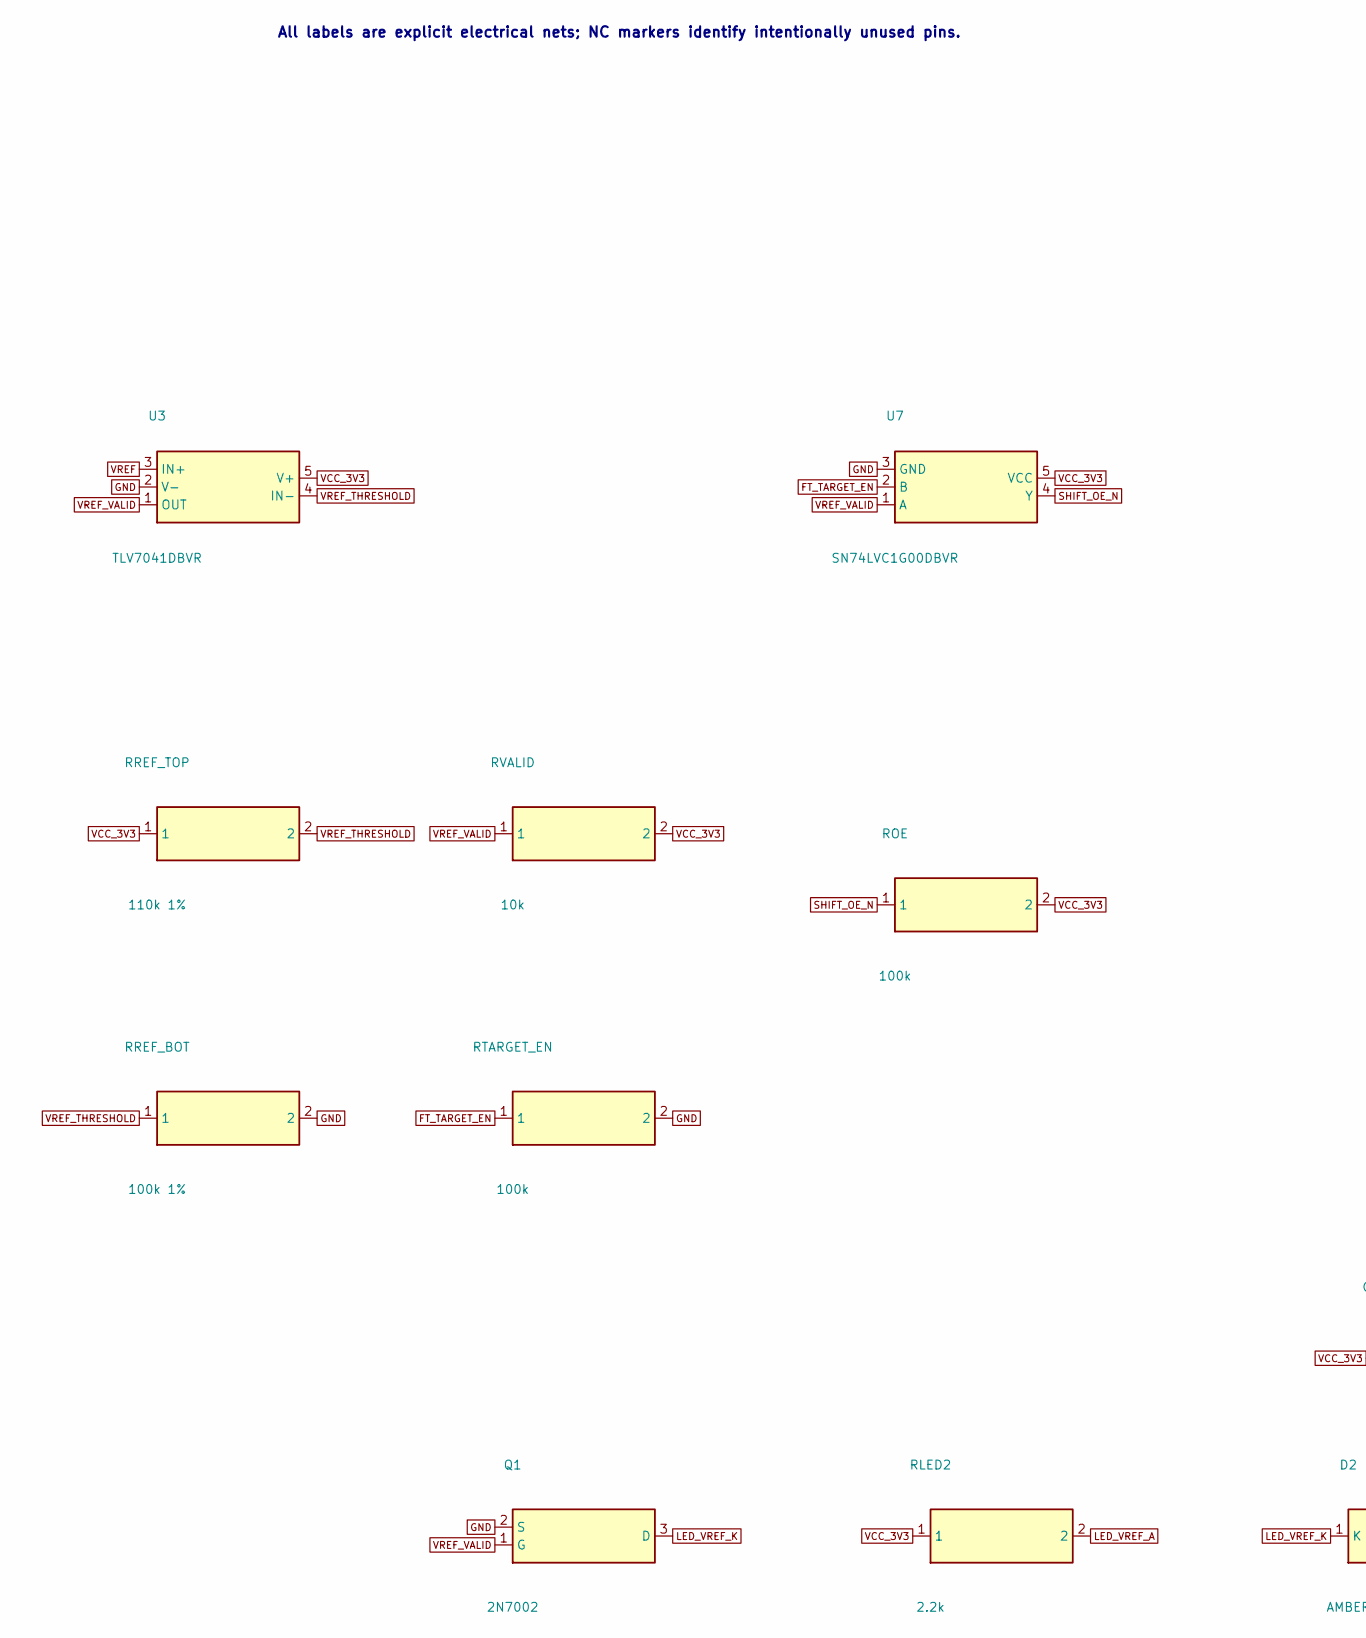
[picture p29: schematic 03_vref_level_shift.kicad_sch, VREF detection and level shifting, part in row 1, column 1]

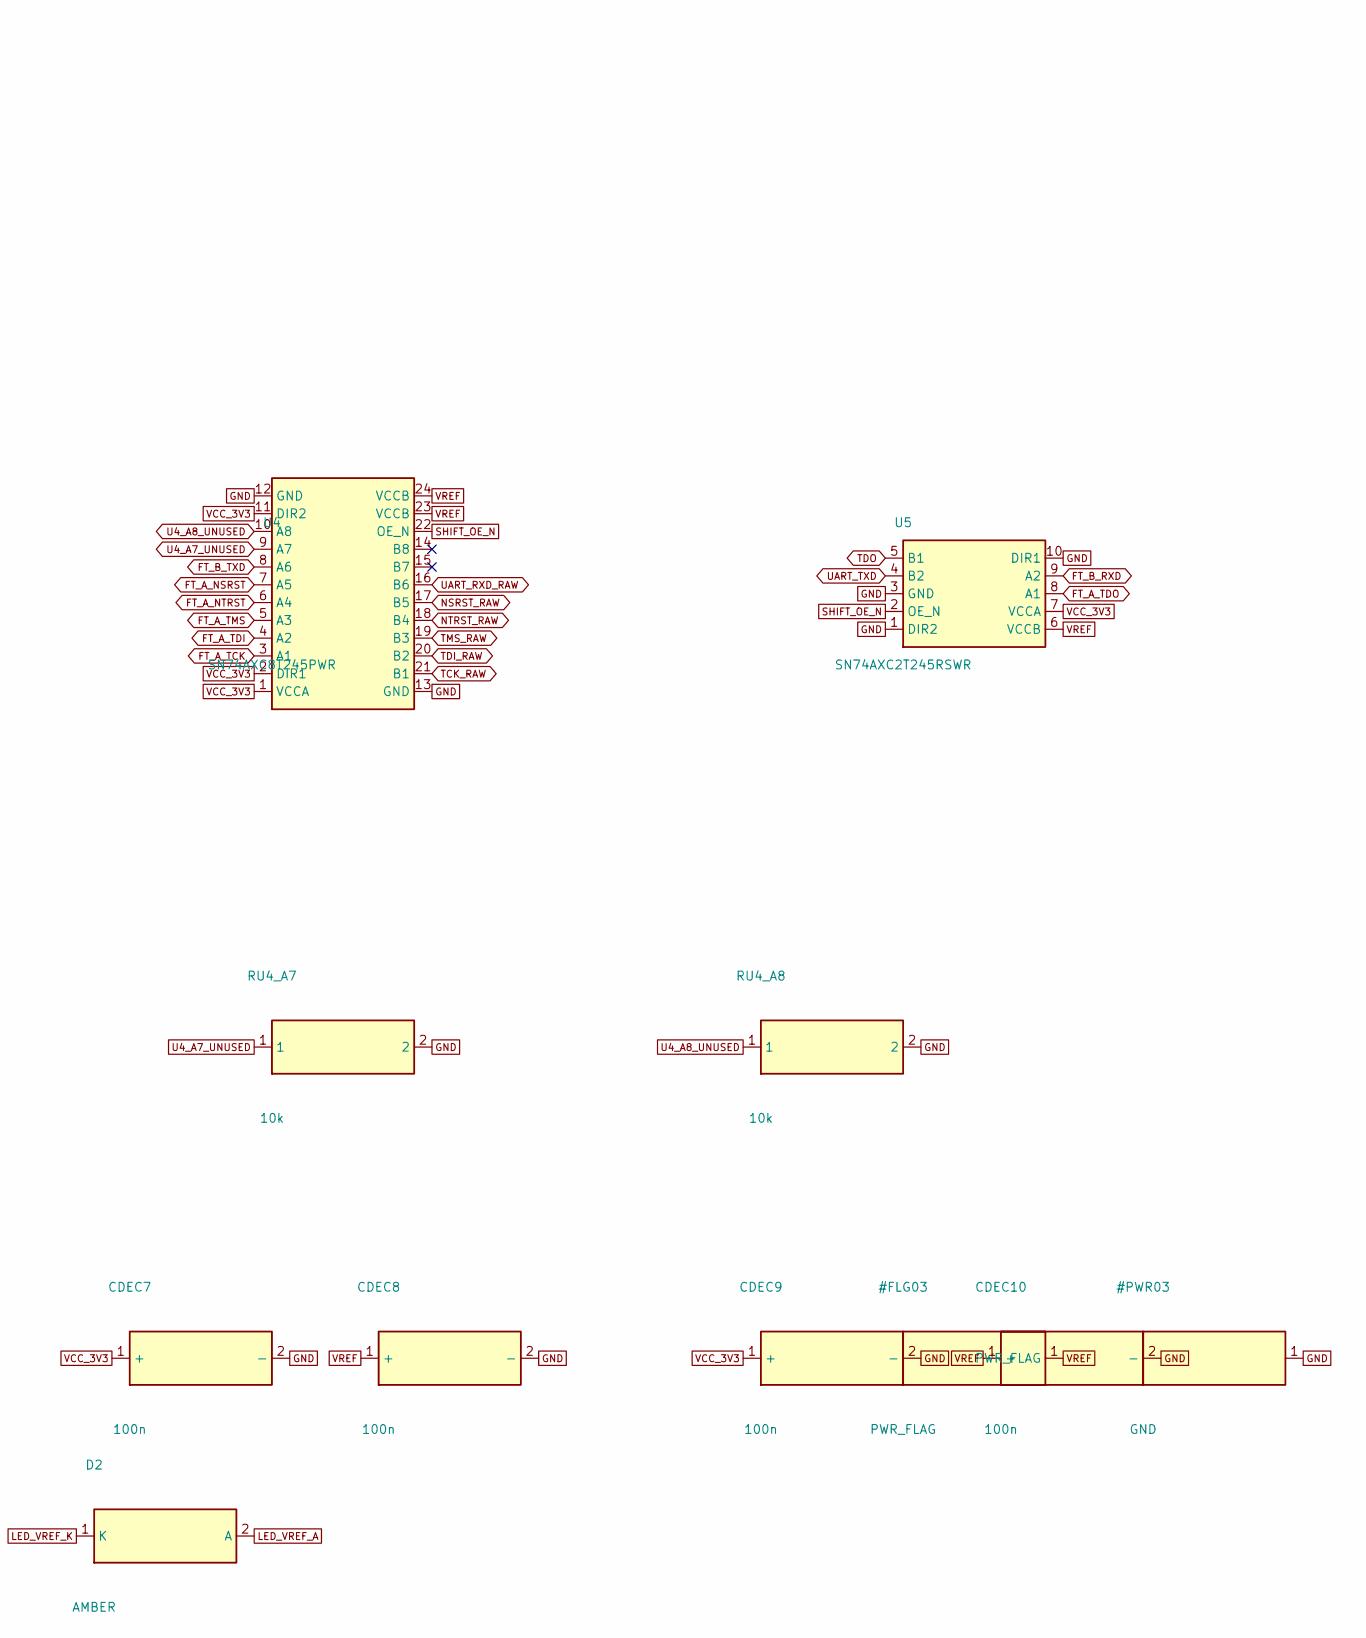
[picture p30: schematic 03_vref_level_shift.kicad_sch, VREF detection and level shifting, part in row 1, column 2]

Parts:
CDEC7, CDEC8, CDEC9, CDEC10: 100n; C_0402_1005Metric
D2: AMBER; LED_0603_1608Metric
Q1: 2N7002; SOT-23
RLED2: 2.2k; R_0402_1005Metric
ROE: 100k; R_0402_1005Metric
RREF_BOT: 100k 1%; R_0402_1005Metric
RREF_TOP: 110k 1%; R_0402_1005Metric
RTARGET_EN: 100k; R_0402_1005Metric
RU4_A7, RU4_A8: 10k; R_0402_1005Metric
RVALID: 10k; R_0402_1005Metric
U3: TLV7041DBVR; SOT-23-5
U4: SN74AXC8T245PWR; TSSOP-24_4.4x7.8mm_P0.65mm
U5: SN74AXC2T245RSWR; Texas_RSW0010A_UQFN-10_1.4x1.8mm_P0.4mm
U7: SN74LVC1G00DBVR; SOT-23-5

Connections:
FT_A_NSRST: U4.7 (A5); also elsewhere on the board
FT_A_NTRST: U4.6 (A4); also elsewhere on the board
FT_A_TCK: U4.3 (A1); also elsewhere on the board
FT_A_TDI: U4.4 (A2); also elsewhere on the board
FT_A_TDO: U5.8 (A1); also elsewhere on the board
FT_A_TMS: U4.5 (A3); also elsewhere on the board
FT_B_RXD: U5.9 (A2); also elsewhere on the board
FT_B_TXD: U4.8 (A6); also elsewhere on the board
FT_TARGET_EN: RTARGET_EN.1, U7.2 (B); also elsewhere on the board
GND: CDEC7.2 (-), CDEC8.2 (-), CDEC9.2 (-), CDEC10.2 (-), Q1.2 (S), RREF_BOT.2, RTARGET_EN.2, RU4_A7.2, RU4_A8.2, U3.2 (V-), U4.12 (GND), U4.13 (GND), U5.1 (DIR2), U5.3 (GND), U5.10 (DIR1), U7.3 (GND); also elsewhere on the board
LED_VREF_A: D2.2 (A), RLED2.2
LED_VREF_K: D2.1 (K), Q1.3 (D)
NSRST_RAW: U4.17 (B5); also elsewhere on the board
NTRST_RAW: U4.18 (B4); also elsewhere on the board
SHIFT_OE_N: ROE.1, U4.22 (OE_N), U5.2 (OE_N), U7.4 (Y); also elsewhere on the board
TCK_RAW: U4.21 (B1); also elsewhere on the board
TDI_RAW: U4.20 (B2); also elsewhere on the board
TDO: U5.5 (B1); also elsewhere on the board
TMS_RAW: U4.19 (B3); also elsewhere on the board
U4_A7_UNUSED: RU4_A7.1, U4.9 (A7)
U4_A8_UNUSED: RU4_A8.1, U4.10 (A8)
UART_RXD_RAW: U4.16 (B6); also elsewhere on the board
UART_TXD: U5.4 (B2); also elsewhere on the board
VCC_3V3: CDEC7.1 (+), CDEC9.1 (+), RLED2.1, ROE.2, RREF_TOP.1, RVALID.2, U3.5 (V+), U4.1 (VCCA), U4.2 (DIR1), U4.11 (DIR2), U5.7 (VCCA), U7.5 (VCC); also elsewhere on the board
VREF: CDEC8.1 (+), CDEC10.1 (+), U3.3 (IN+), U4.23 (VCCB), U4.24 (VCCB), U5.6 (VCCB); also elsewhere on the board
VREF_THRESHOLD: RREF_BOT.1, RREF_TOP.2, U3.4 (IN-)
VREF_VALID: Q1.1 (G), RVALID.1, U3.1 (OUT), U7.1 (A); also elsewhere on the board

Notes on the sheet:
All labels are explicit electrical nets; NC markers identify intentionally unused pins.

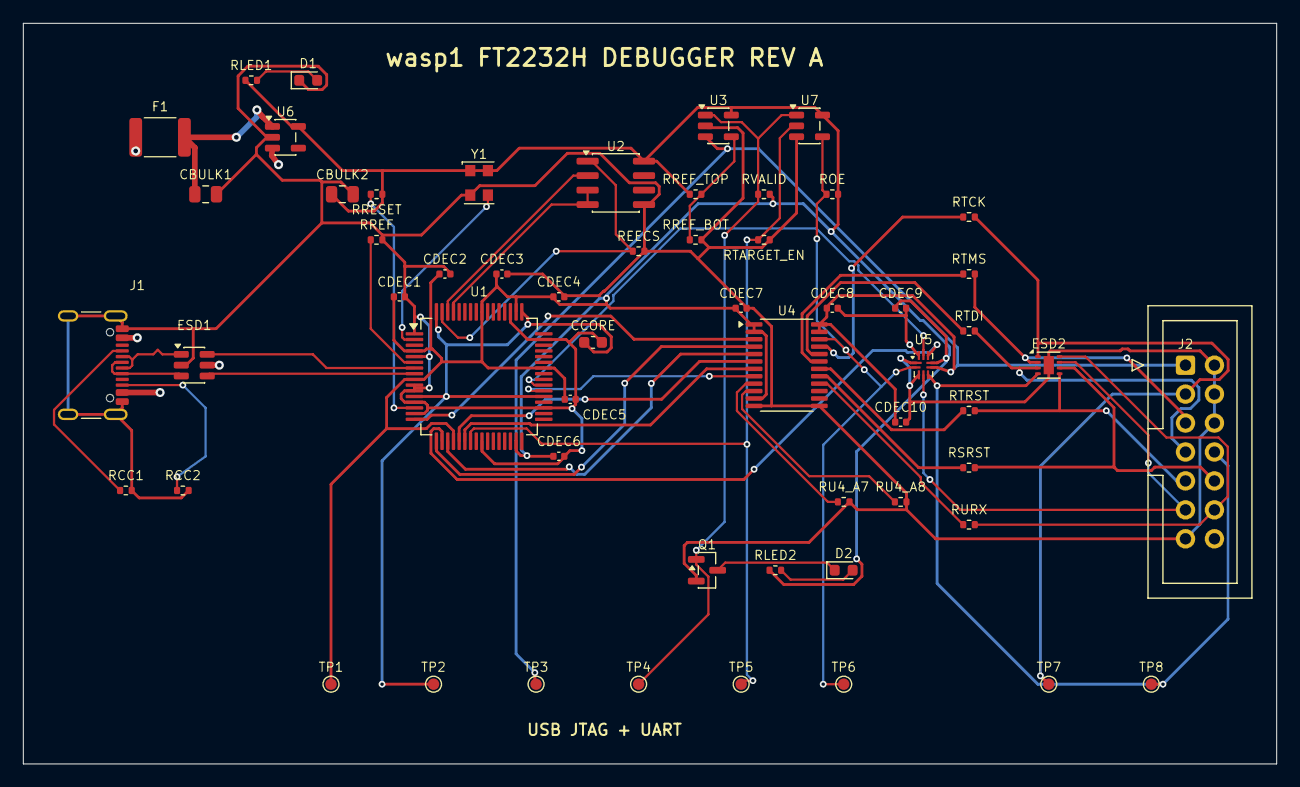
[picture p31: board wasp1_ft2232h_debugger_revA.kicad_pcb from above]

Board: 4 copper layers, 110.0 x 65.0 mm, 57 parts (0 on the bottom side), 49 nets.

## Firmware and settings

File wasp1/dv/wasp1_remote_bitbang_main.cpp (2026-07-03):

// Remote-bitbang simulation harness for the wasp1 SoC top.
//
// The harness exposes the top-level JTAG pins through the simple remote
// bitbang socket protocol used by OpenOCD's `remote_bitbang` adapter. It keeps
// hclk_i running while socket commands are processed so JTAG DMI requests can
// cross into the SoC debug clock domain.

#include "Vwasp1.h"
#include "verilated.h"

#include <arpa/inet.h>
#include <cerrno>
#include <csignal>
#include <cstdint>
#include <cstdio>
#include <cstdlib>
#include <cstring>
#include <netinet/in.h>
#include <sys/socket.h>
#include <unistd.h>

static vluint64_t g_time_ns = 0;
static bool g_stop_requested = false;

double sc_time_stamp() { return static_cast<double>(g_time_ns); }

static void handle_signal(int) { g_stop_requested = true; }

static bool has_arg(int argc, char **argv, const char *name) {
  for (int i = 1; i < argc; ++i) {
    if (std::strcmp(argv[i], name) == 0) {
      return true;
    }
  }
  return false;
}

static int parse_plusarg_int(int argc, char **argv, const char *prefix, int default_value) {
  const size_t prefix_len = std::strlen(prefix);
  for (int i = 1; i < argc; ++i) {
    if (std::strncmp(argv[i], prefix, prefix_len) == 0) {
      return std::atoi(argv[i] + prefix_len);
    }
  }
  return default_value;
}

static void advance_time(Vwasp1 *top, int ns) {
  for (int i = 0; i < ns && !Verilated::gotFinish(); ++i) {
    ++g_time_ns;
    if ((g_time_ns % 5) == 0) {
      top->hclk_i = !top->hclk_i;
    }
    top->eval();
  }
}

static void drive_default_inputs(Vwasp1 *top) {
  top->hclk_i = 0;
  top->hresetn_i = 0;
  top->uart_rx_i = 1;
  top->i2c_scl_i = 1;
  top->i2c_sda_i = 1;
  top->gpio_in_i = 0xA5A55A5Au;
  top->jtag_tck_i = 0;
  top->jtag_trst_ni = 0;
  top->jtag_tms_i = 1;
  top->jtag_tdi_i = 0;
  top->eval();
}

static void apply_reset(Vwasp1 *top) {
  top->hresetn_i = 0;
  top->jtag_trst_ni = 0;
  top->jtag_tms_i = 1;
  top->jtag_tdi_i = 0;
  top->jtag_tck_i = 0;
  advance_time(top, 40);
  top->hresetn_i = 1;
  top->jtag_trst_ni = 1;
  advance_time(top, 20);
}

static int open_listen_socket(int port) {
  int listen_fd = ::socket(AF_INET, SOCK_STREAM, 0);
  if (listen_fd < 0) {
    std::perror("socket");
    return -1;
  }

  int enable = 1;
  if (::setsockopt(listen_fd, SOL_SOCKET, SO_REUSEADDR, &enable, sizeof(enable)) < 0) {
    std::perror("setsockopt");
    ::close(listen_fd);
    return -1;
  }

  sockaddr_in addr {};
  addr.sin_family = AF_INET;
  addr.sin_addr.s_addr = htonl(INADDR_LOOPBACK);
  addr.sin_port = htons(static_cast<uint16_t>(port));

  if (::bind(listen_fd, reinterpret_cast<sockaddr *>(&addr), sizeof(addr)) < 0) {
    std::perror("bind");
    ::close(listen_fd);
    return -1;
  }

  if (::listen(listen_fd, 1) < 0) {
    std::perror("listen");
    ::close(listen_fd);
    return -1;
  }

  return listen_fd;
}

static bool send_tdo(int client_fd, Vwasp1 *top) {
  const char value = top->jtag_tdo_o ? '1' : '0';
  return ::send(client_fd, &value, 1, 0) == 1;
}

static void process_client(Vwasp1 *top, int client_fd) {
  while (!g_stop_requested && !Verilated::gotFinish()) {
    char cmd = 0;
    const ssize_t got = ::recv(client_fd, &cmd, 1, 0);
    if (got == 0) {
      break;
    }
    if (got < 0) {
      if (errno == EINTR) {
        continue;
      }
      std::perror("recv");
      break;
    }

    if (cmd >= '0' && cmd <= '7') {
      const int bits = cmd - '0';
      top->jtag_tdi_i = (bits & 0x1) != 0;
      top->jtag_tms_i = (bits & 0x2) != 0;
      top->jtag_tck_i = (bits & 0x4) != 0;
      advance_time(top, 1);
    } else if (cmd == 'R') {
      if (!send_tdo(client_fd, top)) {
        break;
      }
      advance_time(top, 1);
    } else if (cmd >= 'r' && cmd <= 'u') {
      const int bits = cmd - 'r';
      const bool srst = (bits & 0x1) != 0;
      const bool trst = (bits & 0x2) != 0;
      top->hresetn_i = srst ? 0 : 1;
      top->jtag_trst_ni = trst ? 0 : 1;
      advance_time(top, 2);
    } else if (cmd == 'Q') {
      break;
    } else if (cmd == 'B' || cmd == 'b') {
      // OpenOCD may use blink hints. They are intentionally ignored.
      advance_time(top, 1);
    } else {
      // Unknown adapter hints are ignored to keep the harness tolerant of
      // OpenOCD versions that add non-essential commands.
      advance_time(top, 1);
    }
  }
}

int main(int argc, char **argv) {
  Verilated::commandArgs(argc, argv);
  std::signal(SIGINT, handle_signal);
  std::signal(SIGTERM, handle_signal);

  const int port = parse_plusarg_int(argc, argv, "+rbb-port=", 9824);
  const bool keepalive = has_arg(argc, argv, "+rbb-keepalive");
  const int listen_fd = open_listen_socket(port);
  if (listen_fd < 0) {
    return 1;
  }

  Vwasp1 *top = new Vwasp1;
  drive_default_inputs(top);
  apply_reset(top);

  std::printf("wasp1 remote_bitbang listening on 127.0.0.1:%d\n", port);
  std::fflush(stdout);

  while (!g_stop_requested && !Verilated::gotFinish()) {
    sockaddr_in client_addr {};
    socklen_t client_len = sizeof(client_addr);
    const int client_fd = ::accept(
        listen_fd, reinterpret_cast<sockaddr *>(&client_addr), &client_len);
    if (client_fd < 0) {
      if (errno == EINTR) {
        continue;
      }
      std::perror("accept");
      break;
    }

    process_client(top, client_fd);
    ::close(client_fd);
    if (!keepalive) {
      break;
    }
  }

  top->final();
  delete top;
  ::close(listen_fd);
  return 0;
}

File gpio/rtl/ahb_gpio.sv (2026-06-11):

`timescale 1ns/1ps
`include "wasp1_target_defs.svh"

module ahb_gpio #(
  parameter int ADDR_WIDTH = wasp1_pkg::ADDR_WIDTH,
  parameter int DATA_WIDTH = wasp1_pkg::DATA_WIDTH,
  parameter int GPIO_WIDTH = 32,
  parameter logic [31:0] BASE_ADDR = wasp1_pkg::GPIO_BASE,
  parameter int REGION_BYTES = wasp1_pkg::PERIPH_SIZE
) (
  input  logic                  hclk_i,
  input  logic                  hresetn_i,
  input  logic                  hsel_i,
  input  logic [ADDR_WIDTH-1:0] haddr_i,
  input  logic [1:0]            htrans_i,
  input  logic                  hwrite_i,
  input  logic [2:0]            hsize_i,
  input  logic [DATA_WIDTH-1:0] hwdata_i,
  output logic [DATA_WIDTH-1:0] hrdata_o,
  output logic                  hready_o,
  output logic                  hresp_o,
  input  logic [GPIO_WIDTH-1:0] gpio_in_i,
  output logic [GPIO_WIDTH-1:0] gpio_out_o,
  output logic [GPIO_WIDTH-1:0] gpio_oe_o,
  output logic                  gpio_irq_o
);
  import wasp1_pkg::*;

  logic                  req_valid_q;
  logic                  req_write_q;
  logic                  req_err_q;
  logic [ADDR_WIDTH-1:0] req_offset_q;
  logic [2:0]            req_size_q;

  logic [ADDR_WIDTH-1:0] addr_offset;
  logic                  addr_in_range;
  logic                  addr_phase_valid;
  logic                  addr_misaligned;
  logic                  addr_unsupported;
  logic                  addr_phase_err;
  logic [DATA_WIDTH-1:0] read_data_next;

  logic [GPIO_WIDTH-1:0] in_meta_q;
  logic [GPIO_WIDTH-1:0] in_sync_q;
  logic [GPIO_WIDTH-1:0] in_prev_q;
  logic [GPIO_WIDTH-1:0] out_q;
  logic [GPIO_WIDTH-1:0] dir_q;
  logic [GPIO_WIDTH-1:0] irq_en_q;
  logic [GPIO_WIDTH-1:0] irq_type_q;
  logic [GPIO_WIDTH-1:0] irq_pol_q;
  logic [GPIO_WIDTH-1:0] irq_status_q;
  logic [GPIO_WIDTH-1:0] edge_rise;
  logic [GPIO_WIDTH-1:0] edge_fall;
  logic [GPIO_WIDTH-1:0] level_high;
  logic [GPIO_WIDTH-1:0] level_low;
  logic [GPIO_WIDTH-1:0] irq_event;
  logic [GPIO_WIDTH-1:0] write_masked_data;

  assign hready_o = 1'b1;
  assign gpio_out_o = out_q;
  assign gpio_oe_o = dir_q;
  assign gpio_irq_o = |(irq_status_q & irq_en_q);

  assign addr_offset = haddr_i - ADDR_WIDTH'(BASE_ADDR);
  assign addr_in_range = (haddr_i >= ADDR_WIDTH'(BASE_ADDR)) &&
                         (addr_offset < ADDR_WIDTH'(REGION_BYTES));
  assign addr_phase_valid = hsel_i && htrans_i[1];
  assign addr_misaligned = |haddr_i[1:0];
  assign addr_unsupported = hsize_i != AHB_HSIZE_WORD;
  assign addr_phase_err = addr_phase_valid &&
                          (!addr_in_range || addr_misaligned || addr_unsupported);

  assign edge_rise = in_sync_q & ~in_prev_q;
  assign edge_fall = ~in_sync_q & in_prev_q;
  assign level_high = in_sync_q;
  assign level_low = ~in_sync_q;
  assign irq_event = irq_en_q &
                     (((irq_type_q & irq_pol_q) & edge_rise) |
                      ((irq_type_q & ~irq_pol_q) & edge_fall) |
                      ((~irq_type_q & irq_pol_q) & level_high) |
                      ((~irq_type_q & ~irq_pol_q) & level_low));
  assign write_masked_data = hwdata_i[GPIO_WIDTH-1:0];

  function automatic logic is_known_reg(input logic [31:0] reg_offset);
    begin
      unique case (reg_offset)
        GPIO_DATA_IN_OFFSET,
        GPIO_DATA_OUT_OFFSET,
        GPIO_DIR_OFFSET,
        GPIO_SET_OFFSET,
        GPIO_CLR_OFFSET,
        GPIO_TOGGLE_OFFSET,
        GPIO_IRQ_EN_OFFSET,
        GPIO_IRQ_TYPE_OFFSET,
        GPIO_IRQ_POL_OFFSET,
        GPIO_IRQ_STATUS_OFFSET: is_known_reg = 1'b1;
        default: is_known_reg = 1'b0;
      endcase
    end
  endfunction

  always_comb begin
    read_data_next = '0;
    if (req_valid_q && !req_write_q && !req_err_q) begin
      unique case (req_offset_q)
        GPIO_DATA_IN_OFFSET:    read_data_next[GPIO_WIDTH-1:0] = in_sync_q;
        GPIO_DATA_OUT_OFFSET:   read_data_next[GPIO_WIDTH-1:0] = out_q;
        GPIO_DIR_OFFSET:        read_data_next[GPIO_WIDTH-1:0] = dir_q;
        GPIO_SET_OFFSET:        read_data_next = '0;
        GPIO_CLR_OFFSET:        read_data_next = '0;
        GPIO_TOGGLE_OFFSET:     read_data_next = '0;
        GPIO_IRQ_EN_OFFSET:     read_data_next[GPIO_WIDTH-1:0] = irq_en_q;
        GPIO_IRQ_TYPE_OFFSET:   read_data_next[GPIO_WIDTH-1:0] = irq_type_q;
        GPIO_IRQ_POL_OFFSET:    read_data_next[GPIO_WIDTH-1:0] = irq_pol_q;
        GPIO_IRQ_STATUS_OFFSET: read_data_next[GPIO_WIDTH-1:0] = irq_status_q;
        default:                read_data_next = '0;
      endcase
    end
  end
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

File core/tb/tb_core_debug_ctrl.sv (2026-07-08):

`timescale 1ns/1ps

module tb_core_debug_ctrl;
  logic clk;          // 100 MHz verification clock.
  logic rst_n;        // Active-low reset.
  logic halt_req;     // Debug halt request stimulus.
  logic trigger_req;  // Execute-address trigger request stimulus.
  logic resume_req;   // Debug resume request stimulus.
  logic step_req;     // Debug single-step request stimulus.
  logic pipe_idle;    // Pipeline-drained stimulus.
  logic retire_valid; // One-instruction retirement stimulus.
  logic debug_busy;   // Pending GPR response stimulus.
  logic stop_fetch;   // DUT fetch-stop output.
  logic freeze_pipe;  // DUT halted pipe-freeze output.
  logic halted;       // DUT halted status output.
  logic running;      // DUT running status output.

  integer pass_count;   // Total passing self-checks.
  integer halt_count;   // Halt-entry coverage.
  integer resume_count; // Resume coverage.
  integer step_count;   // Single-step coverage.
  integer busy_count;   // Busy-response blocking coverage.
  integer cancel_count; // Halt-pending cancel coverage.
  integer priority_count;// Halt-priority coverage.
  integer trigger_count;// Trigger-entry coverage.

  core_debug_ctrl dut (
    .clk_i(clk),
    .rst_ni(rst_n),
    .halt_req_i(halt_req),
    .trigger_req_i(trigger_req),
    .resume_req_i(resume_req),
    .step_req_i(step_req),
    .pipe_idle_i(pipe_idle),
    .retire_valid_i(retire_valid),
    .debug_busy_i(debug_busy),
    .stop_fetch_o(stop_fetch),
    .freeze_pipe_o(freeze_pipe),
    .halted_o(halted),
    .running_o(running)
  );

  initial begin
    clk = 1'b0;
    forever #5 clk = ~clk;
  end

  task automatic drive_idle_running;
    begin
      rst_n = 1'b0;
      halt_req = 1'b0;
      trigger_req = 1'b0;
      resume_req = 1'b0;
      step_req = 1'b0;
      pipe_idle = 1'b1;
      retire_valid = 1'b0;
      debug_busy = 1'b0;
      repeat (2) @(posedge clk);
      rst_n = 1'b1;
      @(posedge clk);
      #1;
      if (!running || halted || stop_fetch || freeze_pipe) begin
        $fatal(1, "running baseline mismatch run=%0b halt=%0b stop=%0b freeze=%0b",
               running, halted, stop_fetch, freeze_pipe);
      end
      pass_count++;
    end
  endtask

  task automatic check_immediate_halt;
    begin
      drive_idle_running();
      @(negedge clk);
      halt_req = 1'b1;
      #1;
      if (!stop_fetch || halted) begin
        $fatal(1, "immediate halt pre-edge mismatch stop=%0b halted=%0b",
               stop_fetch, halted);
      end
      @(posedge clk);
      #1;
      if (!halted || running || !freeze_pipe || !stop_fetch) begin
        $fatal(1, "immediate halt mismatch halt=%0b run=%0b freeze=%0b stop=%0b",
               halted, running, freeze_pipe, stop_fetch);
      end
      pass_count++;
      halt_count++;
    end
  endtask

  task automatic check_drain_halt;
    begin
      drive_idle_running();
      @(negedge clk);
      pipe_idle = 1'b0;
      halt_req = 1'b1;
      @(posedge clk);
      #1;
      if (halted || running || !stop_fetch || freeze_pipe) begin
        $fatal(1, "halt-pending mismatch halt=%0b run=%0b stop=%0b freeze=%0b",
               halted, running, stop_fetch, freeze_pipe);
      end
      @(negedge clk);
      pipe_idle = 1'b1;
      @(posedge clk);
      #1;
      if (!halted || running || !freeze_pipe) begin
        $fatal(1, "drain halt completion mismatch");
      end
      pass_count++;
      halt_count++;
    end
  endtask

  task automatic check_trigger_halt;
    begin
      drive_idle_running();
      @(negedge clk);
      pipe_idle = 1'b0;
      trigger_req = 1'b1;
      #1;
      if (!stop_fetch || halted) begin
        $fatal(1, "trigger pre-edge mismatch stop=%0b halted=%0b",
               stop_fetch, halted);
      end
      @(posedge clk);
      #1;
      if (halted || running || !stop_fetch || freeze_pipe) begin
        $fatal(1, "trigger pending mismatch halt=%0b run=%0b stop=%0b freeze=%0b",
               halted, running, stop_fetch, freeze_pipe);
      end
      @(negedge clk);
      pipe_idle = 1'b1;
      trigger_req = 1'b0;
      @(posedge clk);
      #1;
      if (!halted || running || !freeze_pipe || !stop_fetch) begin
        $fatal(1, "trigger halt completion mismatch");
      end
      pass_count++;
      halt_count++;
      trigger_count++;
    end
  endtask

  task automatic check_cancel_pending;
    begin
      drive_idle_running();
      @(negedge clk);
      pipe_idle = 1'b0;
      halt_req = 1'b1;
      @(posedge clk);
      @(negedge clk);
      halt_req = 1'b0;
      resume_req = 1'b1;
      @(posedge clk);
      #1;
      if (!running || halted || stop_fetch) begin
        $fatal(1, "halt cancel mismatch run=%0b halt=%0b stop=%0b",
               running, halted, stop_fetch);
      end
      pass_count++;
      cancel_count++;
    end
  endtask

  task automatic check_resume_and_busy;
    begin
      check_immediate_halt();
      @(negedge clk);
      halt_req = 1'b0;
      debug_busy = 1'b1;
      resume_req = 1'b1;
      @(posedge clk);
      #1;
      if (!halted || !freeze_pipe) begin
        $fatal(1, "busy resume should remain halted");
      end
      busy_count++;
      @(negedge clk);
      debug_busy = 1'b0;
      @(posedge clk);
      #1;
      if (!running || halted || stop_fetch) begin
        $fatal(1, "resume after busy mismatch run=%0b halt=%0b stop=%0b",
               running, halted, stop_fetch);
      end
      pass_count++;
      resume_count++;
    end
  endtask

  task automatic check_step;
    begin
      check_immediate_halt();
      @(negedge clk);
      halt_req = 1'b0;
      step_req = 1'b1;
      @(posedge clk);
      #1;
      if (!running || halted || stop_fetch) begin
        $fatal(1, "step release mismatch");
      end
      @(negedge clk);
      step_req = 1'b0;
      pipe_idle = 1'b0;
      retire_valid = 1'b1;
      @(posedge clk);
      #1;
      if (halted || running || !stop_fetch) begin
        $fatal(1, "step retire should enter halt-pending");
      end
      @(negedge clk);
      retire_valid = 1'b0;
      pipe_idle = 1'b1;
      @(posedge clk);
      #1;
      if (!halted || running || !freeze_pipe) begin
        $fatal(1, "step rehalt mismatch");
      end
      pass_count++;
      step_count++;
    end
  endtask

  task automatic check_halt_priority;
    begin
      check_immediate_halt();
      @(negedge clk);
      resume_req = 1'b1;
      step_req = 1'b1;
      halt_req = 1'b1;
      @(posedge clk);
      #1;
      if (!halted || !freeze_pipe || running) begin
        $fatal(1, "halt priority mismatch");
      end
      pass_count++;
      priority_count++;
    end
  endtask

  initial begin
    pass_count = 0;
    halt_count = 0;
    resume_count = 0;
    step_count = 0;
    busy_count = 0;
    cancel_count = 0;
    priority_count = 0;
    trigger_count = 0;
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

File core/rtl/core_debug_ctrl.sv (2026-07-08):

`timescale 1ns/1ps

// Core Debug Mode control FSM.
//
// This block owns the minimal halted/running state used by the external Debug
// Module. It stops new frontend acceptance when a halt is requested, waits for
// the in-order pipeline to drain, then allows GPR debug accesses only while the
// hart is halted. A step request releases one instruction and then returns to
// halt-pending so later Debug Module integration has a clean hook.
module core_debug_ctrl (
  input  logic clk_i,             // Core/debug control clock.
  input  logic rst_ni,            // Active-low asynchronous reset.

  input  logic halt_req_i,        // Debug Module requests entry to Debug Mode.
  input  logic trigger_req_i,     // Core trigger requests entry to Debug Mode.
  input  logic resume_req_i,      // Debug Module requests exit from Debug Mode.
  input  logic step_req_i,        // Debug Module requests one retired instruction.
  input  logic pipe_idle_i,       // Pipeline and LSU are fully drained.
  input  logic retire_valid_i,    // One architectural instruction retires this cycle.
  input  logic debug_busy_i,      // GPR debug response is pending or being accepted.

  output logic stop_fetch_o,      // Stop accepting new frontend instructions.
  output logic freeze_pipe_o,     // Hold the already-drained pipeline in Debug Mode.
  output logic halted_o,          // Hart is halted and accepts debug GPR traffic.
  output logic running_o          // Hart is executing or available to execute code.
);
  typedef enum logic [1:0] {
    DBG_RUNNING      = 2'b00, // Normal execution; frontend may flow.
    DBG_HALT_PENDING = 2'b01, // Fetch stopped, existing work is draining.
    DBG_HALTED       = 2'b10, // Debug Mode; pipeline is empty and frozen.
    DBG_STEP_RUNNING = 2'b11  // One-instruction single-step release.
  } debug_state_e;

  debug_state_e state_q; // Registered Debug Mode control state.
  debug_state_e state_d; // Next Debug Mode control state.

  // Next-state priority:
  // 1. halt or trigger requests win over resume/step;
  // 2. pending halt completes only after pipeline and debug response drain;
  // 3. halted resume waits until no GPR response is outstanding;
  // 4. single-step returns to halt-pending after one retirement.
  always_comb begin
    state_d = state_q;

    unique case (state_q)
      DBG_RUNNING: begin
        if (halt_req_i || trigger_req_i) begin
          state_d = (pipe_idle_i && !debug_busy_i) ? DBG_HALTED :
                                                   DBG_HALT_PENDING;
        end
      end

      DBG_HALT_PENDING: begin
        if (!halt_req_i && resume_req_i) begin
          state_d = DBG_RUNNING;
        end else if (pipe_idle_i && !debug_busy_i) begin
          state_d = DBG_HALTED;
        end
      end

      DBG_HALTED: begin
        if (halt_req_i) begin
          state_d = DBG_HALTED;
        end else if (step_req_i && !debug_busy_i) begin
          state_d = DBG_STEP_RUNNING;
        end else if (resume_req_i && !debug_busy_i) begin
          state_d = DBG_RUNNING;
        end
      end

      DBG_STEP_RUNNING: begin
        if (halt_req_i || trigger_req_i || retire_valid_i) begin
          state_d = pipe_idle_i ? DBG_HALTED : DBG_HALT_PENDING;
        end
      end

      default: begin
        state_d = DBG_RUNNING;
      end
    endcase
  end

  // Registered state update. Reset leaves the hart in normal running state so
  // system boot does not require debug handshakes.
  always_ff @(posedge clk_i or negedge rst_ni) begin
    if (!rst_ni) begin
      state_q <= DBG_RUNNING;
    end else begin
      state_q <= state_d;
    end
  end

  // Fetch is stopped as soon as a halt/trigger request is visible, even before
  // the FSM samples it, so no extra instruction is accepted behind debug entry.
  assign stop_fetch_o = halt_req_i || trigger_req_i || (state_q == DBG_HALT_PENDING) ||
                        (state_q == DBG_HALTED);
  assign freeze_pipe_o = (state_q == DBG_HALTED);
  assign halted_o = (state_q == DBG_HALTED);
  assign running_o = (state_q == DBG_RUNNING) ||
                     (state_q == DBG_STEP_RUNNING);
endmodule

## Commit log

2026-06-10 Strengthen AHB decoder verification coverage
    [tb_ahb_decoder.sv]
2026-06-11 Implement and verify AHB timer
2026-06-11 Implement and verify AHB UART
2026-06-11 Implement and verify AHB DMA
2026-06-11 Implement and verify AHB interrupt controller
2026-06-12 Refine DMA L3 state diagrams
2026-06-13 Integrate core CSR trap interrupt path
2026-06-26 Add WDG I2C and initial SoC top
2026-06-26 Add UART DMA INTC editable block diagrams
2026-06-29 Add UART leaf editable block diagrams
2026-06-30 Add i2c design presentation
2026-06-30 Add llvm_s1 stage1 BSP skeleton
2026-07-03 Integrate stage1 debug module top
2026-07-03 Add stage1 JTAG DTM
2026-07-03 Add OpenOCD GDB debug smoke
    [wasp1_remote_bitbang.cfg]
2026-07-03 Add FTDI debugger project plan
    [wasp1_ft2232h_reference.cfg]
2026-07-04 Add DMA copy firmware smoke
2026-07-04 Fix AHB fabric transaction timing
    [ahb_arbiter_2m.sv]
2026-07-04 Add DMA external interrupt firmware smoke
2026-07-05 Add UART IRQ firmware smoke
2026-07-05 Add UART RX IRQ firmware smoke
2026-07-05 Add mixed IRQ DMA firmware regression
2026-07-06 Automate wasp1 OpenOCD GDB smoke
    [wasp1_remote_bitbang.cfg]
2026-07-08 Support GDB stepi through abstract memory
    [wasp1_remote_bitbang.cfg]
2026-07-09 Add FTDI debugger Rev A hardware package
    [wasp1_ft2232h_debugger_revA_bom.csv, wasp1_ft2232h_debugger_revA_nets.csv]
2026-07-11 Add randomized interrupt stress firmware
2026-07-11 Add multi-seed interrupt stress campaign
2026-07-12 Add core pipeline debug injection slot
2026-07-12 Freeze FTDI debugger Rev A electrical design
    [wasp1_ft2232h_debugger_revA_bom.csv, wasp1_ft2232h_debugger_revA_nets.csv, wasp1_ft2232h_reference.cfg]
2026-07-13 Add FTDI debugger KiCad schematic
    [01_usb_power.kicad_sch, 02_ft2232h_core.kicad_sch, 03_vref_level_shift.kicad_sch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]
2026-07-13 Add FTDI debugger PCB placement
    [wasp1_ft2232h_debugger_revA.kicad_pcb]
2026-07-14 Route FTDI debugger PCB
    [wasp1_ft2232h_debugger_revA.kicad_pcb]
2026-07-14 Add FTDI host tools and UART OTP loader
2026-07-14 Harden FTDI manufacturing release package
    [04_target_io.kicad_sch, wasp1_ft2232h_debugger_revA.kicad_pcb, wasp1_ft2232h_debugger_revA_bom.csv]
